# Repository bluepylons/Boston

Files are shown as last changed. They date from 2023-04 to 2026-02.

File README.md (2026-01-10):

# Boston Keyboard 

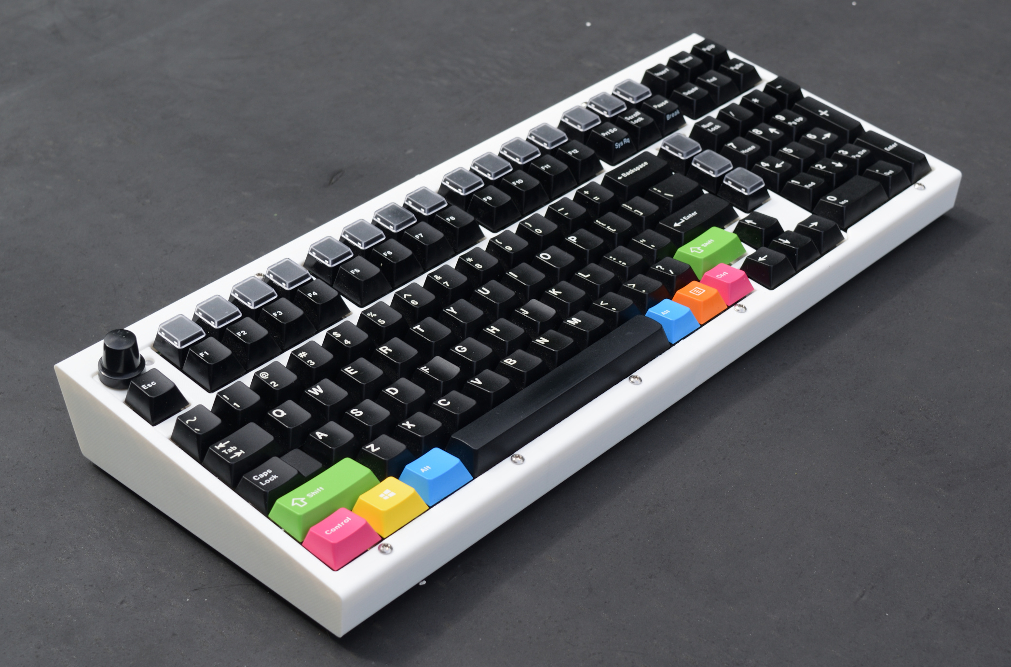
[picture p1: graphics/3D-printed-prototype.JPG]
3D-printed/FR4 version

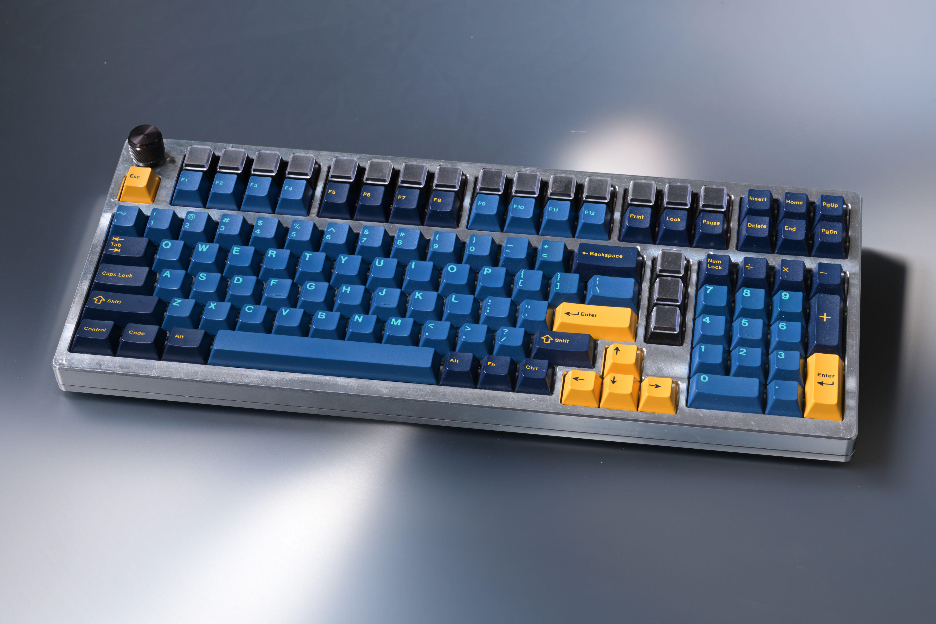
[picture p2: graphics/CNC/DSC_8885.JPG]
CNC version


## Introduction 
Boston is a compact battleship with a complement of 18 programmable keys, in a footprint 2u narrower than a full-size, and only about 1.5u wider than a 96%. There is a 3D printed version and a CNC aluminum version. Hotswap ANSI PCBs are available for both. All are open source. 

The immediate inspiration for Boston was the DriftMechanics [Austin](https://github.com/Gondolindrim/Austin), as well as the [7-row Thinkpad keyboards](https://cdn.mos.cms.futurecdn.net/ZgDSnno6WfhXMf8u8fsBv7-970-80.jpg) found on Thinkpads of the T420 generation and older. The general idea was to make a narrower full-size that retained both the 2u numpad "0" and traditional 2x3 Ins/Del/Home/End/PgUp/PgDn nav block, by expanding vertically. 

The name is a pun off Austin, since the layout is derived from it. I also grew up around the city of Boston and still live in the area. 

## Supported layouts

Soldered PCB:
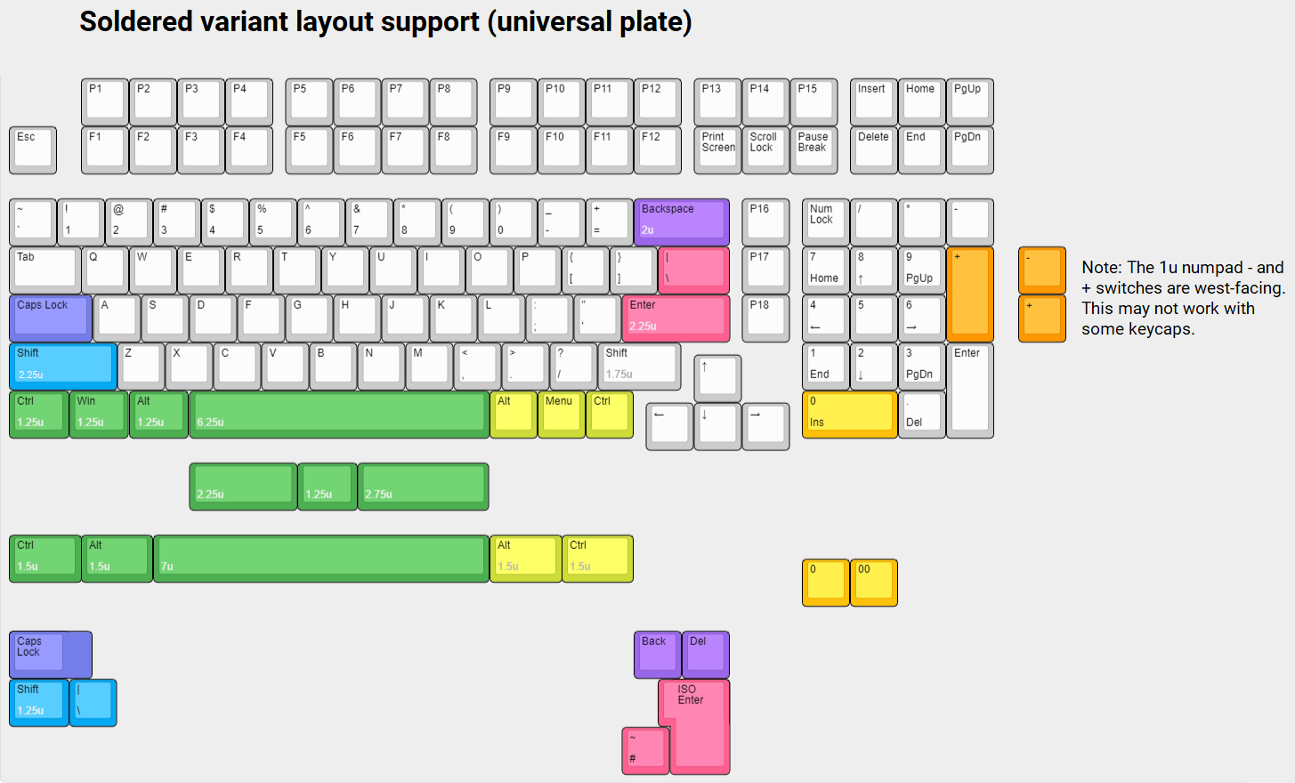
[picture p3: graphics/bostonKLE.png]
Boston layouts


ANSI hotswap PCB: (note the split space 2.75u and 2.25u keys are flipped around compared to the soldered version - this was necessary to accommodate both split space and standard 6.25u space on the same PCB with hotswap sockets)
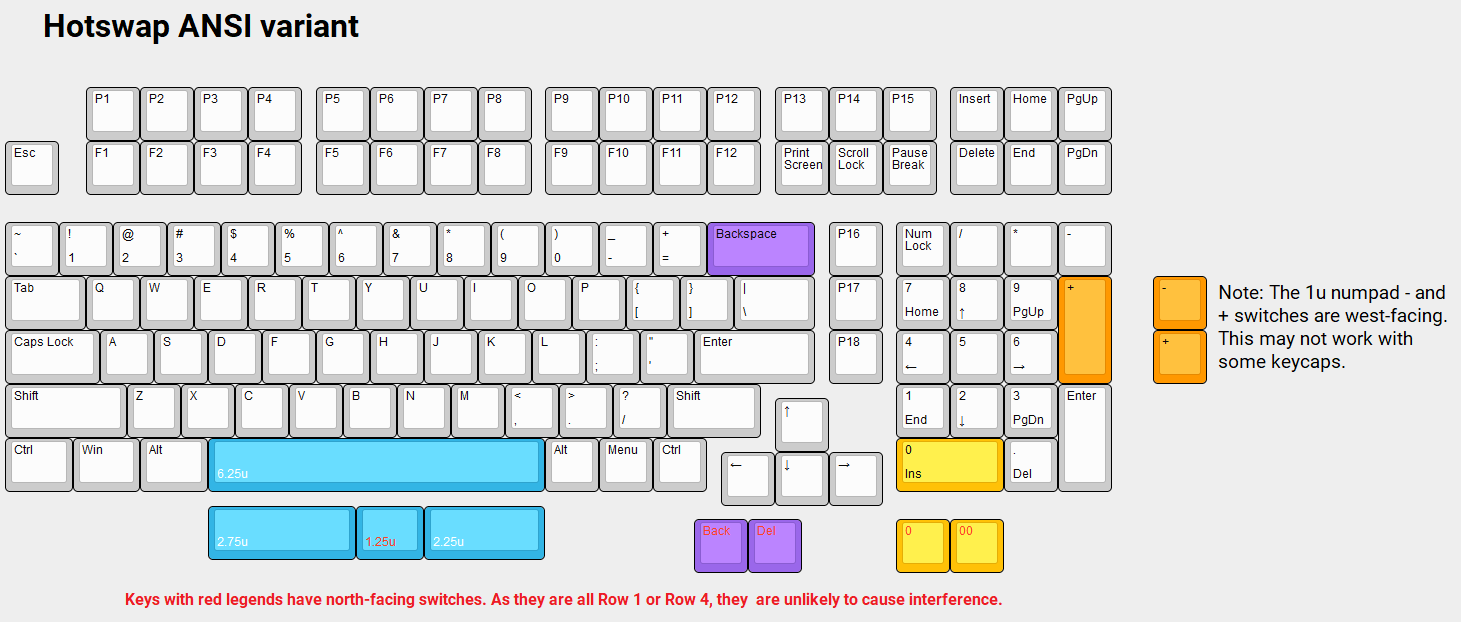
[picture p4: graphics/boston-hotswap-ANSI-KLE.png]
Boston ANSI hotswap layouts


ISO hotswap PCB: TBD (still in development)

Click [this link](http://www.keyboard-layout-editor.com/#/gists/75e63e00e1acc52cdb8eeda7f8ac4ba6) for the KLE file for the soldered PCBs.

Click [this link](http://www.keyboard-layout-editor.com/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'&_w:2.25%3B&=Enter&_x:0.25%3B&=P18&_x:0.25%3B&=4%0A%E2%86%90&=5&=6%0A%E2%86%92&_x:1.75&c=%23ff9800%3B&=+%3B&@_c=%23cccccc&w:2.25%3B&=Shift&=Z&=X&=C&=V&=B&=N&=M&=%3C%0A,&=%3E%0A.&=%3F%0A%2F%2F&_t=%23ff0000&w:1.75%3B&=Shift&_x:2.5&t=%23000000%3B&=1%0AEnd&=2%0A%E2%86%93&=3%0APgDn&_h:2%3B&=Enter%3B&@_y:-0.75&x:14.25%3B&=%E2%86%91%3B&@_y:-0.25&w:1.25%3B&=Ctrl&_w:1.25%3B&=Win&_w:1.25%3B&=Alt&_c=%2333b5e5&t=%23757575%0A%23ffffff&w:6.25%3B&=%0A6.25u&_c=%23cccccc&t=%23000000%3B&=Alt&=Menu&=Ctrl&_x:3.5&c=%23ffc107&w:2%3B&=0%0AIns&_c=%23cccccc%3B&=.%0ADel%3B&@_y:-0.75&x:13.25%3B&=%E2%86%90&=%E2%86%93&=%E2%86%92%3B&@_x:3.75&c=%2333b5e5&t=%23757575%0A%23ffffff&w:2.75%3B&=%0A2.75u&_t=%23ff0000&w:1.25%3B&=%0A1.25u&_t=%23757575%0A%23ffffff&w:2.25%3B&=%0A2.25u%3B&@_y:-0.75&x:12.75&c=%239a67ea&t=%23ff0000%3B&=Back&=Del&_x:1.75&c=%23ffc107%3B&=0&=00) for the KLE file for the ANSI hotswap PCB. 

## Features:
* 121-keys in standard ANSI configuration
* Alps EC11E rotary encoder above the Escape key 
* Full-size numpad with 2u "0" key
* Traditional 2x3 Ins/Del/Home/End/PgUp/PgDn navblock 
* Uses keys found in GMK base kits (except for the programmable keys)
* RGBLED layer-status indicator light 
* ISO enter key, ISO left shift, split backspace, split numpad 0, split space, and WKL bottom row support 
* Optional through-hole LED backlight (dimmable as a single block only) - soldered version only. This hasn't been tested in the newer PCBs but probably still works. 
* USB-C
* STM32F072 controller running QMK. Circuitry is derived from the Austin. 
* Uses Gondolindrim/Acheron's [single-button reset circuit](http://acheronproject.com/images/reset_article/reset2_tighter.svg)
* QMK and Vial support 
* Approximately 6.5° typing angle 

### 3D Printed Version:
* Printable on cheap hobbyist printers - 200mm x 150mm (X/Y) x 210mm (Z) bed size needed to print all the case parts (doable on a Bambu P1S or X1C, Ender 3, Biqu B1, Prusa i3, etc.) 
* Bottom panel with [artwork of Boston's maze-like street network](https://github.com/bluepylons/Boston/blob/main/graphics/3DP-bottom.JPG)
* Technically top mount, though an unusual implementation (screws come in from the top of the case and screw into threaded inserts on the plate) - load path is identical to traditional top mount
* Designed around an FR4 plate with soldered-in threaded inserts 

### CNC Version:
* 2-piece CNC machined case (no weight)
* Traditional top mount 
* Uses a Unified S1/S2 daughterboard with Molex Pico-EZmate connector (older versions use the C3 daughterboard with a JST-SH connector)
* Low USB-C port parallel to desk 

## Current Errata

For all PCB versions - if you use the 1u numpad + and = key options instead of 2u numpad +, the 1u + and 1u = keys are swapped in firmware and on the PCB compared to the KLE (physically pressing the upper 1u key actuates the lower 1u key in firmware and vice-versa). For now, just swap the key assignments in Vial and you should be good. I may fix this eventually in the QMK and Vial files, or fix the PCB routing, but it's a low priority for me.

## Status
For various reasons I decided to open-source the files for the project rather than running a group buy or sale. You can use the files to make one for yourself, as long as you comply with the CERN OHL-W license. 3rd-party group buys or sales are permitted under the license (I will not be directly involved in any 3rd party sales). [RNDKBD](https://rndkbd.com/) currently sells the 3D printed version as an in-stock item (printed to order in a variety of different colors), and previously ran the CNC version (both as a GB and in-stock). There has also been at least one small 3rd-party private buy for the CNC version.

Note that under the terms of the CERN OHL-W license, if you modify the design or make derivative works from the design, you are required to open-source them under a compatible license. 

Current status:

Cases:

**3D printed version** - prototyped and working. 

**CNC version** - prototyped and working. 

PCB:

**V0.8 series** - PCB has been prototyped and tested by Andy of RNDKBD, except for the ISO hotswap version (V0.8.2DHI), which has not been prototyped. 

**V0.7J** (3DP version) - prototyped and working (except optional backlight LED feature has not been tested)

**V0.6.1D** (CNC version) - prototyped and working (except optional backlight LED feature has not been tested).

## Ordering Guide

A draft ordering guide for the 3D printed version is available on the README under [the folder for the 3D printed version](https://github.com/bluepylons/Boston/tree/main/Boston%20-%20Current%20design/3D%20printed%20version). 

A draft ordering guide for the CNC version is available on the README under [the folder for the CNC version](https://github.com/bluepylons/Boston/tree/main/Boston%20-%20Current%20design/CNC%20version). An assembly guide is [here](https://github.com/bluepylons/Boston/blob/main/Boston%20-%20Current%20design/CNC%20version/Assembly-guide.md).

## PCB Renders 

Renders done with [tracespace.io](https://tracespace.io/).

V0.8J (integrated USB-C port and ESD protection - used on the 3D printed version):
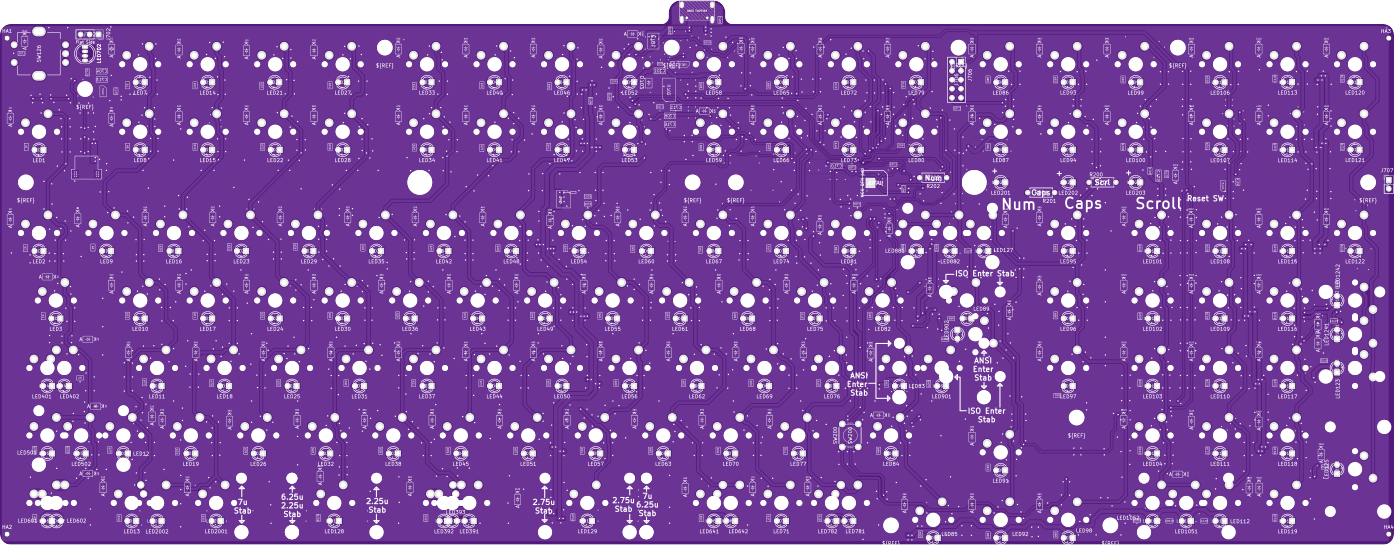
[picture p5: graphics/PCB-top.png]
PCB V0.8J top

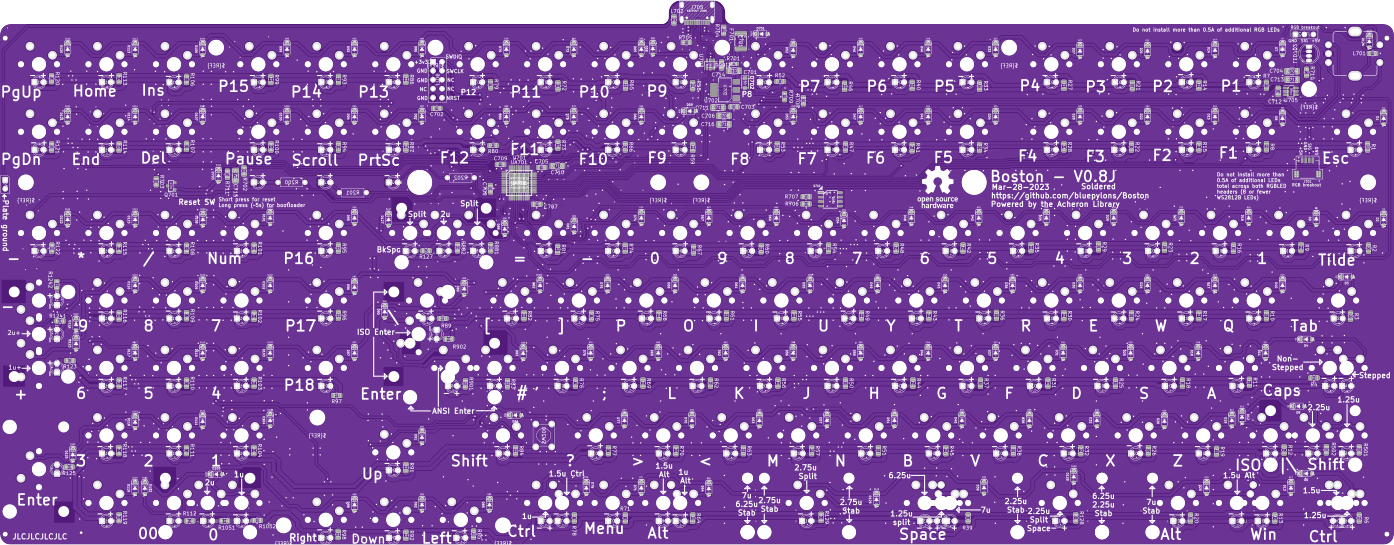
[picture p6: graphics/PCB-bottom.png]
PCB V0.8J bottom


V0.8D (Molex Pico-EZmate connector for use with UDB S1 and C4 daughterboards):
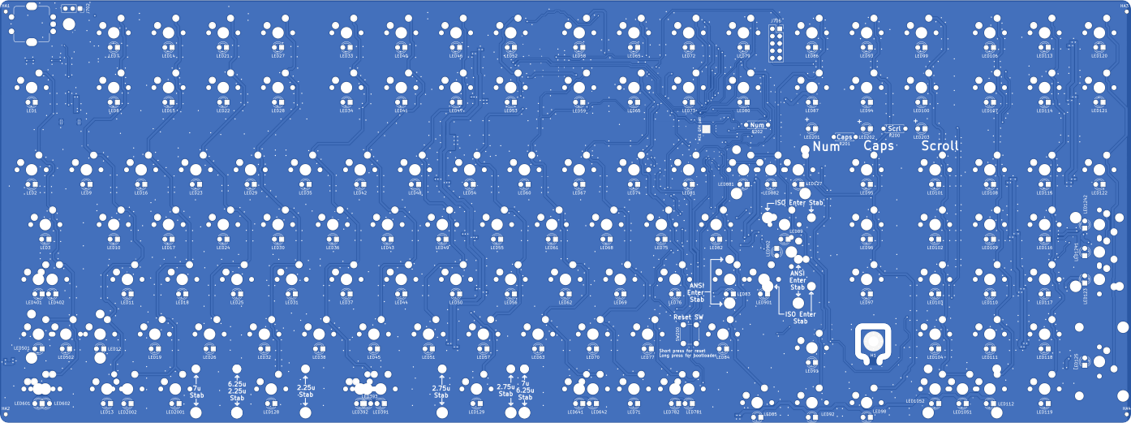
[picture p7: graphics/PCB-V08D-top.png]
PCB V0.8D top

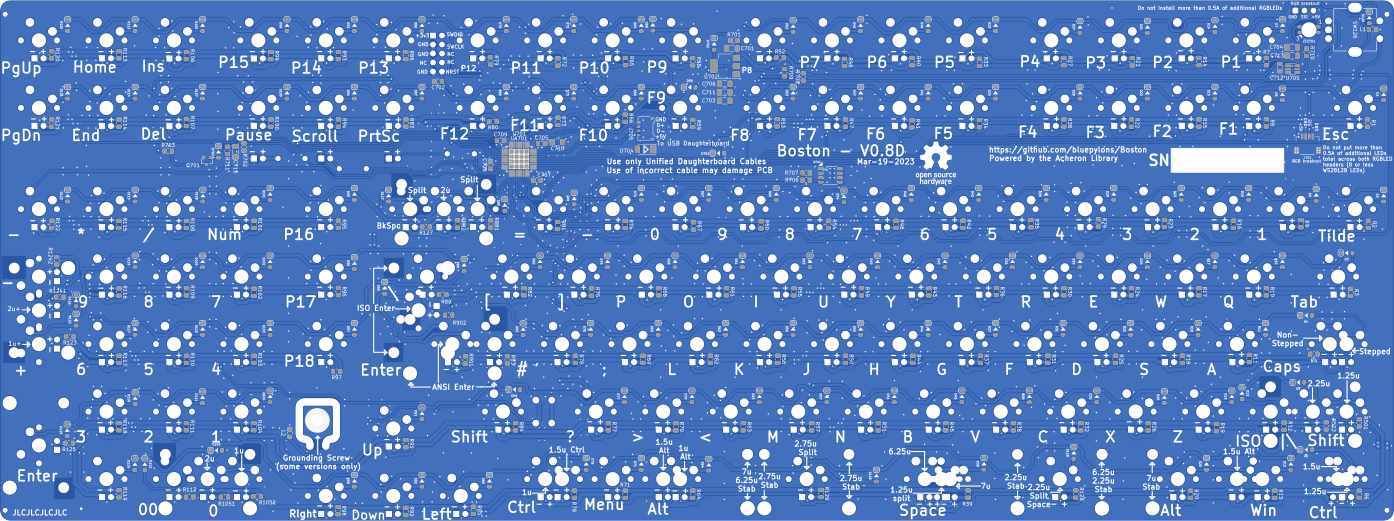
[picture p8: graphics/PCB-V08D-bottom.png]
PCB V0.8D bottom


## Firmware
All PCBs from V0.4 onward (including V0.5.2, V0.6.1D, V0.6.1J, V0.7J, and the V0.8 line, both hotswap and soldered) have the same key matrix and therefore use the same firmware. However, the RGBLED on the CNC variant PCBs (the -D variants) has its red and green channels reversed compared to the 3DP version PCBs (-J variants) (as unfortunately the SK6812 mini-E RGBLED used on V0.6.1D and the APA106 RGBLED used on the others have different orders for the red, green, and blue channels). 

The compiled QMK firmware .bin file is [here](https://github.com/bluepylons/Boston/blob/main/Boston%20-%20Current%20design/boston_default.bin). Source files are on the [QMK repo](https://github.com/qmk/qmk_firmware/tree/master/keyboards/boston). 

The compiled [Vial](https://get.vial.today/) firmware .bin file is [here](https://github.com/bluepylons/Boston/blob/main/Boston%20-%20Current%20design/boston_vial.bin). Source files are on the [Vial-QMK repo](https://github.com/vial-kb/vial-qmk/tree/vial/keyboards/boston). The current Vial build uses Vial V0.6. This is the recommended firmware. 

Firmware can be flashed using QMK Toolbox or DFU. On PCB versions V0.6 and newer, you need to long press the reset button (for several seconds) to access the DFU bootloader to allow for flashing - a short press only resets the MCU. 

## Copyright Notice
The PCB files and hardware designs are released under the [CERN OHL-W](https://ohwr.org/cern_ohl_w_v2.txt) license. The QMK/Vial firmware is released under [GNU GPL V3](https://www.gnu.org/licenses/gpl-3.0.en.html). I am considering changing the PCB file and hardware design license to [Acheron OHL](http://acheronproject.com/AOHL14/) in the future.

The map artwork for the bottom panel on the 3D printed version, in \Boston - Current design\3D printed version\Bottom, was created using OpenStreetMap data, © OpenStreetMap contributors, under OpenStreetMap's [conditions](https://www.openstreetmap.org/copyright). The resulting KiCAD footprint and PCB files for the bottom FR4 panel containing the artwork is specifically released under the [Open Data Commons Open Database License](https://opendatacommons.org/licenses/odbl/) rather than CERN OHL-W.

The rubber feet, screws, nuts, and threaded inserts in the STEP files were remodelled from scratch, as most 3D models available online do not permit redistribution. 

## Libraries
This project uses the Acheron Project's [Alexandria Library](https://github.com/AcheronProject/AcheronLibrary). A few custom footprints are used:
* Boston-PCB-custom-footprints contains custom footprints for V0.7J (currently just a 4.4mm hole)
* Boston-3DP-plate-library contains custom footprints for the 3D-printed version's FR4 plate.
* Boston-plate-custom-footprints contains custom footprints for the CNC version's FR4 plate 

The KiCAD files are done using KiCAD V7.

 The KiCAD files use project-specific paths to the Acheron Library. To set this up - in KiCAD, open Preferences > Configure Paths. Add a new entry, with ALEXANDRIA for the name, and for the path, the directory where the AcheronLibrary folder resides in.

## Derivatives
Technofrikus designed an alternative 3D-printed case derived from the files of the CNC version, and also designed a case with a 4° typing angle. The files for those are [available on Technofrikus' GitHub](https://github.com/Technofrikus/Boston-Case).
Technofrikus' 3D-printed version

DatGameh designed a 0.5° version of the 3D printed case, using parts for the 3DP version. The files are [available on DatGameh's Github](https://github.com/DatGameh/Pretty-Flat-Boston-Case). 

## Acknowledgements

Many thanks to:
* The [Acheron Project](http://acheronproject.com/) - the KiCAD library and the source files for the Austin have been invaluable for designing this board.
* The designers of the Austin (Driftingbunnies, PheonixStarr and Gondolindrim). The layout, schematics, and firmware were derived from that board.
* Gondolindrim, for assistance and feedback with the PCB design, as for running the Acheron project.
* KiCAD, for being an awesome free open-source PCB design tool.
* [Keyboard Layout Editor](http://www.keyboard-layout-editor.com/), where I designed the layout. 
* [Swill's plate generator](http://builder.swillkb.com/) and [Ai03's plate generator](https://kbplate.ai03.com/), which I used for making the plate.
* [Maperitive](http://maperitive.net/) and [OpenStreetMap](https://www.openstreetmap.org/#map=4/38.01/-95.84), which was used to generate the map artwork on the bottom of the 3D-printed/FR4 case. 
* [RNDKBD](https://rndkbd.com/), for testing the V0.8-series PCBs and for making the keyboard available for sale.

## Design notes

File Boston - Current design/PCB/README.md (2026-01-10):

# PCBs

These are the PCB files. All PCBs so far have been manufactured at JLCPCB, so I include the JLCPCB SMT BOM and placement files (except for the V0.8-series, which are getting prototyped with Elecrow thanks to RNDKBD). Elecrow files are also provided for V0.6.1D and V0.7J. 

The PCBs are compatible only with MX-format switches and PCB-mount stabilizers. Washers should not be necessary for screw-in stabilizers.

These files require  KiCAD V7 to open. These files use the [Alexandria (Acheron) library](https://github.com/AcheronProject/AlexandriaLibrary) from Gondolindrim's [Acheron Project](https://acheronproject.com/). To configure that library correctly in KiCAD, you will need to go to Preferences > Configure Paths, and add "ALEXANDRIA" to the Name column and the location of the Alexandria library folder in Path column. 

The 3D-printed version uses the -J series PCBs, which have a USB port and ESD protection built-in. The CNC version (and Technofrikus's 3D-printed version) uses the -D series PCBs, which are for use with an external daughterboard.
V0.8 is the next version that's currently being worked on. On the daughterboard version, this switches over to a 4-pin Molex Pico-EZmate for use the newer S1 daughterboard. 

# Changelog

## Current PCBs

### CNC version PCBs
| Version | Type | Daughterboard connector | Supported layouts | Design status | Elecrow Files Status | JLCPCB Files Status |
| --- | --- | --- | --- | --- | --- | --- |
| V0.6.1D | Soldered | JST SH (for UDB C3 and earlier) | All | Done and prototyped | Done, not prototyped | Done and prototyped (no RGBLED), not prototyped (RGBLED) | 
| V0.8D | Soldered | Molex Pico-EZmate (for UDB S1 and C4) | All | Done and prototyped by RNDKBD | Done and prototyped by RNDKBD | Done, not prototyped | 
| V0.8.2DHA | Hotswap  | Molex Pico-EZmate (for UDB S1 and C4) | ANSI | Done and prototyped by RNDKBD | Done and prototyped by RNDKBD | Done, not prototyped | 
| V0.8.2DHI | Hotswap  | Molex Pico-EZmate (for UDB S1 and C4) | ISO | Initial draft done | Done, not prototyped | Not yet started | 

### 3DP version PCBs
| Version | Type | Supported layouts | Reset button location | Design status | Elecrow Files Status | JLCPCB Files Status  |
| --- | --- | --- | --- | --- | --- | --- |
| V0.7J | Soldered | All | Bottom | Done and prototyped | Done and prototyped | Done and prototyped  | 
| V0.8J | Soldered | All | Top | Done and prototyped by RNDKBD | Done and prototyped by RNDKBD | Done, not prototyped | 
| V0.8.2JHA | Hotswap  | ANSI | Top | Done and prototyped by RNDKBD | Done and prototyped by RNDKBD | Done, not prototyped | 
| V0.8.2JHI | Hotswap  | ISO | Top | Not yet started | Not yet started | Not yet started | 

### J-variant (integrated USB port, JLCPCB SMT-assemblable, used on the 3D-printed version)

* V0.8J - March 28, 2023. Soldered PCB. The reset button has been moved to the top side of the board, underneath the right shift key (just like on the CNC version). 

* V0.8.2JHA - May 19, 2023. ANSI hotswap variant for the 3D printed version. This does not support backlight LEDs. Flipped the spacebar stab footprints so that the stab wire no longer hits the plate. Fixed some minor silkscreen issues.

### D-variant (uses a daughterboard, used on the CNC version, and Technofrikus' 3D printed version)

* V0.8D - March 19, 2023. Soldered PCB. Adds a clamping diode to slightly improve ESD protection over V0.6.1D. Switches to the Molex Pico-EZmate connector for compatibility with the new [Unified S1 Daughterboard](https://unified-daughterboard.github.io/#/db-spec-s) and [C4 daughterboard](https://unified-daughterboard.github.io/#/db-spec-c). Added reverse polarity protection as Molex Pico-EZmate cables often have the wrong pinout for use with Unified Daughterboards and can cause PCB damage.  Design done; awaiting prototyping. 

* V0.8.2DHA - May 19, 2023. ANSI hotswap variant for the CNC version. Has a Molex Pico-EZmate connector for use with the Unified S1 or C4 daughterboards. Flipped the spacebar stab footprints so that the stab wire no longer hits the plate like on V0.8.1DHA

* V0.8.2DHI - June 4, 2023. ISO hotswap variant. Not yet prototyped. 

## Works in Progress

### J-variant (integrated USB port, used on the 3D-printed version)

* V0.8.2JHI - ISO hotswap variant of V0.8.2JHA. Design not yet started.

## Previous PCBs

### J-variant (integrated USB port, JLCPCB SMT-assemblable, used on the 3D-printed version)

* V0.8.1JHA - April 5, 2023. ANSI hotswap variant of V0.8J. This does not support backlight LEDs. Fixed an issue on V0.8JHA where there was a spot of exposed solder mask underneath F11 tht can cause +3.3V to short to ground easily.
***Note - this has an error where the spacebar stabilizers also are upside down relative to the plate and the stab wire will hit the plate and cause noise, though everything still works and you can file small notches into the stab cutouts to get rid of the noise***

* V0.8JHA - March 27, 2023 ANSI hotswap variant of V0.8J. To make routing the hotswap sockets easier I eliminated the optional through-hole backlight LEDs (as they're not useful on a hotswap board anyways). Will have to be split up into ANSI and ISO versions. Initial draft of the design done; still need to error check. Design is done and is awaiting prototyping. 
***Note - this has an error where there is a piece of exposed solder mask underneath F11 that can cause +3.3V to short to ground easily. This is fixed in V0.8.1JHA. The spacebar stabilizers also are upside down relative to the plate and the stab wire will hit the plate and cause noise, though everything still works and you can file small notches into the plate to get rid of the noise***

* V0.7J - May 16, 2022.  This added access holes to the PCB to allow access to the screws that hold the key separators on the 3D printed version. On V0.6.1J and earlier these screw heads are not accessible, and means that the key separators cannot be removed or adjusted after the PCB is soldered. Some components had to be moved around to achieve that. V0.7J also added a place to solder on pogo pins (or a piece of wire) for grounding the plate and top side screws on the 3D-printed case. This is prototyped and working. RNDKBD used this version for Round 2 of their group buy. 

* V0.6.1J - November 28, 2021. This removed a couple of loops on the backlight LEDs near the numpad, and added some more ground vias for EMI purposes. Prototyped and working (though backlight LEDs have not been tested). RNDKBD used this PCB for Round 1 of their group buy.  

* V0.6J - October 15, 2021 - this version is designed to have all SMT parts be assemblable on JLCPCB. To achieve this, the 5V->3.3V conversion is done by a linear regulator rather than a switching regulator, and the LEDs are powered off 5V instead of 3.3V originally. Other changes include using Gondolindrim's improved STM32 reset circuit, and implementing EMI best-practices such as ground plane stitching and ground plane vias in case it needs to pass FCC/CE EMI testing. This has a return loop on the upper right numpad backlight LEDs, though it is unclear if this is an issue (especially if the backlight is not used), as this version was never prototyped.

* V0.5.2 - October 6, 2020 - Removed a loop in the ground plane (which did not seem to affect functionality), and made some minor changes to the silkscreen. Increased thermal clearances around the RGBLED to make it easier to solder. Minor silkscreen fixes. Tested and working. People who bought Round 0 barebones kits received this PCB.  JLCPCB at the time was not able to solder on connectors, and was out of stock of STM32F072 microcontrollers, so those parts are not included on the manufacturing files and were soldered on by hand. JLCPCB also did not carry the fuse, the AP63203WU-7 buck controller, or the buck controller inductor, so those parts are not included in the manufacturing files for JLCPCB SMT, and were soldered on by hand. 

* V0.5.1 - September 23, 2020 - this fixed the routing errors in V0.5, and slightly improved the silkscreen graphics. The grounding screw hole is now connected to ground via a ferrite bead. Tested and working. Beta testers received fixed V0.5 and V0.5.1 boards.

* V0.5 - September 16, 2020 - added split space and WKL support, a grounding pad for the CNC case, changed silkscreen somewhat, and changed the microcontroller footprint to be able to take both LQFP-48 and UFQFPN48 due to shortages of LQFP48 STM32F072's. This had several routing errors and requires some fixes for all features to work.

* V0.4 - August 11, 2020 - a complete redesign. Placed everything on a single PCB, with a centered USB-C port. The F-key clusters are moved slightly closer to the main alpha keys. Switched to SMD diodes. Designed for both a 3D-printed/FR4 case, and a CNC metal case. Working. 

* V0.3 and earlier - these used a two-PCB design, with microcontroller, USB port, and associated components on the daughterboard, and a completely through-hole main PCB. Used with the earliest prototypes. Not compatible with the published case designs. The firmware is largely similar, though the matrix is different.

### D-variant (uses a daughterboard, used on the CNC version, and Technofrikus' 3D printed version)

* V0.8.1DHA - April 5, 2023. ANSI hotswap variant of V0.8J. This does not support backlight LEDs. Fixed an issue on V0.8DHA where there was a spot of exposed solder mask underneath F11 tht can cause +3.3V to short to ground easily.
***Note - this has an error where the spacebar stabilizers also are upside down relative to the plate and the stab wire will hit the plate and cause noise, though everything still works and you can file small notches into the stab cutouts to get rid of the noise***

* V0.8DHA - March 28, 2023. ANSI hotswap variant. Adds hotswap sockets. Switches to the Molex Pico-EZmate connector for compatibility with the new [Unified S1 Daughterboard](https://unified-daughterboard.github.io/#/db-spec-s) and [C4 daughterboard](https://unified-daughterboard.github.io/#/db-spec-c). Added reverse polarity protection as Molex Pico-EZmate cables often have the wrong pinout for use with Unified Daughterboards and can cause PCB damage. Also has some changes to the diodes to try to slightly improve ESD protection over V0.6.1D. To make routing the hotswap sockets easier I eliminated the optional through-hole backlight LEDs (as they're not useful on a hotswap board anyways). Design done; awaiting prototyping. ***Note - this has an error where there is a piece of exposed solder mask underneath F11 that can cause +3.3V to short to ground easily. This is fixed in V0.8.1DHA. The spacebar stabilizers also are upside down relative to the plate and the stab wire will hit the plate and cause noise, though everything still works and you can file small notches into the plate to get rid of the noise***

Note that V0.7D was skipped to line up the versioning between the J- and D- variants.

* V0.6.1D - February 5, 2022. Has a JST connector for use with the C3 Unified Daughterboard. Fixed the incorrect silkscreen on the RGBLED (LED702), which had the arrow on pin 1 instead of pin 3. This was done by switching to Acheron's LED footprint instead of using KiCAD's default footprint. There is a very slight difference in the ground fill around LED702 (which is due to the Acheron footprint not having a keepout zone for ground fills, so I added one manually to keep the PCB as identical as posible to V0.6D). Prototyped and working (though backlight LEDs have not been tested) 

* V0.6D - January 5, 2022. This is meant for the redesigned CNC version of Boston, and is meant to be used with a daughterboard (using the standard 4-pin JST connector). All ESD protection has been moved off to the daughterboard, moves the reset button to the top side of the PCB near Right Shift, and uses a reverse-mount RGBLED (meant to be used with a light pipe on the case) instead of a through-hole one. Otherwise very similar to V0.6.1J, and can run identical firmware as the matrix is identical. The silkscreen on the RGBLED (LED702) was incorrect (the arrow was on pin 1 instead of pin 3). Otherwise working.

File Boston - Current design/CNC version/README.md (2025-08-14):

# Boston CNC Version

CNC version

These are the files for the CNC version of Boston. The PCB is in the [PCB](https://github.com/bluepylons/Boston/tree/main/Boston%20-%20Current%20design/PCB) directory however. 

# Ordering Guide for making your own Boston (draft)

This is the ordering guide for the CNC version of Boston.  

**Order parts at your own risk. These files are provided as-is, and I am not responsible for any losses, harm, or damage incurred by following this guide, by ordering parts, by using the files provided, by using the resultant parts or assembled keyboard, or from any mistakes or errors in the files, ordering guide, or resultant parts. Even components that have been prototyped may still contain errors. ** 

**This is for the S1 daughterboard version. The older variant uses the C3 Unified Daughterboard; see README-C3-DB.md for that version**

# What you will need:

### Parts:

## Parts needed for all variants
| Description | Qty per board | Type | Notes |
| --- | --- | ---| --- |
| Case top | 1 | Custom (CNC machined) | |
| Case bottom | 1 | Custom (CNC machined) | |
| Plate | 1 | Custom (PCB, laser cut, waterjet, or CNC machined) | Several variants |
| PCB | 1 | Custom (PCB) | Several variants | 
| LED spacer (for the lock LEDs) | 1 | Custom (3D-printed) | Different from the one for the 3DP Boston |
| S1 Unified (or compatible) Daughterboard | 1 | Off-the-shelf or custom | Later S-series (e.g. S1.1) should work |
| S1 Unified Daughterboard cable (>75mm long) | 1 | Off-the-shelf or custom | Make sure the [pinout is correct](https://unified-daughterboard.github.io/#/info-consumer?id=buying-replacement-cables) |
| 3mm LEDs for lock LEDs | 3 | Off-the-shelf | Pick a color you like! |
| Alps EC11E18244A5 rotary encoder | 1 | Off-the-shelf | Other rotary encoders may work, but may need firmware tweaks |
| Knob suitable for 6mm D-shaft | 1 | Off-the-shelf | |
| M3x0.5 10mm socket head cap screw | 4 | Off-the-shelf | |
| M3x0.5 16mm socket head cap screw | 4 | Off-the-shelf | |
| M3x0.5 5mm socket head cap screw | 12 | Off-the-shelf | | 
| 3/4" dia x 3/8" tall rubber dome feet | 2 | Off-the-shelf | | 
| 3/8" dia x 5/32" tall rubber dome feet | 2 | Off-the-shelf | |
| VCC LFC037CTP Light Pipe | 1 | Off-the-shelf | |
| VCC RTN125 Light Pipe Retainer | 1 | Off-the-shelf | |

| Description | Qty per board | 
| --- | --- |
| MX-style switches | 119-127 (depending on layout) |  
| Stabilizers (PCB mount) | 2-8 2u, 0-1 6.25u or 7u (depending on layout) |

For a standard ANSI build (using the fixed layout plate) you need 121 switches, 6 2u stabilizers, and 1 6.25u stabilizer. 

## Additional parts needed only for the soldered PCB variant 

| Description | Qty per board | Type |
| --- | --- | --- |
| 1KΩ 1/4W through-hole resistor for lock LEDs | 3 | Off-the-shelf |

## Additional parts recommended for the hotswap variant 

| Description | Qty per board | Type | Notes |
| --- | --- | --- | --- |
| M2x0.4 3.5mm threaded standoff for hotswap boards | 10 | Off-the-shelf | Available as a [13-pack from KBDfans](https://kbdfans.com/products/kbdfans-m2-3-countersunk-flat-head-screw-kit) |
| M2x0.4 3mm Philips-head pan head screws | 10-20 | Off-the-shelf | The KBDfans kit comes with 13 of them, but you will need another 7 if you aren't countersinking the plate |
| M2x0.4 3mmm flat head screw | 0-10 | Off-the-shelf | Only needed if you're countersinking the plate, and the KBDfans kit comes with enough, so you shouldn't need to buy these if buying the KBDfans kit |

These are recommended for the hotswap variant for holding the plate and PCB together, though you might be fine just relying on the switches to hold the plate and PCB together.

## Additional parts needed only if ordering the PCB through JLCPCB

| Description | Qty per board | Type |
| --- | --- | --- |
| 6x6mm tact switch, through-hole, 5mm high | 1 | Off-the-shelf |

## Tools needed 
| Description |  Used for |
| --- | --- |
| 2.5mm hex key or bit ("Allen key") | All M3 screws |
| Soldering iron and solder | For soldering everything |
| Flush cutters | For cutting legs off soldered LEDs and resistors |

## Additional tools recommended for the hotswap variant only
| Description |  Used for |
| --- | --- |
| Philips #1 screwdriver | The optional M2 screws that attach the plate to the PCB |
| Switch puller | Removing switches |

# Case

Boston has a two piece case, consisting of the top and the bottom. It does not have a weight (though, if you have mechanical design and CAD skills, it should be pretty easy to add an internal weight to the design). 

## How to contact a machine shop to order the case 

To have the case made, you will need to contact a machine shop with a CNC machine. These are informally referred to as "manus" by the mechanical keyboard community.

[Dadesin](https://dadesin.en.alibaba.com/) is a popular high-quality Chinese one, though expensive. I used [SuNPe](https://sunpe.com/) (also in China) for my prototypes, though the quality was middling. A friend ran a small private group buy through [Gaojie](https://www.gj-prototype.com) and had good results. There are numerous other ones. You can also reach out to a local CNC machine shop.  Note that usually there is a tradeoff between cost and quality, with cheaper shops often being lower quality or sloppier with their machining (and more prone to mistakes, like forgetting to machine features or forgetting to tap holes). 

You will need to send a "Request for Quote" email to them with the following files:

* 3D files - you will need the 3D .STEP files for the [Top](https://github.com/bluepylons/Boston/blob/main/Boston%20-%20Current%20design/CNC%20version/Case/STEP/Boston-top.stp), and the [bottom](https://github.com/bluepylons/Boston/blob/main/Boston%20-%20Current%20design/CNC%20version/Case/STEP/Boston-bottom-S1-UDB.stp)
* The mechanical drawings, which include the tapping instructions for the tapped (threaded) holes. [Top](https://github.com/bluepylons/Boston/blob/main/Boston%20-%20Current%20design/CNC%20version/Case/Manufacturing%20drawings/Boston-top.pdf), [Bottom](https://github.com/bluepylons/Boston/blob/main/Boston%20-%20Current%20design/CNC%20version/Case/Manufacturing%20drawings/Boston-bottom-S1-UDB.pdf)
* If you want a raw as-machined finish with visible tool marks, or want to anodize directly over the tool marks, you may want to include the milling instructions for more pleasing tool marks. [Top](https://github.com/bluepylons/Boston/blob/main/Boston%20-%20Current%20design/CNC%20version/Case/Manufacturing%20drawings/Boston-top-AS-MACHINED-milling-instructions.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), [Bottom](https://github.com/bluepylons/Boston/blob/main/Boston%20-%20Current%20design/CNC%20version/Case/Manufacturing%20drawings/Boston-bottom-AS-MACHINED-milling-instructio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) If you are going for a bead-blasted finish, you do not need to include these. These are PNG images with picture illustrations, as many machine shops are overseas and do not speak English well. 
* In the body of the email, you want to specify the quantity, material, and the surface finish, as well as that you want these parts to be made by CNC machining. Materials and surface finish are discussed more in depth in the next sections.

You will also need to specify a material and a finish, a color for the finish (if you are anodizing, e-coating, painting, powder coating, or Cerakoting), as well as the quantity you want to order. Here is an example email reaching out to a manufacturer for a quote:

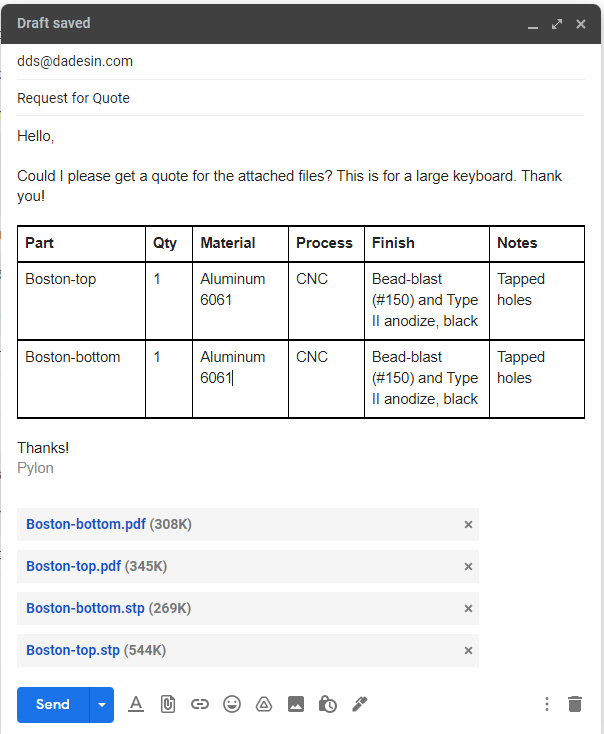
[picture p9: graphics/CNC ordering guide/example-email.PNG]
Example email to manufacturer


The manufacturer will get back to you with a quote. If you wish to proceed with the quote, let them know that you wish to proceed, and they will send you instructions for payment (often via Paypal or bank transfer) and ask for a shipping address. 

With a Chinese shop, expect to pay $300-$700 for a single case machined out of aluminum (and about $60-$150 for shipping - note that some machine shops inflate their shipping costs). Expect higher for a US or EU shop. The price each usually goes down if you order more (even 3-5 units can lower the price significantly for each board over ordering just 1). 

## Material

Most custom keyboards are made out of aluminum. There are several different aluminum alloys that are commonly used:

* **6061** - this is a general purpose aluminum alloy and the most common aluminum alloy used for CNC-machined parts. It's a jack of all trades, with decent strength, anodizing finish quality, machinability, and corrosion resistance compared to other aluminum alloys, as well as other desirable properties for some non-keyboard applications (e.g. weldability). Due to its ubiquity and ease of machining it will likely be the cheapest aluminum alloy to make your keyboard out of. All of the prototypes of Boston used 6061. 

* **6063** - Also known as "architectural aluminum", this tends to anodize a bit nicer than 6061, but is half the strength of 6061 and somewhat softer. This means the keyboard will dent more easily, threads will strip more easily (though Boston uses larger M3 threads that are harder to strip than the smaller M2 threads found on many keyboards), and if you have a raw finish, the aluminum will scratch more easily.

* **5052** - I honestly don't know why this gets used in keyboards, as it's mostly used in industry for bent sheet metal (as it bends well without cracking, unlike 6061) and for welding. It's weaker than 6061, but stronger than 6063.

* **7075** - 7075 is a significantly stronger and harder alloy than 6061, and somewhat more expensive, but doesn't anodize as well (it can anodize, but the colors are more limited and the finish won't be as good). If you're looking to keep a raw aluminum finish, 7075 will  be a bit harder to scratch (though it will still scratch quite easily). It will also be harder to dent, and the threads will be more resistant to stripping. However, in raw form it is less corrosion resistant than 6061. 

Other commonly used materials for keyboards - you can use the same files to CNC machine a case out of these materials.
* Polycarbonate
* POM (also known as acetal, and under various proprietary names such as Delrin®). You mostly likely will only be able to obtain this in white or black.
* Brass - brass is expensive and heavy, but machines very well. Note that common brass alloys use for machining (such as brass 360 alloy) have a substantial lead content, and you probably want to specify a coating to avoid lead exposure from handling the keyboard.

There are also more exotic materials, such as stainless steel, titanium, various nickel alloys, copper alloys, and so on that you could hypothetically make a Boston keyboard with using the same files. These are generally much more difficult to machine, and will be very expensive. 

## Surface finish 

In addition to the material, you want to pick a surface finish. There are two parts to this - the texture, and the coating. The vast majority of custom keyboards use a fine bead blasted texture with a Type II anodization coating, which can be dyed different colors. 

### Textures:
* **As-machined** - this is the finish straight out of the CNC, with tool marks, scratches, and all. The appearance of the tool marks and roughness may vary significantly depending on the machine shop's choice of tool, tool path, and feeds and speeds. Using a fly cutter or large face mill and a fine finishing pass can result in *very* shiny finishes. Not common in keyboards, though it's shown up on some Keycults. All of the prototypes of the CNC Boston used an as-machined finish. You can anodize over the tool marks directly, though this is also uncommon. Note that some machine shops occasionally will deburr sharp edges with scour pads, sandpaper, or a wirebrush, which may remove some of the tool marks. If you want the tool marks preserved, you need to tell them to not deburr with those tools. The as-machined milling instructions specify to not use those tools. 
* **Bead Blasted** - this involves blasting the keyboard with fine glass beads for an even matte finish. Most metal keyboards are bead blasted, as well as almost all aluminum consumer electronics (iPhones, Macbooks, etc.). This is almost always paired with a Type II anodize (though you need to specify the anodization separately). Note that there are different roughnesses available, ranging from coarse to fine. I'm not familiar with the specifications for these, but you probably want to specify a "fine" or "very fine" roughness, or specify a specific size. The [Bakeneko60](https://github.com/kkatano/bakeneko-60) specifies a #150 bead blast finish.  
* **Brushed** - this involves using a wirebrush or flapper wheel to impart horizontal streaks across your parts. Not common in keyboards, though you occasionally see it in other consumer electronics. Again, there are different roughnesses available. 
* **Tumbled** - this uses a large tumbling machine and tumbling media (ranging from to plastic  beads to corn cob and walnut husks) to apply an even finish to the part. Again, different roughnesses are available. I'm not aware of any keyboards that use this and am unfamiliar with the textures you can achieve with this, but you can ask if your machine shop can do it. 
* **Polished** - this involves buffing out the case using either a polishing wheel or a tumbling process. I'm not very familiar with this, but you can ask your machine shop.

### Coatings:
* **Anodized** - almost all aluminum on consumer electronics (including custom keyboards) are anodized, usually over a fine bead-blasted finish. Anodizing generates a protective layer of aluminum oxide on the outside of the part, which is much harder than the underlying raw aluminum. This significantly improves the scratch resistance, and also protects the aluminum from corrosion. This layer of aluminum oxide can be clear (showing the underlying silver aluminum), or be dyed a wide range of different colors ([except for white](https://www.bluebuddhaboutique.com/blog/2011/09/no-white-anodized-aluminum/)). However, if you're going for a shiny as-machined or polished finish, it can dull the aluminum a bit. There are a couple of types of anodizing, but Type II (cosmetic anodizing) is the most common, and what you probably want as it is inexpensive, and available in a wide variety of colors. Type III (Hard Anodizing) is occasionally done but uncommon in consumer electronics - Type III generates a much thicker layer of aluminum oxide than Type II, resulting in a dark gray, black, or bronze-brown color. This results in very good wear and scratch resistance, but costs more, can interfere with threaded holes, and is generally unnecessary for keyboards. Note that many machine shops outsource their anodizing, though some (e.g. Dadesin) anodize in-house. If you want to read up more on anodizing, [this](https://omwcorp.com/understanding-and-specifying-anodizing-2/) is a good document to go over (thanks to Croktopus for finding the document). 
* **Raw aluminum** - this means not using any coating whatsoever and leaving the bare metal exposed. Note that raw aluminum is easily scratched (and will most likely arrive from the machine shop with scratches from shipping and handling), so this is a fairly uncommon finish. It may also discolor from corrosion. However, paired with an as-machined or polished finish texture, it can be extremely shiny and reflective. All of my prototypes had a raw finish.   
* **E-coat**, **paint**, **powder coat**, or **Cerakote** - I am not familiar with ordering these finishes, but they show up on keyboards from time to time, and are available in a wide variety of colors. Your machine shop might not be able to handle these, and you may need to find a third party painter, powder coater, or Cerakote applicator. 

**Note that any coating that adds appreciable (>0.03mm) thickness (such as Type III hard anodizing, powder coat, e-coat, paint, and Cerakote) will require the threaded holes and the RGBLED hole to be masked off. Standard (Type II) anodizing is usually thin enough that interference isn't an issue and masking holes should not be needed. 

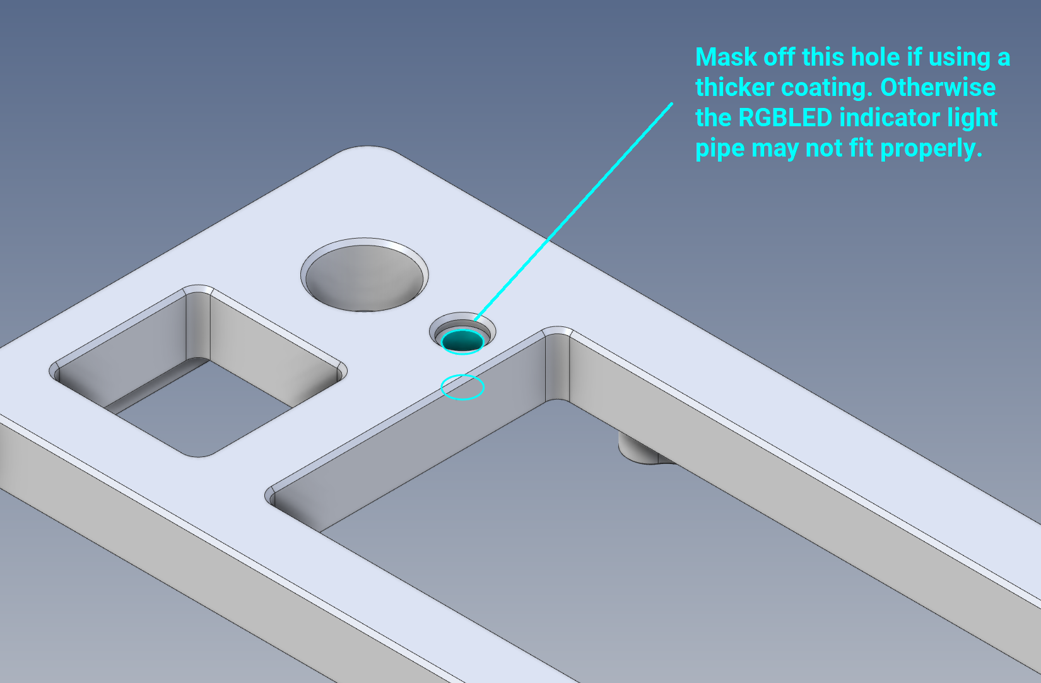
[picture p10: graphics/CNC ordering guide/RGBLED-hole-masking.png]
RGBLED hole that needs to be masked


# Plate

Boston has a traditional top mount plate. 

There are several variants of the plate, and different plates for the hotswap and soldered plates. 

## Plate Variants 

### Hotswap ANSI

KLE of the hotswap ANSI layout 

The hotswap ANSI plate supports all the layouts supported on the hotswap ANSI PCB ([V0.8.2DHA](https://github.com/bluepylons/Boston/tree/main/Boston%20-%20Current%20design/PCB/V0.8.2DHA)). It also has holes for the 3.5mm standoffs between the PCB and plate, to hold the assembly together when there are no switches installed. 

Note that the hotswap layout reverses the 2.75u and 2.25u split space layout compared to the soldered layout (this was necessary to accommodate those layouts with hotswap sockets). This is reflected in the hotswap plate. The hotswap plate can be used with the soldered PCB if you are not using split space though. 

If you are getting the plate CNC machined, there is a version of the hotswap ANSI plate with countersunk holes for the standoffs if you want to use countersunk screws for a flush finish. Send the [countersinking instructions](https://github.com/bluepylons/Boston/blob/main/Boston%20-%20Current%20design/CNC%20version/Plate/Hotswap-ANSI/Hotswap-ANSI-plate-countersunk-countersinking-instructi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) to the manufacturer along with the [3D .STEP file](https://github.com/bluepylons/Boston/blob/main/Boston%20-%20Current%20design/CNC%20version/Plate/Hotswap-ANSI/Hotswap-ANSI-plate-countersunk.stp). Some laser cutting services also offer countersinking, like [Sendcutsend](https://sendcutsend.com/services/countersinking/). 

All of the files for the hotswap ANSI plate are [here](https://github.com/bluepylons/Boston/tree/main/Boston%20-%20Current%20design/CNC%20version/Plate/Hotswap-ANSI). 

### Hotswap ISO
KLE of the hotswap ISO layout 

The hotswap ISO plate supports all the layouts supported on the hotswap ISO PCB [V0.8.2DHI](https://github.com/bluepylons/Boston/tree/main/Boston%20-%20Current%20design/PCB/V0.8.2DHI). **Note neither this plate nor the hotswap ISO PCB have been prototyped or tested.**

Note that the hotswap layout reverses the 2.75u and 2.25u split space layout compared to the soldered layout (this was necessary to accommodate those layouts with hotswap sockets). This is reflected in the hotswap plate. The hotswap plate can be used with the soldered PCB if you are not using split space though. 

### Soldered plate (universal layout)

The soldered universal layout plate supports all the [layouts supported](https://github.com/bluepylons/Boston/blob/main/graphics/bostonKLE.png?raw=true) on the soldered PCB ([V0.8D](https://github.com/bluepylons/Boston/tree/main/Boston%20-%20Current%20design/PCB/V0.8D))

All of the files for the soldered universal layout plate are [here](https://github.com/bluepylons/Boston/tree/main/Boston%20-%20Current%20design/CNC%20version/Plate/Soldered-universal).

### Soldered plate (ANSI fixed layout) 

This accommodates only the [standard ANSI layout](https://github.com/bluepylons/Boston/blob/main/graphics/bostonKLE-ANSI-fixed-layout-plate-support.PNG?raw=true) (with a non-stepped Caps Lock key). This results in easier asseembly and an easier-to-clean plate  over the universal plate.

All of the files for the solderedfixed layout plate are [here](https://github.com/bluepylons/Boston/tree/main/Boston%20-%20Current%20design/CNC%20version/Plate/Soldered-ANSI-fixed-layout).

## Getting the plate manufactured 

There are a couple of ways to get the plate manufactured. The plate should be made out of 1.4-1.6mm material (which is the official Cherry spec for having the switches click in properly).

### Laser cutting
Virtually all metals (aluminum, brass, steel, titanium, etc.) can be cut using a powerful laser, as well as certain plastics (POM and PP). This will usually be the most cost-effective option for a metal, POM, or PP plate. To get a plate cut, you want to use the DXF (.dxf) file. Units are in mm.

[Sendcutsend](https://sendcutsend.com/) in the US and [Laserboost](https://www.laserboost.com/) in the EU are popular laser cutting services. Many Chinese CNC machine shops, including popular keyboard manufactuerers like Gaojie and Dadesin also offer laser cutting if you want them to make your plate for you as well. 

For the hotswap plate, some laser-cutting services offer countersinking. They may either offer it through their web interface, or you may have to manually request it. Attach the countersinking instructions for the respective plate file. 

#### Waterjet cutting
This is rarely used for keyboard plates as it's not as cost effective as laser-cutting, but is also an option as well if you have access to one. This supports more materials than laser cutting. This uses the same DXF (.dxf) file.

### CNC machining
CNC machining is preferred for some materials like polycarbonate and carbon fiber, which cannot be laser cut. You can ask the same manufacturer as the case to CNC machine the plate for you. 

If you are looking to have the plate CNC machined, you want to use the STEP (.stp or .step) file. Again, the units are in mm. 

### As a printed circuit board (FR4 and aluminum only)

If you are looking to have the plate made out of FR4 or aluminum PCB material, you want to use the .zip Gerber files. This will have to be ordered as a PCB, and can be uploaded to any PCB supplier (JLCPCB, Elecrow, PCBway, AllPCB, etc.). Note that some PCB manufacturers (e.g. JLCPCB) charge an additional fee for plates due to the amount of machining required. Choose 1.6mm for the PCB thickness. 

Note - on JLCPCB, make sure that "Specify A Location" for "Remove Order number" is selected so that the order number doesn't get printed somewhere you don't want. The Gerber files have the requisite "JLCJLCJLCJLC" text on them and placed in an unobstrusive location.

Remove Order Number 

 Also, "Paper between PCBs" under "Advanced Options" is strongly recommended- otherwise there's a decent risk of FR4 parts showing up scratched. 
 
Paper Between PCBs

# PCBs

You can order an assembled PCB (minus switches, LEDs, and rotary encoder) from a PCB fab such as JLCPCB or Elecrow.

Note that **the CNC version of Boston does not use the same PCBs as the 3D printed version** due to the daughterboard, though they use the samae firmware as the key matrix is identical. All PCB variants with a -D suffix ("D" for "daughterboard) are for the CNC variant.

## Hotswap ANSI PCB 
The current hotswap ANSI PCB is [V0.8.2DHA](https://github.com/bluepylons/Boston/tree/main/Boston%20-%20Current%20design/PCB/V0.8.2DHA)

## Hotswap ISO PCB 
The current hotswap ANSI PCB is [V0.8.2DHI](https://github.com/bluepylons/Boston/tree/main/Boston%20-%20Current%20design/PCB/V0.8.2DHI). **Note this PCB has not been prototyped or tested**

## Soldered PCB
The current soldered PCB is [V0.8D](https://github.com/bluepylons/Boston/tree/main/Boston%20-%20Current%20design/PCB/V0.8D)

## Ordering on JLCPCB 
[JLCPCB](https://jlcpcb.com/) is cheap and fast, but doesn't have the best cosmetic finish, and their SMT assembly is limited to parts [they stock](https://jlcpcb.com/parts) (though they recently announced "Global Parts Sourcing"). In the community they tend to only be used for prototypes.

To order a PCB from JLCPCB, you will need the Gerber files (which defines the bare PCB), the SMT bill of materials (BOM file, which is a list of parts that are to be soldered to the PCB), and the component placement file (CPL, which defines where those parts go). These files are available under the "Manufacturing Files" folder of the PCB (**NOTE - some PCB versions do not yet have their JLCPCB files ready yet **)

First, you want to go to [JLCPCB](https://jlcpcb.com/), and press "Order Now".

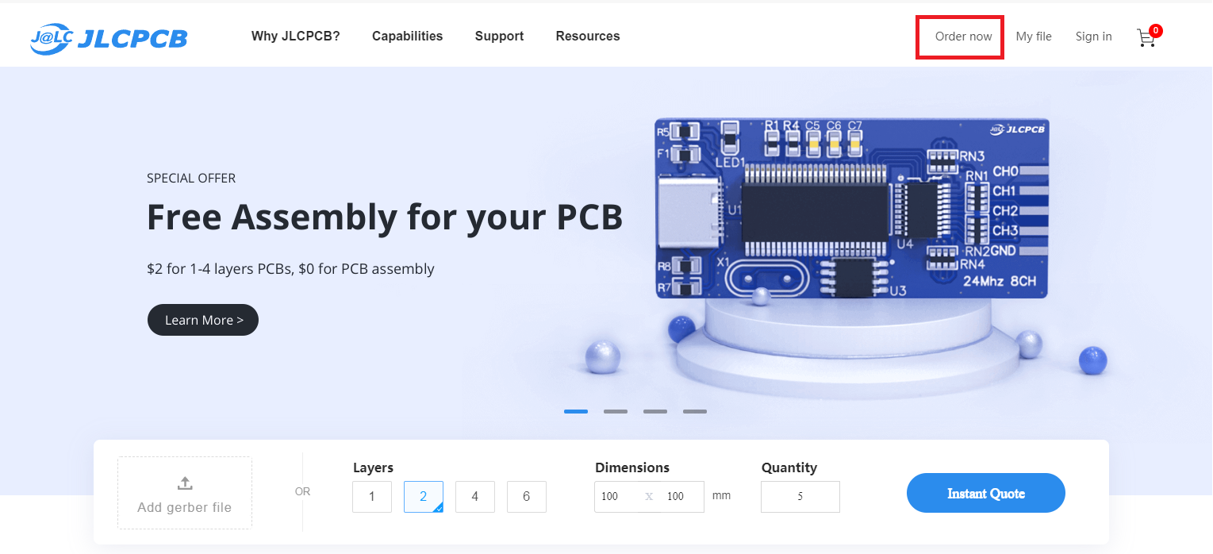
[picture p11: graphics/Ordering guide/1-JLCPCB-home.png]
Step 1


Next, you want to upload the Gerber file for the PCB. You may need to manually input the PCB dimensions (393.5x147mm). 

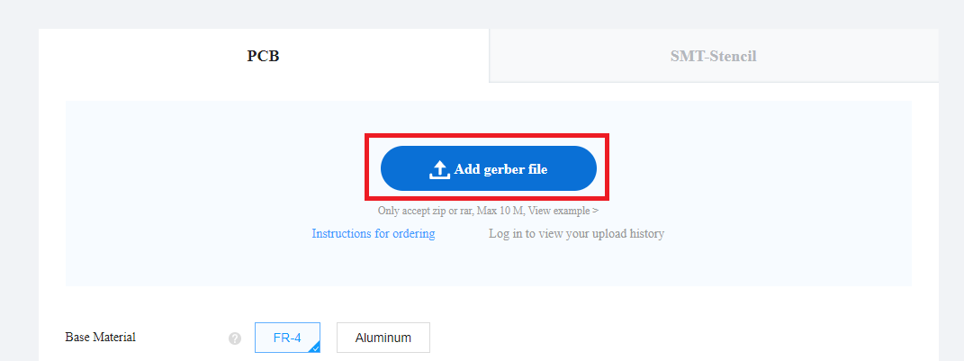
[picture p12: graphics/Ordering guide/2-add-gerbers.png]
Step 2


Here, you want to change the specifications to the following. 

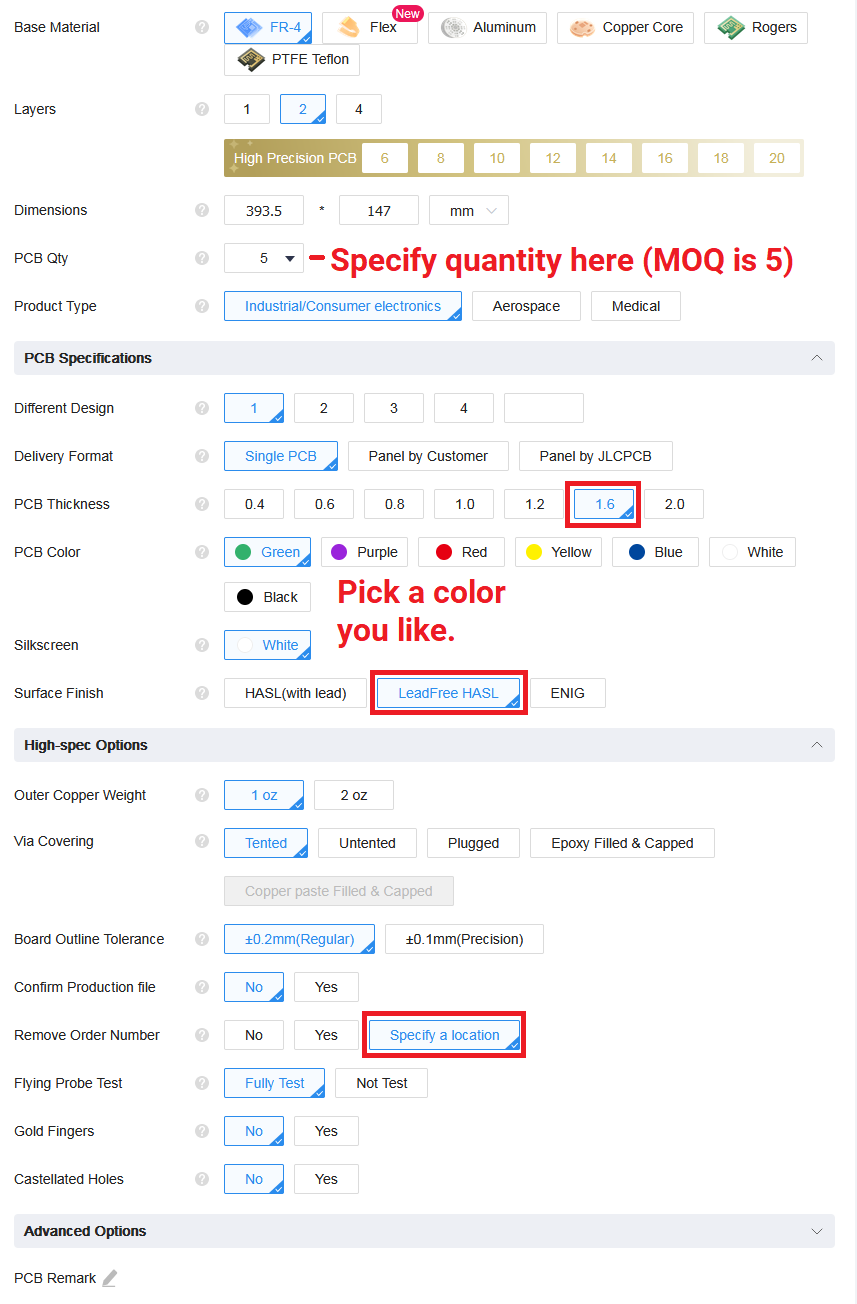
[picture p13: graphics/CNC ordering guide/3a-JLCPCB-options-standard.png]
Step 3


Next, you want to scroll down and turn on PCB Assembly. Make sure the following options are selected. 

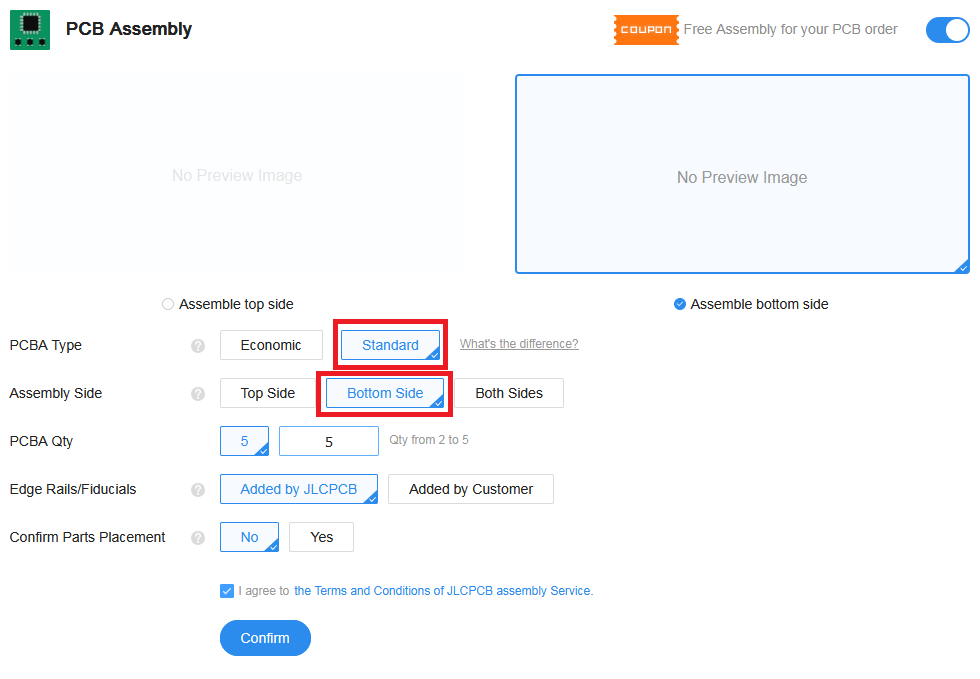
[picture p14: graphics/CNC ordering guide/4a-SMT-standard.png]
Step 4


Press Confirm. Next, you want to upload the BOM and CPL files. 

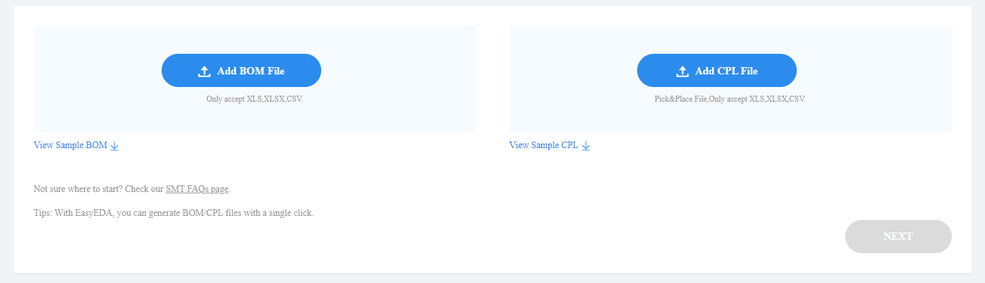
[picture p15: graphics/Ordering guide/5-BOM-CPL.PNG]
Step 5


Make sure that all the components are selected. Any part that says "Inventory shortage" will not be installed, and you will have to substitute a compatible part, wait for the part to come back in stock, or if you're up to the challenge of SMT soldering, order the part separately and solder it on yourself. 

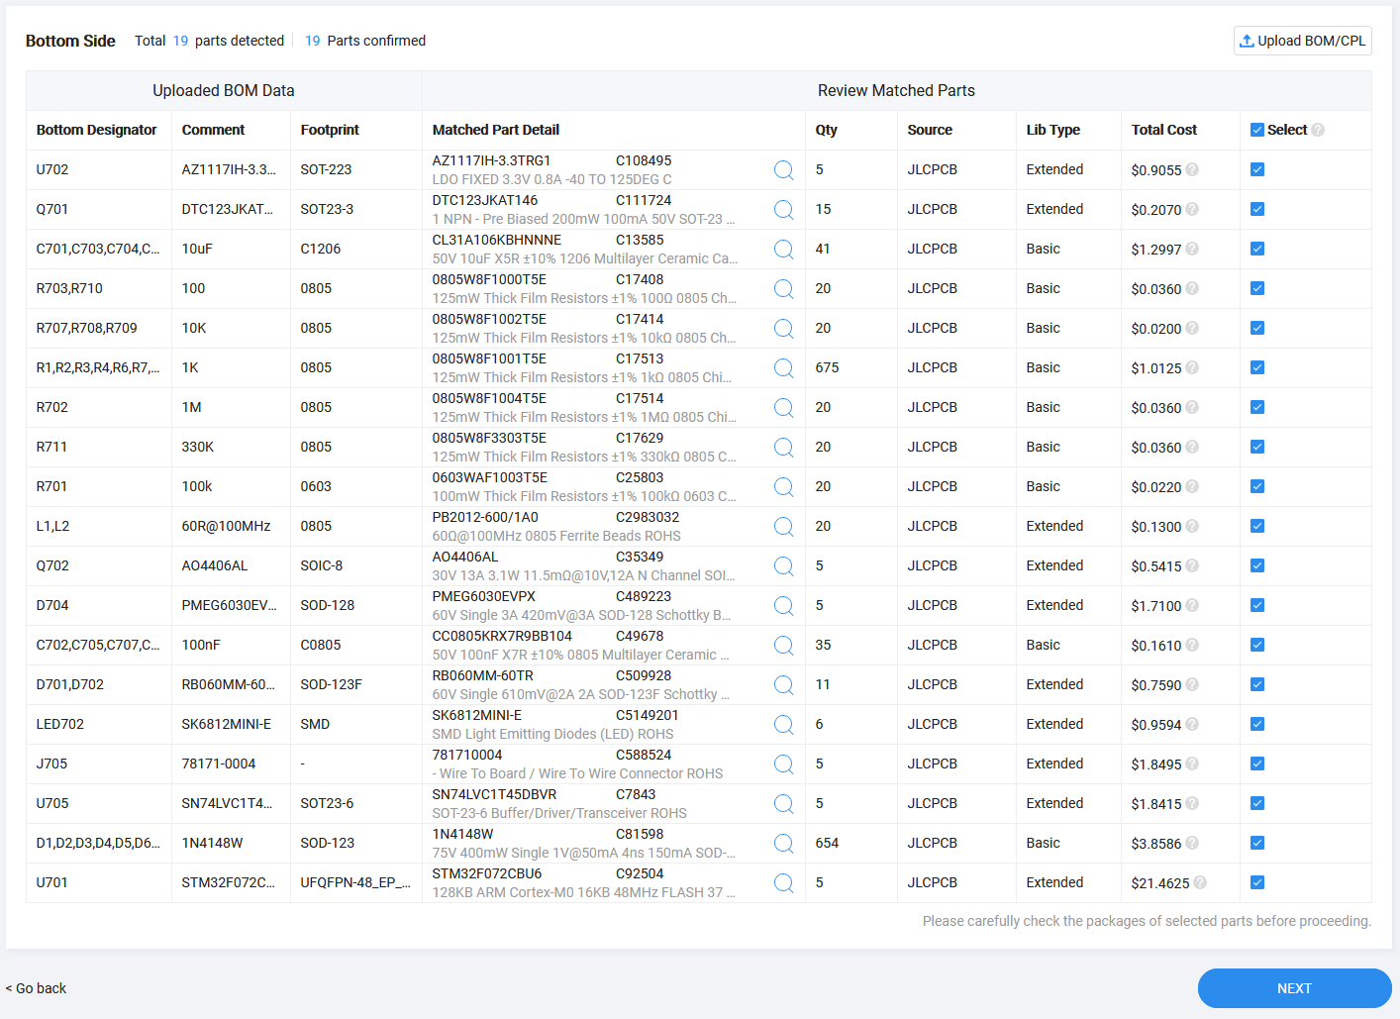
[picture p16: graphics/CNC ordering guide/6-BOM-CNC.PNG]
Step 6


The next page is a confirmation page. Note that the parts placement preview may be inaccurate (JLCPCB engineers will look over this and make any parts orientation corrections, so don't worry too much about this). 

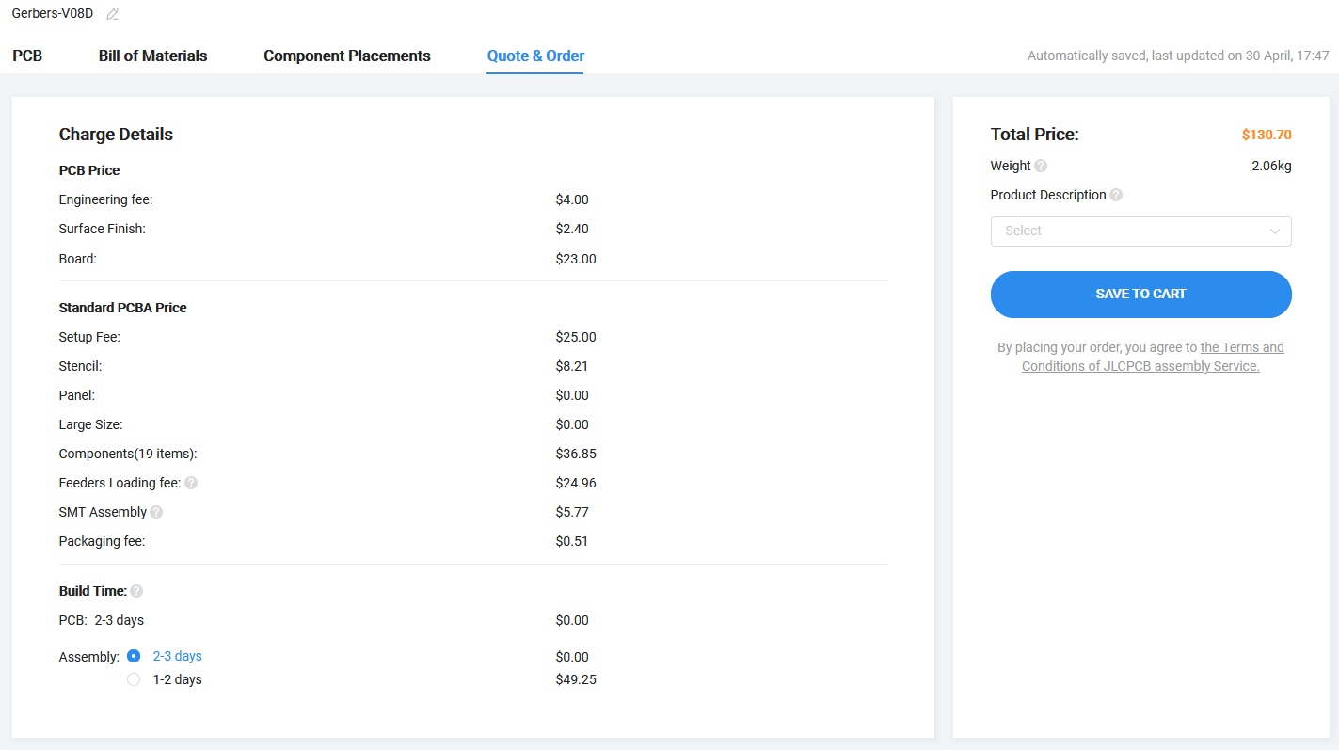
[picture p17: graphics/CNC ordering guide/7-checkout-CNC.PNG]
Step 7


As the microcontroller is frequently out of stock due to the chip shortage, line number 16 (for designator U701) can be changed for different compatible MCUs (see the "Compatible MCUs" section below for a list of MCUs that will work). At different times some microcontroller variants may be cheaper than the others (for example, on August 29, 2022, the STM32F072CBT6 is $4.50 and the STM32F072CBU6 is $9.52, whereas during other times -CBU6 has been significantly cheaper than the -CBT6). In the BOM and CPL spreadsheet you will need to change the Comment field for that line to the name of the microcontroller you want to use, and change the Footprint and LCSC Part Number as appropriate. The line for the microcontroller is highlighted in yellow in the BOM and CPL files.

### Compatible MCUs 

Boston uses a 128kb STM32F072CB-series microcontroller, and can accept either the LQFP-48 (STM32F072CxTx) or 48-UFQFPN (STM32F072CxUx ) versions. This is Line #19 on the JLCPCB BOM files. Due to fluctuations in price some variants may be cheaper over time. 

Any of the following microcontrollers will work, and support all features. 

**Compatible MCUs - JLCPCB BOM Line #19**
| Microcontroller | JLCPCB (LCSC) part number |
| --- | --- |
| STM32F072CBU6 | C92504 |
| STM32F072CBU7 | Not on JLCPCB |
| STM32F072CBU6TR | C2054107 |
| STM32F072CBU7TR | Not on JLCPCB |
| STM32F072CBT6 | C81720 |
| STM32F072CBT6TR | Not on JLCPCB |
| STM32F072CBT7 | C472592 |
| STM32F072CBU7TR | Not on JLCPCB |

The 64kb versions of the STM32F072 likely work (but has not been tested), but will only able to run base QMK. These do not support Vial (or VIA if VIA support is ever added in the future) as they do not have enough flash to support dynamic keymaps, so are not recommended. 

**Likely compatible, but won't support Vial - not recommended**
| Microcontroller | JLCPCB (LCSC) part number |
| --- | --- |
| STM32F072C8U6 | C784818 |
| STM32F072C8U7 | Not on JLCPCB |
| STM32F072C8U6TR | Not on JLCPCB |
| STM32F072C8U7TR | Not on JLCPCB |
| STM32F072C8T6 | C80488 |
| STM32F072C8T6TR | Not on JLCPCB |
| STM32F072C8T7 | Not on JLCPCB |
| STM32F072C8U7TR | Not on JLCPCB |

Other versions of the STM32F072 (which have different footprints or pin counts), or other STM32 microcontrollers will not work. 

### Other Interchangeable Parts On The PCB 

This is here for reference in case some parts are out of stock.

**U702 - JLCPCB BOM Line #17**
This is a SOT-223 linear regulator to drop the 5V down to 3.3V. Since ceramic capacitors are used the output, and some linear regulators are unstable with ceramic capacitors as their ESR is too low, the linear regulator needs to be explicitly compatible with low-ESR output capacitors.

| Part | JLCPCB (LCSC) part number |
| --- | --- |
| Diodes Inc AZ1117IH-3.3TRG1 (default) | C108495 |
| TI TLV1117LV33DCYR | C15578 |

**U705 - JLCPCB BOM Line #18**
This is a 74LVC1T45 level shifter in an SOT23-6 (SOT26) package. 

| Part | JLCPCB (LCSC) part number |
| --- | --- |
| TI SN74LVC1T45DBVR (Default)  | C7843 |
| TI SN74LVC1T45DBVT | C116653 |
| Diodes Inc 74LVC1T45W6-7 | C168856 |

## Ordering on Elecrow

Elecrow is a full-service PCB assembly shop, and one of the go-tos in the community for custom keyboard PCBs for the actual group buy sales. They can install any part (not just ones they stock) and generally have better quality surface finish, but is much slower (typically 3-4 week turn around time), and costs more (especially in small quantities). 

To order from Elecrow, you will need to email service@elecrow.com with the Gerber files and the files from the "Elecrow SMT files" folder for your respective PCB. They will get back to you with a quote.

On the spreadsheet (.xlsx) file, you will need to edit the first tab to specify your quantity, color, and surface finish. Elecrow's available colors and surface finishes are posted on their [PCB ordering page](https://www.elecrow.com/pcb-manufacturing.html)

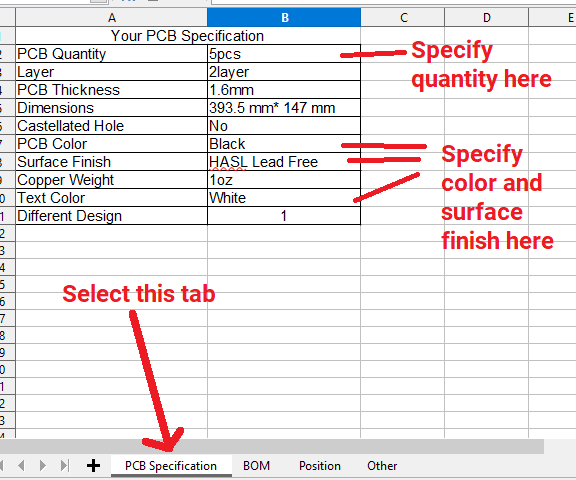
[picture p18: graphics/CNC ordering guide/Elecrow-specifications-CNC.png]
Elecrow


## Through Hole parts on the Main PCB

### Reset Switch
For JLCPCB, you will need to solder on the through-hole parts for the PCB yourself. Elecrow will solder this on for you, so this isn't necessary for Elecrow. 

The reset switch (next to the Right Shift key) uses a 5mm tall 6x6mm SPST NO through-hole tact switch. This is widely available from several vendors - I have used Wealth Metal [TC-0103](https://www.taydaelectronics.com/tact-switch-6x6mm-5mm-through-hole-spst-no.html), but TE 1825910-6, E-switch TL1105AF100Q, Omron B3F-1022, C&K PTS645SK50-2 LFS and numerous other parts should work (though it has not been tested). 

This is soldered onto the top side of the PCB next toe the Right Shift key, and is accessible through the plate when the Right Shift keycap is removed.

### Encoder
The encoder used is [Alps EC11E18244A5](https://octopart.com/ec11e18244a5-alps-757484?r=sp), the same one used on the Satisfaction75. Other EC11-style encoders may work, but may need changes to various QMK parameters (ENCODER_RESOLUTION in config.h, and possibly reversing ENCODERS_PAD_A and ENCODERS_PAD_B) to work correctly.

[LCSC](https://lcsc.com/product-detail/Rotary-Encoders_ALPSALPINE-EC11E18244A5_C255515.html) is the cheapest source of these encoders if you are running a group buy. They are run by the same parent company as JLCPCB, though unfortunately they cannot combine shipping. 

### LED spacer
For the lock LEDs, you will need to 3D print a [small spacer](https://github.com/bluepylons/Boston/tree/main/Boston%20-%20Current%20design/CNC%20version/Case/STL%20(3D%20print)). Units are in mm.  You can use an online printing service like [Shapeways](https://www.shapeways.com/) or [Craftcloud](https://craftcloud3d.com/), find a friend with a 3D printer, or purchase your own 3D printer to print this with. Your local library may have a 3D printer that may be available to use. The machine shop you use for the case may also offer 3D printing services. The spacer is designed to be printed using FDM printing, but other printing methods (SLA, SLS) probably also work. On my prototype I printed this out of PLA on a cheap $250 Ender 3 printer, with 0.2mm layer height.

Note that this spacer is different from the one on the 3D-printed version of Boston.

### Lock LEDs and resistors
Most standard 3mm LEDs should work, and are available in several different colors. 

If you are using the soldered PCB, you will need through-hole resistors for the lock LEDs. A 1KΩ resistor is a pretty safe resistor size for the LEDs, but depending on the LED forward voltage, current draw, and desired brightness, you may want to adjust this up or down. Standard 1/4W resistors are suitable.

Be aware that LEDs only work in one direction - the longer leg on LEDs is positive (+) - match this to the + markings on the PCB. 

These need to be soldered through the LED spacer discussed above. 

# Hardware

## Screws 

You will need the following screws for all variants. Part numbers for [McMaster-Carr](https://www.mcmaster.com) are provided, though you can easily find fasteners off other sources. McMaster also may not ship outside the United States.

| Description | Qty per board | McMaster-Carr P/N | Note | 
| --- | --- | --- |--- |
| M3x0.5, 5mm long ISO 4762 socket head cap screw, stainless steel | 12 | 91292A110 100-pack)  | Available from numerous other suppliers. Used to attach the plate to the case top, and to attach the daughterboard  to the case bottom. |
| M3x0.5, 10mm long ISO 4762 socket head cap screw, stainless steel | 4 | 91292A113 (100-pack) | Available from numerous other suppliers. Used for the front 4 case screws attaching the case top to the case bottom. |
| M3x0.5, 16mm long ISO 4762 socket head cap screw, stainless steel | 4 | 91292A115 (100-pack) | Available from numerous other suppliers. Used for the front 4 case screws attaching the case top to the case bottom. |

## Additional screws for the hotswap variant 
If you are putting together a hotswap board, standoffs to hold the PCB and plate together are strongly recommended, though you might be fine just relying on the switches to hold the plate and PCB together. The only known regular source of these is from KBDfans, unless you get them custom made with a standoff manufacturer.

| Description | Qty per board | Link or Part Number | Notes |
| ---  | --- | --- | --- |
| M2x0.4 3.5mm standoffs | 10 | [KBDfans](https://kbdfans.com/products/kbdfans-m2-3-countersunk-flat-head-screw-kit) (13-pack) | KBDfans kit comes with other screws |  
| M2x0.4 3mm long DIN 7985 pan head screw | 10 (countersunk plate) or 20 (regular plate) | McMaster-Carr 95836A103 (100-pack) | Above KBDfans kit comes with 13 of them |
| M2x0.4 3mm long DIN 965 flat-head screw | 10 (countersunk plate) or 0 (regular plate)  | McMaster-Carr 92010A784 (100-pack) | Above KBDfans kit comes with 13 of them |

If you are countersinking your hotswap plate, you should only need to buy a single 13-pack of the KBDfans standoff kit as it comes with all the required screws. If you are not countersinking the plate, you will need to buy some additional M2x0.4 3mm long pan head screws.

## Rubber feet 
Boston uses standard circular, dome-shaped rubber feet. The smaller feet go in the front while the larger feet go in the back. These are available in a few colors.

| Description | Qty per board | McMaster-Carr P/N | Other Compatible parts | 
| ---  | --- | --- | --- |
| 3/4" dia x 3/8" tall rubber feet | 2 | 95495K73 | 3M SJ5017 (black, gray, or white), 3M SJ5317 (clear) |
| 3/8" dia x 5/32" tall rubber feet | 2 | 95495K39 | 3M SJ5406 (white), 3M SJ5306 (clear), Essentra RBS-12BK (black), Essentra RBS-12 (clear) |

## Light Pipe
Boston uses a clear light pipe to transmit the RGBLED indicator light next to the knob. These use the following parts, which are available off numerous electronics distributors (Digi-key, Mouser, Newark, etc.). Links are provided to Octopart, which compiles all the websites you can buy the parts from (such as Digi-key, Mouser, Newark, and so on).

| Description | Qty per board |  Notes | 
| --- | --- | --- |
| [VCC LFC037CTP Light Pipe](https://octopart.com/lfc037ctp-vcc-54190594?r=sp) | 1 | |
| [VCC RTN125 Light Pipe Retainer](https://octopart.com/rtn125-vcc-54190599?r=sp) | 1 | |

The light pipe goes through the hole next to the knob. The retainer (which is a smaller rubber ring) is stuck on via the back to prevent the light pipe from falling off. If you so desire, you could also glue the light pipe in.

## Knobs
The Alps EC11E18244A5 rotary encoder used for the knob takes a 6mm knob with either a D-shaft or a set screw. This is a common size for guitars and audio equipment. 1/4" knobs can work but may be loose. 1/4" to 6mm adapters available from various sources if you want to use a 1/4" knob. 

The knob needs to be smaller than 23mm in diameter or it will hit the Esc key. 

I personally recommend Kilo International's OEDNI-75-X-7 lineup - these have very grippy knurling and can be easily rotated with one finger. They can be found on Digi-key, Newark, and other electronics parts vendors. If you use that knob, you want to 3D print a [small spacer](https://github.com/bluepylons/Boston/blob/main/Boston%20-%20Current%20design/3D%20printed%20version/STLs/Kilo-OEDNI-75-knob-spacer.stl) to place into the shaft hole on the knob, as otherwise the knob can sit too low and bump into the case. 

| Kilo P/N | Finish |
| --- | --- |
| OEDNI-75-1-7 | Silver, satin gloss |
| OEDNI-75-2-7 | Black, satin gloss  |
| OEDNI-75-3-7 | Silver, matte |
| OEDNI-75-4-7 | Black, matte |

## Daughterboard

The CNC version of Boston now uses the [S-series Unified Daughterboard](https://unified-daughterboard.github.io/#/db-spec-s), and is meant for use with PCB revisions V0.8 and newer. Various vendors sell this daughterboard, such as [Cannonkeys](https://cannonkeys.com/products/unified-s1-daughterboard-and-molex-cable) and [RNDKBD](https://rndkbd.com/products/unified-daughterboard?variant=42772031242474). You can also find manufacturing files for it on their website. 

Note that older PCBs (V0.6.1D and older) were meant to be used with the the older C3 Daughterboard, which as a different connector (a JST SM connector instead of a Molex PicoEZmate connector). You may need to find or make an adapter cable if you are using a V0.6.1D or older PCB with a case meant for the S1 Daughterboard. Cannonkeys includes a Molex to JST adapter cable with their Unified S1 daughterboard.

### Unified Daughterboard Cable

To connect the daughterboard and the main PCB, you will need a Molex PicoEZmate cable with [the correct pinout](https://unified-daughterboard.github.io/#/info-consumer?id=pinout) for Unified Daughterboards and that is at least 75mm long. The cables sold by keyboard vendors that come with their daughterboards should be the correct ones.

**Note that the PicoEZmate cables that Molex sells (part numbers 36920-04xx) do not have the correct pinout for use with Unified Daughterboards, and may damage your PCB**

If you need to make a cable, the Unified Daughterboard Project [suggests](https://unified-daughterboard.github.io/#/info-vendor?id=prototype-cables) buying pre-crimped wires and cable housings and making your own cables with the correct pinouts. You will need the following to make a cable; this will result in a long 300mm cable. Simply insert the pre-crimped wire ends into the connector housing until it clicks. 

| Molex P/N  | Qty needed | Description | Link | 
| --- | --- | --- | ---- |
| 079758101  | 4 | Pre-crimped wire | [Octopart](https://octopart.com/search?q=0797581010&currency=USD&specs=0) |
| 0781720004 | 2 | 4-pin connector housing | [Octopart](https://octopart.com/search?q=0781720004&currency=USD&specs=0) |

# Build instructions

Build instructions are currently [a work in progress](https://github.com/bluepylons/Boston/blob/main/Boston%20-%20Current%20design/CNC%20version/Assembly-guide.md).

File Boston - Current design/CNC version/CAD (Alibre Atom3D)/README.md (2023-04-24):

# CAD Files

These are the CAD files for the metal version. I did the CAD in [Alibre Atom3D](https://www.alibre.com/atom3d/), which costs around $150 for a perpetual license, but which does offer a 1-month long free trial. 

A [STEP file assembly](https://github.com/bluepylons/Boston/blob/master/Boston%20-%20Current%20design/Metal%20version/Boston-metal-assembly.stp) (which can be opened by almost any 3D CAD program) is in the main Metal Version directory. 

STEP files for just the case top and bottom (for sending to a machine shop for ordering) is in the [Case > STEP](https://github.com/bluepylons/Boston/tree/master/Boston%20-%20Current%20design/Metal%20version/Case/STEP) directory. An STL of the LED spacer for 3D printing is in the [Case > STLs](https://github.com/bluepylons/Boston/tree/master/Boston%20-%20Current%20design/Metal%20version/Case/STL%20(3D%20print)) directory. STEP and DXF files for the plates are in the [Plate](https://github.com/bluepylons/Boston/tree/master/Boston%20-%20Current%20design/Metal%20version/Plate) directory.

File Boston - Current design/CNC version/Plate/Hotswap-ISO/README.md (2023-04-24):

**Status**: 

* Gerber files (non-countersunk only): Done and checked over, not yet prototyped
* DXF files (used for both): Done and checked over, not yet prototyped
* STEP files (non-countersunk): Done and checked over, not yet prototyped
* STEP files (countersunk): Done and checked over, not yet prototyped

The countersunk version allows you to use countersunk screws for flush screwheads with the screws that attach to the PCB standoffs. You can ask your manufacturer to laser cut the plate using the DXF file and then countersink it according to the countersinking instructions.

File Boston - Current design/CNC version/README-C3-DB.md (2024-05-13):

# Boston CNC Version

CNC version

These are the files for the CNC version of Boston. The PCB is in the [PCB](https://github.com/bluepylons/Boston/tree/main/Boston%20-%20Current%20design/PCB) directory however. 

# Ordering Guide for making your own Boston (draft)

This is the ordering guide for the CNC version of Boston. 

**Order parts at your own risk. These files are provided as-is, and I am not responsible for any losses, harm, or damage incurred by following this guide, by ordering parts, by using the files provided, by using the resultant parts or assembled keyboard, or from any mistakes or errors in the files, ordering guide, or resultant parts** 

**This is for the older version that uses a C3 Unified Daughterboard. There is a newer design that uses  the new S1 daughterboard. This version is being prototyped by RNDKBD, and is awaiting confirmation that everything works. See [README-S1-DB.md](https://github.com/bluepylons/Boston/blob/main/Boston%20-%20Current%20design/CNC%20version/README-S1-DB.md) for the draft guide for that version.**

# What you will need:

### Parts:

# 
| Description | Qty per board | Type | Variants |
| --- | --- | --- | --- |
| Case top | 1 | Custom (CNC machined) | |
| Case bottom | 1 | Custom (CNC machined) | Yes (3)  |
| Plate | 1 | Custom (PCB, laser cut, waterjet cut, or CNC machined) | Yes (3)  |
| PCB | 1 | Custom (PCB) | Yes (3+) |
| SK6812 Mini-E RGBLED (if using JLCPCB for the PCB) | 1 | Off-the-shelf | |
| Daughterboard holder PCB | 1 | Custom (PCB) |
| LED spacer (for the lock LEDs - 3D printed) | 1 | Custom (3D-printed) |
| C3 Unified (or compatible) Daughterboard | 1 | Off-the-shelf or custom |
| JST cable (>75mm long) | 1 | Off-the-shelf or custom |
| M2x0.4 5mm socket head cap screw | 4 | Off-the-shelf |
| M3x0.5 5mm socket head cap screw | 14 | Off-the-shelf |
| M3x0.5 10mm socket head cap screw | 4 | Off-the-shelf |
| M3x0.5 16mm socket head cap screw | 4 | Off-the-shelf |
| PEM KF2-M2-ET threaded insert | 4 | Off-the-shelf |
| VCC LFC037CTP Light Pipe | 1 | Off-the-shelf |
| VCC RTN125 Light Pipe Retainer | 1 | Off-the-shelf |
| Alps EC11E18244A5 rotary encoder | 1 | Off-the-shelf |
| 6x6mm tact switch, 5mm high | 1 | Off-the-shelf |
| Knob suitable for 6mm D-shaft | 1 | Off-the-shelf |
| 3mm LED for lock LEDs | 3 | Off-the-shelf |
| 1KΩ through-hole resistor for lock LEDs | 3 | Off-the-shelf |
| 3/4" dia x 3/8" tall rubber dome feet | 2 | Off-the-shelf | 
| 3/8" dia x 5/32" tall rubber dome feet | 2 | Off-the-shelf |

| Description | Qty per board | 
| --- | --- |
| MX-style switches | 119-127 (depending on layout) |  
| Stabilizers (PCB mount) | 2-8 2u, 0-1 6.25u or 7u (depending on layout) |

For a standard ANSI build (using the fixed layout plate) you need 121 switches, 6 2u stabilizers, and 1 6.25u stabilizer.

### Tools:
| Description |  Used for |
| --- | --- |
| 2.5mm hex key or bit ("Allen key") | All M3 screws |
| T6 Torx, #1 Philips, 1.3mm, or 1.5mm hex key or bit | M2x5 screws (depends on what screws you buy) for the daughterboard  |
| Soldering iron and solder | For soldering everything |
| Flush cutters | For cutting legs off soldered LEDs and resistors |
| Large pliers, locking pliers ("Vise grips"), C-clamp, a vise, or oversized (~7mm dia) M2 washer  | For pressing the PEM threaded inserts into the daughterboard holder | 

# Case

Boston has a two piece case, consisting of the top and the bottom. It does not have a weight (though, if you have mechanical design and CAD skills, it should be pretty easy to add an internal weight to the design). 

There are two versions of the bottom case - the main version and the alternate version. The alternate version was actually what I designed first and prototyped, but it has very sharp edges on the bottom rear (near the rear bumpon) caused by the vertical faces, which are sharp enough to potentially cut into your skin. I changed the vertical faces to 45° beveled faces to eliminate those sharp edges. This version with the beveled 45° faces is the main version. Both versions have been prototyped.

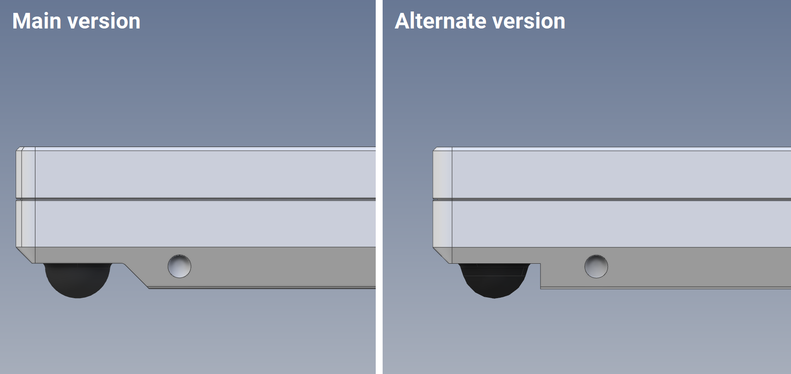
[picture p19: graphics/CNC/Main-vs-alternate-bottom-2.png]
Case bottom - main versus alternate 2


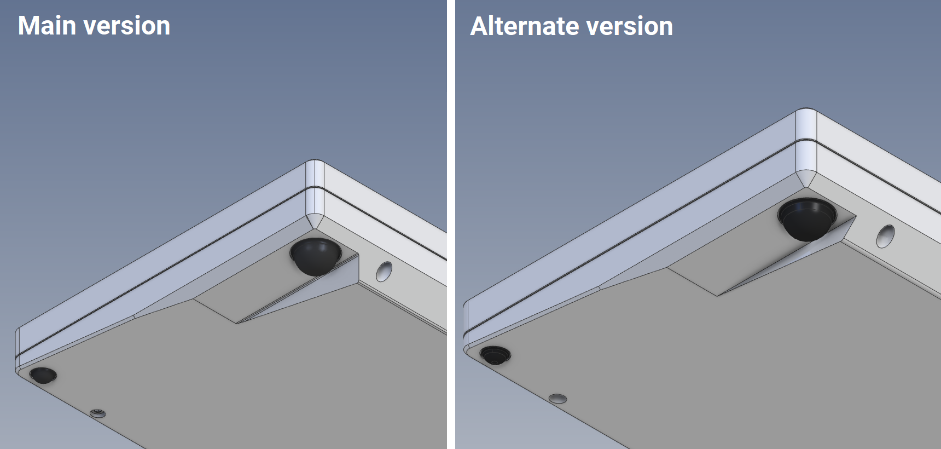
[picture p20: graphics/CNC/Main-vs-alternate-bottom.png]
Case bottom - main versus alternate


## How to contact a machine shop to order the case 

To have the case made, you will need to contact a machine shop with a CNC machine. These are informally referred to as "manus" by the mechanical keyboard community.

[Dadesin](https://dadesin.en.alibaba.com/) is a popular high-quality Chinese one, though expensive and somewhat backed up right now. I used [SuNPe](https://sunpe.com/) (also in China) for my prototypes, though the quality was middling. A friend ran a small private group buy through [Gaojie](https://www.gj-prototype.com) and had good results. There are numerous other ones. You can also reach out to a local CNC machine shop.  Note that usually there is a tradeoff between cost and quality, with cheaper shops often being lower quality or sloppier with their machining (and more prone to mistakes, like forgetting to machine features or forgetting to tap holes). 

You will need to send a "Request for Quote" email to them with the following files:

* 3D files - you will need the .STEP files for the [Top](https://github.com/bluepylons/Boston/blob/main/Boston%20-%20Current%20design/CNC%20version/Case/STEP/Boston-top.stp), and either the [Main Bottom](https://github.com/bluepylons/Boston/blob/main/Boston%20-%20Current%20design/CNC%20version/Case/STEP/Boston-bottom-C3-DB.stp) or the [Alternate Bottom](https://github.com/bluepylons/Boston/blob/main/Boston%20-%20Current%20design/CNC%20version/Case/STEP/Boston-bottom-C3-DB-alternate%20(sharp%20edges).stp). 
* The mechanical drawings, which include the tapping instructions for the tapped (threaded) holes. [Top](https://github.com/bluepylons/Boston/blob/main/Boston%20-%20Current%20design/CNC%20version/Case/Manufacturing%20drawings/Boston-top.pdf), [Main Bottom](https://github.com/bluepylons/Boston/blob/main/Boston%20-%20Current%20design/CNC%20version/Case/Manufacturing%20drawings/Boston-bottom-C3-DB.pdf), [Alternate Bottom](https://github.com/bluepylons/Boston/blob/main/Boston%20-%20Current%20design/CNC%20version/Case/Manufacturing%20drawings/Boston-bottom-C3-DB-alternate.pdf)
* If you want a raw as-machined finish with visible tool marks, or want to anodize directly over the tool marks, you may want to include the milling instructions for more pleasing tool marks. [Top](https://github.com/bluepylons/Boston/blob/main/Boston%20-%20Current%20design/CNC%20version/Case/Manufacturing%20drawings/Boston-top-AS-MACHINED-milling-instructions.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), [Main Bottom](https://github.com/bluepylons/Boston/blob/main/Boston%20-%20Current%20design/CNC%20version/Case/Manufacturing%20drawings/Boston-bottom-AS-MACHINED-milling-instructio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), [Alternate Bottom](https://github.com/bluepylons/Boston/blob/main/Boston%20-%20Current%20design/CNC%20version/Case/Manufacturing%20drawings/Boston-bottom-alternate-AS-MACHINED-milling-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). If you are going for a bead-blasted finish, you do not need to include these. These are PNG images with picture illustrations, as many machine shops are overseas and do not speak English well. 
* In the body of the email, you want to specify the quantity, material, and the surface finish, as well as that you want these parts to be made by CNC machining. Materials and surface finish are discussed more in depth in the next sections.

You will also need to specify a material and a finish, a color for the finish (if you are anodizing, e-coating, painting, powder coating, or Cerakoting), as well as the quantity you want to order. Here is an example email reaching out to a manufacturer for a quote:

Example email to manufacturer

The manufacturer will get back to you with a quote. If you wish to proceed with the quote, let them know that you wish to proceed, and they will send you instructions for payment (often via Paypal or bank transfer) and ask for a shipping address. 

With a Chinese shop, expect to pay $300-$600 for a single case machined out of aluminum (and about $60-$150 for shipping - note that some machine shops inflate their shipping costs). Expect higher for a US or EU shop. The price each usually goes down if you order more (even 3-5 units can lower the price significantly for each board over ordering just 1). 

## Material

Most custom keyboards are made out of aluminum. There are several different aluminum alloys that are commonly used:

* **6061** - this is a general purpose aluminum alloy and the most common aluminum alloy used for CNC-machined parts. It's a jack of all trades, with decent strength, anodizing finish quality, machinability, and corrosion resistance compared to other aluminum alloys, as well as other desirable properties for some non-keyboard applications (e.g. weldability). Due to its ubiquity and ease of machining it will likely be the cheapest aluminum alloy to make your keyboard out of. All of the prototypes of Boston used 6061. 

* **6063** - Also known as "architectural aluminum", this tends to anodize a bit nicer than 6061, but is half the strength of 6061 and somewhat softer. This means the keyboard will dent more easily, threads will strip more easily (though Boston uses larger M3 threads that are harder to strip than the smaller M2 threads found on many keyboards), and if you have a raw finish, the aluminum will scratch more easily.

* **5052** - I honestly don't know why this gets used in keyboards, as it's mostly used in industry for bent sheet metal (as it bends well without cracking, unlike 6061) and for welding. It's weaker than 6061, but stronger than 6063.

* **7075** - 7075 is a significantly stronger and harder alloy than 6061, and somewhat more expensive, but doesn't anodize as well (it can anodize, but the colors are more limited and the finish won't be as good). If you're looking to keep a raw aluminum finish, 7075 will  be a bit harder to scratch (though it will still scratch quite easily). It will also be harder to dent, and the threads will be more resistant to stripping. However, in raw form it is less corrosion resistant than 6061. 

Other commonly used materials for keyboards - you can use the same files to CNC machine a case out of these materials.
* Polycarbonate
* POM (also known as acetal, and under various proprietary names such as Delrin®). You mostly likely will only be able to obtain this in white or black.
* Brass - brass is expensive and heavy, but machines very well. Note that common brass alloys use for machining (such as brass 360 alloy) have a substantial lead content, and you probably want to specify a coating to avoid lead exposure from handling the keyboard.

There are also more exotic materials, such as stainless steel, titanium, various nickel alloys, copper alloys, and so on that you could hypothetically make a Boston keyboard with using the same files. These are generally much more difficult to machine, and will be very expensive. 

## Surface finish 

In addition to the material, you want to pick a surface finish. There are two parts to this - the texture, and the coating. The vast majority of custom keyboards use a fine bead blasted texture with a Type II anodization coating, which can be dyed different colors. 

### Textures:
* **As-machined** - this is the finish straight out of the CNC, with tool marks, scratches, and all. The appearance of the tool marks and roughness may vary significantly depending on the machine shop's choice of tool, tool path, and feeds and speeds. Using a fly cutter or large face mill and a fine finishing pass can result in *very* shiny finishes. Not common in keyboards, though it's shown up on some Keycults. All of the prototypes of the CNC Boston used an as-machined finish. You can anodize over the tool marks directly, though this is also uncommon. Note that some machine shops occasionally will deburr sharp edges with scour pads, sandpaper, or a wirebrush, which may remove some of the tool marks. If you want the tool marks preserved, you need to tell them to not deburr with those tools. The as-machined milling instructions specify to not use those tools. 
* **Bead Blasted** - this involves blasting the keyboard with fine glass beads for an even matte finish. Most metal keyboards are bead blasted, as well as almost all aluminum consumer electronics (iPhones, Macbooks, etc.). This is almost always paired with a Type II anodize (though you need to specify the anodization separately). Note that there are different roughnesses available, ranging from coarse to fine. I'm not familiar with the specifications for these, but you probably want to specify a "fine" or "very fine" roughness, or specify a specific size. The [Bakeneko60](https://github.com/kkatano/bakeneko-60) specifies a #150 bead blast finish.  
* **Brushed** - this involves using a wirebrush or flapper wheel to impart horizontal streaks across your parts. Not common in keyboards, though you occasionally see it in other consumer electronics. Again, there are different roughnesses available. 
* **Tumbled** - this uses a large tumbling machine and tumbling media (ranging from to plastic  beads to corn cob and walnut husks) to apply an even finish to the part. Again, different roughnesses are available. I'm not aware of any keyboards that use this and am unfamiliar with the textures you can achieve with this, but you can ask if your machine shop can do it. 
* **Polished** - this involves buffing out the case using either a polishing wheel or a tumbling process. I'm not very familiar with this, but you can ask your machine shop.

### Coatings:
* **Anodized** - almost all aluminum on consumer electronics (including custom keyboards) are anodized, usually over a fine bead-blasted finish. Anodizing generates a protective layer of aluminum oxide on the outside of the part, which is much harder than the underlying raw aluminum. This significantly improves the scratch resistance, and also protects the aluminum from corrosion. This layer of aluminum oxide can be clear (showing the underlying silver aluminum), or be dyed a wide range of different colors ([except for white](https://www.bluebuddhaboutique.com/blog/2011/09/no-white-anodized-aluminum/)). However, if you're going for a shiny as-machiend or polished finish, it does dull the aluminum a bit. There are a couple of types of anodizing, but Type II (cosmetic anodizing) is the most common, and what you probably want as it is inexpensive, and available in a wide variety of colors. Type III (Hard Anodizing) is occasionally done but uncommon in consumer electronics - Type III generates a much thicker layer of aluminum oxide than Type II, resulting in a dark gray, black, or bronze-brown color. This results in very good wear and scratch resistance, but costs more, can interfere with threaded holes, and is generally unnecessary for keyboards. Note that many machine shops outsource their anodizing, though some (e.g. Dadesin) anodize in-house. If you want to read up more on anodizing, [this](https://omwcorp.com/understanding-and-specifying-anodizing-2/) is a good document to go over (thanks to Croktopus for finding the document). 
* **Raw aluminum** - this means not using any coating whatsoever and leaving the bare metal exposed. Note that raw aluminum is easily scratched (and will most likely arrive from the machine shop with scratches from shipping and handling), so this is a fairly uncommon finish. It may also discolor from corrosion. However, paired with an as-machined or polished finish texture, it can be extremely shiny and reflective. All of my prototypes had a raw finish.   
* **E-coat**, **paint**, **powder coat**, or **Cerakote** - I am not familiar with ordering these finishes, but they show up on keyboards from time to time. 

**Note that any coating that adds appreciable (>0.03mm) thickness (such as Type III hard anodizing, powder coat, e-coat, paint, and Cerakote) will require the threaded holes and the RGBLED hole to be masked off. Standard (Type II) anodizing is usually thin enough that interference isn't an issue and masking holes should not be needed. 

RGBLED hole that needs to be masked

# Plate

Boston has a top mount plate. There are two versions of the plate - a fixed layout version that accommodates only the standard ANSI layout (with a non-stepped Caps Lock key), and a universal layout that should accommodate any of the layouts (split space, ISO, etc.) that the PCB supports. Both plates have been prototyped. 

The plate should be made out of 1.4-1.6mm material (which is the official Cherry spec for having the switches click in properly). 

**Fixed ANSI plate**:
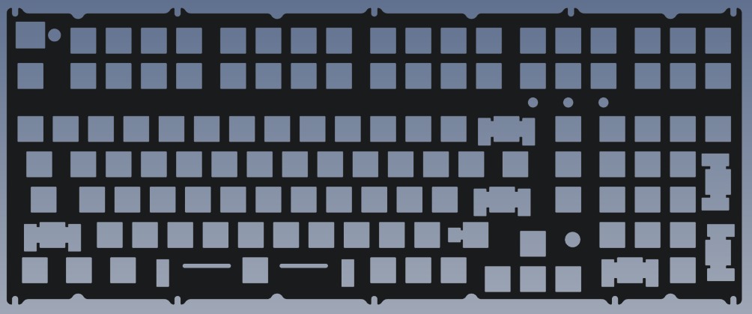
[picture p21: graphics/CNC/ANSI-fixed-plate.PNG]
Fixed Layout Plate

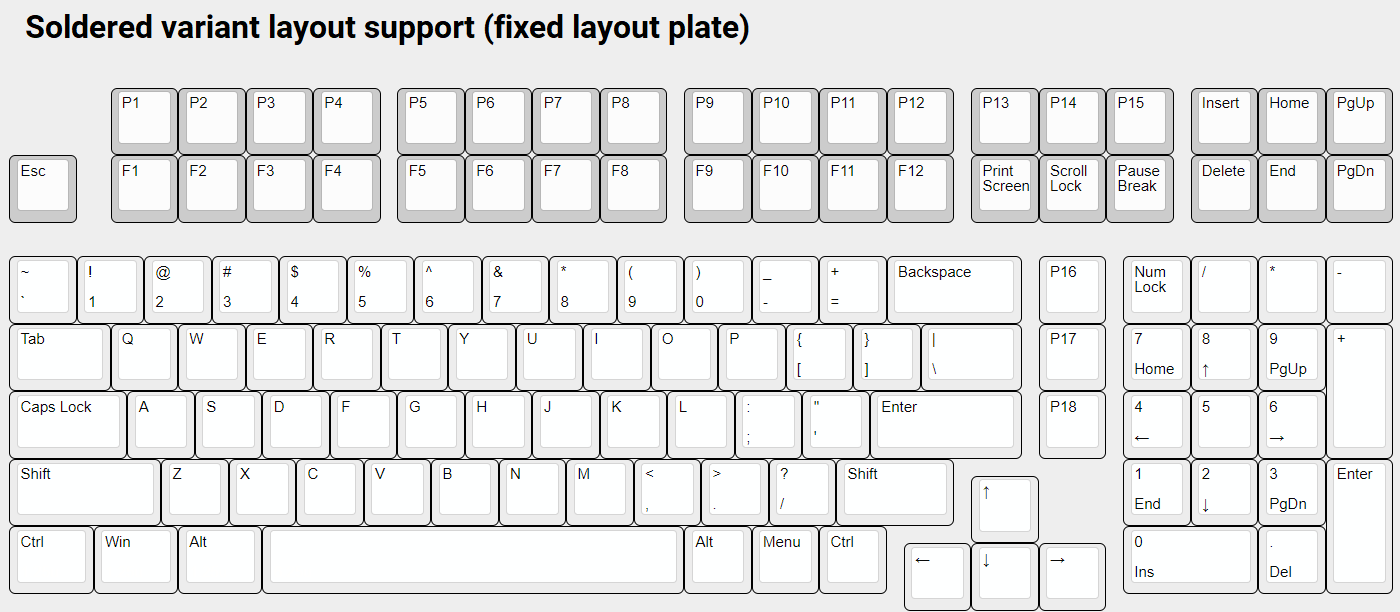
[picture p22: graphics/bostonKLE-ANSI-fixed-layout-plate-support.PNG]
KLE of the fixed layout


**Universal plate**:
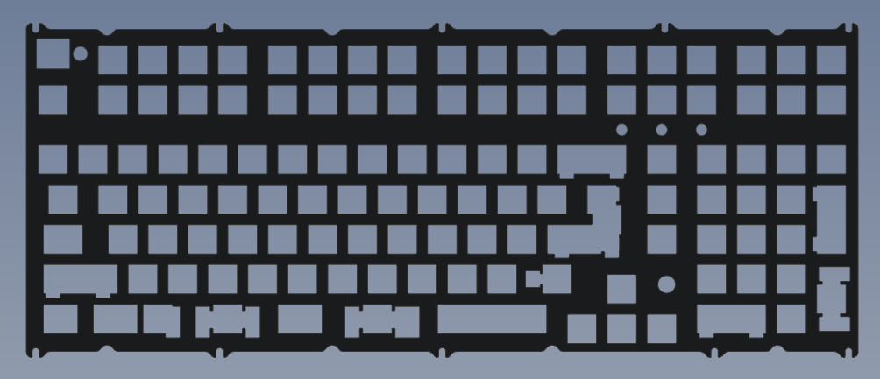
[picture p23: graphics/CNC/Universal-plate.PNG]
Universal Layout Plate

KLE of the universal layout

The plate files are available [here](https://github.com/bluepylons/Boston/tree/main/Boston%20-%20Current%20design/CNC%20version/Plate). 

If you are looking to have a plate laser cut or water jet (via a service such as [Sendcutsend](https://sendcutsend.com/) in the US, [Laserboost](https://www.laserboost.com/) in the EU, or elsewhere), you want to use the DXF files (.dxf). The units are in mm. You can upload it to their website. Many Chinese CNC machine shops have laser cutters, and can also make your plate in addition to your case if you send them the files. Make that sure the thickness of the material you choose is between 1.4mm and 1.6mm. 
* Virtually all metals (aluminum, brass, steel, titanium etc ). can be laser cut. 
* Some plastics (such as POM) laser cut well. 

If you are looking to have the plate CNC machined, you want to use the STEP (.stp) file. Again, the units are in mm. CNC machining is necessary for some materials like polycarbonate and carbon fiber. 

If you are looking to have the plate made out of FR4 or aluminum PCB material, you want to use the .zip Gerber files. This will have to be ordered as a PCB, and can be uploaded to any PCB supplier (JLCPCB, Elecrow, PCBway, AllPCB, etc.). Note that some PCB manufacturers (e.g. JLCPCB) charge an additional fee for plates due to the amount of milling required compared to a typical PCB. Choose 1.6mm for the PCB thickness. 

Note - on JLCPCB, make sure that "Specify A Location" for "Remove Order number" is selected so that the order number doesn't get printed somewhere you don't want. The Gerber files have the requisite "JLCJLCJLCJLC" text on them and placed in an unobstrusive location.

Remove Order Number 

 Also, "Paper between PCBs" under "Advanced Options" is strongly recommended- otherwise there's a decent risk of FR4 parts showing up scratched. 
 
Paper Between PCBs

# Hardware

## Screws 

You will need the following screws. Part numbers for [McMaster-Carr](https://www.mcmaster.com) are provided, though you can easily find fasteners off other sources. McMaster also may not ship outside the United States.

| Description | Qty per board | McMaster-Carr P/N | Notes | 
| --- | --- | --- | --- |
| M3x0.5, 5mm long ISO 4762 socket head cap screw, stainless steel | 14 | 91292A110 | Available from numerous other suppliers. Used to attach the plate to the case top, and to attach the daughterboard holder to the case bottom. |
| M3x0.5, 10mm long ISO 4762 socket head cap screw, stainless steel | 4 | 91292A113 | Available from numerous other suppliers. Used for the front 4 case screws attaching the case top to the case bottom. |
| M3x0.5, 16mm long ISO 4762 socket head cap screw, stainless steel | 4 | 91292A115 | Available from numerous other suppliers. Used for the front 4 case screws attaching the case top to the case bottom. |
| M2x0.4, 5mm long ISO 7045 button head screw, Torx T6, stainless steel | 4 | 90362A136 | Other M2 screw types (e.g. ISO 7380 button head) or driver types (e.g. Philips #2) would also work ok. Used to attach the daugterhboard to the daughterboard holder. |

## PEM nuts (threaded inserts)

The daughterboard holder uses PEM KF2-M2-ET tin-plated threaded inserts, which are pressed in and soldered onto the holes the daughterboard holder. You will need 4 of these. They're available off [Mouser](https://www.mouser.com/ProductDetail/PEM/KF2-M2-ET?qs=l4Gc20tDgJIwDb1wwu7XpQ%3D%3D), [McMaster-Carr](https://www.mcmaster.com/95117A477/), and elsewhere. 

You can press these in with large pliers (though this tends to scratch the other side of the PCB), with Vise-grip style locking pliers, a C-clamp, or with a vise. A hammer might work but you risk damaging the threads. You also may also be able to pull the insert into the hole using an M2 screw and an over-sized M2 washer (e.g. McMaster-Carr 91116A240), though this likely only works with a Torx M2 screw (as the hex and Philips head versions strip too easily). 

## Rubber feet 
Boston uses standard circular, dome-shaped rubber feet. These are available in several colors. 

| Description | Qty per board | McMaster-Carr P/N | Other Compatible parts | 
| ---  | --- | --- | --- |
| 3/4" dia x 3/8" tall rubber feet | 2 | 95495K73 | 3M SJ5017 (black, gray, or white), 3M SJ5317 (clear) |
| 3/8" dia x 5/32" tall rubber feet | 2 | 95495K39 | 3M SJ5406 (white), 3M SJ5306 (clear), Essentra RBS-12BK (black), Essentra RBS-12 (clear) |

## Light Pipe
Boston uses a clear light pipe to transmit the RGBLED indicator light next to the knob. These use the following parts, which are available off numerous electronics distributors (Digi-key, Mouser, Newark, etc.). 

| Description | Qty per board |  Notes | 
| --- | --- | --- |
| [VCC LFC037CTP Light Pipe](https://octopart.com/lfc037ctp-vcc-54190594?r=sp) | 1 | |
| [VCC RTN125 Light Pipe Retainer](https://octopart.com/rtn125-vcc-54190599?r=sp) | 1 | |

The light pipe goes through the hole next to the knob. The retainer (which is a smaller rubber ring) is stuck on via the back to prevent the light pipe from falling off. If you so desire, you could also glue the light pipe in.

## Knobs
The Alps EC11E18244A5 rotary encoder used for the knob takes a 6mm knob with either a D-shaft or a set screw. This is a common size for guitars and audio equipment. 1/4" knobs can work but may be loose. 1/4" to 6mm adapters available from various sources if you want to use a 1/4" knob. 

The knob needs to be smaller than 23mm in diameter or it will hit the Esc key. 

I personally recommend Kilo International's OEDNI-75-X-7 lineup - these have very grippy knurling and can be easily rotated with one finger. They can be found on Digi-key, Newark, and other electronics parts vendors. If you use that knob, you want to 3D print a [small spacer](https://github.com/bluepylons/Boston/blob/main/Boston%20-%20Current%20design/3D%20printed%20version/STLs/Kilo-OEDNI-75-knob-spacer.stl) to place into the shaft hole on the knob, as otherwise the knob can sit too low and bump into the case. 

| Kilo P/N | Finish |
| --- | --- |
| OEDNI-75-1-7 | Silver, satin gloss |
| OEDNI-75-2-7 | Black, satin gloss  |
| OEDNI-75-3-7 | Silver, matte |
| OEDNI-75-4-7 | Black, matte |

# PCBs

# Main PCB
The CNC version of Boston uses the [V0.6.1D PCB](https://github.com/bluepylons/Boston/tree/main/Boston%20-%20Current%20design/PCB/V0.6.1D) (D for Daughterboard) - this **not the same PCB as the 3D printed version** due to the daughterboard, though they use the same firmware as the matrix is identical.

For the PCB - you can order an assembled PCB (minus through-hole parts such as the encoder, RGBLED, and reset switch) from a PCB fab such as JLCPCB or Elecrow.

## Ordering on JLCPCB
[JLCPCB](https://jlcpcb.com/) is cheap and fast, but doesn't have the best cosmetic finish, and their SMT assembly is limited to parts [they stock](https://jlcpcb.com/parts) (though they recently announced "Global Parts Sourcing"). In the community they tend to only be used for prototypes.

To order a PCB from JLCPCB, you will need the Gerber files (which defines the bare PCB), the SMT bill of materials (BOM file, which is a list of parts that are to be soldered to the PCB), and the component placement file (CPL, which defines where those parts go). The files for PCB revision V0.6.1D are available [here](https://github.com/bluepylons/Boston/tree/main/Boston%20-%20Current%20design/PCB/V0.6.1D/Manufacturing%20files). 

**Note that JLCPCB does not offer the SK6812 Mini-E RGBLED used for LED702 for Economic PCB Assembly**, and you will have to solder order this elsewhere and solder it on manually yourself. Adafruit sells it as the [Neopixel Reverse mount](https://www.adafruit.com/product/4960), and it is also available off [Digi-key](https://www.digikey.com/en/products/detail/adafruit-industries-llc/4960/14302512) (but oddly enough, not Mouser). Line up the notch on the LED with the notch marking on the PCB when you are soldering it.

First, you want to go to [JLCPCB](https://jlcpcb.com/), and press "Order Now".

Step 1

Next, you want to upload the Gerber file for the PCB. You may need to manually input the PCB dimensions (393.5x147mm). 

Step 2

Here, you want to change the specifications to the following. PCB Color and Surface Finish needs to be a combo supported for Economic PCB Assembly in 1.6mm thickness - currently (April 30, 2023), this would be Green in any finish, Black in any finish except ENIG, and Blue, Red, and White with HASL-Leaded. 

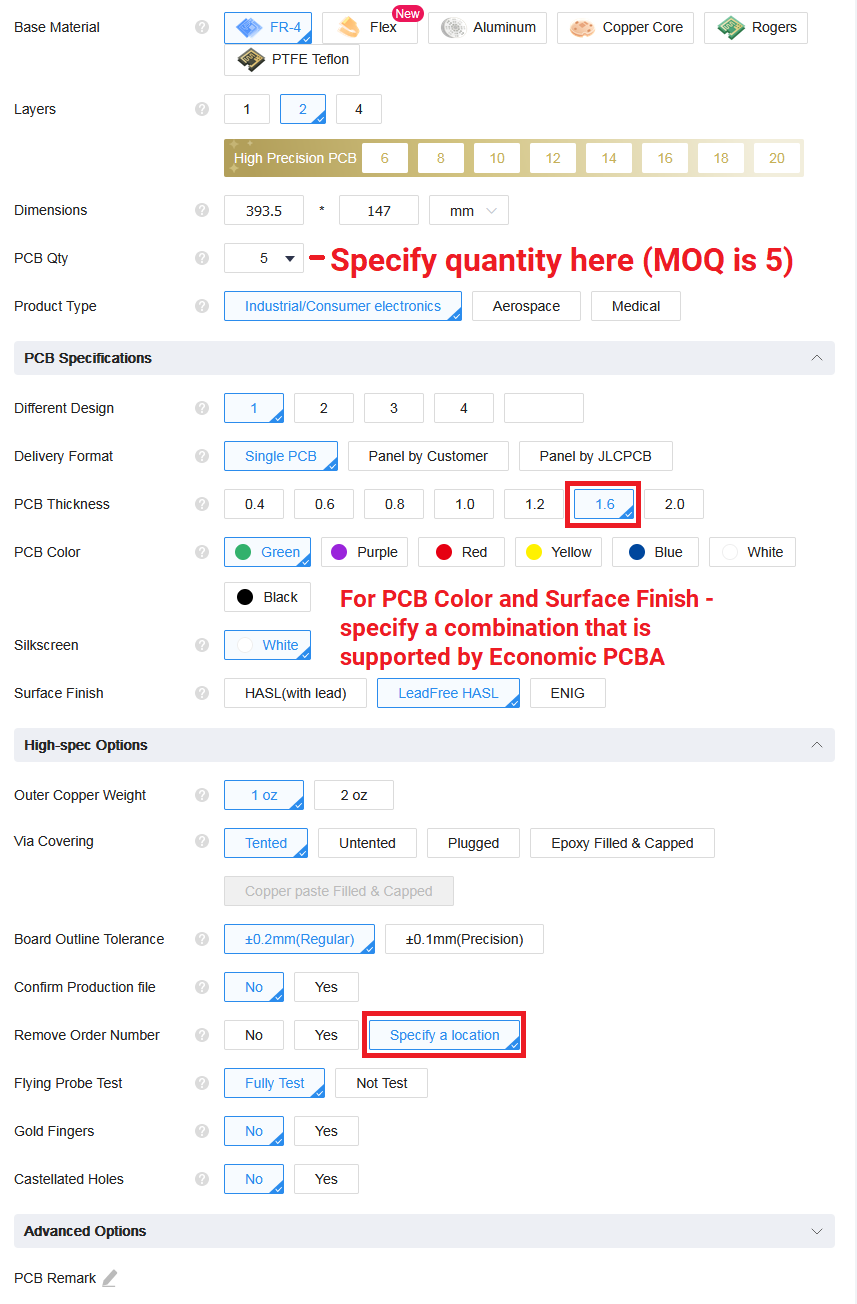
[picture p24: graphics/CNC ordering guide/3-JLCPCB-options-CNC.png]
Step 3


Next, you want to scroll down and turn on PCB Assembly. Make sure the following options are selected:

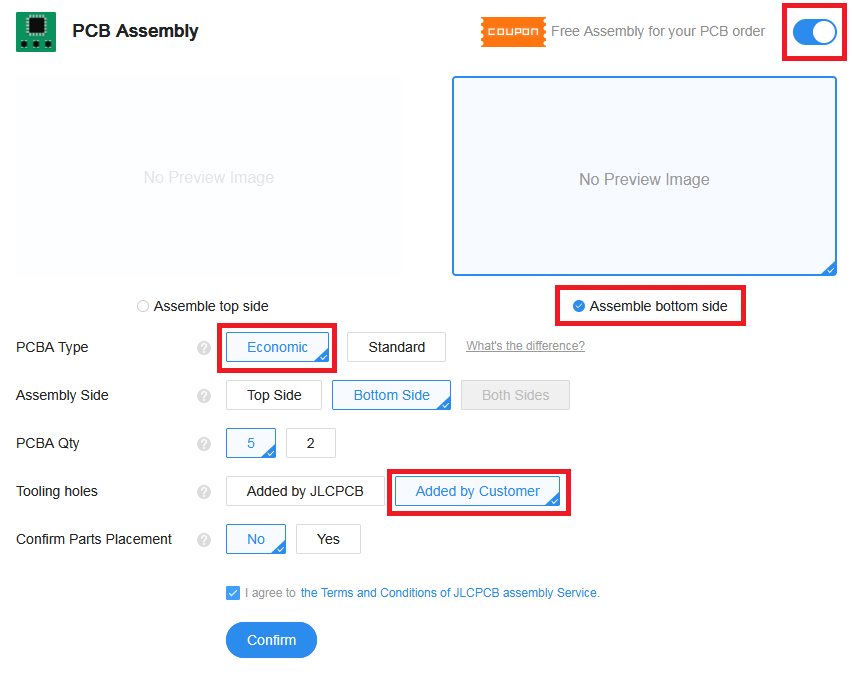
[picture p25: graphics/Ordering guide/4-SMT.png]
Step 4


Press Confirm. Next, you want to upload the BOM and CPL files. 

Step 5

Make sure that all the components are selected. Any part that says "Inventory shortage" will not be installed, and you will have to substitute a compatible part, wait for the part to come back in stock, or if you're up to the challenge of SMT soldering, order the part separately and solder it on yourself. 

Step 6

The next page is a confirmation page. Note that the parts placement preview may be inaccurate (JLCPCB engineers will look over this and make any parts orientation corrections, so don't worry too much about this). 

Step 7

As the microcontroller is frequently out of stock due to the chip shortage, line number 16 (for designator U701) can be changed for different compatible MCUs (see the "Compatible MCUs" section below for a list of MCUs that will work). At different times some microcontroller variants may be cheaper than the others (for example, on August 29, 2022, the STM32F072CBT6 is $4.50 and the STM32F072CBU6 is $9.52, whereas during other times -CBU6 has been significantly cheaper than the -CBT6). You will need to change the Comment field for that line to the name of the microcontroller you want to use, and change the Footprint and LCSC Part Number as appropriate.

### Compatible MCUs 

Boston uses a 128kb STM32F072CB-series microcontroller, and can accept either the LQFP-48 (STM32F072CxTx) or 48-UFQFPN (STM32F072CxUx ) versions.

Any of the following microcontrollers will work, and support all features. 

**Compatible MCUs**
| Microcontroller | JLCPCB (LCSC) part number |
| --- | --- |
| STM32F072CBU6 | C92504 |
| STM32F072CBU7 | Not on JLCPCB |
| STM32F072CBU6TR | C2054107 |
| STM32F072CBU7TR | Not on JLCPCB |
| STM32F072CBT6 | C81720 |
| STM32F072CBT6TR | Not on JLCPCB |
| STM32F072CBT7 | C472592 |
| STM32F072CBU7TR | Not on JLCPCB |

The 64kb versions of the STM32F072 likely work (but has not been tested), but will only able to run base QMK. These do not support Vial (or VIA if VIA support is ever added in the future) as they do not have enough flash to support dynamic keymaps, so are not recommended. 

**Likely compatible, but won't support Vial - not recommended**
| Microcontroller | JLCPCB (LCSC) part number |
| --- | --- |
| STM32F072C8U6 | C784818 |
| STM32F072C8U7 | Not on JLCPCB |
| STM32F072C8U6TR | Not on JLCPCB |
| STM32F072C8U7TR | Not on JLCPCB |
| STM32F072C8T6 | C80488 |
| STM32F072C8T6TR | Not on JLCPCB |
| STM32F072C8T7 | Not on JLCPCB |
| STM32F072C8U7TR | Not on JLCPCB |

Other versions of the STM32F072 (which have different footprints or pin counts), or other STM32 microcontrollers will not work. 

### Other Interchangeable Parts On The PCB 

This is here for reference in case some parts are out of stock.

**U702 - BOM Line #17**
This is a SOT-223 linear regulator to drop the 5V down to 3.3V. Since ceramic capacitors are used the output, and some linear regulators are unstable with ceramic capacitors as their ESR is too low, the linear regulator needs to be explicitly compatible with low-ESR output capacitors.

| Part | JLCPCB (LCSC) part number |
| --- | --- |
| Diodes Inc AZ1117IH-3.3TRG1 (default) | C108495 |
| TI TLV1117LV33DCYR | C15578 |

**U705 - BOM Line #18**
This is a 74LVC1T45 level shifter in an SOT23-6 (SOT26) package. 

| Part | JLCPCB (LCSC) part number |
| --- | --- |
| TI SN74LVC1T45DBVR (Default)  | C7843 |
| TI SN74LVC1T45DBVT | C116653 |
| Diodes Inc 74LVC1T45W6-7 | C168856 |

## Ordering on Elecrow

Elecrow is a full-service PCB assembly shop, and one of the go-tos in the community for custom keyboard PCBs for the actual group buy sales. They can install any part (not just ones they stock) and generally have better quality surface finish, but is much slower (typically 3-4 week turn around time), and costs more (especially in small quantities). 

To order from Elecrow, you will need to email service@elecrow.com with the [Gerber](https://github.com/bluepylons/Boston/blob/main/Boston%20-%20Current%20design/PCB/V0.6.1D/Manufacturing%20files/Gerbers-V06-1D.zip) and [SMT](https://github.com/bluepylons/Boston/tree/main/Boston%20-%20Current%20design/PCB/V0.6.1D/Manufacturing%20files/Elecrow%20SMT%20files) files and request a quote. **Note - the Elecrow files have not been tested**

On the [SMT file](https://github.com/bluepylons/Boston/tree/main/Boston%20-%20Current%20design/PCB/V0.6.1D/Manufacturing%20files/Elecrow%20SMT%20files), you will need to edit the first tab to specify your quantity, color, and surface finish. Elecrow's available colors and surface finishes are posted on their [PCB ordering page](https://www.elecrow.com/pcb-manufacturing.html)

Elecrow

Elecrow will install the RGBLED (LED702), unlike JLCPCB, so you do not need to buy it separately and solder it on yourself. 

## Through Hole parts on the Main PCB
For both Elecrow and JLCPCB, you will need to solder on the through-hole parts for the PCB yourself. 

### Reset Switch

The reset switch (next to the Right Shift key) uses a 5mm tall 6x6mm SPST NO through-hole tact switch. This is widely available from several vendors - I have used Wealth Metal [TC-0103](https://www.taydaelectronics.com/tact-switch-6x6mm-5mm-through-hole-spst-no.html), but TE 1825910-6, E-switch TL1105AF100Q, Omron B3F-1022, C&K PTS645SK50-2 LFS and numerous other parts should work (though it has not been tested). 

This is soldered onto the top side of the PCB, and is accessible through the plate when the Right Shift keycap is removed.

### Encoder
The encoder used is [Alps EC11E18244A5](https://octopart.com/ec11e18244a5-alps-757484?r=sp), the same one used on the Satisfaction75. Other EC11-style encoders may work, but may need changes to various QMK parameters (ENCODER_RESOLUTION in config.h, and possibly reversing ENCODERS_PAD_A and ENCODERS_PAD_B) to work correctly.

[LCSC](https://lcsc.com/product-detail/Rotary-Encoders_ALPSALPINE-EC11E18244A5_C255515.html) is the cheapest source of these encoders if you are running a group buy. They are run by the same parent company as JLCPCB, though unfortunately they cannot combine shipping. 

### LED spacer
For the lock LEDs, you will need to 3D print a [small spacer](https://github.com/bluepylons/Boston/tree/main/Boston%20-%20Current%20design/CNC%20version/Case/STL%20(3D%20print)). Units are in mm.  You can use an online printing service like [Shapeways](https://www.shapeways.com/) or [Craftcloud](https://craftcloud3d.com/), find a friend with a 3D printer, or purchase your own 3D printer to print this with. Your local library may have a 3D printer that may be available to use. The machine shop you use for the case may also offer 3D printing services. The spacer is designed to be printed using FDM printing, but other printing methods (SLA, SLS) probably also work. On my prototype I printed this out of PLA on a cheap $250 Ender 3 printer, with 0.2mm layer height.

### Lock LEDs and resistors
Most standard 3mm LEDs should work, and are available in several different colors. A 1KΩ resistor is a pretty safe resistor size for the LEDs, but depending on the LED forward voltage, current draw, and desired brightness, you may want to adjust this up or down. Standard 1/4W resistors are suitable.

Be aware that LEDs only work in one direction - the longer leg on LEDs is positive (+) - match this to the + markings on the PCB. 

These need to be soldered through the LED spacer discussed above. 

## Daughterboard
Like many other custom keyboards that use a daughterboard, the CNC version of Boston uses the [C3 Unified Daughterboard](https://github.com/ai03-2725/Unified-Daughterboard), . Files for that are available on their GitHub repo. Note the C3 PCB is too small for JLCPCB's SMT assembly service, unless you panelize it. 

Several vendors also sell the C3 Daughterboard (e.g. [Cannonkeys](https://cannonkeys.com/products/unified-daughterboard-and-jst-cable), [Charue Designs](https://charue-design.com/products/unified-daughterboard-and-jst-cable), [Senseless Clay](https://senselessclay.com/products/usb-type-c-daughterboard), and others). 

### JST Cable 
To connect the daughterboard and the main PCB, you will need a 4-pin JST-SH capable that matches the [specifications laid out on ai03's C3 daughterboard GitHub repo](https://github.com/ai03-2725/Unified-Daughterboard/tree/master/Design%20Resources/C3). Sparkfun's Qwiic and Adafruit's Stemm QT cables (which are available in several lengths) match the specifications and work just fine. A minimum length of 75mm is recommended - both [Adafruit](https://www.adafruit.com/product/4210) and [Sparkfun](https://www.sparkfun.com/products/14427) offer 100mm long cables (and are also sold on Digi-key and Mouser). Some sellers of C3 Daughterboards (such as Cannonkeys) also include a cable with their daughterboards. 

## Daughterboard holder

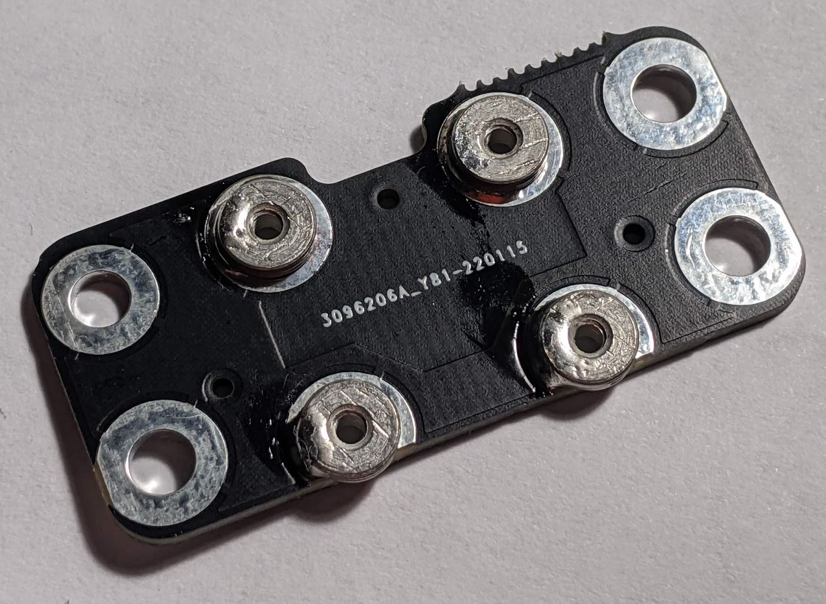
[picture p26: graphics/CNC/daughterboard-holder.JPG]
Daughterboard Holder


To mount the daughterboard low on the board, the daughterboard is screwed onto a daughterboard holder that then mounts onto the case bottom. This allows the daughterboard to be held upside down, which allows for it to be mounted much lower. 

The daughterboard holder is a bare PCB that can be ordered from JLCPCB, Elecrow, PCBway, or another PCB manufacturing service using the Gerber files available [here](https://github.com/bluepylons/Boston/blob/main/Boston%20-%20Current%20design/CNC%20version/Daughterboard%20holder/Daughterboard-holder-gerbers.zip).  It does not need any SMT assembly. 

The daughterboard holder is 1.6mm thick. 

Note - on JLCPCB, make sure that "Specify A Location" for "Remove Order number" is selected so that the order number doesn't get printed somewhere you don't want. The Gerber files have the requisite "JLCJLCJLCJLC" text on them and placed in an unobstrusive location.

Remove Order Number 

Four PEM KF2-M2-ET threaded inserts are pressed in and soldered into the holes on the daughterboard holder. Four M2x5 screws are then used to screw the daughterboard in, and the assembly is screwed into the case bottom using M3x5 screws. 

# Build instructions

[See here](https://github.com/bluepylons/Boston/blob/main/Boston%20-%20Current%20design/CNC%20version/Assembly-guide.md). The text is complete, though some photographes still need to be taken.

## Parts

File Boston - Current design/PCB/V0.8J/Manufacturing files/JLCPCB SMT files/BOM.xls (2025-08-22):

Comment | Designator | Footprint | LCSC Part Number | Type
10uF | C701, C704, C706, C710, C711, C713, C715, C716 | C1206 | C13585 (https://lcsc.com/product-detail/Multilayer-Ceramic-Capacitors-MLCC-SMD-SMT_SAMSUNG_CL31A106KBHNNNE_10uF-106-10-50V_C13585.html) | Basic
100nF | C702, C703, C705, C707,C708,C709, C712 | C0805 | C49678 (https://lcsc.com/product-detail/Multilayer-Ceramic-Capacitors-MLCC-SMD-SMT_100nF-104-10-50V_C49678.html) | Basic
4.7nF | C714 | C0805 | C1744 (https://lcsc.com/product-detail/Multilayer-Ceramic-Capacitors-MLCC-SMD-SMT_FH-Guangdong-Fenghua-Advanced-Tech-0805B472K500NT_C1744.html) | Basic
1N4148W | D1,D2,D3,D4,D5,D6,D7,D8,D9,D10,D11,D12,D13,D14,D15,D16,D17,D18,D19,D20,D21,D22,D23,D24,D25,D26,D27,D28,D29,D30,D31,D32,D33,D34,D35,D36,D37,D38,D39,D40,D41,D42,D43,D44,D45,D46,D47,D48,D49,D50,D51,D52,D53,D54,D55,D56,D57,D58,D59,D60,D61,D62,D63,D64,D65,D66,D67,D68,D69,D70,D71,D72,D73,D74,D75,D76,D77,D78,D79,D80,D81,D82,D83,D84,D85,D86,D87,D88,D89,D90,D91,D92,D93,D94,D95,D96,D97,D98,D99,D100,D101,D102,D103,D104,D105,D106,D107,D108,D109,D110,D111,D112,D113,D114,D115,D116,D117,D118,D119,D120,D121,D122,D123,D124,D125,D126,D127,D128,D129,D703 | SOD-123 | C81598 | Basic
RB060MM-60TR | D701 | SOD-123 | RB060MM-60TR | Extended
SM4007PL | D702 | SOD-123FL | C64898 | Basic
1812L075PR | F701 | 1812 | C142689 | Extended
TYPE-C-31-M-12 | J705 | TYPE-C-31_L8.94_W7.3 | C165948 | Extended
100 ohm @ 100MHz | L701,L702 | 0805 | C1015 | Basic
DTC123JKAT146 | Q701 | SOT23-3 | C111724 | Extended
DMN3030LSS-13 | Q702 | SOIC-8 | C177032 | Extended
1K | R1,R2,R3,R4,R6,R7,R8,R9,R10,R11,R12,R13,R14,R15,R16,R17,R18,R19,R20,R21,R22,R23,R24,R25,R26,R27,R28,R29,R30,R31,R32,R33,R34,R35,R36,R37,R38,R39,R40,R41,R42,R43,R44,R45,R46,R47,R48,R49,R50,R51,R52,R53,R54,R55,R56,R57,R58,R59,R60,R61,R62,R63,R64,R65,R66,R67,R68,R69,R70,R71,R72,R73,R74,R75,R76,R77,R78,R79,R80,R81,R82,R83,R84,R85,R86,R87,R89,R91,R92,R93,R94,R95,R96,R97,R98,R99,R100,R101,R102,R103,R104,R106,R107,R108,R109,R110,R111,R112,R113,R114,R115,R116,R117,R118,R119,R120,R121,R122,R123,R125,R127,R128,R129,R501,R502,R706,R881,R882,R901,R902,R1051,R1052,R1241,R1242 | 0805 | C17513 | Basic
100k | R701 | 0603 | C25803 | Basic
1M | R702 | 0805 | C17514 | Basic
5.1K | R704, R705 | 0805 | C27834 (https://lcsc.com/product-detail/Chip-Resistor-Surface-Mount_UNI-ROYAL-Uniroyal-Elec-0805W8F5101T5E_C27834.html) | Basic
100 | R703, R710 | 0805 | C17408 | Basic
10K | R707, R708, R709 | 0805 | C17414 | Basic
330K | R711 | 0805 | C17629 | Basic
STM32F072CBT6 | U701 | LQFP-48 | C81720 | Extended
AZ1117IH-3.3TRG1 | U702 | SOT-223 | C108495 | Extended
SRV05-4-P-T7 | U703 | SOT-23-6L | C85364 | Extended
SN74LVC1T45DBVR | U705 | SOT23-6 | C7843 | Extended

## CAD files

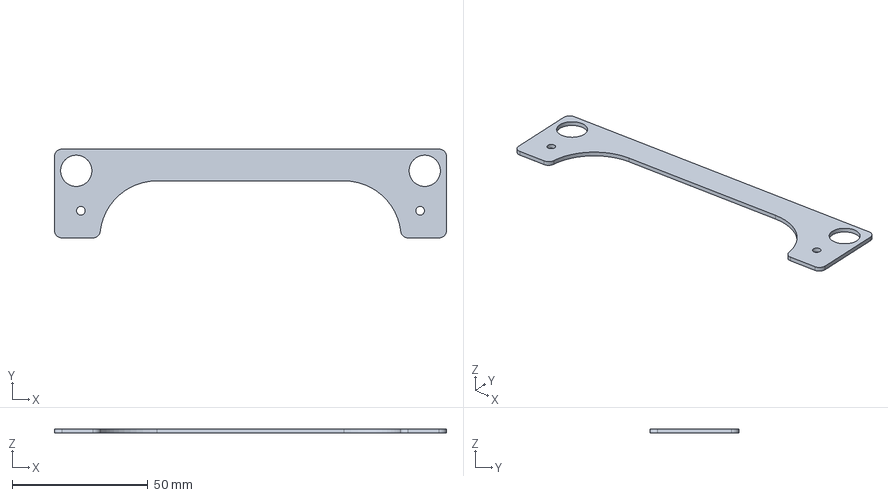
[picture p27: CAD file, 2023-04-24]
Boston - Current design/3D printed version/Bumpon holders/bumpon-holders.step
144.3 x 32.7 x 1.60 mm

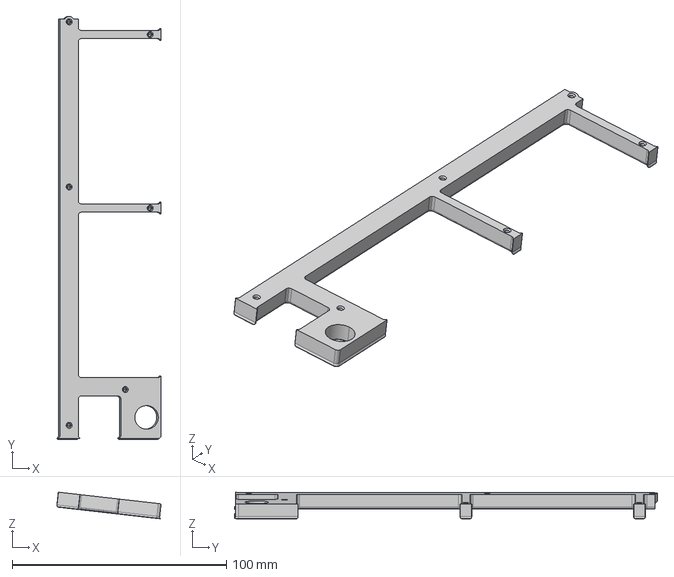
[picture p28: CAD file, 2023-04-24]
Boston - Current design/3D printed version/Left-key-separator-no-RGBLED.stp
48.7 x 197.3 x 12.5 mm

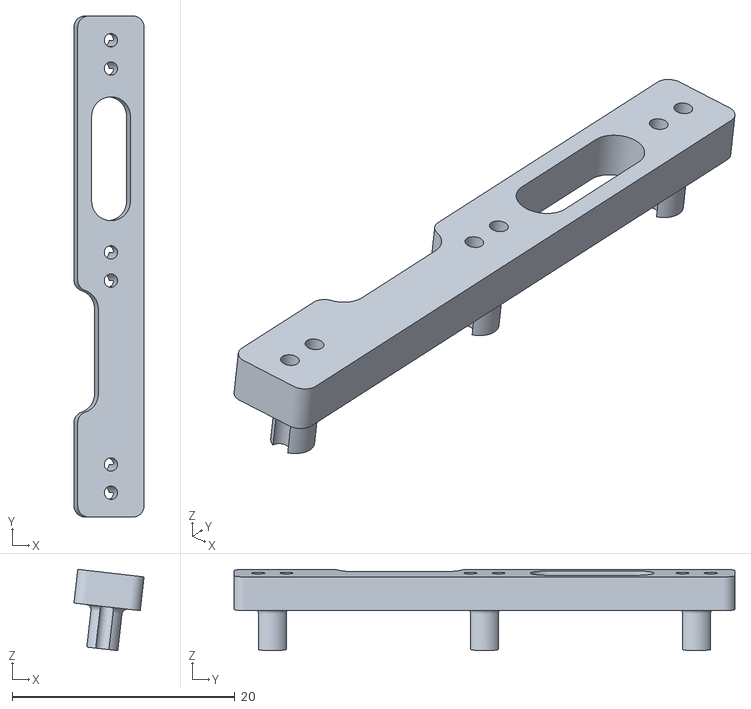
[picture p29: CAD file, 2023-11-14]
Boston - Current design/3D printed version/STLs/3mm-LED-spacer-stronger.STL
6.31 x 45.0 x 7.30

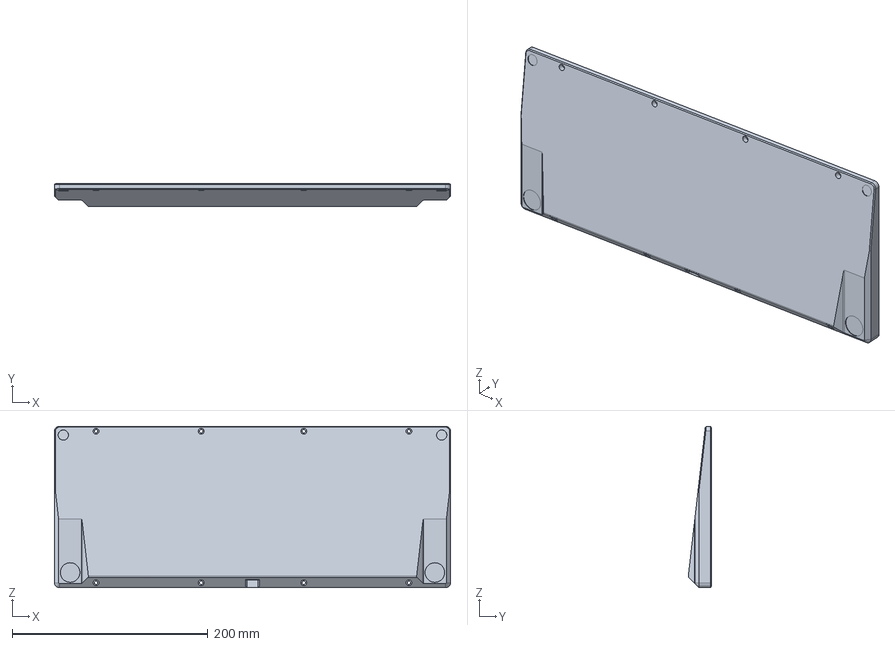
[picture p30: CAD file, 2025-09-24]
Boston - Current design/CNC version/Case/STEP/Boston-bottom-S1-UDB.stp
405.0 x 24.0 x 165.0 mm

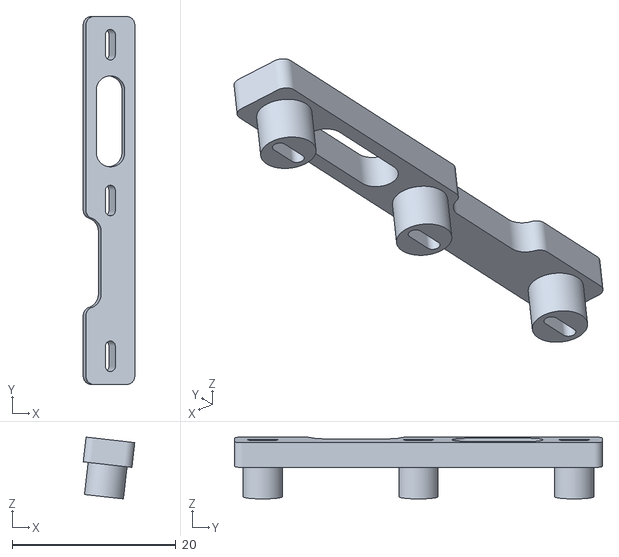
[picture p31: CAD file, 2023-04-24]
Boston - Current design/CNC version/Case/STL (3D print)/LED-spacer.stl
6.31 x 45.0 x 7.57

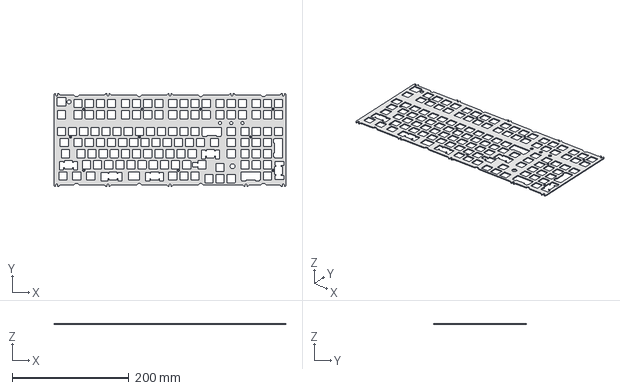
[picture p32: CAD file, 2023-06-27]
Boston - Current design/CNC version/Plate/Hotswap-ANSI/Hotswap-ANSI-plate-countersunk.stp
397.0 x 159.9 x 1.60 mm

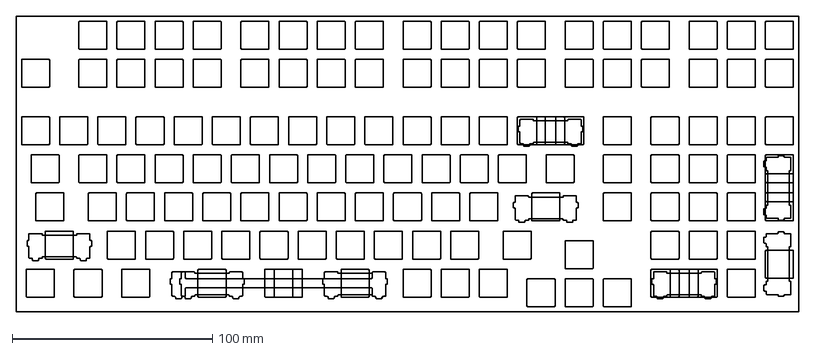
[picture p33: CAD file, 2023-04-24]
Boston - Current design/CNC version/Plate/Hotswap-ISO/KiCAD files/ai03-plategen-file.dxf
390.5 x 147.6 mm

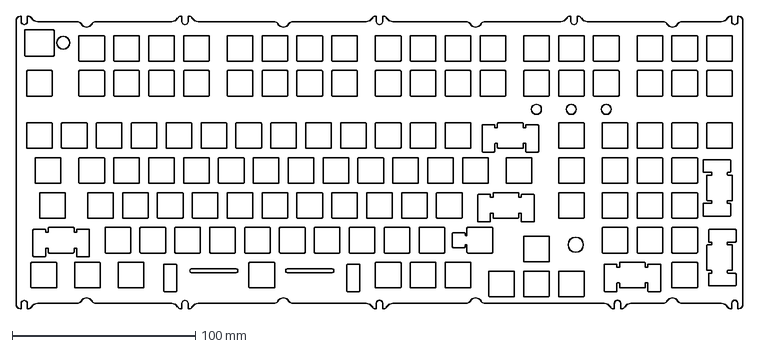
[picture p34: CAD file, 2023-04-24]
Boston - Current design/CNC version/Plate/Soldered-ANSI-fixed-layout/Boston-CNC-soldered-ANSI-plate.dxf
397.0 x 160.0 mm

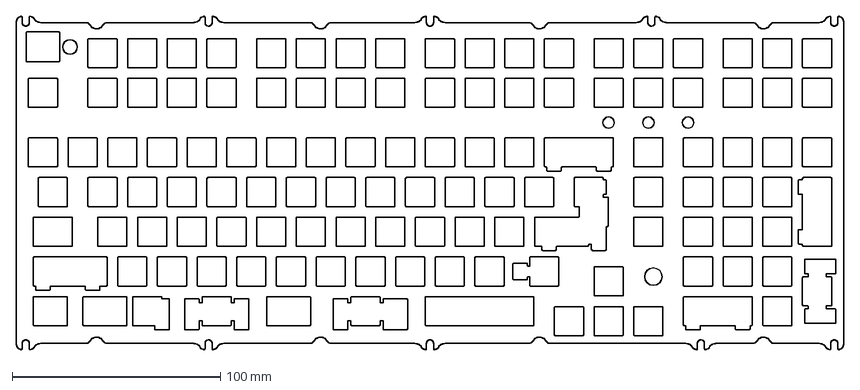
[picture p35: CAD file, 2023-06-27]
Boston - Current design/CNC version/Plate/Soldered-universal/Boston-CNC-soldered-universal-plate.dxf
397.0 x 159.9 mm

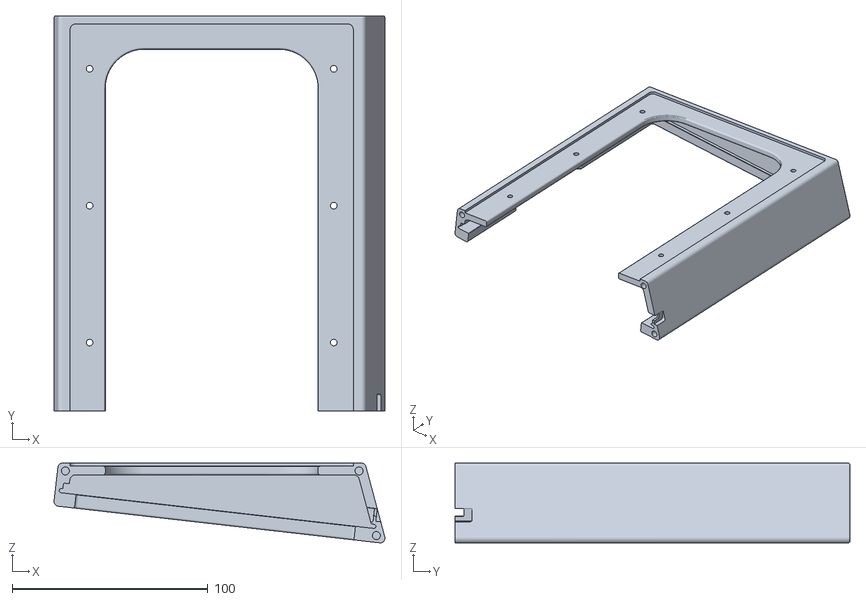
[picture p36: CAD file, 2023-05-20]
Boston - Current design/3D printed version/STLs/Right-half-no-reset-button-hole.stl
169.3 x 202.0 x 40.8

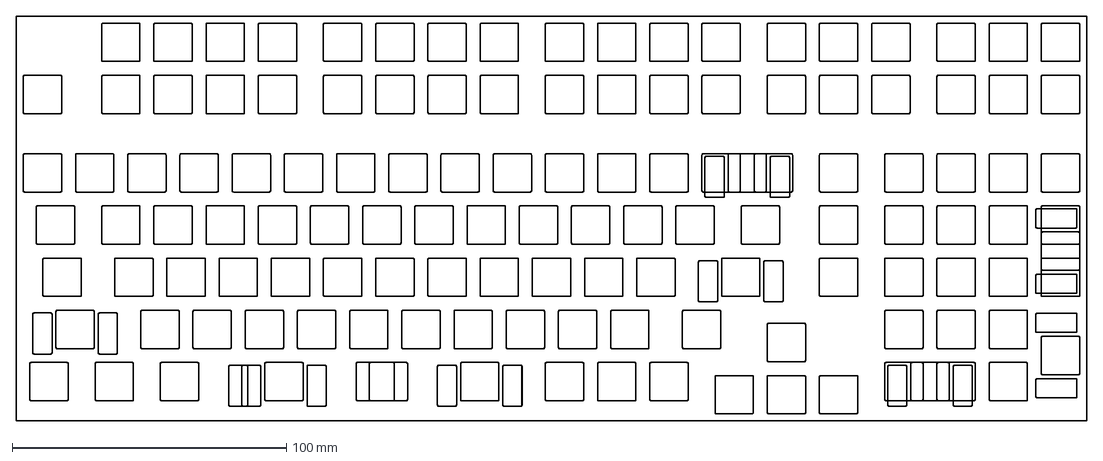
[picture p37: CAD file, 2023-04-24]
Boston - Current design/CNC version/Plate/Hotswap-ISO/KiCAD files/ai03-plategen-file-basic-stab-cutouts.dxf
390.5 x 147.6 mm

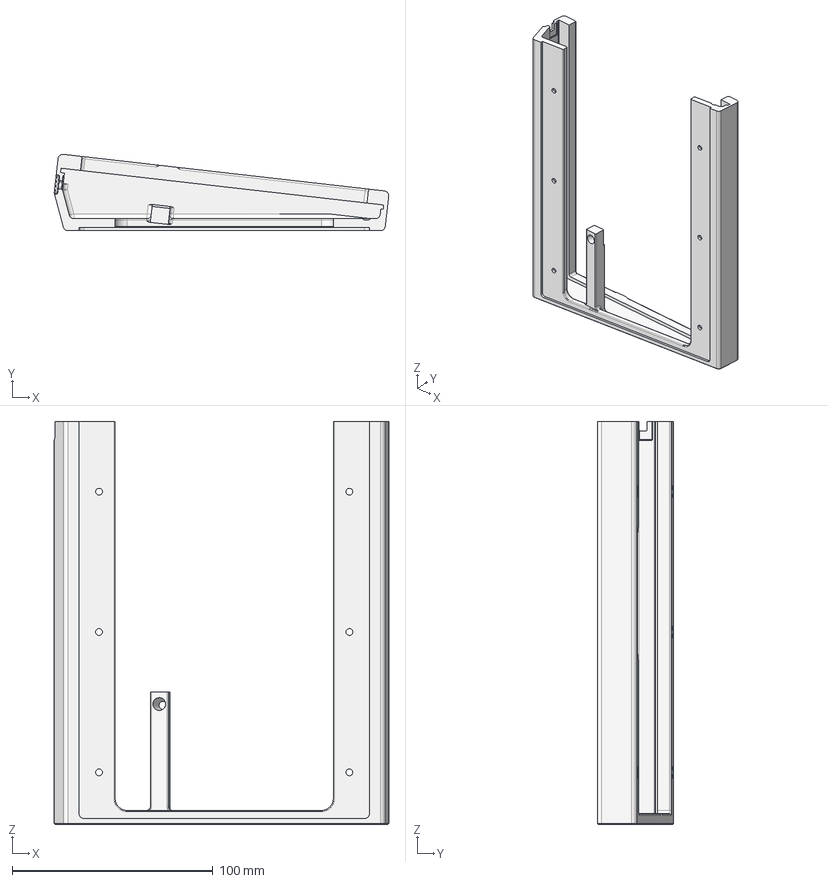
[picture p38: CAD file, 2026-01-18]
Experimental designs/Lower profile 3DP/Lower-profile-right-half-with-reset-hole.stp
166.9 x 38.1 x 201.0 mm

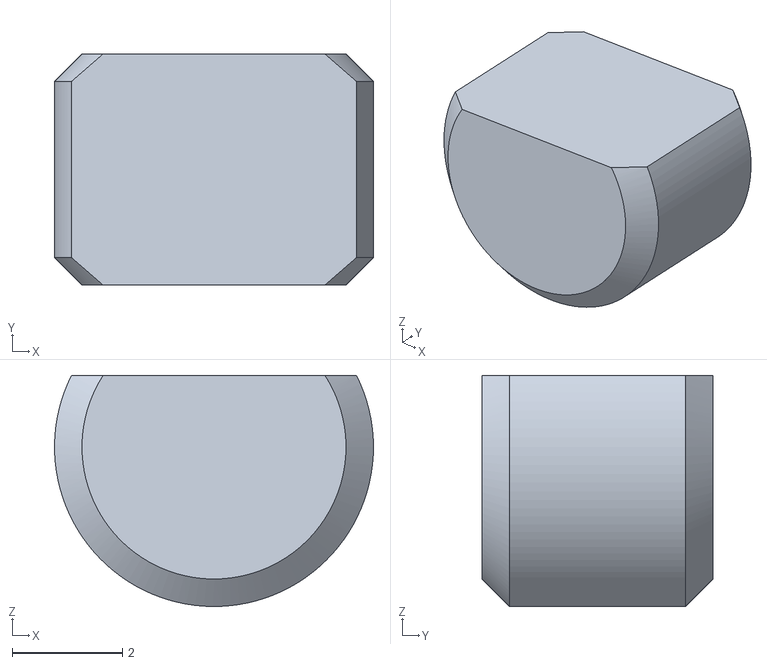
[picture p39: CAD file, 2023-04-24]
Boston - Current design/3D printed version/STLs/Kilo-OEDNI-75-knob-spacer.stl
5.80 x 4.20 x 4.20

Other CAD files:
Boston - Current design/CNC version/Plate/Hotswap-ISO/Hotswap-ANSI-plate.stp
Experimental designs/Lower profile 3DP/Left-key-separator-revised-with-RGBLED.stp
Boston - Current design/CNC version/Case/STEP/Boston-bottom-C3-DB-alternate (sharp edges).stp
Boston - Current design/CNC version/Plate/Hotswap-ANSI/Hotswap-ANSI-plate.stp
Boston - Current design/CNC version/Plate/Hotswap-ISO/Hotswap-ANSI-plate-countersunk.stp
Boston - Current design/3D printed version/Bottom (with reset hole - for V07J and older)/Fusion-STEP-export.step
Boston - Current design/3D printed version/Bottom (with reset hole - for V07J and older)/KiCAD files/bottom.step
Boston - Current design/3D printed version/Bottom (with reset hole - for V07J and older)/bottom.dxf
Boston - Current design/3D printed version/Bumpon holders/bumpon-holders.dxf
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

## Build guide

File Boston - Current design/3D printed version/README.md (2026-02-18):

# 3D printed version

These are the files for the 3D printed version. 

3D-printed, white
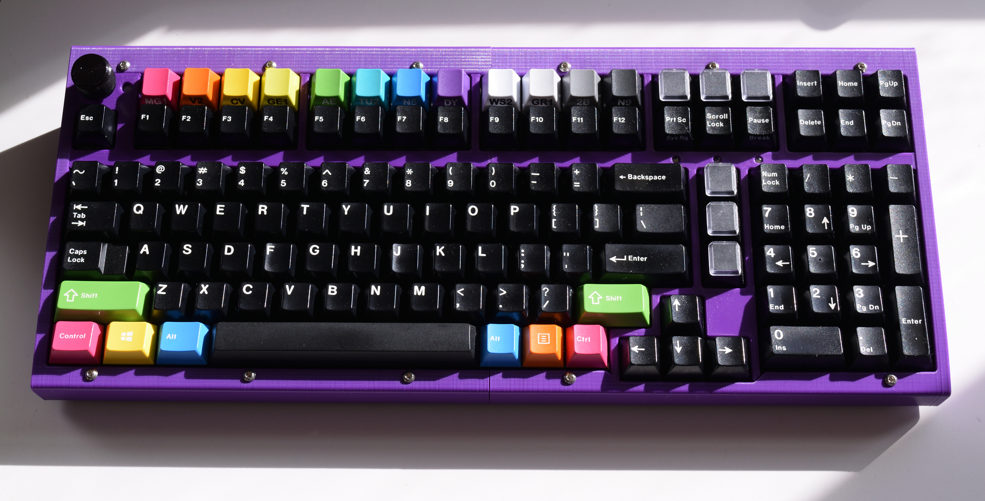
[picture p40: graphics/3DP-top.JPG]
3D-printed,purple

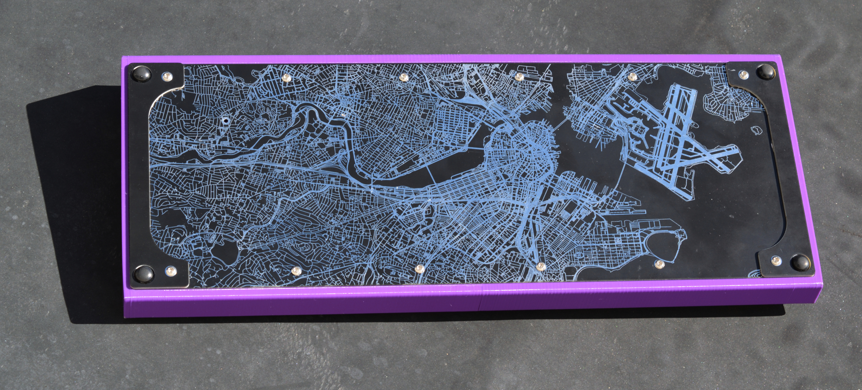
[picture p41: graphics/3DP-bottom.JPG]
3D-printed,purple,bottom


The master CAD assembly is Boston-3D-printed-case.stp. The case was done with a mix of Fusion 360 and later Atom3D (after I decided to stop paying for Fusion) - due to the mix of CAD programs used the master file is actually not particularly editable, so I decided to just provide it as a STEP file that can be opened in any CAD program.

If you have access to a large printer (capable of 405mm on one axis), Technofrikus designed an alternative 3D-printed case using the CNC version files. A 4° option is available for that case. The files for that version are [available on Technofrikus' GitHub repo here](https://github.com/Technofrikus/Boston-Case/blob/main/Photos/DSCF7709%201.jpg?raw=true).

# Ordering guide - (draft)

This is how to order the parts to make a 3D-printed Boston.

**Order parts at your own risk. These files are provided as-is, and I am not responsible for any losses, harm, or damage incurred by following this guide, by ordering parts, by using the files provided, by using the resultant parts or assembled keyboard, or from any mistakes or errors in the files, ordering guide, or resultant parts** 

** This is for the older PCB V0.7 and older designs; the newer V0.8 PCBs (which include hotswap variants) are currently being tested but are not included in this guide, and the V0.8 line use slightly different plates and bottom panels (as they move their reset button to the top side of the PCB). This guide will eventually be updated for those designs once those designs are verified.**

You will need the following:

## What You Will Need (summary):
| Description | Qty per board | Type |
| --- | --- | --- |
| Case Left Half | 1 | Custom (3D Printed) |
| Case Right Half | 1 | Custom (3D Printed) |
| Left Key Separator | 1 | Custom (3D Printed) |
| Right Key Separator | 1 | Custom (3D Printed) |
| 3mm LED spacer (for lock LEDs) | 1 | Custom (3D Printed) |
| (optional) RGB LED spacer (for lock LEDs) | 1 | Custom (3D Printed) |
| (optional) Knob Spacer | 1 | Custom (3D Printed) |
| PCB | 1 | Custom (PCB) |
| FR4 Plate | 1 | Custom (PCB) |
| FR4 Bottom Panel | 1 | Custom (PCB) |
| FR4 rubber feet holders | 2 | Custom (PCB) |
| (optional) APA106 RGBLED | 1 | Off-the-shelf |
| Reset Switch (6x6mm 5mm tall tact switch) | 1 | Off-the-shelf |
| 3mm LED for lock LEDs | 3 | Off-the-shelf |
| 1KΩ through-hole resistor for lock LEDs | 3 | Off-the-shelf |
| Alps EC11E18244A5 encoder | 1 | Off-the-shelf |
| M3x0.5 6mm long button head screw | 8 | Off-the-shelf |
| M3x0.5 10mm long button head screw | 15 | Off-the-shelf |
| M3x0.5 hex nut | 12 | Off-the-shelf | 
| M2 5mm long self-tapping screw | 14 | Off-the-shelf |
| PEM KF2-M3-ET threaded insert | 11 | Off-the-shelf |
| 3/8" diameter rubber feet | 4 | Off-the-shelf | 
| Knob that fits a 6mm D-shaft | 1 | Off-the-shelf |
| Mill-Max 821-22-002-10-000101 "pogo pins" (or a short piece of wire) | 1 | Off-the-shelf |

| Description | Qty per board | 
| --- | --- |
| MX-style switches | 119-127 (depending on layout) |  
| Stabilizers (PCB mount) | 2-8 2u, 0-1 6.25u or 7u (depending on layout) |

# PCB

PCB V0.7J top
PCB V0.7J bottom

For the PCB - you can order an assembled PCB with the surface mount parts soldered on (minus through-hole parts such as the encoder, RGBLED, and reset switch) from a PCB fab such as JLCPCB or Elecrow.

## How to order on JLCPCB

JLCPCB is cheap and fast, but doesn't have the best cosmetic finish, and their SMT assembly is limited to parts [they stock](https://jlcpcb.com/parts). In the community they tend to only be used for prototypes.

To order a PCB from JLCPCB, you will need the Gerber files (which defines the bare PCB), the PCB assembly bill of materials (BOM file, which is a list of parts that are to be soldered to the PCB), and the component placement file (CPL, which defines where those parts go). The files for PCB revision V0.7J are available [here](https://github.com/bluepylons/Boston/tree/main/Boston%20-%20Current%20design/PCB/V0.7J/Manufacturing%20files). **Order at your own risk. V0.7J has been prototyped and is used in RNDKBD's Round 2 group buy, though the backlight LEDs on V0.7J have not been tested**

First, you want to go to [JLCPCB](https://jlcpcb.com/), and press "Order Now".

Step 1

Next, you want to upload the Gerber file for the PCB. You may need to manually input the PCB dimensions (394x154mm). 

Step 2

Here, you want to change the specifications to the following. PCB Color and Surface Finish needs to be a combo supported for Economic PCB Assembly in 1.6mm thickness - currently (April 30, 2023), this would be Green in any finish, Black in any finish except ENIG, and Blue, Red, and White with HASL-Leaded. 

Step 3

Next, you want to scroll down and turn on PCB Assembly. Make sure the following options are selected:

Step 4

Press Confirm. Next, you want to upload the BOM and CPL files. 

Step 5

Make sure that all the components are selected. Any part that says "Inventory shortage" will not be installed, and you will have to substitute a compatible part, wait for the part to come back in stock, or if you're up to the challenge of SMT soldering, order the part separately and solder it on yourself. 

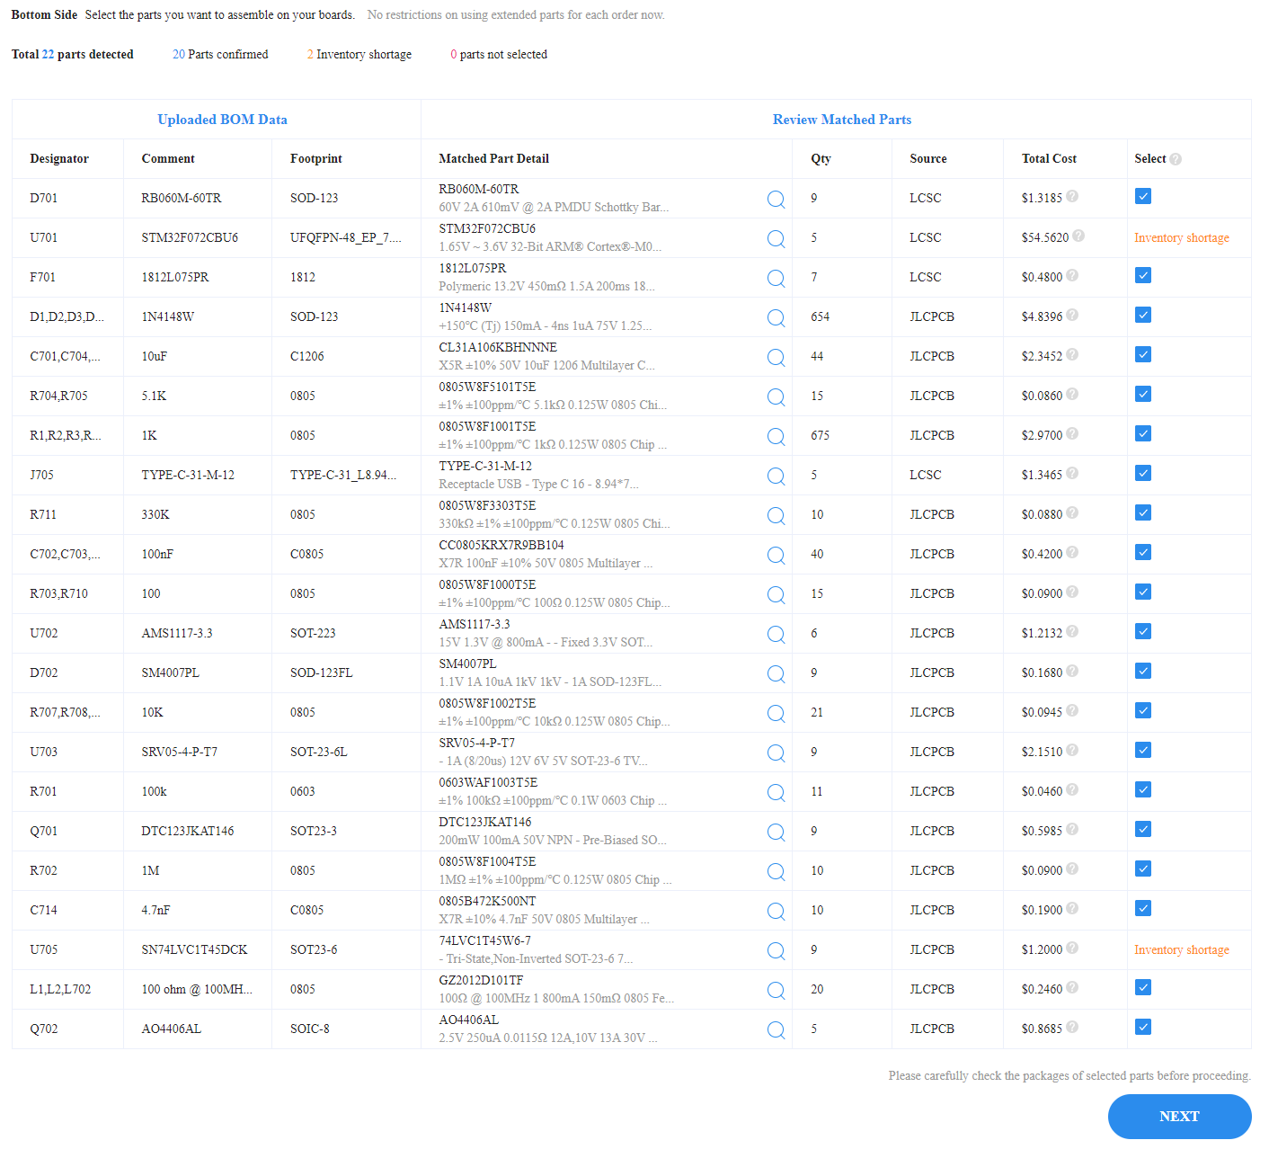
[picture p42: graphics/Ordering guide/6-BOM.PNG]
Step 6


The next page is a confirmation page. Note that the parts placement preview may be inaccurate (JLCPCB engineers will look over this and make any parts orientation corrections, so don't worry too much about this). 

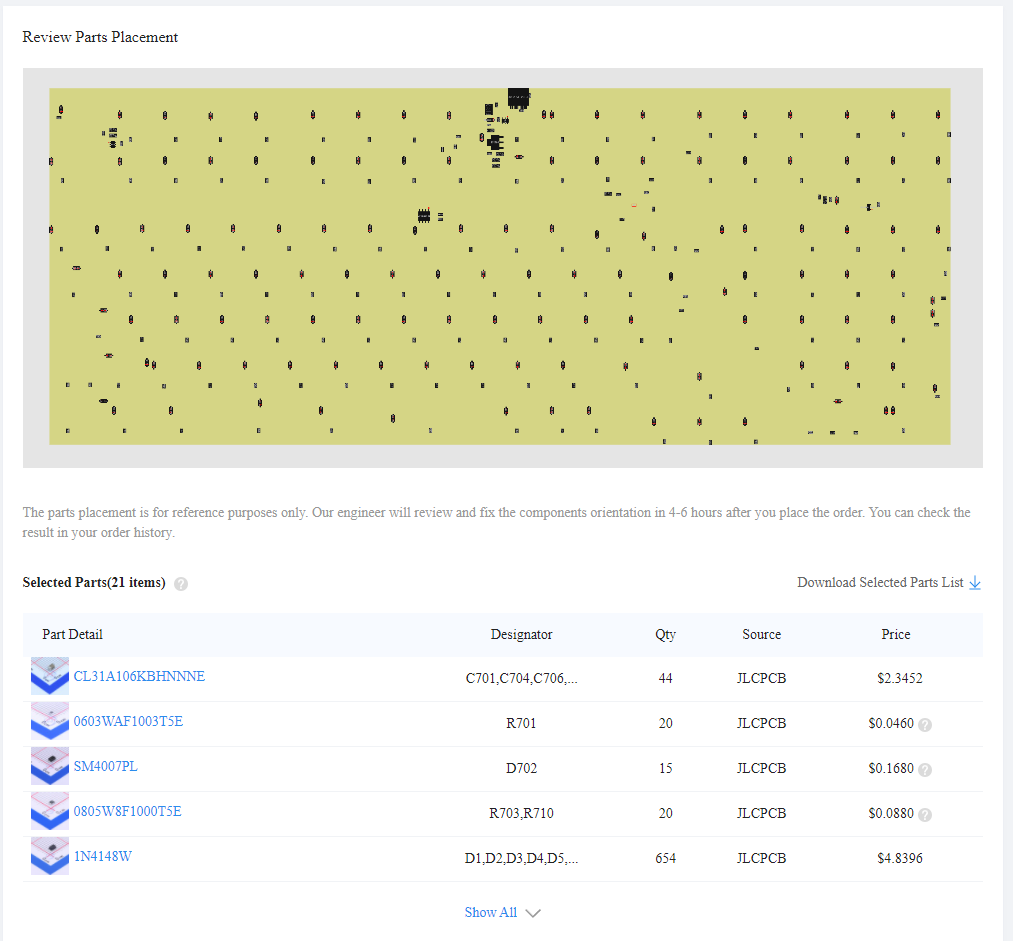
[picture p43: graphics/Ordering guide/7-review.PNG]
Step 7


As the microcontroller is frequently out of stock due to the chip shortage, line number 20 (for designator U701) can be changed for different compatible MCUs (see the "Compatible MCUs" section below for a list of MCUs that will work). You will name to change the Comment field for that line to the name of the microcontroller you want to use, and change the Footprint and LCSC Part Number as appropriate.

## How to order on Elecrow
Elecrow is a full-service PCB assembly shop, and one of the go-tos in the community for custom keyboard PCBs for the actual group buy sales. They can install any part (not just ones they stock) and generally have better quality surface finish, but is much slower (typically 3-4 week turn around time), and costs more (especially in small quantities). 

To order from Elecrow, you will need to email service@elecrow.com with the [Gerber](https://github.com/bluepylons/Boston/blob/main/Boston%20-%20Current%20design/PCB/V0.7J/Manufacturing%20files/Gerbers-Boston-V07J.zip) and [SMT](https://github.com/bluepylons/Boston/blob/main/Boston%20-%20Current%20design/PCB/V0.7J/Manufacturing%20files/Elecrow%20SMT%20files/BostonV07J-Elecrow-files.xlsx) files and request a quote.

On the [SMT file](https://github.com/bluepylons/Boston/blob/main/Boston%20-%20Current%20design/PCB/V0.7J/Manufacturing%20files/Elecrow%20SMT%20files/BostonV07J-Elecrow-files.xlsx), you will need to edit the first tab to specify your quantity, color, and surface finish. Elecrow's available colors and surface finishes are posted on their [PCB ordering page](https://www.elecrow.com/pcb-manufacturing.html)

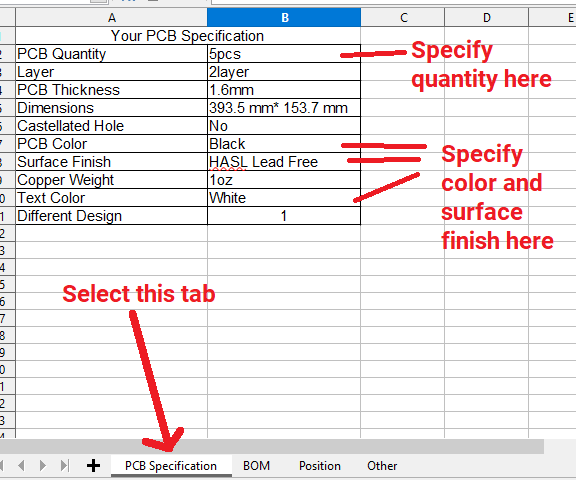
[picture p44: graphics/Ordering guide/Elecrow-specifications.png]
Elecrow


Note - the provided Elecrow SMT files includes having them solder on the RGBLED (LED702), but without the spacer, so it will sit about 2mm lower. 

## Compatible MCUs 

Boston uses a 128kb STM32F072CB-series microcontroller, and can accept either the LQFP-48 (STM32F072CxTx) or 48-UFQFPN (STM32F072CxUx ) versions.

Any of the following microcontrollers will work, and support all features. 

**Compatible MCUs**
| Microcontroller | JLCPCB (LCSC) part number |
| --- | --- |
| STM32F072CBU6 | C92504 |
| STM32F072CBU7 | Not on JLCPCB |
| STM32F072CBU6TR | C2054107 |
| STM32F072CBU7TR | Not on JLCPCB |
| STM32F072CBT6 | C81720 |
| STM32F072CBT6TR | Not on JLCPCB |
| STM32F072CBT7 | C472592 |
| STM32F072CBU7TR | Not on JLCPCB |

The 64kb versions of the STM32F072 likely work (but has not been tested), but will only able to run base QMK. These do not support Vial (or VIA if VIA support is ever added in the future) as they do not have enough flash to support dynamic keymaps, so are not recommended. 

**Likely compatible, but won't support Vial - not recommended**
| Microcontroller | JLCPCB (LCSC) part number |
| --- | --- |
| STM32F072C8U6 | C784818 |
| STM32F072C8U7 | Not on JLCPCB |
| STM32F072C8U6TR | Not on JLCPCB |
| STM32F072C8U7TR | Not on JLCPCB |
| STM32F072C8T6 | C80488 |
| STM32F072C8T6TR | Not on JLCPCB |
| STM32F072C8T7 | Not on JLCPCB |
| STM32F072C8U7TR | Not on JLCPCB |

Other versions of the STM32F072 (which have different footprints or pin counts), or other STM32 microcontrollers will not work. 

## Other Interchangeable PCB Parts

This is here for reference in case some parts are out of stock.

**U702 - BOM Line #21**
This is a SOT-223 linear regulator to drop the 5V down to 3.3V.

EDIT November 9 2021 - changed the default to TI TLV1117LV33DCYR - the other LDOs that fit may not be stable with the current output capacitor setup, as the ESR of the 3 ceramic capacitors used right now are potentially too low for stability. This may result in poor regulation or oscillations and potentially expose the MCU to voltages above its maximum rating. 

| Part | JLCPCB (LCSC) part number |
| --- | --- |
| TI TLV1117LV33DCYR (default) | C15578 |
| Diodes Inc AZ1117IH-3.3TRG1 | C108495 |
| ~~Advanced Monolithic Systems AMS1117-3.3 (Default)~~ | ~~C6186~~ |
| ~~TI TLV1117-33CDCYR~~ | ~~C91728~~ |

**U705 - BOM Line #23**
This is a 74LVC1T45 level shifter in an SOT23-6 (SOT26) package. 

| Part | JLCPCB (LCSC) part number |
| --- | --- |
| TI SN74LVC1T45DBVR (Default)  | C7843 |
| TI SN74LVC1T45DBVT | C116653 |
| Diodes Inc 74LVC1T45W6-7 | C168856 |

## Other PCB components (through-hole)

These parts are through-hole, and will need to be added once the PCB is received.

### RGBLED (LED702) (optional)

The RGBLED is currently used to indicate the active layer in QMK, though is probably otherwise underutilized. If you do not wish to include it (as it is tricky to solder in), you can exclude it, and use the no-RGBLED version of the left key separator, which does not have the hole for the RGBLED.

The RGBLED indicator uses an APA106-F5 through-hole RGBLED. This is resold by Sparkfun (P/N [COM-12986](https://www.sparkfun.com/products/12986)) and Adafruit ( [P/N 1938](https://www.adafruit.com/product/1938))

Note that Worldsemi WS2812D-F5 does not work as the pinout is different. 

This should be soldered with the 3D-printed [RGBLED spacer](https://github.com/bluepylons/Boston/blob/main/Boston%20-%20Current%20design/3D%20printed%20version/STLs/RGB-LED-spacer.stl) in between the bottom of the LED and the PCB. You can solder it straight to the board without the spacer, but the LED will sit very, very low.

Remember to orient this correctly when soldering it to the PCB - it will not work if soldered backwards. The flat side of the LED should match with the "flat side" printed on the PCB.

Despite being through-hole, this is also a bit tricky to solder as the pins are quite close and easily bridged. You definitely want to flux the LED pins when soldering this. Also keep desoldering wick handy while soldering this to remove any bridges. Be careful with the heat, as you can melt the 3D-printed spacer. 

### Reset switch 
The reset switch uses a 5mm tall 6x6mm SPST NO through-hole tact switch. This is a generic part widely available from several vendors - I have used Wealth Metal [TC-0103](https://www.taydaelectronics.com/tact-switch-6x6mm-5mm-through-hole-spst-no.html), but TE 1825910-6, E-switch TL1105AF100Q, Omron B3F-1022, C&K PTS645SK50-2 LFS and numerous other parts should work (though it has not been tested). 

On PCB V0.7J and older this is soldered on the bottom. For PCB V0.8 and newer, when used with a plate with a cutout next to right shift, it is soldered on the top. 

### Encoder
The encoder used is Alps EC11E18244A5, the same one used on the Satisfaction75. Other EC11-style encoders may work, but may need changes to various QMK parameters (ENCODER_RESOLUTION in config.h, and possibly reversing ENCODERS_PAD_A and ENCODERS_PAD_B) to work correctly.

### Lock LEDs and resistors
Most standard 3mm LEDs should work, and are available in several different colors. A 1KΩ resistor is a pretty safe resistor size for the LEDs, but depending on the LED forward voltage, current draw, and desired brightness, you may want to adjust this up or down. Standard 1/4W resistors are suitable.

The LEDs need to be soldered through the [3D-printed 3mm LED spacer](https://github.com/bluepylons/Boston/blob/main/Boston%20-%20Current%20design/3D%20printed%20version/STLs/3mm-LED-spacer.stl) - this is described in the assembly instructions. 

### Pogo pins for grounding
On PCB version V0.7J, there is a spot provided on the very right side of the PCB (footprint J707) to solder a pair of spring-loaded pogo pins to electrically ground the plate and the screws on the top of the case. This is to prevent static electricity from resetting the microcontroller. The pogo-pins used are Mill-Max 821-22-002-10-000101, available off [Mouser](https://www.mouser.com/ProductDetail/Mill-Max/821-22-002-10-000101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), [Digi-key](https://www.digikey.com/en/products/detail/mill-max-manufacturing-corp/821-22-002-10-000101/1146517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), and other sources. Other 2-position 2.54mm pitch pogo pins that can support a 3.5mm board-to-board distance can potentially also work.

Alternatively, you can solder a small piece of wire between either of the through-holes on J707 and the corresponding exposed pad on the plate right above it.

# Other FR4 parts
All FR4 parts can be ordered as a bare PCB from a PCB fab such as JLCPCB, Elecrow, or PCBWay, using the Gerber files. A lead-free finish (such as HASL Lead Free or ENIG) is strongly recommended, especially on the bottom panel.

All FR4 parts are 1.6mm thick. 

Note - on JLCPCB, make sure that "Specify A Location" for "Remove Order number" is selected so that the order number doesn't get printed somewhere you don't want. The Gerber files have the requisite "JLCJLCJLCJLC" text on them and placed in an unobstrusive location.

Remove Order Number 

 Also, "Paper between PCBs" under "Advanced Options" is strongly recommended- otherwise there's a decent risk of FR4 parts showing up scratched. 
 
Paper Between PCBs

## Plate
The universal plate Gerber files are available [here](https://github.com/bluepylons/Boston/blob/main/Boston%20-%20Current%20design/3D%20printed%20version/Plate/Plate-soldered-universal-3DP/Manufacturing%20files/Gerbers-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).

Note that JLCPCB will usually charge an extra fee on plates - in the past it has been about $15 additional fee for 5 plates, but may have increased. This extra fee will be requested after you have submitted the order, and you will need to pay it for them to actually manufacture your order. 

## Bottom Panel
The bottom panel Gerber files are available [here](https://github.com/bluepylons/Boston/blob/main/Boston%20-%20Current%20design/3D%20printed%20version/Bottom%20(with%20reset%20hole%20-%20for%20V07J%20and%20older)/KiC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). 

Definitely use a lead-free finish on this, as you will be touching this when carrying the board. All past bottoms have used HASL-Lead-Free for the finish, but there have been occasional quality issues (e.g. small features on the map were not covered in solder, and were bare copper). ENIG will probably work better, but is more expensive, and will be gold-colored instead of silver. 

## Bumpon holders

You need 2 of these per board - they help keep the bumpons in place. 

The bumpon holder Gerber files are available [here](https://github.com/bluepylons/Boston/tree/main/Boston%20-%20Current%20design/3D%20printed%20version/Bumpon%20holders/Manufacturing%20files)

# Mechanical Hardware

These are the fasteners and other hardware you will need. Part numbers from [McMaster-Carr](https://www.mcmaster.com/) are provided. I'm not sure if they ship outside the US, so you may need to figure out how to source the parts locally if you are not in the US.

| Description | Qty needed per board | McMaster-Carr P/N | Notes | 
| --- | --- | --- | --- |
| M3x0.5, 6mm long ISO 7380 button head screw, stainless steel, Torx T10 head | 8 | 90991A112 | Hex-head would also work, but Torx strips less easily |
| M3x0.5, 10mm long ISO 7380 button head screw, stainless steel, Torx T10 head | 15 | 90991A114 | Hex-head would also work, but Torx strips less easily |
| M3x0.5 DIN 934 hex nut, zinc plated | 12 | 90591A250 | Zinc instead of stainless, as stainless-on-stainless risks galling (cold welding) together and getting very,very stuck |
| M2 5mm long Delta PT ® Torx head thread forming screw | 14 | 96817A207 | Other M2 5mm-long self-tapping screws *might* work. There is also a stainless steel version of this screw – McMaster-Carr 96817A842 |
| PEM tin-plated press-fit threaded insert , M3x0.5. PEM P/N KF2-M3-ET | 11 | 95117A499 | Also available on [Mouser](https://www.mouser.com/ProductDetail/PEM/KF2-M3-ET?qs=l4Gc20tDgJKPX2YZdDO0uw%3D%3D) for significantly less |
| Rubber feet (3/8” diameter) – 3M Bumpon SJ5003 or equivalent | 4 | 95495K12 | | 

# Knobs
The Alps EC11E18244A5 encoder takes a 6mm knob with either a D-shaft or a set screw. This is a common size for guitars and audio equipment. 1/4" knobs can work but may be loose. 1/4" to 6mm adapters available from various sources if you want to use a 1/4" knob. 

The knob needs to be smaller than 23mm in diameter or it will hit the Esc key. 

I personally recommend Kilo International's OEDNI-75-X-7 lineup - these have very grippy knurling and can be easily rotated with one finger. They can be found on Digi-key, Newark, and other electronics parts vendors. If you use that knob, you want to 3D print a [small spacer](https://github.com/bluepylons/Boston/blob/main/Boston%20-%20Current%20design/3D%20printed%20version/STLs/Kilo-OEDNI-75-knob-spacer.stl) to place into the shaft hole on the knob, as otherwise the knob can sit too low and bump into the case. 

| Kilo P/N | Finish |
| --- | --- |
| OEDNI-75-1-7 | Silver, satin gloss |
| OEDNI-75-2-7 | Black, satin gloss  |
| OEDNI-75-3-7 | Silver, matte |
| OEDNI-75-4-7 | Black, matte |

# 3D printing
You will need to 3D-print the parts in [the STL folder](https://github.com/bluepylons/Boston/tree/main/Boston%20-%20Current%20design/3D%20printed%20version/STLs). (For the left key separator you need to print either the RGBLED or no RGBLED verison, depending on whether you soldered on the RGBLED on the PCB). More detailed instructions on 3D are available in the assembly instructions. The parts are designed to be FDM 3D printed, and can be printed without support material. 

You can outsource the 3D printing to a service like Shapeways, but if you're printing more than a single case this isn't econommical versus just buying a budget 3D printer - a cheap $250 Ender 3 Pro or a Biqu B1 will print the case just fine. Or if you don't want to deal with that, try finding a friend or acquaintance with a 3D printer. Many public libraries also now have 3D printers also that are available for use. 

# Assembly Instructions

Draft assembly instructions are [here](https://github.com/bluepylons/Boston/blob/main/Boston%20-%20Current%20design/3D%20printed%20version/Draft%20instructions%20(barebones%20kit).pdf)

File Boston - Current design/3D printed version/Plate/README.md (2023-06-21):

# Plate files for the 3D-printed version

These are the FR4 plate files.These can be manufactured at any PCB fab. 

Plate-hotswap-ANSI supports [these layouts](https://github.com/bluepylons/Boston/raw/main/graphics/boston-hotswap-ANSI-KLE.png) and is meant for use with the hotswap PCB (and includes holes for 3.5mm M2 standoffs such as [these](https://kbdfans.com/products/kbdfans-m2-3-countersunk-flat-head-screw-kit) between the plate and PCB to hold the PCB in place without any switches). The hotswap plate can also be used with the soldered PCB, except split space is not supported with the soldered PCB (as 2.75u and 2.25u split space are swapped between the hotswap and soldered versions as it was otherwise impossible to also support a standard 6.25u spacebar on the hotswap version without swapping the two).

Plate-soldered-universal-3DP supports [these layouts](https://github.com/bluepylons/Boston/raw/main/graphics/bostonKLE.png) and is meant for use with the soldered PCB. It supports every layout that the soldered PCB supports. You can also use it with the hotswap PCB, except you are relying on the switches in the sockets to hold the PCB, and also split space is not supported when using it with the hotswap PCB.

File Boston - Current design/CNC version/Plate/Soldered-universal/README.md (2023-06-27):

**Status** 

~~~* Gerber files: Prototyped and verified working (though not for all layouts)~~~ Fixed some sharp corners - this changed has not been prototyped or verified 
~~~* DXF files: Done and checked over, not yet prototyped~~~ Fixed some sharp corners - this changed has not been prototyped or verified 
~~~* STEP files: Done and checked over, not yet prototyped~~~ Fixed some sharp corners - this changed has not been prototyped or verified

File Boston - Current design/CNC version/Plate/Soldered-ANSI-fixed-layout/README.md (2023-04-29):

**Status** 

* Gerber files: Prototyped and verified working
* DXF files: Done and checked over, not yet prototyped
* STEP files: Done and checked over, not yet prototyped

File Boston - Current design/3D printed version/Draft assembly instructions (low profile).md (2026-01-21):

# Boston (3D-printed/FR4 version) Assembly Instructions, including 3D printing 

## Draft. Lot of images needed (January 21, 2026)

## To Do

* Instructions on how to solder per-key LEDs (soldered version only - the hotswap version does not have the per-key LEDs)

## Errata

* If you are using split 1u numpad + and =, the + and = are reversed in Vial, QMK, and in the key diagram. For now just assign the key you want to + to =, and vice versa.

# Table of Contents

* Before You Start
* What’s in the box:
* Part 1: 3D-printing the case parts
* Part 2: Putting Together The Plate and Key Separators
* Part 3: Soldering Additional Parts on the PCB
* Part 4: installing stabilizers and switches
* Part 5 - Case Prep and Assembly
* Part 6: Flashing Firmware
* Appendix:

# Before You Start 
* Boston is an open-source keyboard project. Follow these assembly instructions at your own risk. 
* Please read the entirety of this guide before you begin. The assembly process for the 3D-printed version of Boston is a bit atypical.
* The 3D printed key separators must be installed onto the plate before the switches are soldered on. If you have the plate and PCB but do not have the 3D printed parts yet - do not solder your switches on yet.  
* If you purchased a kit from a vendor, some of the steps may have already been done for you by the vendor. 
* Do not use strong chemicals such as acetone to wipe down any part of the case or PCB. This may cause damage. 
* The PCB has an ESD protection chip to provide some protection when it is fully assembled, but cannot protect the keyboard while you are building it. Please observe basic procedures to prevent damage from electrostatic discharge (ESD) while handling the PCB or assembling the keyboard.
    * Wear a properly-grounded ESD wrist strap while you are assembling the board.
    * Touch a grounded metal object before you begin handling the PCB to reduce risk of ESD damage, and touch a  grounded metal object regularly to discharge any ESD buildup. 
    * Avoid wearing clothing (e.g. wool sweaters, socks) that can cause ESD buildup
    * Avoid working on a carpeted surface. 
    * A guide on basic ESD procedures is available [here](https://www.wikihow.com/Ground-Yourself-to-Avoid-Destroying-a-Computer-with-Electrostatic-**Discharge**). 
* Soldering can be hazardous
  * Wear safety glasses while soldering! Hot droplets of flux may fly towards you while you are soldering.
  * The hot tip of a soldering iron can cause serious burns.
  * Use a fume extractor while soldering, or solder in a well-ventilated space. Flux fumes can be hazardous and can cause long-term lung issues. 
* Do not overtighten the screws! This can strip the head or the threads and cause other damage.
  
# What You Should Have:
* The PCB:
[image needed of PCB]
* The FR4 fiberglass plate: 
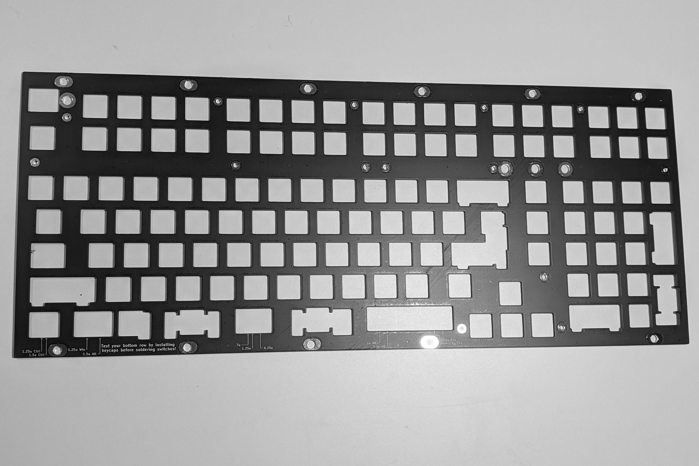
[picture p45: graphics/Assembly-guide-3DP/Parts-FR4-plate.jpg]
FR4 fiberglass plate

* The FR4 bottom panel:
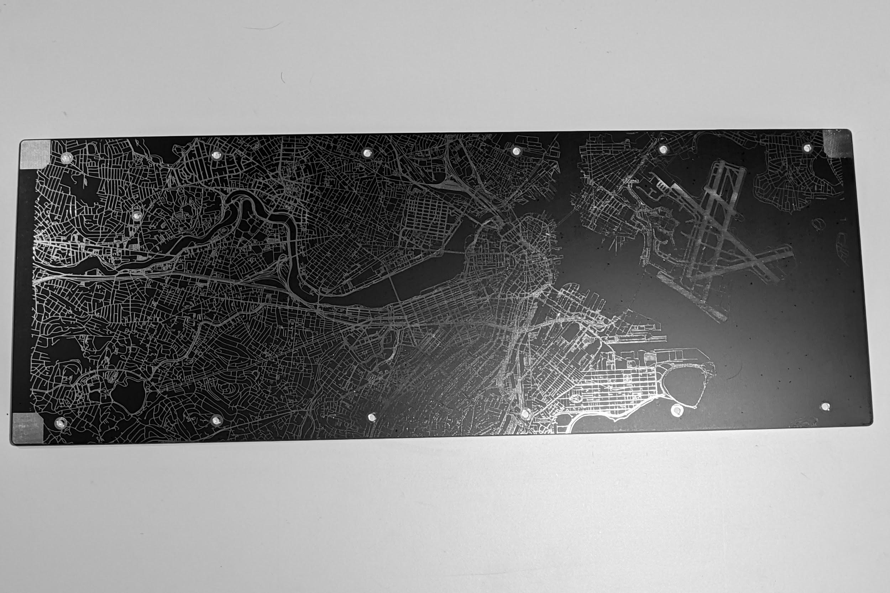
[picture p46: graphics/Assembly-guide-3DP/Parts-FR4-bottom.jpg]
FR4 bottom panel

* 3x 3mm LEDs:
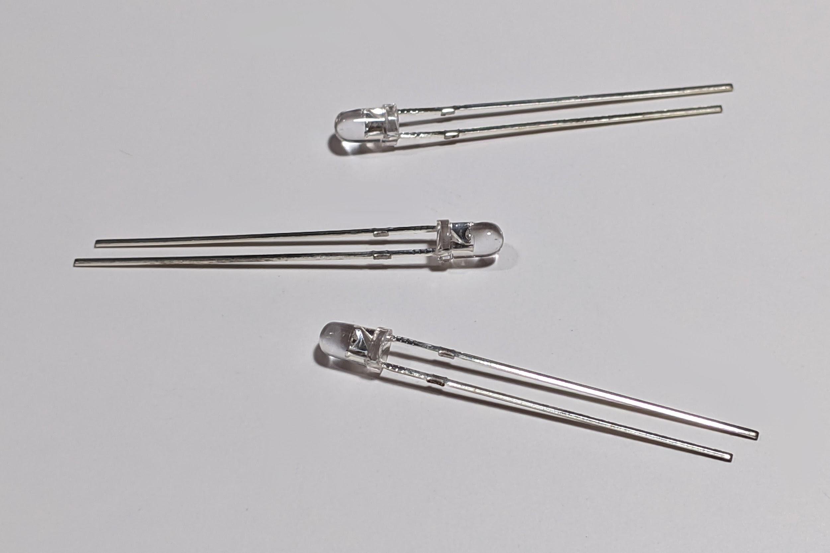
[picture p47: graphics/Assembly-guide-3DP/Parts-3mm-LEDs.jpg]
3mm LEDs

* (soldered version only) 3x 1KΩ resistors:
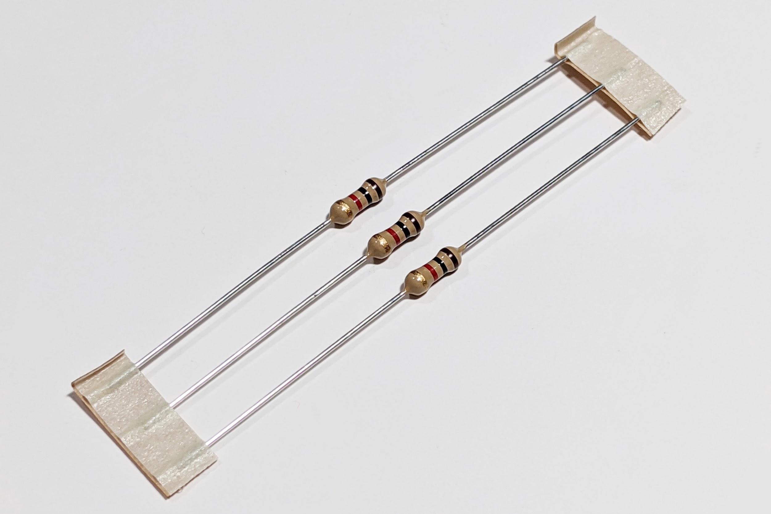
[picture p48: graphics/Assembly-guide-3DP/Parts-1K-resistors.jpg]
1K resistors

* A rotary encoder. Your vendor may also include a knob.
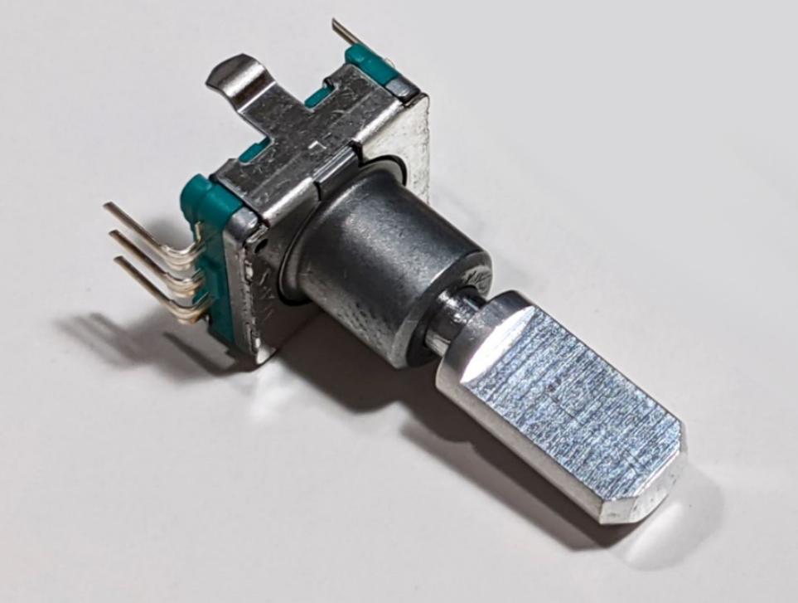
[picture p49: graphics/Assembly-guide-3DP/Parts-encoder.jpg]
Encoder

* 11 M3x10 flat head screws:
[image needed]
* 4 M3x8mm screws:
[image needed]
* 8 M3x6mm screws:
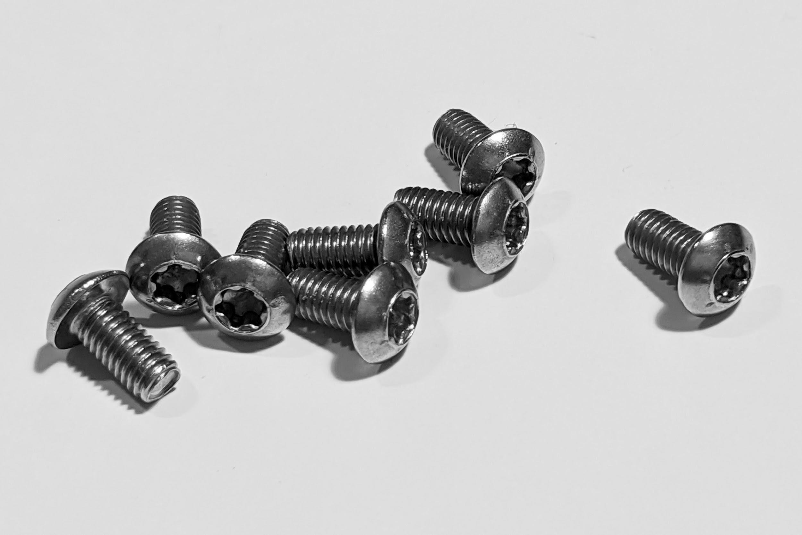
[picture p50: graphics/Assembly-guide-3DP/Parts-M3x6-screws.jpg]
M3x6mm screws

* 11 M3 PEM KF2-M3-ET threaded inserts:
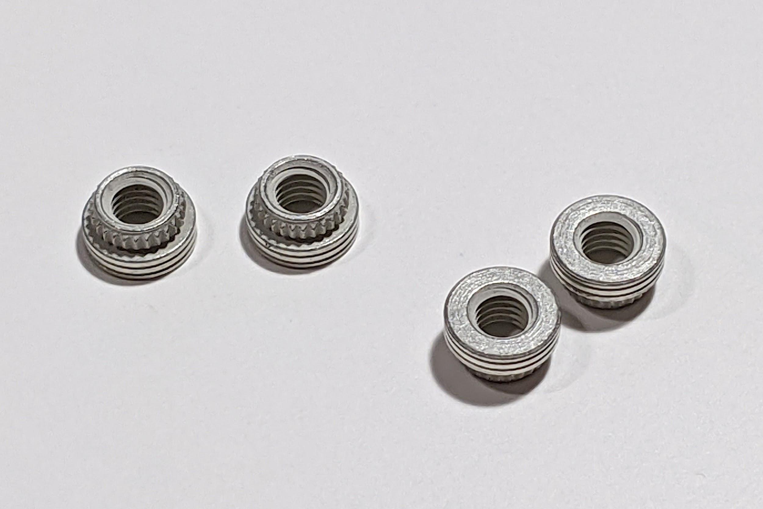
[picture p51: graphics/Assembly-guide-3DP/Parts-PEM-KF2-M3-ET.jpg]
PEM KF2-M3-ET threaded inserts

* 12 M3 hex nuts:
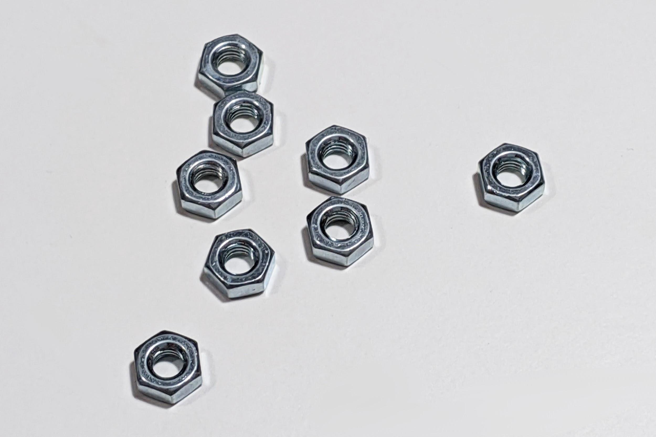
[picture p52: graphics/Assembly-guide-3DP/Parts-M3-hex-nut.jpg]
M3 hex nuts

* 14 M2x5mm self-tapping screws:
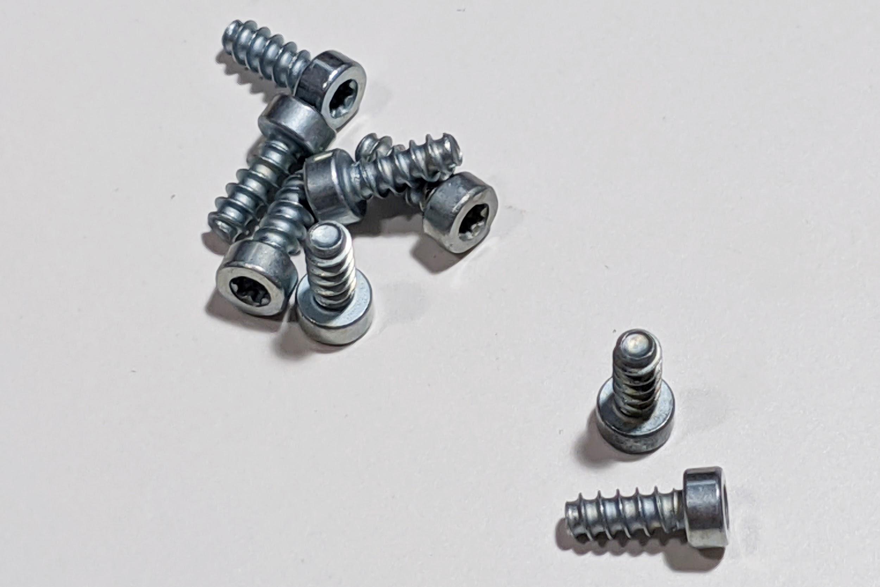
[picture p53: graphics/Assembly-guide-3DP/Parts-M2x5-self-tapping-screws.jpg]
M2x5mm self-tapping screws

* A reset switch (note on some PCBs this is already soldered on, and won’t be included as a result):
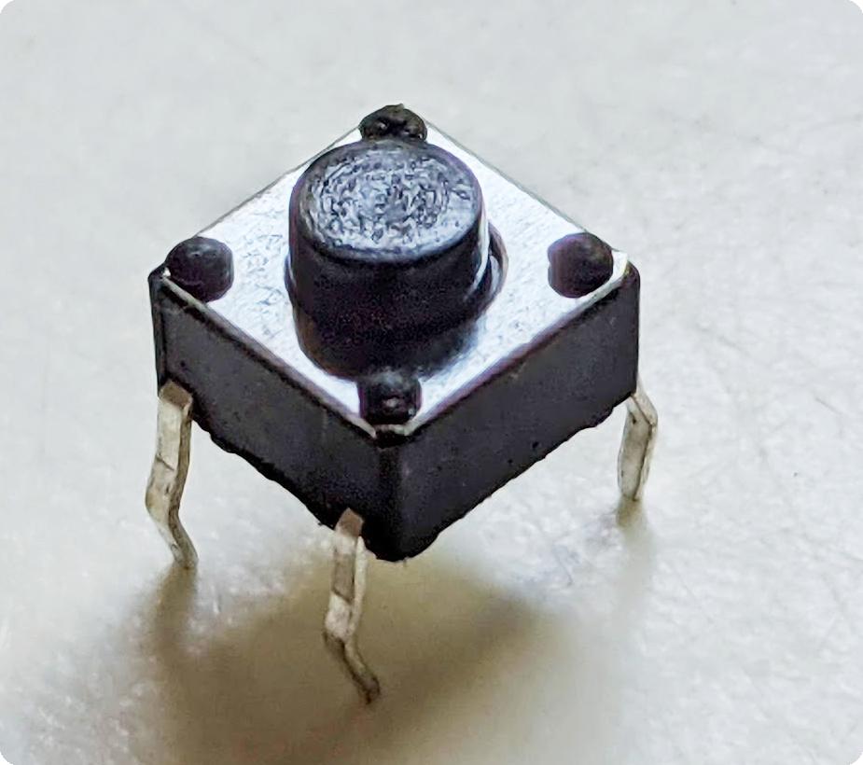
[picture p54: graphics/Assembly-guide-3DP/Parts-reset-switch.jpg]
Reset switch

* (soldered version only) A set of spring loaded pins (note on some PCBs this is already soldered on, and won’t be included as a result. You can also substitute this with a short piece of wire):
[image needed of spring loaded pins]
* (hotswap version only) 10 M2 3.5mm long standoffs:
[image needed of 3.5mm long standoffs]
* (hotswap version only) 20 M2x3mm screws: 
[image needed of M2x3mm screws]

If you purchased the kit from a vendor, note that some of the components may have already been soldered on. Please inform your vendor if any of the above is missing. 

# 3D-Printed Parts
Your vendor might have included these, or you may need to print these yourself. See [Part 0 - 3D printing the case parts](#part-0---3d-printing-the-case-parts) for information on how to print these parts.

* The left and right case halves:
[CAD image needed]

* The left key separator:
[CAD image needed]

* The right key separator:
[CAD image needed]

* The 3D-printed spacer for the lock LEDs:
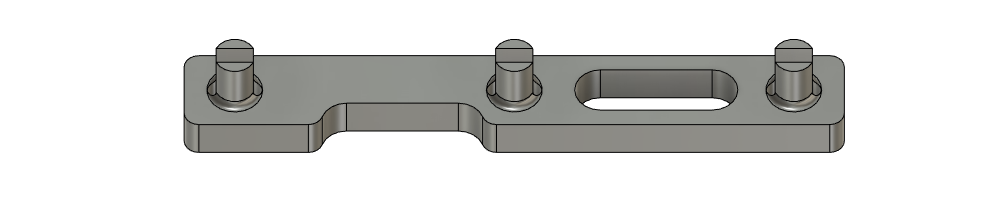
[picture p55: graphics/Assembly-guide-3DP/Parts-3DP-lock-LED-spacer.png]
3D printed lock LED spacer


# Parts You'll Need to Assemble the Keyboard
* MX-compatible switches. Depending on the layout you choose, you will need between 119 and 127 switches. 
* Keycaps of your choice. Make sure that they support your desired layout. 
* PCB-mount stabilizers (either screw-in or snap-in) of the correct size and quantity for your preferred layout. 
* A USB-C cable 
* A knob. The included encoder has a 6mm diameter D-shaft with a 4.5mm flat. Most knobs meant for 6mm shafts, that either have the flat or use a set screw for mounting, and are smaller than 21mm in diameter, will work.
* (optional) Through-hole LEDs for backlighting. Check that your switches and keycaps support the LEDs you choose - some switches only work with SMD LEDs (which are not supported on this PCB), and others may hit your keycaps. 

# Tools You'll Need to Assemble the Keyboard 
* A T6 Torx screwdriver or key. Make sure it is actually a T6 size!. A smaller bit may fit in the head, but is much more likely to strip the head. 
* A T10 torx screwdriver or key. Likewise, make sure it is actually a T10 size. 
* A pair of metal tweezers, wire, metal keycap puller, or unbent paper clip for testing the PCB 
* (hotswap only) A #1 Philips screwdriver. Make sure it's actually a #1 size. 
* A soldering iron and solder. 
* Super glue 
* A blue threadlocker, such as Loctite 242, 243, or 248, is recommended to prevent screws from loosening over time. 
* If you make mistakes while soldering parts in, you may need a desoldering pump (solder sucker) or desoldering wick to make fixes. 

# (Hotswap Only) - A Note on Hotswap Switch Installation

* Only use switches that have never been soldered. Desoldered switches can damage the hotswap socket.
* Make sure the pins are straight before inserting the switch 
* Support the back side of the hotswap socket when inserting switches. 

[image needed on how to support hotswap switches - similar to Novelkey's [diagram](https://cdn.shopify.com/s/files/1/3099/8088/files/Group_686_2x_cd694deb-8455-4dc1-82ed-5332ea2de4f6.png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) on [their instruction guides](https://novelkeys.com/pages/howto)]

# Part 0 - 3D Printing the Case Parts 

You will need to 3D-print the parts listed in [# 3D printed parts](#-3D-printed-parts). STL files for 3D printing are available on Github [here](https://github.com/bluepylons/Boston/tree/main/Boston%20-%20Current%20design/3D%20printed%20version/STLs). You will need a 3D printer with a minimum 200mm x 150mm bed x 210mm tall.

For the left and right case halves, printing with the long side facing up, like so, is recommended.
[new CAD image needed]

You may also want to adjust the Z-seam setting to prevent seams from being in highly visible places. Generally, you should try to locate the Z-seam at the bottom of the case, preferably in an inside corner.

For the key separators, the following orientation is recommended, with the rounded edges facing up: 
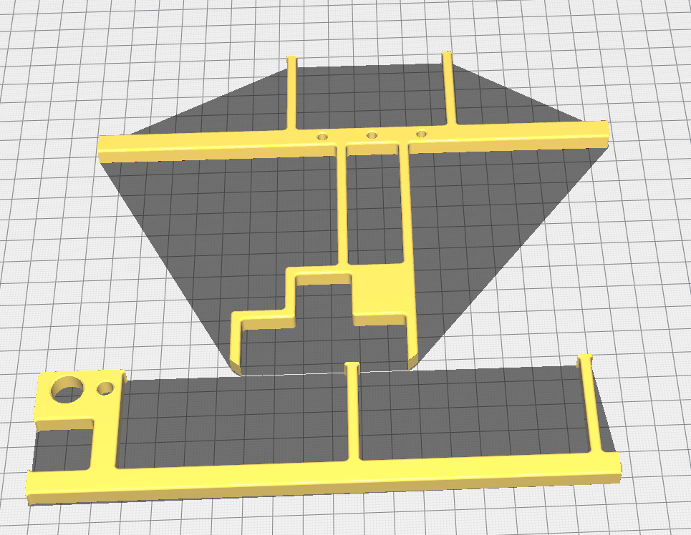
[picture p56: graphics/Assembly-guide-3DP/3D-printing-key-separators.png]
Key separators orientation


# Part 1 - Putting Together The Plate and Key Separators 

## 1.1 - Soldering the Threaded Inserts into the Plate

Flip the plate over so that the underside of the plate is facing you. Press in the PEM threaded inserts into the 11 holes on the plate. 

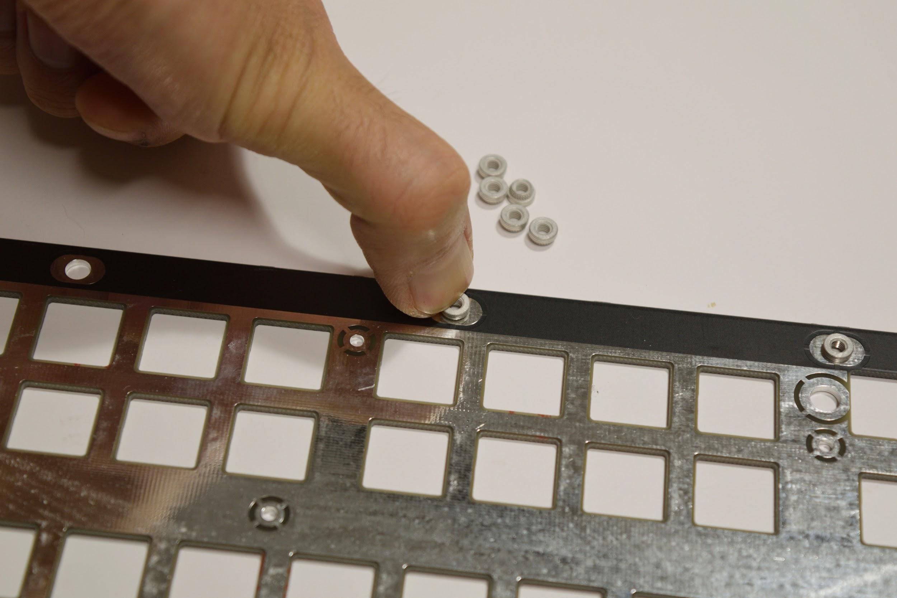
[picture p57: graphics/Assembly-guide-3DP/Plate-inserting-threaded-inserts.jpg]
Pushing PEM nuts in


If it’s too hard to push the inserts in, you can use one of the M3x6 screws to pull the insert in, using a T10 Torx screwdriver. Remove the screw when the insert is all the way in.

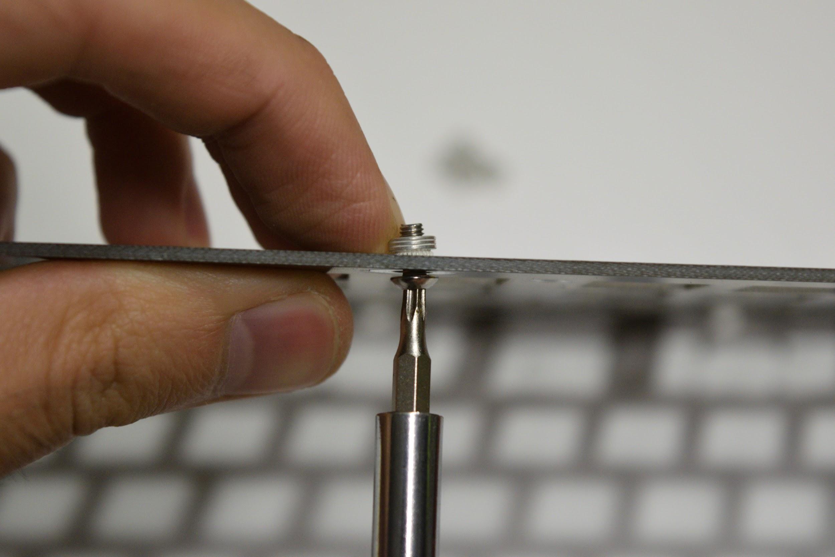
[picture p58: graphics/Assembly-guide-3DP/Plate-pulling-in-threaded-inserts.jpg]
Pulling PEM nuts in

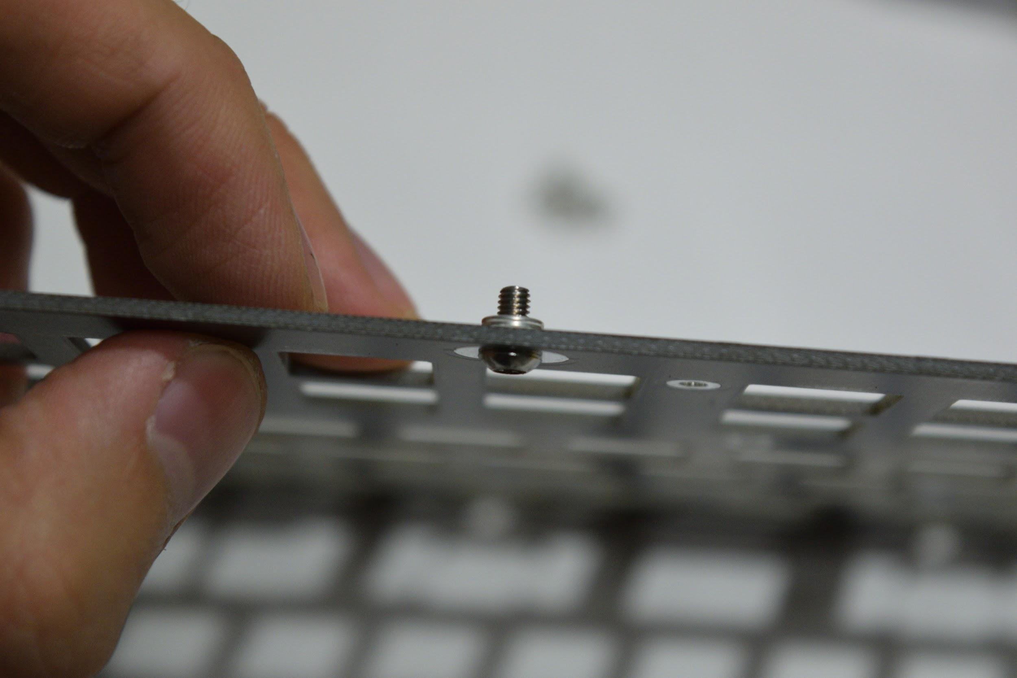
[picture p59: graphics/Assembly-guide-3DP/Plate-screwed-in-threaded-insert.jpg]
Pulled in PEM nuts


With the inserts pushed in, double check that they’re on the correct side - they should be on the bottom of the plate, not the top. Also, make sure the inserts are all of the way in and fully seated. Then, solder them in place:
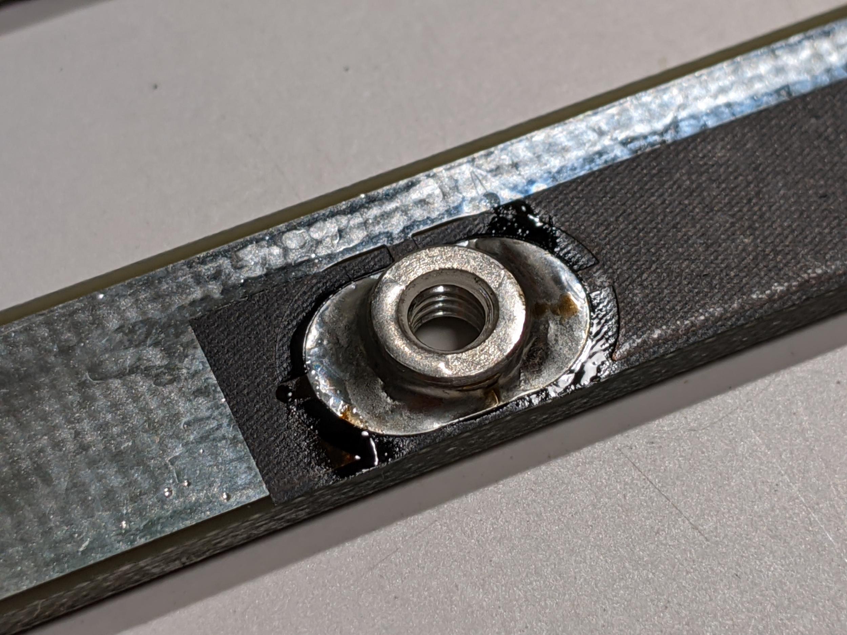
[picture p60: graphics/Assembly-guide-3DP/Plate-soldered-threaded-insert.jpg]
Soldered in PEM nuts


It may take some time for your soldering iron to get the nut and plate hot enough to get the solder to flow well. Also, avoid getting solder on the threads. If you get solder on the threads, try running an M3 screw through to clear solder off the threads. If that doesn’t work, you’ll need an M3 tap to remove the solder from the threads.

# 1.2 - (Hotswap Version Only) - Installing the Hotswap Standoffs

Attach the M2 3.5mm long standoffs onto the bottom of the plate using the M2x3mm screws, onto the following marked holes on the plate:

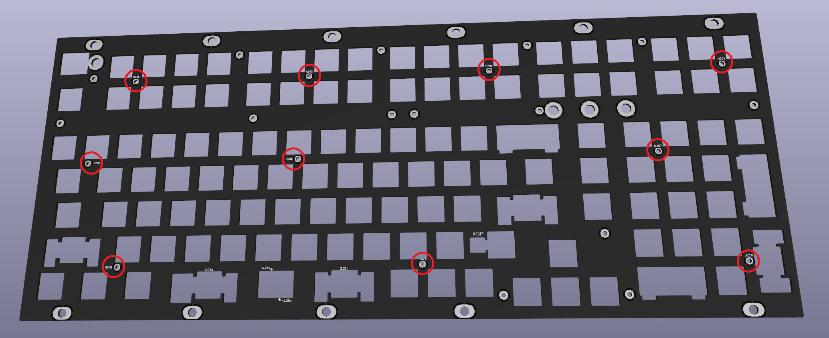
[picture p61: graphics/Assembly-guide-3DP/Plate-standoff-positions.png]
Standoff locations


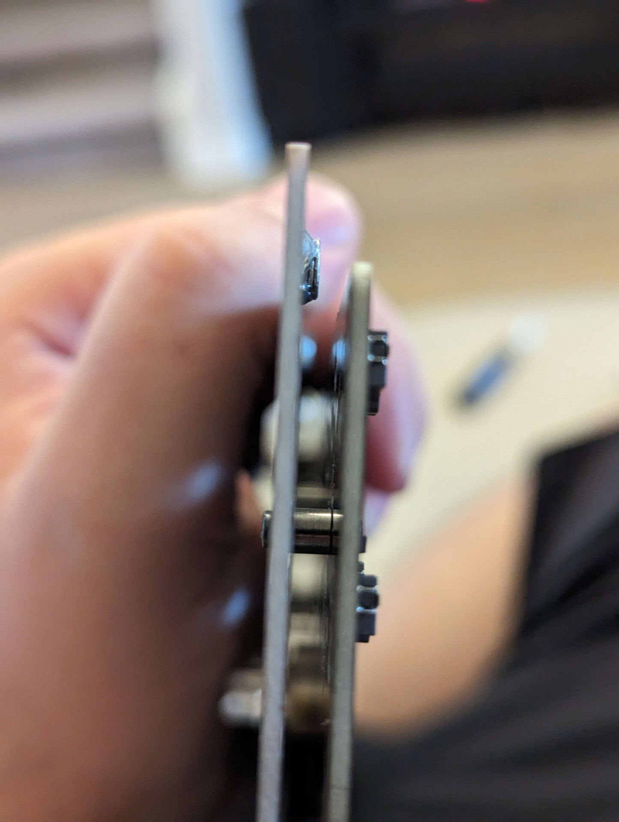
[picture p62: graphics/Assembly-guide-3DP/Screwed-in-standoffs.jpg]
Screwed in standoffs


[image needed of plate with screwed in standoffs]

# Part 2 - Attaching and Aligning the Key Separators

*On PCBs older than V0.7, the key separators cannot be adjusted after the switches are soldered on without desoldering all your switches. Make sure you get this right before soldering anything!* 

Next, grab the 3D-printed left-key-separator and right-key-separator pieces, and the M2x5 self-tapping screws. These pieces need to attach to the plate before the switches are soldered in.

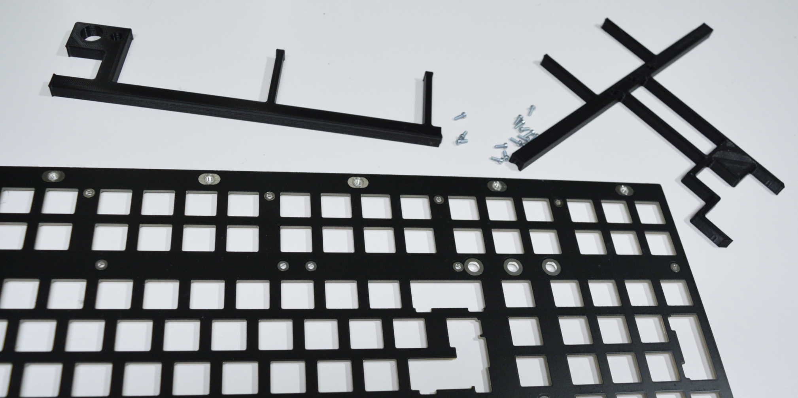
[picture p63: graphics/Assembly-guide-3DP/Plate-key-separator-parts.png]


Attach the key separators to the plate using the M2x5 self-tapping screws, via the small holes located in the plate. Use a T6 Torx screwdriver for this. Make sure the screws go in straight! **Do not tighten these all the way - leave them about a ½ turn loose, since we’ll need to adjust and align these in a little bit.** There are 14 screws that need to be attached in total - 6 on the left separator, and 8 on the right separator. 

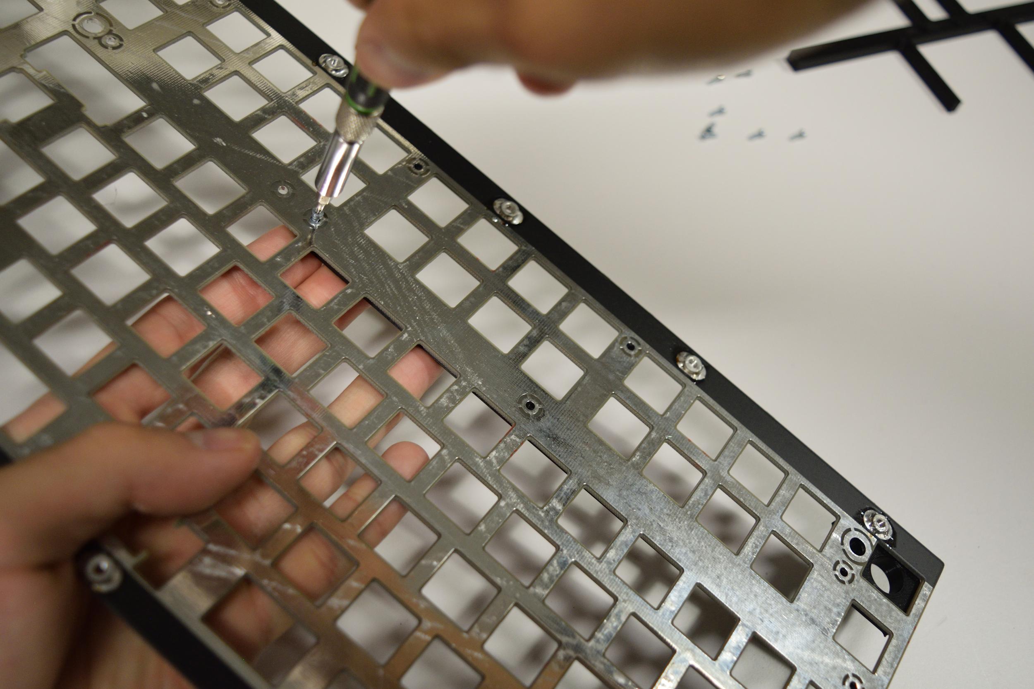
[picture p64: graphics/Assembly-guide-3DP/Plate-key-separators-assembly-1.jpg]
Key separators


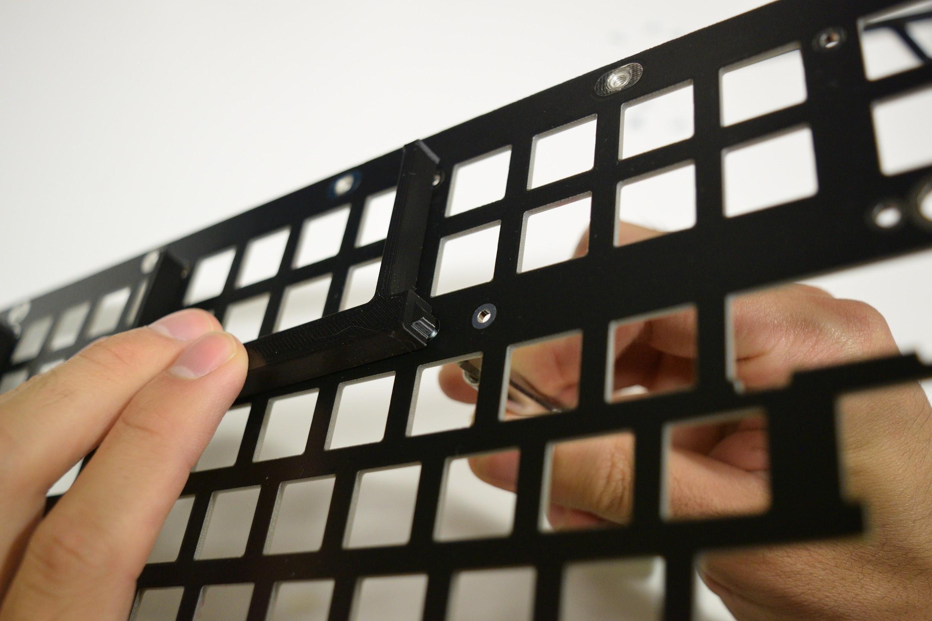
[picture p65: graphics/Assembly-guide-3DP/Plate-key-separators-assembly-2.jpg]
Key separators


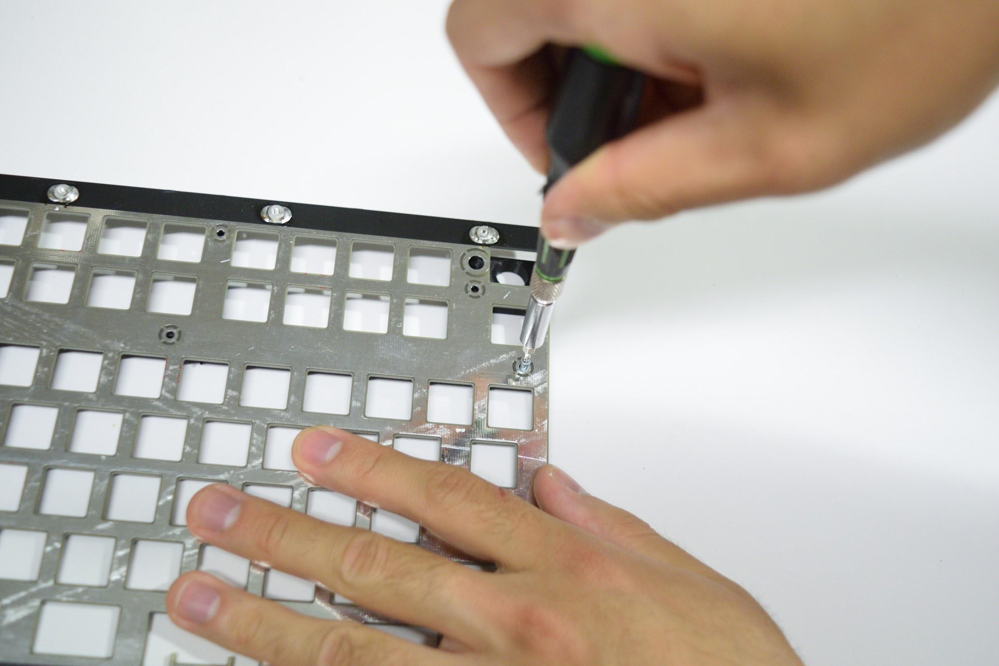
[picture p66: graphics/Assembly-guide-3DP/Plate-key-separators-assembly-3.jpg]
Key separators


With the screws in but not tightened fully, do a test fit against the left and right case halves by sliding the plate into the left and right case halves. Note that you’ll have to slightly spread apart the right case half to get it past the arrow key cluster. 

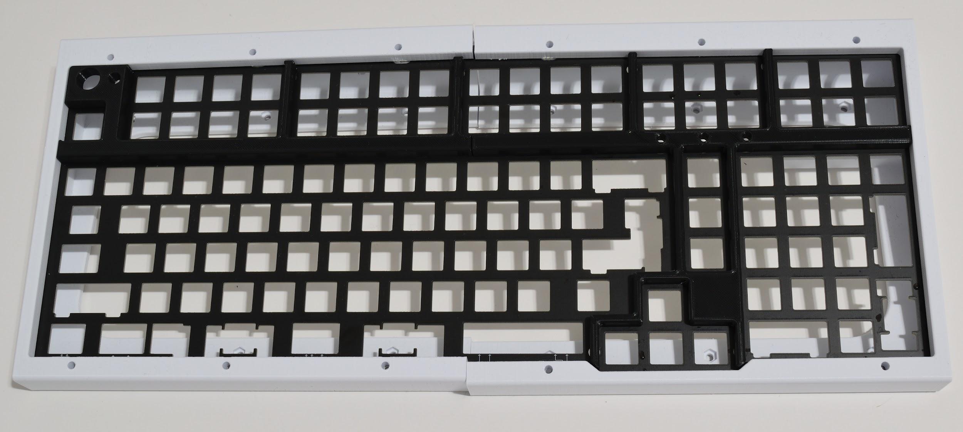
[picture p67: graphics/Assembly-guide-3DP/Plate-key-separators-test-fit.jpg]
Key separators test fit


Attach the plate to the case using M3x10mm screws. Make sure the plate is fully seated against the case.

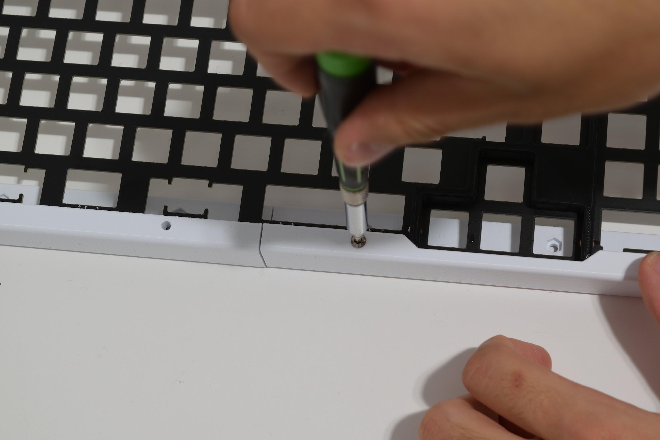
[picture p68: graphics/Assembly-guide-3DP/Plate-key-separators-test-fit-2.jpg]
Key separators test fit


Adjust the separator pieces so that the gaps between the separators and the case halves (marked in orange) are minimal when the plate is slid into the very end of the case halves. There may be a small gap between the two separators (gap marked in pink) - this is normal. 

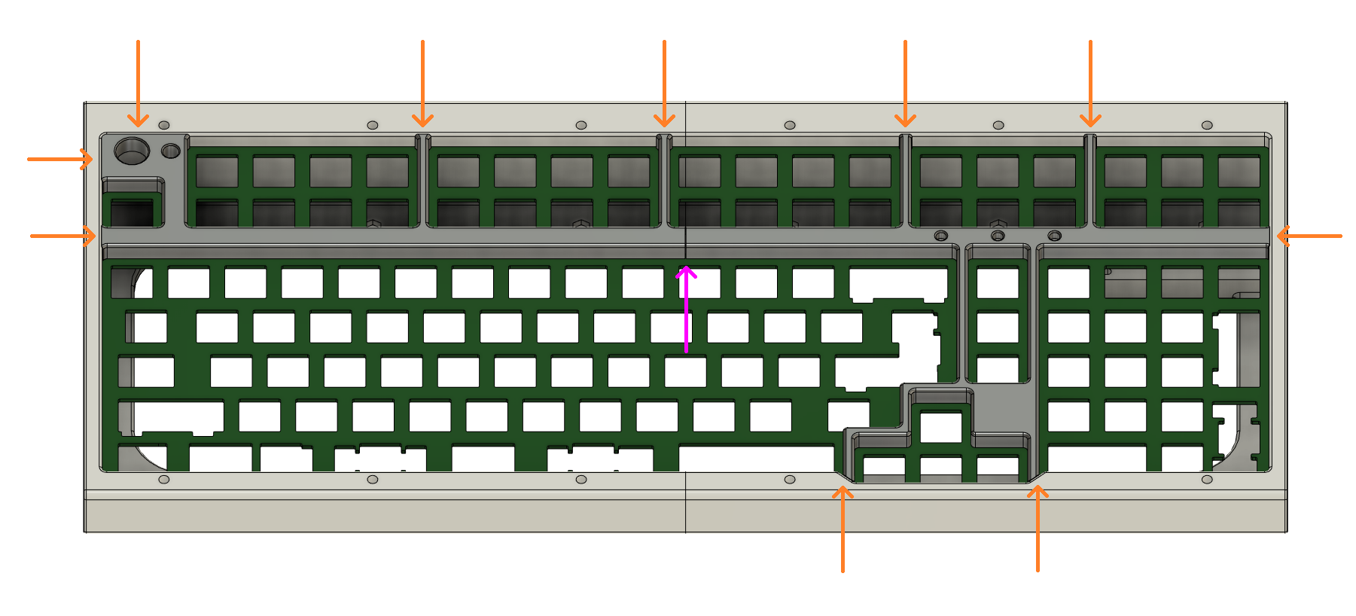
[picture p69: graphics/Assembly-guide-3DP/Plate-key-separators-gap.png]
Plate key separators gap


Flip the assembly over, and tighten the screws that can be accessed:

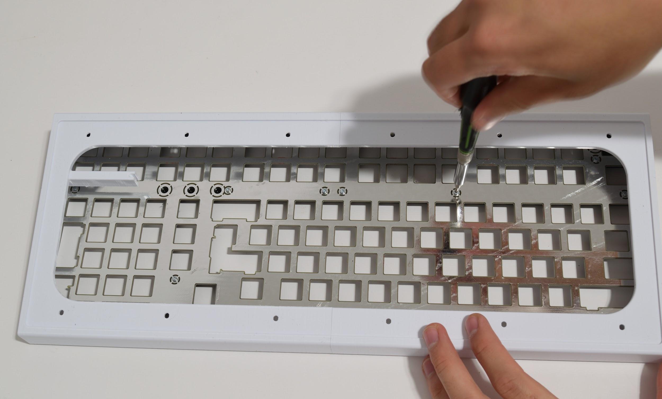
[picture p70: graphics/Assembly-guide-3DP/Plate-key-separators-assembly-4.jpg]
Plate key separators assembly 4


Remove the case halves, and tighten up the remaining screws:
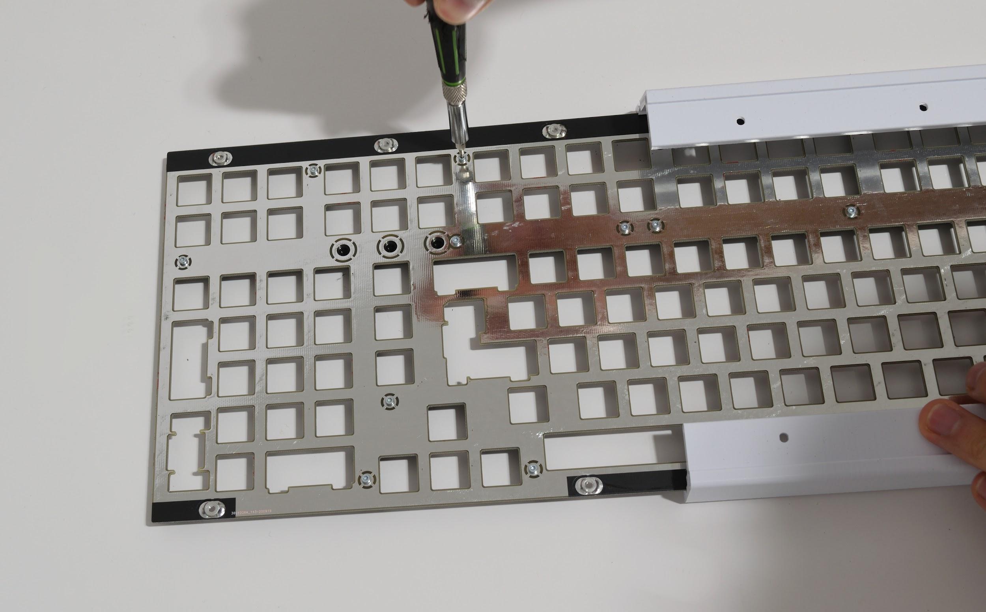
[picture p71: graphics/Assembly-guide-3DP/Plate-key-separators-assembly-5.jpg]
Plate key separators assembly 5


Put everything back together and do a final check of the gaps. Make any adjustments as necessary. Again, on PCBs older than V0.7, you can’t fix this once the switches are soldered in!

When everything looks good, remove the case halves again, and make sure all the screws are tight. 

# Part 3 - Testing and Soldering Additional Parts on the PCB

# 3.1 - Testing Each Key on the PCB 

Testing the PCB before further assembly is recommended - use a tweezer, metal keycap puller, wire, or unbent paperclip to short the switch opening pins, and a program such as [Aquakeytest](https://geekhack.org/index.php?topic=34670.0) or [Vial](https://get.vial.today/)'s built-in matrix tester to ensure that each key works. 

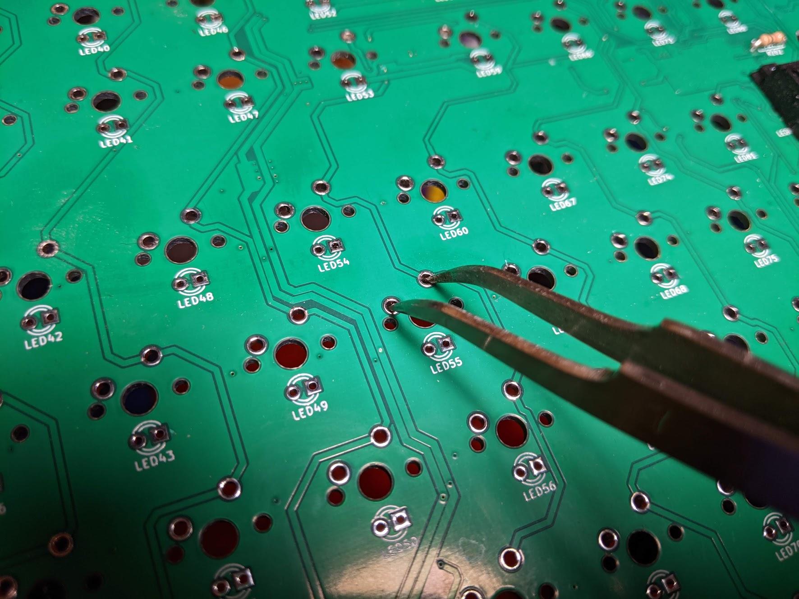
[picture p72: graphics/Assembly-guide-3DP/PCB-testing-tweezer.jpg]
PCB testing with tweezers


# 3.2 - (Soldered Version Only) - Soldering on the 1KΩ Resistors

Grab the 3 1KΩ resistors and solder them into the spots for R200, R201, and R202, on the top side of the PCB. If you’re using your own LEDs and want them brighter or dimmer, you may want to use different resistors than the provided resistors.

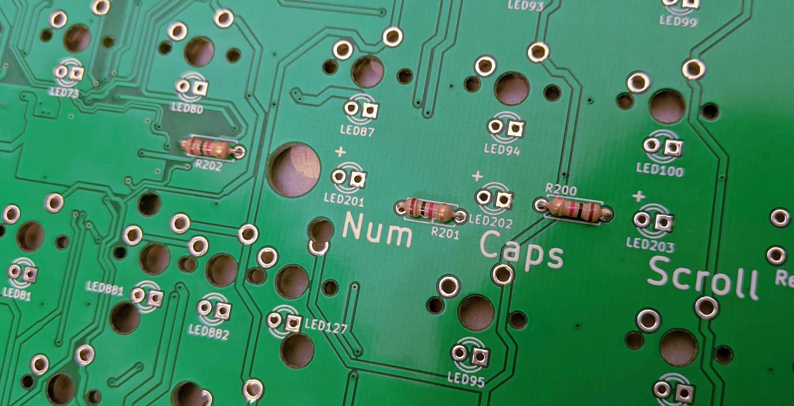
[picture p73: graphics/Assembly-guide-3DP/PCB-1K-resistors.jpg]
PCB 1K resistors


# 3.3 - Soldering on the Lock LEDs 

Grab the spacer for the LEDs, and run the LEDs legs through it. Place the LEDs and spacers onto the PCB, for spots LED201, LED202, and LED203. Note that the spacer only fits in one way.

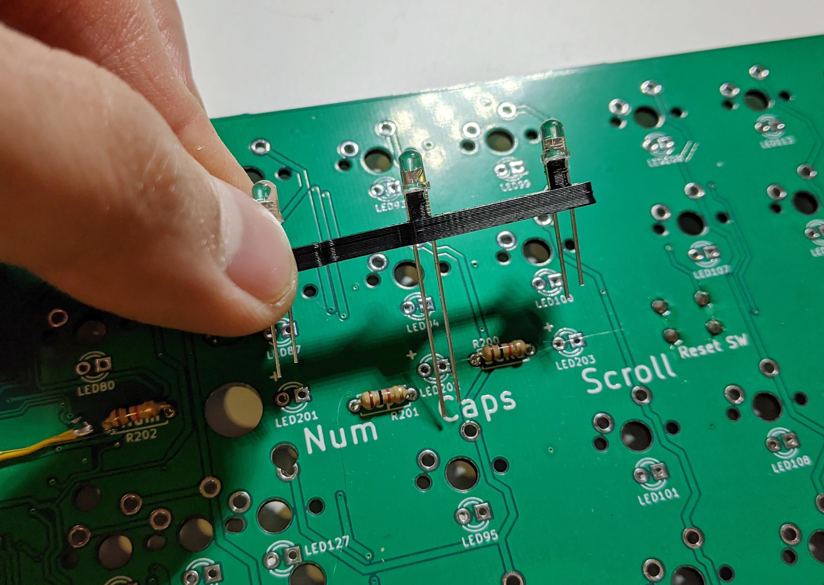
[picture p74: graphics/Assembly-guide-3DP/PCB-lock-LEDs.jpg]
PCB lock LEDs


Note that LEDs are directional and will not light up if soldered in backwards. The longer leg on an LED is +. Make sure this matches up with the + symbols on the PCBs. 

LED polarity

Once the LEDs are in, solder them in. Make sure that they’re in straight! 

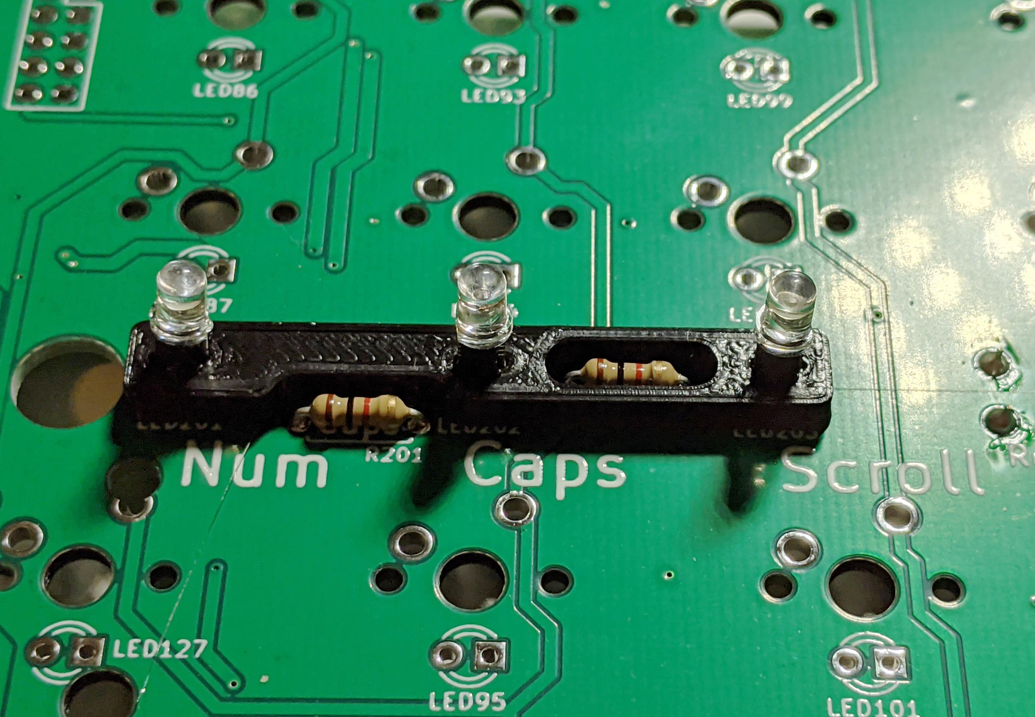
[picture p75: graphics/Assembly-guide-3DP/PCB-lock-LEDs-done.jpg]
PCB lock LEDs


If you haven’t already done so, clip the legs on the resistors and LEDs with a pair of flush cutters.

# 3.4 - Soldering the Rotary Encoder 

Next, solder on the rotary encoder onto the top left corner of the PCB.

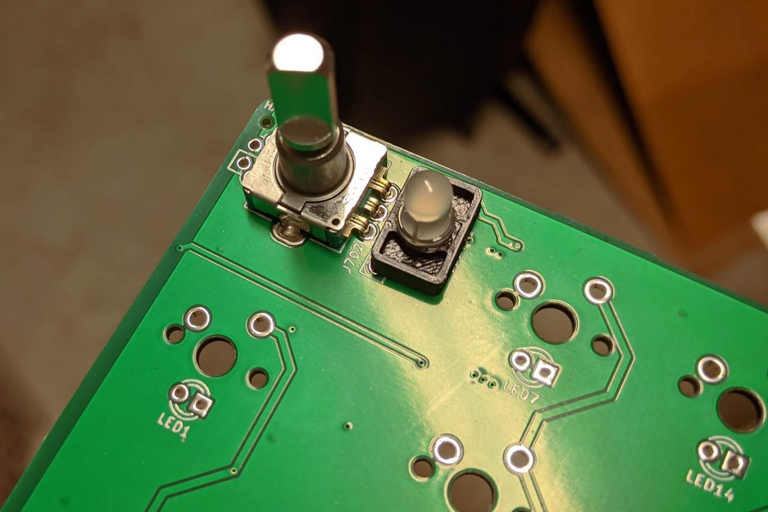
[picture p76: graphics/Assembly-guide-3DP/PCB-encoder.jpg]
Rotary encoder


# 3.5 - Soldering on the Reset Switch 
If your PCB did not come with the reset switch soldered on, solder it onto the bottom side of the PCB near the numpad (if you have PCB V0.7 or older), or to the top side of the PCB just to the left of right shift (on PCB V0.8 and newer). 

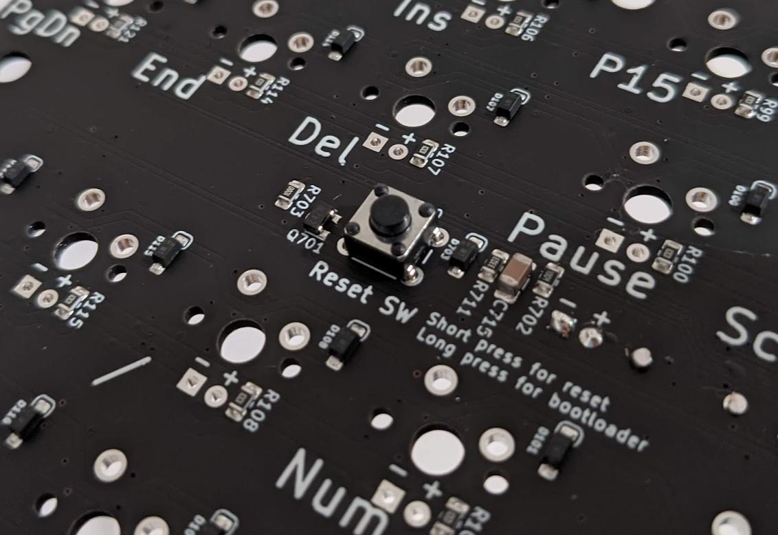
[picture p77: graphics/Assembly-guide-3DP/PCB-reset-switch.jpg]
Reset switch


# 3.6 - (Soldered PCB only) Soldering on the Spring-Loaded Pins 

If you are using PCB V0.7 or newer, solder on the spring-loaded pins, which are soldered to the top side of the PCB on the right side of the keyboard. This is used to electrically ground the plate and the screws on the top of the case so that static shocks do not reset the keyboard microcontroller. If you do not have the spring loaded pins, you can solder a small wire to where the spring loaded pin goes and solder the other end of the wire to the corresponding area on the plate. 

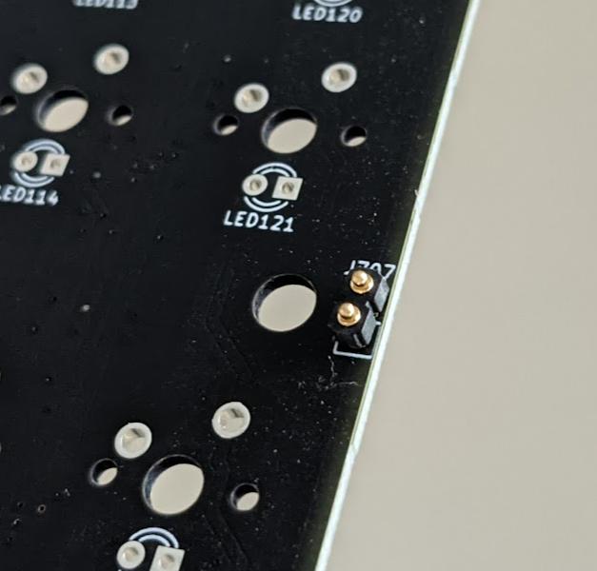
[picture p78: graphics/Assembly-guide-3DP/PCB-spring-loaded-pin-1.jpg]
Spring loaded pins 1

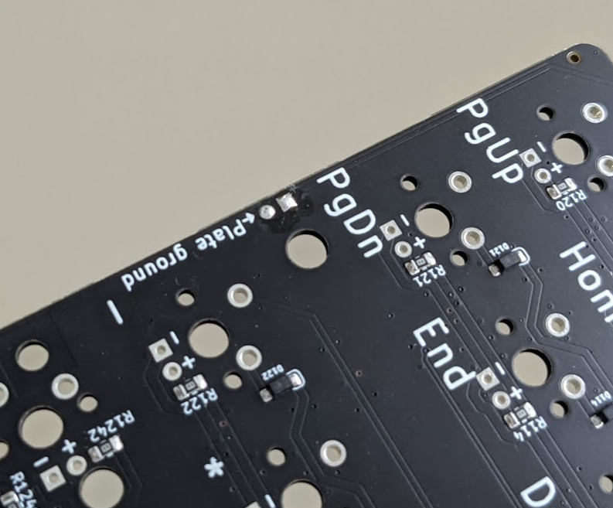
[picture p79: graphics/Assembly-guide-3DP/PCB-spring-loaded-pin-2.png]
Spring loaded pins 2


# Part 4 - Installing Stabilizers and Switches

# 4.1 - Deciding Your Layout

Boston supports the following layout on the soldered PCB:
Soldered PCB supported layouts

The following layouts are supported on the hotswap ANSI PCB:
ANSI HS PCB supported layouts

Decide what layout you want (for example, do you want ANSI Enter, or ISO Enter?), and determine where you’ll need to install stabilizers. Any keys 2 units wide or longer (for example, a standard backspace key) will need stabilizers. Also, make sure you have the keycaps for the layout you want.

## Modding Your Switches and Stabilizers 
If you want to mod or tune your switches or stabilizers (e.g. lubing them, or changing the springs in them), do so before installing them. It is much harder to make any changes after they’re installed. On soldered keyboards, stabilizers cannot be installed or removed after switches are soldered in, without desoldering most or all of your switches.

# 4.2 - Installing the Stabilizers 

Boston takes PCB-mount stabilizers, either screw-in or clip in style. These are available from several manufacturers (e.g. GMK, TX, Cherry, C3, Durock, Zeal, and others make PCB mount-stabilizers).

Install all the stabilizers according to the instructions from their manufacturer.

Stabilizers

# 4.3 - (Hotswap Version Only) - Attaching the PCB to the Plate 

Screw the PCB onto the plate via the 10 standoffs on the plate that were previously attached in Step 1.2. 

[image needed]

# 4.4 - Testing Your Stabilizers 

It’s strongly recommended to test your stabilizers before proceeding, as any fixes to your stabilizers after soldering the switches will likely require removing or desoldering all the switches and removing the plate from the PCB. Test them now, as if there's something wrong with them it will be much more work to fix them later.

To do this, take a switch and an appropriate keycap for the stabilizer you want to test. If you're on the soldered version, you will also need to grab the plate now. 

Install the switch onto the plate and PCB. On the hotswap version, remember  to support the hotswap socket from the back side while inserting the switch, and that the switch pins are straight before inserting it in. On the soldered version - you do not need to solder the switch in yet - just make sure it fits into the PCB. 

Stabilizer testing 1

Install the keycap onto the switch. Make sure the key feels okay - that it’s not binding, or failing to go all the way to the bottom, or failing to return, for instance. Do this for all your stabilizers to make sure that they’ve been installed properly. 

Stabilizer testing 2

# 4.5 - Installing Your Bottom Row 

On the soldered version - we’ll start installing and soldering switches on the bottom row as this is the most likely place that mistakes are made, since the soldered version of Boston supports several different bottom row layouts, and it's easy to accidentally put a switch in the wrong place. You can also start here on the hotswap version, though due to the more restricted bottom row layout you're much less likely to make mistakes here.

Both the plate and PCB on the soldered version are marked with where to put the switches in for your desired bottom row positions. The arrows point at the center of the switch. Install switches into the desired positions on the bottom row. Make sure that the switches are fully seated into the plate. 

After installing the switches into the plate, and before soldering the switches, install keycaps on your bottom row to ensure that everything is in the correct place. Make any fixes as necessary. 

Bottom row testing

If everything looks correct, solder the switches in.

# 4.6 - Install the Rest of the Switches

Solder or install the rest of your switches.

# Part 5 - Case Prep and Assembly

# Part 5.1 - Installing the M3 Hex Nuts into the Case

Take the left and right case halves from earlier, and the M3 hex nuts. Push the hex nuts into the 6 hex-shaped pockets on the bottom of each case half. If it’s difficult to push them in, you can use an M3x6 screw to pull the nuts in. If the nuts fit in loosely and fall out easily, glue them in with super glue or hot glue.

Pushing M3 nuts into case

# Part 5.2 - Installing the Case Halves 

Take the left and right case halves and slide them onto the plate, and screw them into the plate using M3x10 screws. **Do not tighten these down all the way - leave them about 1 turn loose, as we need to align them later.** For the right case half, you’ll have to spread the case apart slightly to get it past the arrow key cluster.

Case half install 1
Case half install 2
Case half install 3

# Part 5.3 - Installing the Bottom Panel and Rubber Feet 

Flip everything over, and install the bottom panel. With PCB V0.7 and older, you need to place the bottom panel in the orientation shown (if you get it backwards, the reset switch will not be accessible). On PCB revision V0.8 or older, you can install the bottom panel in either orientation as the reset button has moved to the top side.

Install M3x6 screws in the middle 8 holes to secure the bottom panel. Avoid pushing down on the screwdriver as this can cause the hex nut on the other side to push out and fall out (and you’ll have to take the case back apart to retrieve it and reinstall it). Again, don’t tighten these in all the way, but leave them about a turn loose.

Case bottom panel install

Take the FR4 rubber feet holders and install them on the ends using M3x10 screws. Again, avoid pushing down on the screwdriver. Tighten these screws in all the way. 

FR4 bottom feet holder install

Once the rubber feet holders are installed, peel the rubber feet off from the backing sheet and stick them onto the four corners.

Rubber feet install
Rubber feet install

# Part 5.4 - Leveling the Keyboard 

Next, take the keyboard and place it right-side up over a flat, level surface. Take your palm or forearm, and push the keyboard down against your flat, level surface, and tighten all the exterior case screws. This is to make sure the case and feet are flat and do not wobble. 

Leveling

Once this is done, press down on the corners of the keyboard and make sure the keyboard doesn’t wobble or see-saw. If it still does, make adjustments as necessary. There may be a slight misalignment between the left and right case halves after this adjustment - this is normal, as unfortunately 3D printing is a relatively imprecise process. If there is unresolvable wobble or misalignment, you may need to adjust the frame alignment on your 3D printer and reprint the parts.

After all this, install the knob and keycaps. Plug the keyboard into a computer and check that it works (it may take a couple of seconds for the keyboard to initialize). You’re done!

You are done!

# Appendix 1 - Remapping keys 

If you purchased your keyboard from a vendor, your keyboard comes with a default keymap and [Vial](https://get.vial.today/) 0.6 firmware installed. [Vial](https://get.vial.today/) is an open-source alternative to VIA, and allows you to remap keys without reflashing your keyboard. Instructions on how to use Vial are [here](https://get.vial.today/manual/first-use.html)

These are the default key assignments:
Default key assignments

# Appendix 2 - Flashing Firmware 

If you bought the PCB directly from a PCB fab, or if you wish to flash a different firmware other than Vial, please follow the following steps. You’ll also need a second keyboard for the flashing process.

## 2.1 - Gabbing the .bin fFle

Before flashing, you will need to have the .bin file for your firmware. Make sure that the .bin file is compiled for the Boston. The 3D-printed Boston and the CNC version of the Boston use the same firmware files. 

* The default Vial .bin file is avialable on Github [here](https://github.com/bluepylons/Boston/blob/main/Boston%20-%20Current%20design/boston_vial.bin). 
* If you are compiling QMK or Vial, the .bin file should be produced when compilation is done. Often, this file is in your Home folder or wherever the output of your compiler is set to. 
* The Vial source files are on [Vial's Github repo](https://github.com/vial-kb/vial-qmk/tree/vial/keyboards/boston). Likewise, the QMK source files are on [QMK's Github repo](https://github.com/qmk/qmk_firmware/tree/master/keyboards/boston)
* Instructions for setting up a QMK build environment are available from QMK [here](https://github.com/qmk/qmk_firmware/blob/master/docs/newbs_getting_started.md)

## 2.2 - Installing Drivers and QMK Toolbox 

You’ll need to install drivers to communicate with the keyboard’s microcontroller properly. This can be done with a tool called [Zadig](https://zadig.akeo.ie/) on Windows. It is unclear if this is needed for other OS'es (such as Linux or MacOS)

Open Zadig:
Zadig-1

Select “List All Devices” in the Options Menu 
Zadig-2

Select “STM32 Bootloader” in the dropdown menu:
Zadig-3

Select WinUSB here:
Zadig-4

Click the "Replace Driver" button.

Wou will also needed to download [QMK Toolbox](https://github.com/qmk/qmk_toolbox/releases) for your OS. 

## 2.2 - Finding the Reset Button 

The reset button location varies depending on the version you have. On PCB V0.7 and older, the reset button is located on the underside of the PCB. You can press it by inserting an unbent paperclip or a small screwdriver through the following hole on the bottom panel and pushing the switch. 

Reset button location on V0.7J and older

On PCB V0.8 and newer, the reset button is on the top side of the PCB, next to the Right Shift key. You will need to take off the Right Shift keycap to access it.

Reset button location on V0.8 and newer

## 2.3 - Pressing the Reset Button to Enter Bootloader Mode 

Plg your keyboard in. 

If you have a PCB variant older than V0.6 (such as V0.5.2), a simple press of the reset button is sufficient to enter Bootloader mode.

On PCB variants V0.6 and newer, hold down the reset button for at least 5 seconds to Enter bootloader mode.

## 2.4 - Opening QMK Toolbox 

Open QMK Toolbox. “STM32 DFU device connected” should appear in yellow. If that text isn’t there, press the reset switch on your keyboard according to the instruction earlier. 
QMK-Toolbox-1

Press “Open” and navigate to the location of your .bin file.
QMK-Toolbox-2

Press the Flash button. Do not disconnect the keyboard until it is done flashing, or you may permanently brick your keyboard.
QMK-Toolbox-3

Once your flash is complete, your keyboard with the .bin file you flashed should be ready for use!

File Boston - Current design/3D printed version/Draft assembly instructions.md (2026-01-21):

# Boston (3D-printed/FR4 version) Assembly Instructions, including 3D printing 

## Draft. Mostly complete; missing a few images (January 10, 2026)

## To Do

* Instructions on how to solder per-key LEDs (soldered version only - the hotswap version does not have the per-key LEDs)

## Errata

* If you are using split 1u numpad + and =, the + and = are reversed in Vial, QMK, and in the key diagram. For now just assign the key you want to + to =, and vice versa.

# Table of Contents

* Before You Start
* What’s in the box:
* Part 1: 3D-printing the case parts
* Part 2: Putting Together The Plate and Key Separators
* Part 3: Soldering Additional Parts on the PCB
* Part 4: installing stabilizers and switches
* Part 5 - Case Prep and Assembly
* Part 6: Flashing Firmware
* Appendix:

# Before You Start 
* Boston is an open-source keyboard project. Follow these assembly instructions at your own risk. 
* Please read the entirety of this guide before you begin. The assembly process for the 3D-printed version of Boston is a bit atypical.
* The 3D printed key separators must be installed onto the plate before the switches are soldered on. If you have the plate and PCB but do not have the 3D printed parts yet - do not solder your switches on yet.  
* If you purchased a kit from a vendor, some of the steps may have already been done for you by the vendor. 
* Do not use strong chemicals such as acetone to wipe down any part of the case or PCB. This may cause damage. 
* The PCB has an ESD protection chip to provide some protection when it is fully assembled, but cannot protect the keyboard while you are building it. Please observe basic procedures to prevent damage from electrostatic discharge (ESD) while handling the PCB or assembling the keyboard.
    * Wear a properly-grounded ESD wrist strap while you are assembling the board.
    * Touch a grounded metal object before you begin handling the PCB to reduce risk of ESD damage, and touch a  grounded metal object regularly to discharge any ESD buildup. 
    * Avoid wearing clothing (e.g. wool sweaters, socks) that can cause ESD buildup
    * Avoid working on a carpeted surface. 
    * A guide on basic ESD procedures is available [here](https://www.wikihow.com/Ground-Yourself-to-Avoid-Destroying-a-Computer-with-Electrostatic-**Discharge**). 
* Soldering can be hazardous
  * Wear safety glasses while soldering! Hot droplets of flux may fly towards you while you are soldering.
  * The hot tip of a soldering iron can cause serious burns.
  * Use a fume extractor while soldering, or solder in a well-ventilated space. Flux fumes can be hazardous and can cause long-term lung issues. 
* Do not overtighten the screws! This can strip the head or the threads and cause other damage.
  
# What You Should Have:
* The PCB:
[image needed of PCB]
* The FR4 fiberglass plate: 
FR4 fiberglass plate
* The FR4 bottom panel:
FR4 bottom panel
* 3x 3mm LEDs:
3mm LEDs
* (soldered version only) 3x 1KΩ resistors:
1K resistors
* A rotary encoder. Your vendor may also include a knob.
Encoder
* 15 M3x10mm screws:
M3x10mm screws
* 8 M3x6mm screws:
M3x6mm screws
* 11 M3 PEM KF2-M3-ET threaded inserts:
PEM KF2-M3-ET threaded inserts
* 12 M3 hex nuts:
M3 hex nuts
* 14 M2x5mm self-tapping screws:
M2x5mm self-tapping screws
* A reset switch (note on some PCBs this is already soldered on, and won’t be included as a result):
Reset switch
* (soldered version only) A set of spring loaded pins (note on some PCBs this is already soldered on, and won’t be included as a result. You can also substitute this with a short piece of wire):
[image needed of spring loaded pins]
* (hotswap version only) 10 M2 3.5mm long standoffs:
[image needed of 3.5mm long standoffs]
* (hotswap version only) 20 M2x3mm screws: 
[image needed of M2x3mm screws]

If you purchased the kit from a vendor, note that some of the components may have already been soldered on. Please inform your vendor if any of the above is missing. 

# 3D-Printed Parts
Your vendor might have included these, or you may need to print these yourself. See [Part 0 - 3D printing the case parts](#part-0---3d-printing-the-case-parts) for information on how to print these parts.

* The left and right case halves:
3D printed case halves

* The left key separator:
3D printed left key separator

* The right key separator:
3D printed right key separator

* The 3D-printed spacer for the lock LEDs:
3D printed lock LED spacer

# Parts You'll Need to Assemble the Keyboard
* MX-compatible switches. Depending on the layout you choose, you will need between 119 and 127 switches. 
* Keycaps of your choice. Make sure that they support your desired layout. 
* PCB-mount stabilizers (either screw-in or snap-in) of the correct size and quantity for your preferred layout. 
* A USB-C cable 
* A knob. The included encoder has a 6mm diameter D-shaft with a 4.5mm flat. Most knobs meant for 6mm shafts, that either have the flat or use a set screw for mounting, and are smaller than 21mm in diameter, will work.
* (optional) Through-hole LEDs for backlighting. Check that your switches and keycaps support the LEDs you choose - some switches only work with SMD LEDs (which are not supported on this PCB), and others may hit your keycaps. 

# Tools You'll Need to Assemble the Keyboard 
* A T6 Torx screwdriver or key. Make sure it is actually a T6 size!. A smaller bit may fit in the head, but is much more likely to strip the head. 
* A T10 torx screwdriver or key. Likewise, make sure it is actually a T10 size. 
* A pair of metal tweezers, wire, metal keycap puller, or unbent paper clip for testing the PCB 
* (hotswap only) A #1 Philips screwdriver. Make sure it's actually a #1 size. 
* A soldering iron and solder. 
* Super glue 
* A blue threadlocker, such as Loctite 242, 243, or 248, is recommended to prevent screws from loosening over time. 
* If you make mistakes while soldering parts in, you may need a desoldering pump (solder sucker) or desoldering wick to make fixes. 

# (Hotswap Only) - A Note on Hotswap Switch Installation

* Only use switches that have never been soldered. Desoldered switches can damage the hotswap socket.
* Make sure the pins are straight before inserting the switch 
* Support the back side of the hotswap socket when inserting switches. 

[image needed on how to support hotswap switches - similar to Novelkey's [diagram](https://cdn.shopify.com/s/files/1/3099/8088/files/Group_686_2x_cd694deb-8455-4dc1-82ed-5332ea2de4f6.png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) on [their instruction guides](https://novelkeys.com/pages/howto)]

# Part 0 - 3D Printing the Case Parts 

You will need to 3D-print the parts listed in [# 3D printed parts](#-3D-printed-parts). STL files for 3D printing are available on Github [here](https://github.com/bluepylons/Boston/tree/main/Boston%20-%20Current%20design/3D%20printed%20version/STLs). You will need a 3D printer with a minimum 200mm x 150mm bed x 210mm tall.

For the left and right case halves, printing with the long side facing up, like so, is recommended.
Case halve orientation

You may also want to adjust the Z-seam setting to prevent seams from being in highly visible places. Generally, you should try to locate the Z-seam at the bottom of the case, preferably in an inside corner.

For the key separators, the following orientation is recommended, with the rounded edges facing up: 
Key separators orientation

# Part 1 - Putting Together The Plate and Key Separators 

## 1.1 - Soldering the Threaded Inserts into the Plate

Flip the plate over so that the underside of the plate is facing you. Press in the PEM threaded inserts into the 11 holes on the plate. 

Pushing PEM nuts in

If it’s too hard to push the inserts in, you can use one of the M3x6 screws to pull the insert in, using a T10 Torx screwdriver. Remove the screw when the insert is all the way in.

Pulling PEM nuts in
Pulled in PEM nuts

With the inserts pushed in, double check that they’re on the correct side - they should be on the bottom of the plate, not the top. Also, make sure the inserts are all of the way in and fully seated. Then, solder them in place:
Soldered in PEM nuts

It may take some time for your soldering iron to get the nut and plate hot enough to get the solder to flow well. Also, avoid getting solder on the threads. If you get solder on the threads, try running an M3 screw through to clear solder off the threads. If that doesn’t work, you’ll need an M3 tap to remove the solder from the threads.

# 1.2 - (Hotswap Version Only) - Installing the Hotswap Standoffs

Attach the M2 3.5mm long standoffs onto the bottom of the plate using the M2x3mm screws, onto the following marked holes on the plate:

Standoff locations

Screwed in standoffs

[image needed of plate with screwed in standoffs]

# Part 2 - Attaching and Aligning the Key Separators

*On PCBs older than V0.7, the key separators cannot be adjusted after the switches are soldered on without desoldering all your switches. Make sure you get this right before soldering anything!* 

Next, grab the 3D-printed left-key-separator and right-key-separator pieces, and the M2x5 self-tapping screws. These pieces need to attach to the plate before the switches are soldered in.

Key separators

Attach the key separators to the plate using the M2x5 self-tapping screws, via the small holes located in the plate. Use a T6 Torx screwdriver for this. Make sure the screws go in straight! **Do not tighten these all the way - leave them about a ½ turn loose, since we’ll need to adjust and align these in a little bit.** There are 14 screws that need to be attached in total - 6 on the left separator, and 8 on the right separator. 

Key separators

Key separators

Key separators

With the screws in but not tightened fully, do a test fit against the left and right case halves by sliding the plate into the left and right case halves. Note that you’ll have to slightly spread apart the right case half to get it past the arrow key cluster. 

Key separators test fit

Attach the plate to the case using M3x10mm screws. Make sure the plate is fully seated against the case.

Key separators test fit

Adjust the separator pieces so that the gaps between the separators and the case halves (marked in orange) are minimal when the plate is slid into the very end of the case halves. There may be a small gap between the two separators (gap marked in pink) - this is normal. 

Plate key separators gap

Flip the assembly over, and tighten the screws that can be accessed:

Plate key separators assembly 4

Remove the case halves, and tighten up the remaining screws:
Plate key separators assembly 5

Put everything back together and do a final check of the gaps. Make any adjustments as necessary. Again, on PCBs older than V0.7, you can’t fix this once the switches are soldered in!

When everything looks good, remove the case halves again, and make sure all the screws are tight. 

# Part 3 - Testing and Soldering Additional Parts on the PCB

# 3.1 - Testing Each Key on the PCB 

Testing the PCB before further assembly is recommended - use a tweezer, metal keycap puller, wire, or unbent paperclip to short the switch opening pins, and a program such as [Aquakeytest](https://geekhack.org/index.php?topic=34670.0) or [Vial](https://get.vial.today/)'s built-in matrix tester to ensure that each key works. 

PCB testing with tweezers

# 3.2 - (Soldered Version Only) - Soldering on the 1KΩ Resistors

Grab the 3 1KΩ resistors and solder them into the spots for R200, R201, and R202, on the top side of the PCB. If you’re using your own LEDs and want them brighter or dimmer, you may want to use different resistors than the provided resistors.

PCB 1K resistors

# 3.3 - Soldering on the Lock LEDs 

Grab the spacer for the LEDs, and run the LEDs legs through it. Place the LEDs and spacers onto the PCB, for spots LED201, LED202, and LED203. Note that the spacer only fits in one way.

PCB lock LEDs

Note that LEDs are directional and will not light up if soldered in backwards. The longer leg on an LED is +. Make sure this matches up with the + symbols on the PCBs. 

LED polarity

Once the LEDs are in, solder them in. Make sure that they’re in straight! 

PCB lock LEDs

If you haven’t already done so, clip the legs on the resistors and LEDs with a pair of flush cutters.

# 3.4 - Soldering the Rotary Encoder 

Next, solder on the rotary encoder onto the top left corner of the PCB.

Rotary encoder

# 3.5 - Soldering on the Reset Switch 
If your PCB did not come with the reset switch soldered on, solder it onto the bottom side of the PCB near the numpad (if you have PCB V0.7 or older), or to the top side of the PCB just to the left of right shift (on PCB V0.8 and newer). 

Reset switch

# 3.6 - (Soldered PCB only) Soldering on the Spring-Loaded Pins 

If you are using PCB V0.7 or newer, solder on the spring-loaded pins, which are soldered to the top side of the PCB on the right side of the keyboard. This is used to electrically ground the plate and the screws on the top of the case so that static shocks do not reset the keyboard microcontroller. If you do not have the spring loaded pins, you can solder a small wire to where the spring loaded pin goes and solder the other end of the wire to the corresponding area on the plate. 

Spring loaded pins 1
Spring loaded pins 2

# Part 4 - Installing Stabilizers and Switches

# 4.1 - Deciding Your Layout

Boston supports the following layout on the soldered PCB:
Soldered PCB supported layouts

The following layouts are supported on the hotswap ANSI PCB:
ANSI HS PCB supported layouts

Decide what layout you want (for example, do you want ANSI Enter, or ISO Enter?), and determine where you’ll need to install stabilizers. Any keys 2 units wide or longer (for example, a standard backspace key) will need stabilizers. Also, make sure you have the keycaps for the layout you want.

## Modding Your Switches and Stabilizers 
If you want to mod or tune your switches or stabilizers (e.g. lubing them, or changing the springs in them), do so before installing them. It is much harder to make any changes after they’re installed. On soldered keyboards, stabilizers cannot be installed or removed after switches are soldered in, without desoldering most or all of your switches.

# 4.2 - Installing the Stabilizers 

Boston takes PCB-mount stabilizers, either screw-in or clip in style. These are available from several manufacturers (e.g. GMK, TX, Cherry, C3, Durock, Zeal, and others make PCB mount-stabilizers).

Install all the stabilizers according to the instructions from their manufacturer.

Stabilizers

# 4.3 - (Hotswap Version Only) - Attaching the PCB to the Plate 

Screw the PCB onto the plate via the 10 standoffs on the plate that were previously attached in Step 1.2. 

[image needed]

# 4.4 - Testing Your Stabilizers 

It’s strongly recommended to test your stabilizers before proceeding, as any fixes to your stabilizers after soldering the switches will likely require removing or desoldering all the switches and removing the plate from the PCB. Test them now, as if there's something wrong with them it will be much more work to fix them later.

To do this, take a switch and an appropriate keycap for the stabilizer you want to test. If you're on the soldered version, you will also need to grab the plate now. 

Install the switch onto the plate and PCB. On the hotswap version, remember  to support the hotswap socket from the back side while inserting the switch, and that the switch pins are straight before inserting it in. On the soldered version - you do not need to solder the switch in yet - just make sure it fits into the PCB. 

Stabilizer testing 1

Install the keycap onto the switch. Make sure the key feels okay - that it’s not binding, or failing to go all the way to the bottom, or failing to return, for instance. Do this for all your stabilizers to make sure that they’ve been installed properly. 

Stabilizer testing 2

# 4.5 - Installing Your Bottom Row 

On the soldered version - we’ll start installing and soldering switches on the bottom row as this is the most likely place that mistakes are made, since the soldered version of Boston supports several different bottom row layouts, and it's easy to accidentally put a switch in the wrong place. You can also start here on the hotswap version, though due to the more restricted bottom row layout you're much less likely to make mistakes here.

Both the plate and PCB on the soldered version are marked with where to put the switches in for your desired bottom row positions. The arrows point at the center of the switch. Install switches into the desired positions on the bottom row. Make sure that the switches are fully seated into the plate. 

After installing the switches into the plate, and before soldering the switches, install keycaps on your bottom row to ensure that everything is in the correct place. Make any fixes as necessary. 

Bottom row testing

If everything looks correct, solder the switches in.

# 4.6 - Install the Rest of the Switches

Solder or install the rest of your switches.

# Part 5 - Case Prep and Assembly

# Part 5.1 - Installing the M3 Hex Nuts into the Case

Take the left and right case halves from earlier, and the M3 hex nuts. Push the hex nuts into the 6 hex-shaped pockets on the bottom of each case half. If it’s difficult to push them in, you can use an M3x6 screw to pull the nuts in. If the nuts fit in loosely and fall out easily, glue them in with super glue or hot glue.

Pushing M3 nuts into case

# Part 5.2 - Installing the Case Halves 

Take the left and right case halves and slide them onto the plate, and screw them into the plate using M3x10 screws. **Do not tighten these down all the way - leave them about 1 turn loose, as we need to align them later.** For the right case half, you’ll have to spread the case apart slightly to get it past the arrow key cluster.

Case half install 1
Case half install 2
Case half install 3

# Part 5.3 - Installing the Bottom Panel and Rubber Feet 

Flip everything over, and install the bottom panel. With PCB V0.7 and older, you need to place the bottom panel in the orientation shown (if you get it backwards, the reset switch will not be accessible). On PCB revision V0.8 or older, you can install the bottom panel in either orientation as the reset button has moved to the top side.

Install M3x6 screws in the middle 8 holes to secure the bottom panel. Avoid pushing down on the screwdriver as this can cause the hex nut on the other side to push out and fall out (and you’ll have to take the case back apart to retrieve it and reinstall it). Again, don’t tighten these in all the way, but leave them about a turn loose.

Case bottom panel install

Take the FR4 rubber feet holders and install them on the ends using M3x10 screws. Again, avoid pushing down on the screwdriver. Tighten these screws in all the way. 

FR4 bottom feet holder install

Once the rubber feet holders are installed, peel the rubber feet off from the backing sheet and stick them onto the four corners.

Rubber feet install
Rubber feet install

# Part 5.4 - Leveling the Keyboard 

Next, take the keyboard and place it right-side up over a flat, level surface. Take your palm or forearm, and push the keyboard down against your flat, level surface, and tighten all the exterior case screws. This is to make sure the case and feet are flat and do not wobble. 

Leveling

Once this is done, press down on the corners of the keyboard and make sure the keyboard doesn’t wobble or see-saw. If it still does, make adjustments as necessary. There may be a slight misalignment between the left and right case halves after this adjustment - this is normal, as unfortunately 3D printing is a relatively imprecise process. If there is unresolvable wobble or misalignment, you may need to adjust the frame alignment on your 3D printer and reprint the parts.

After all this, install the knob and keycaps. Plug the keyboard into a computer and check that it works (it may take a couple of seconds for the keyboard to initialize). You’re done!

You are done!

# Appendix 1 - Remapping keys 

If you purchased your keyboard from a vendor, your keyboard comes with a default keymap and [Vial](https://get.vial.today/) 0.6 firmware installed. [Vial](https://get.vial.today/) is an open-source alternative to VIA, and allows you to remap keys without reflashing your keyboard. Instructions on how to use Vial are [here](https://get.vial.today/manual/first-use.html)

These are the default key assignments:
Default key assignments

# Appendix 2 - Flashing Firmware 

If you bought the PCB directly from a PCB fab, or if you wish to flash a different firmware other than Vial, please follow the following steps. You’ll also need a second keyboard for the flashing process.

## 2.1 - Gabbing the .bin fFle

Before flashing, you will need to have the .bin file for your firmware. Make sure that the .bin file is compiled for the Boston. The 3D-printed Boston and the CNC version of the Boston use the same firmware files. 

* The default Vial .bin file is avialable on Github [here](https://github.com/bluepylons/Boston/blob/main/Boston%20-%20Current%20design/boston_vial.bin). 
* If you are compiling QMK or Vial, the .bin file should be produced when compilation is done. Often, this file is in your Home folder or wherever the output of your compiler is set to. 
* The Vial source files are on [Vial's Github repo](https://github.com/vial-kb/vial-qmk/tree/vial/keyboards/boston). Likewise, the QMK source files are on [QMK's Github repo](https://github.com/qmk/qmk_firmware/tree/master/keyboards/boston)
* Instructions for setting up a QMK build environment are available from QMK [here](https://github.com/qmk/qmk_firmware/blob/master/docs/newbs_getting_started.md)

## 2.2 - Installing Drivers and QMK Toolbox 

You’ll need to install drivers to communicate with the keyboard’s microcontroller properly. This can be done with a tool called [Zadig](https://zadig.akeo.ie/) on Windows. It is unclear if this is needed for other OS'es (such as Linux or MacOS)

Open Zadig:
Zadig-1

Select “List All Devices” in the Options Menu 
Zadig-2

Select “STM32 Bootloader” in the dropdown menu:
Zadig-3

Select WinUSB here:
Zadig-4

Click the "Replace Driver" button.

Wou will also needed to download [QMK Toolbox](https://github.com/qmk/qmk_toolbox/releases) for your OS. 

## 2.2 - Finding the Reset Button 

The reset button location varies depending on the version you have. On PCB V0.7 and older, the reset button is located on the underside of the PCB. You can press it by inserting an unbent paperclip or a small screwdriver through the following hole on the bottom panel and pushing the switch. 

Reset button location on V0.7J and older

On PCB V0.8 and newer, the reset button is on the top side of the PCB, next to the Right Shift key. You will need to take off the Right Shift keycap to access it.

Reset button location on V0.8 and newer

## 2.3 - Pressing the Reset Button to Enter Bootloader Mode 

Plg your keyboard in. 

If you have a PCB variant older than V0.6 (such as V0.5.2), a simple press of the reset button is sufficient to enter Bootloader mode.

On PCB variants V0.6 and newer, hold down the reset button for at least 5 seconds to Enter bootloader mode.

## 2.4 - Opening QMK Toolbox 

Open QMK Toolbox. “STM32 DFU device connected” should appear in yellow. If that text isn’t there, press the reset switch on your keyboard according to the instruction earlier. 
QMK-Toolbox-1

Press “Open” and navigate to the location of your .bin file.
QMK-Toolbox-2

Press the Flash button. Do not disconnect the keyboard until it is done flashing, or you may permanently brick your keyboard.
QMK-Toolbox-3

Once your flash is complete, your keyboard with the .bin file you flashed should be ready for use!

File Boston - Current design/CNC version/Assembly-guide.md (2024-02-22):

# Assembly guide for S1 DB variants (work in progress) 

# Before You Start 
* Please read the entirety of this guide before you begin.
* Do not use strong chemicals such as acetone to wipe down the PCB. This may cause damage.
* Observe basic ESD (Electrostatic Discharge) handling procedures while assembling the keyboard to avoid permanent damage to the PCB. All ESD protection is provided by the daughterboard, and the PCB does not have ESD protection while not connected to the daughterboard. 
	* Wear a properly-grounded ESD wrist strap while you are assembling the board.
	* Touch a grounded metal object before you begin handling the PCB to reduce risk of ESD damage, and touch a grounded metal object regularly to discharge any ESD buildup.
	* Avoid wearing clothing (e.g. wool sweaters, socks) that can cause ESD buildup
	* Avoid working on a carpeted surface.
	* A very basic guide to ESD procedures is available [here](https://www.wikihow.com/Ground-Yourself-to-Avoid-Destroying-a-Computer-with-Electrostatic-Discharge). 
* Soldering can be hazardous.
	* Wear safety glasses while soldering - hot droplets of flux may fly towards you while you are soldering.
	* The hot tip of a soldering iron can cause serious burns
	* Use a fume extractor while soldering, or soder in a well-ventilated space. Flux fumes can be hazardous and can cause long-term long issues
	* Lead-free solder is strongly recommended. If you are using leaded solder, take measures to avoid lead contamination. According to the [US Centers for Disease Control](https://www.cdc.gov/niosh/topics/lead/safe.html), "washing skin with standard soap and water is not enough to remove lead residues", and you may need to use special lead removal wipes such as D-lead®, or wear gloves while handling leaded solder. 
* Do not overtighten screws - this can strip the screw head or the screw threads, and cause other damage. 

# The parts you'll need 

 [picture of the parts]

Acquiring parts is covered by the [ordering guide](https://github.com/bluepylons/Boston/blob/main/Boston%20-%20Current%20design/CNC%20version/README.md)

## Parts you'll need to assemble the keyboard.
* MX-compatible switches. If you are using the fixed-layout plate, you will need 121 switches. For the universal plate, you will need between 119 and 127 switcehs depending on the layout you choose.
* Keycaps of your choice. Make sure that they support your desired layout.
* PCB-mount stabilizers of the correct size and quantity for your preferred layout. PCB
screw-in stabilizers are recommended, but PCB snap-in will work. For the fixed-layout plate you will need 6 2u stabilizers and 1 6.25u stabilizer.
* A USB-C cable
* A knob. The included encoder has a 6mm diameter D-shaft with a 4.5mm flat. Most knobs meant for 6mm shafts, that either have the flat or use a set screw for mounting, and are smaller than 21mm in diameter, will work.
* (optional - also warning that the backlight feature has not been tested on the V0.6 PCBs) Through-hole LEDs for backlighting. Check that your switches and keycaps support the LEDs you choose - some switches only work with SMD LEDs (which are not supported on this PCB), and others may hit your keycaps.

# Tools you'll need
| Description |  Used for |
| --- | --- |
| 2.5mm hex key or bit ("Allen key") | All M3 screws |
| Soldering iron and solder | For soldering everything |
| Flush cutters | For cutting legs off soldered LEDs and resistors |
| Tweezer, metal keycap puller, wire, or unbent paperclip | Testing the PCB without switches |

# Part 1 - Preparing the PCB 

## 1.1 - Basic ESD and safety precautions 
As the PCB lacks ESD protection when the daughterboard is not connected, observe basic ESD protection procedures. Otherwise, you risk damaging the PCB. 

* Wear a properly grounded metal ESD strap when handling the PCB and when assembling the keyboard 
* Avoid wearing clothing (such as thick wool sweaters or socks) or working on surfaces (e.g. carpet) that are prone to generating static electricity. 
* Touch a grounded metal object before handling the PCB, and regularly while you are working. Common grounded metal objects include metal appliances that are plugged in with a 3-prong plug, computers  that are plugged in with a 3-prong plug, any exposed metal on cables that protrude out of said computers (e.g. USB cables), and metal sinks and faucets. Doorknobs are not grounded and are not a good place to discharge static. 

For soldering, wear eye protection while soldering, and make sure that your space is well ventilated to avoid breathing in flux fumes. 

## 1.2 - Soldering on the reset switch. 

Solder the reset switch onto the top side of the PCB, next to Right Shift. Depending on where you obtained the PCB, this might already be soldered on for you.

 [picture of the reset switch soldered on]

## 1.3 - Installing software for flashing the firmware

If you ordered the PCB directly from a PCB fab, it likely won't have the firmware installed on it. 

To flash the firmware, you'll have to install a few pieces of software.

If you are on Windows, you'll want to install drivers. This can be done with a tool called [Zadig](https://zadig.akeo.ie/). 

a.) Install and open Zadig:
Zadig Step 1

b.) Select "List All Devices" in the Options Menu :
Zadig Step 2

c.) Select "STM32 Bootloader" in the dropdown menu:
Zadig Step 3

d.) Select WinUSB here:
Zadig Step 4

e.) Click the Replace Driver button. This will install the driver. 

f.) After Zadig is installed, install [QMK Toolbox](https://github.com/qmk/qmk_toolbox). Download links are at the bottom of the page.

g.) Download the .bin Vial firmware file [here](https://github.com/bluepylons/Boston/blob/main/Boston%20-%20Current%20design/boston_vial.bin) 
 
## 1.4 - Flashing the Firmware 

a.) Connect the USB-C daughterboard to the PCB using the JST cable. Remove any metal or other conductive objects from the vicinity to reduce the risk of the PCB getting shorted, and be careful to avoid letting the daughterboard touch the PCB (as that can also cause a short circuit). 

b.) Connect the daughterboard to your computer. The PCB and daughterboard will receive power, and will be vulnerable to short circuits, so continue to be careful. 

c.) Open QMK Toolbox. 

d.) Hold down the reset button for at least 5 seconds, and then release it. In QMK Toolbox, "STM32 DFU device connected" should appear in yellow.
QMK Toolbox Step 1

e.) Press "Open" in QMK Toolbox and navigate to the location of your .bin firmware file. 
QMK Toolbox Step 2

f.) Press the Flash button. Do not disconnect the keyboard until it is done flashing, or you may permanently brick your keyboard. 
QMK Toolbox Step 3

## 1.5 - Testing your PCB 

Use a tweezer, metal keycap puller, wire, or unbent paperclip to short the switch opening pins, and a program such as [Aquakeytest](https://geekhack.org/index.php?topic=34670.0) to ensure that each key works. 

Disconnect the daughterboard from the PCB once you're done.

## 1.6 - Soldering on the lock LEDs and resistors 

If you have a soldered PCB, solder on the 3 1KΩ resistors onto the positions for R200, R201, and R202. 1KΩ is a comfortable value, but if you want your LEDs brighter or dimmer you may wish to use different resistors. Resistors are not directional and will work soldered in either direction. The hotswap PCB has these pre-soldered on so you will not need to solder on the resistors.

Resistors

Next up, we want to do the lock LEDs (on both the hotswap and soldered PCBs). Note that LEDs are directional and will not light up if soldered in backwards. The longer leg on an LED is +. Make sure this matches up with the + symbols on the PCBs.
LED-legs-labelled

Solder the lock LEDs through the LED spacer as shown - the LED spacer only fits on one way. 
LEDs in spacer
LEDs soldered on

## 1.7 - Soldering on the rotary encoder 

Solder on the rotary encoder on the upper left of the PCB. Make sure you solder this to the top side of the PCB. 

# Part 2 - Preparing the case 

## 2.1 - Installing the rubber feet 
Peel the backing paper off the rubber feet and stick them in the circular pockets on the bottom of the case. 

[image] 

## 2.2 - Installing the RGBLED light pipe 

a.) Press the light pipe into the hole meant for the light pipe on the upper left of the case top. 
Light pipe installation

b.) Flip the case top over. Slip the rubber light pipe retainer onto the back of the light pipe, and move it down so that it prevents the light pipe from falling out. If you want, you can glue the RGBLED light pipe and retainer, using hot glue, epoxy, or another adhesive. 
Light pipe retainer installation

Light pipe retainer installed

# Part 3 - Installing the Daughterboard 

a.) Plug the daughterboard cable into the daughterboard. 
[image]

b.) Using 2 M3x5 screws, screw the daugherboard into the bottom case. 
[image] 

# Part 4 - Switches and stabilizers 

## 4.1 - Installing your stabilizers

If you want to lube or otherwise tune your stabilizers, do so before installing them. It is much harder to make any changes after they're installed, and stabilizers cannot be installed or removed after the switches are installed or soldered in. You will need to remove or desolder most or all of your switches in order to remove the stabilizers once your keyboard is assembled.

Install all stabilizers according to the instructions from their manufacturer. Insulation washers are not necessary. 

After installing your stabilizers, briefly test them. To do this, take the plate, a switch, and the appropriate keycap for the stabilizer you want to test, and install them over the PCB (without soldering the switch in). Make sure the key feels okay - that it’s not binding, or failing to go all the way to the bottom, or failing to return, for instance. Do this for all your stabilizers to make sure that they’ve been installed properly.

## 4.2 - Installing and soldering your switches

If you want to modify or tune your switches (e.g. by lubing, changing springs, etc.), do so before installing them. 

Install the switches into the plate and solder them, like you would when building any other custom keyboard.

If you are using the universal plate, test your bottom row with keycaps before proceeding, as it is easy to make mistakes here. Install keycaps on the bottom row to make sure that it's correct before soldering. 

Solder all your switches.

# Part 5 - Everything comes together

## 5.1 - Installing the plate and PCB assembly

Screw the plate to the top case using the M3 x 5mm screws. 
Screwing in the plate

## 5.2 - Connecting the daughterboard

With the top case and PCB near the bottom case (avoid accidentally tugging on the daughterboard cable as this can damage the cable or rip the connector off the daughterboard or PCB) - connect the daughterboard cable to the main PCB. 

[image] 

## 5.3 - Screwing everything together

Again, being careful to avoid tugging on the daughterboard cable - set the case top onto the case bottom. Flip everything over. Place M3x10 screws on the front four screw holes, and M3x16 screws on the rear four screw holes. Tighten those screws to screw the top and bottom cases together. 
Screwing case together

## 5.4 - Installing your knob and keycaps. 

Next, flip the keyboard back over and install your keycaps and knob. 

Some knobs slip on, and some use a set screw which you must line up with the flat part the D-shaft . You may need a spacer with some knobs. 

You are done!

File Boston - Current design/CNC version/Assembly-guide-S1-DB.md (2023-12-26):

# Assembly guide for S1 DB variants (work in progress) 

# Before You Start 
* Please read the entirety of this guide before you begin.
* Do not use strong chemicals such as acetone to wipe down the PCB. This may cause damage.
* Observe basic ESD (Electrostatic Discharge) handling procedures while assembling the keyboard to avoid permanent damage to the PCB. All ESD protection is provided by the daughterboard, and the PCB does not have ESD protection while not connected to the daughterboard. 
	* Wear a properly-grounded ESD wrist strap while you are assembling the board.
	* Touch a grounded metal object before you begin handling the PCB to reduce risk of ESD damage, and touch a grounded metal object regularly to discharge any ESD buildup.
	* Avoid wearing clothing (e.g. wool sweaters, socks) that can cause ESD buildup
	* Avoid working on a carpeted surface.
	* A very basic guide to ESD procedures is available [here](https://www.wikihow.com/Ground-Yourself-to-Avoid-Destroying-a-Computer-with-Electrostatic-Discharge). 
* Soldering can be hazardous.
	* Wear safety glasses while soldering - hot droplets of flux may fly towards you while you are soldering.
	* The hot tip of a soldering iron can cause serious burns
	* Use a fume extractor while soldering, or soder in a well-ventilated space. Flux fumes can be hazardous and can cause long-term long issues
	* Lead-free solder is strongly recommended. If you are using leaded solder, take measures to avoid lead contamination. According to the [US Centers for Disease Control](https://www.cdc.gov/niosh/topics/lead/safe.html), "washing skin with standard soap and water is not enough to remove lead residues", and you may need to use special lead removal wipes such as D-lead®, or wear gloves while handling leaded solder. 
* Do not overtighten screws - this can strip the screw head or the screw threads, and cause other damage. 

# The parts you'll need 

 [picture of the parts]

Acquiring parts is covered by the [ordering guide](https://github.com/bluepylons/Boston/blob/main/Boston%20-%20Current%20design/CNC%20version/README.md)

## Parts you'll need to assemble the keyboard.
* MX-compatible switches. If you are using the fixed-layout plate, you will need 121 switches. For the universal plate, you will need between 119 and 127 switcehs depending on the layout you choose.
* Keycaps of your choice. Make sure that they support your desired layout.
* PCB-mount stabilizers of the correct size and quantity for your preferred layout. PCB
screw-in stabilizers are recommended, but PCB snap-in will work. For the fixed-layout plate you will need 6 2u stabilizers and 1 6.25u stabilizer.
* A USB-C cable
* A knob. The included encoder has a 6mm diameter D-shaft with a 4.5mm flat. Most knobs meant for 6mm shafts, that either have the flat or use a set screw for mounting, and are smaller than 21mm in diameter, will work.
* (optional - also warning that the backlight feature has not been tested on the V0.6 PCBs) Through-hole LEDs for backlighting. Check that your switches and keycaps support the LEDs you choose - some switches only work with SMD LEDs (which are not supported on this PCB), and others may hit your keycaps.

# Tools you'll need
| Description |  Used for |
| --- | --- |
| 2.5mm hex key or bit ("Allen key") | All M3 screws |
| Soldering iron and solder | For soldering everything |
| Flush cutters | For cutting legs off soldered LEDs and resistors |
| Tweezer, metal keycap puller, wire, or unbent paperclip | Testing the PCB without switches |

# Part 1 - Preparing the PCB 

## 1.1 - Basic ESD and safety precautions 
As the PCB lacks ESD protection when the daughterboard is not connected, observe basic ESD protection procedures. Otherwise, you risk damaging the PCB. 

* Wear a properly grounded metal ESD strap when handling the PCB and when assembling the keyboard 
* Avoid wearing clothing (such as thick wool sweaters or socks) or working on surfaces (e.g. carpet) that are prone to generating static electricity. 
* Touch a grounded metal object before handling the PCB, and regularly while you are working. Common grounded metal objects include metal appliances that are plugged in with a 3-prong plug, computers  that are plugged in with a 3-prong plug, any exposed metal on cables that protrude out of said computers (e.g. USB cables), and metal sinks and faucets. Doorknobs are not grounded and are not a good place to discharge static. 

For soldering, wear eye protection while soldering, and make sure that your space is well ventilated to avoid breathing in flux fumes. 

## 1.2 - Soldering on the reset switch. 

Solder the reset switch onto the top side of the PCB, next to Right Shift.

 [picture of the reset switch soldered on]

## 1.3 - Installing software for flashing the firmware

If you ordered the PCB directly from a PCB fab, it likely won't have the firmware installed on it. 

To flash the firmware, you'll have to install a few pieces of software.

If you are on Windows, you'll want to install drivers. This can be done with a tool called [Zadig](https://zadig.akeo.ie/). 

a.) Install and open Zadig:
Zadig Step 1

b.) Select "List All Devices" in the Options Menu :
Zadig Step 2

c.) Select "STM32 Bootloader" in the dropdown menu:
Zadig Step 3

d.) Select WinUSB here:
Zadig Step 4

e.) Click the Replace Driver button. This will install the driver. 

f.) After Zadig is installed, install [QMK Toolbox](https://github.com/qmk/qmk_toolbox). Download links are at the bottom of the page.

g.) Download the .bin Vial firmware file [here](https://github.com/bluepylons/Boston/blob/main/Boston%20-%20Current%20design/boston_vial.bin) 
 
## 1.4 - Flashing the Firmware 

a.) Connect the USB-C daughterboard to the PCB using the JST cable. Remove any metal or other conductive objects from the vicinity to reduce the risk of the PCB getting shorted, and be careful to avoid letting the daughterboard touch the PCB (as that can also cause a short circuit). 

b.) Connect the daughterboard to your computer. The PCB and daughterboard will receive power, and will be vulnerable to short circuits, so continue to be careful. 

c.) Open QMK Toolbox. 

d.) Hold down the reset button for at least 5 seconds, and then release it. In QMK Toolbox, "STM32 DFU device connected" should appear in yellow.
QMK Toolbox Step 1

e.) Press "Open" in QMK Toolbox and navigate to the location of your .bin firmware file. 
QMK Toolbox Step 2

f.) Press the Flash button. Do not disconnect the keyboard until it is done flashing, or you may permanently brick your keyboard. 
QMK Toolbox Step 3

## 1.5 - Testing your PCB 
Use a tweezer, metal keycap puller, wire, or unbent paperclip to short the switch opening pins, and a program such as [Aquakeytest](https://geekhack.org/index.php?topic=34670.0) to ensure that each key works. 

Disconnect the daughterboard from the PCB once you're done.

## 1.6 - Soldering on the lock LEDs and resistors 

If you have a soldered PCB, solder on the 3 1KΩ resistors onto the positions for R200, R201, and R202. 1KΩ is a comfortable value, but if you want your LEDs brighter or dimmer you may wish to use different resistors. Resistors are not directional and will work soldered in either direction. The hotswap PCB has these pre-soldered on so you will not need to solder on the resistors.

Resistors

Next up, we want to do the lock LEDs (on both the hotswap and soldered PCBs). Note that LEDs are directional and will not light up if soldered in backwards. The longer leg on an LED is +. Make sure this matches up with the + symbols on the PCBs.
LED-legs-labelled

Solder the lock LEDs through the LED spacer as shown - the LED spacer only fits on one way. 
LEDs in spacer
LEDs soldered on

## 1.7 - Soldering on the rotary encoder 

Solder on the rotary encoder on the upper left of the PCB. Make sure you solder this to the top side of the PCB. 

# Part 2 - Preparing the case 

## 2.1 - Installing the rubber feet 
Peel the backing paper off the rubber feet and stick them in the circular pockets on the bottom of the case. 

[image] 

## 2.2 - Installing the RGBLED light pipe 

a.) Press the light pipe into the hole meant for the light pipe on the upper left of the case top. 
Light pipe installation

b.) Flip the case top over. Slip the rubber light pipe retainer onto the back of the light pipe, and move it down so that it prevents the light pipe from falling out. If you want, you can glue the RGBLED light pipe and retainer, using hot glue, epoxy, or another adhesive. 
Light pipe retainer installation

Light pipe retainer installed

# Part 3 - Installing the Daughterboard 

a.) Plug the daughterboard cable into the daughterboard. 
[image]

b.) Using M3x5 screws, screw the daugherboard into the bottom case. 
[image] 

# Part 4 - Switches and stabilizers 

## 4.1 - Installing your stabilizers

If you want to lube or otherwise tune your stabilizers, do so before installing them. It is much harder to make any changes after they're installed, and stabilizers cannot be installed or removed after the switches are soldered in. You will need to desolder most or all of your switches in order to remove the stabilizers once your keyboard is assembled.

Install all stabilizers according to the instructions from their manufacturer. Insulation washers are not necessary. 

After installing your stabilizers, briefly test them. To do this, take the plate, a switch, and the appropriate keycap for the stabilizer you want to test, and install them over the PCB (without soldering the switch in). Make sure the key feels okay - that it’s not binding, or failing to go all the way to the bottom, or failing to return, for instance. Do this for all your stabilizers to make sure that they’ve been installed properly.

## 4.2 - Installing and soldering your switches

If you want to modify or tune your switches (e.g. by lubing, changing springs, etc.), do so before installing them. 

Install the switches into the plate and solder them, like you would when building any other custom keyboard.

If you are using the universal plate, test your bottom row before proceeding, as it is easy to make mistakes here. Install keycaps on the bottom row to make sure that it's correct before soldering. 

Solder all your switches.

# Part 5 - Everything comes together

## 5.1 - Installing the plate and PCB assembly

Screw the plate to the top case using the M3 x 5mm screws. 
Screwing in the plate

## 5.2 - Connecting the daughterboard

With the top case and PCB near the bottom case (avoid accidentally tugging on the daughterboard cable as this can damage the cable or rip the connector off the daughterboard or PCB) - connect the daughterboard cable to the PCB. 

[image] 

## 5.3 - Screwing everything together

Again, being careful to avoid tugging on the daughterboard cable - set the case top onto the case bottom. Flip everything over. Place M3x10 screws on the front four screw holes, and M3x16 screws on the rear four screw holes. Tighten those screws to screw the top and bottom cases together. 
Screwing case together

## 5.4 - Installing your knob and keycaps. 

Next, flip the keyboard back over and install your keycaps and knob. 

Some knobs slip on, and some use a set screw which you must line up with the flat part the D-shaft . You may need a spacer with some knobs. 

You are done!

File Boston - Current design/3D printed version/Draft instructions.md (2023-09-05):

# Boston (3D-printed/FR4 version) Assembly Instructions, including 3D printing 

## Draft. work-in-progress, incomplete (August 7, 2023)

## To Do

* Instructions on how to solder per-key LEDs (soldered version only - the hotswap version does not have the per-key LEDs)

## Errata

* If you are using split 1u numpad + and =, the + and = are reversed in Vial, QMK, and in the key diagram. For now just assign the key you want to + to =, and vice versa.

# Table of Contents

Before You Start
What’s in the box:
Part 1: 3D-printing the case parts
Part 2: Putting Together The Plate and Key Separators
Part 3: Soldering Additional Parts on the PCB
Part 4: installing stabilizers and switches
Part 5 - Case Prep and Assembly
Part 6: Flashing Firmware
Appendix:

# Before You Start 
* Boston is an open-source keyboard project. Follow these assembly instructions at your own risk. 
* Please read the entirety of this guide before you begin. The assembly process for the 3D-printed version of Boston is a bit atypical.
* The 3D printed key separators must be installed onto the plate before the switches are soldered on. If you have the plate and PCB but do not have the 3D printed parts yet - do not solder your switches on yet.  
* If you purchased a kit from a vendor, some of the steps may have already been done for you by the vendor. 
* Do not use strong chemicals such as acetone to wipe down any part of the case or PCB. This may cause damage. 
* The PCB has an ESD protection chip to provide some protection when it is fully assembled, but cannot protect the keyboard while you are building it. Please observe basic procedures to prevent damage from electrostatic discharge (ESD) while handling the PCB or assembling the keyboard.
    * Wear a properly-grounded ESD wrist strap while you are assembling the board.
    * Touch a grounded metal object before you begin handling the PCB to reduce risk of ESD damage, and touch a  grounded metal object regularly to discharge any ESD buildup. 
    * Avoid wearing clothing (e.g. wool sweaters, socks) that can cause ESD buildup
    * Avoid working on a carpeted surface. 
    * A guide on basic ESD procedures is available [here](https://www.wikihow.com/Ground-Yourself-to-Avoid-Destroying-a-Computer-with-Electrostatic-**Discharge**). 
* Soldering can be hazardous
  * Wear safety glasses while soldering! Hot droplets of flux may fly towards you while you are soldering.
  * The hot tip of a soldering iron can cause serious burns.
  * Use a fume extractor while soldering, or solder in a well-ventilated space. Flux fumes can be hazardous and can cause long-term lung issues. 
* Do not overtighten the screws! This can strip the head or the threads and cause other damage.
  
# What You Should Have:
* The PCB:
[image needed of PCB]
* The FR4 fiberglass plate: 
FR4 fiberglass plate
* The FR4 bottom panel:
FR4 bottom panel
* 3x 3mm LEDs:
3mm LEDs
* (soldered version only) 3x 1KΩ resistors:
1K resistors
* A rotary encoder. Your vendor may also include a knob.
Encoder
* 15 M3x10mm screws:
M3x10mm screws
* 8 M3x6mm screws:
M3x6mm screws
* 11 M3 PEM KF2-M3-ET threaded inserts:
PEM KF2-M3-ET threaded inserts
* 12 M3 hex nuts:
M3 hex nuts
* 14 M2x5mm self-tapping screws:
M2x5mm self-tapping screws
* A reset switch (note on some PCBs this is already soldered on, and won’t be included as a result):
Reset switch
* (soldered version only) A set of spring loaded pins (note on some PCBs this is already soldered on, and won’t be included as a result. You can also substitute this with a short piece of wire):
[image needed of spring loaded pins]
* (hotswap version only) 10 M2 3.5mm long standoffs:
[image needed of 3.5mm long standoffs]
* (hotswap version only) 20 M2x3mm screws: 
[image needed of M2x3mm screws]

If you purchased the kit from a vendor, note that some of the components may have already been soldered on. Please inform your vendor if any of the above is missing. 

# 3D-Printed Parts
Your vendor might have included these, or you may need to print these yourself. See [Part 0 - 3D printing the case parts](#part-0---3d-printing-the-case-parts) for information on how to print these parts.

* The left and right case halves:
3D printed case halves

* The left key separator:
3D printed left key separator

* The right key separator:
3D printed right key separator

* The 3D-printed spacer for the lock LEDs:
3D printed lock LED spacer

# Parts You'll Need to Assemble the Keyboard
* MX-compatible switches. Depending on the layout you choose, you will need between 119 and 127 switches. 
* Keycaps of your choice. Make sure that they support your desired layout. 
* PCB-mount stabilizers (either screw-in or snap-in) of the correct size and quantity for your preferred layout. 
* A USB-C cable 
* A knob. The included encoder has a 6mm diameter D-shaft with a 4.5mm flat. Most knobs meant for 6mm shafts, that either have the flat or use a set screw for mounting, and are smaller than 21mm in diameter, will work.
* (optional) Through-hole LEDs for backlighting. Check that your switches and keycaps support the LEDs you choose - some switches only work with SMD LEDs (which are not supported on this PCB), and others may hit your keycaps. 

# Tools You'll Need to Assemble the Keyboard 
* A T6 Torx screwdriver or key. Make sure it is actually a T6 size!. A smaller bit may fit in the head, but is much more likely to strip the head. 
* A T10 torx screwdriver or key. Likewise, make sure it is actually a T10 size. 
* A pair of metal tweezers, wire, metal keycap puller, or unbent paper clip for testing the PCB 
* (hotswap only) A #1 Philips screwdriver. Make sure it's actually a #1 size. 
* A soldering iron and solder. 
* Super glue 
* A blue threadlocker, such as Loctite 242, 243, or 248, is recommended to prevent screws from loosening over time. 
* If you make mistakes while soldering parts in, you may need a desoldering pump (solder sucker) or desoldering wick to make fixes. 

# (Hotswap Only) - A Note on Hotswap Switch Installation

* Only use switches that have never been soldered. Desoldered switches can damage the hotswap socket.
* Make sure the pins are straight before inserting the switch 
* Support the back side of the hotswap socket when inserting switches. 

[image needed on how to support hotswap switches - similar to Novelkey's [diagram](https://cdn.shopify.com/s/files/1/3099/8088/files/Group_686_2x_cd694deb-8455-4dc1-82ed-5332ea2de4f6.png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) on [their instruction guides](https://novelkeys.com/pages/howto)]

# Part 0 - 3D Printing the Case Parts 

You will need to 3D-print the parts listed in [# 3D printed parts](#-3D-printed-parts). STL files for 3D printing are available on Github [here](https://github.com/bluepylons/Boston/tree/main/Boston%20-%20Current%20design/3D%20printed%20version/STLs). You will need a 3D printer with a minimum 200mm x 150mm bed x 210mm tall.

For the left and right case halves, printing with the long side facing up, like so, is recommended.
Case halve orientation

You may also want to adjust the Z-seam setting to prevent seams from being in highly visible places. Generally, you should try to locate the Z-seam at the bottom of the case, preferably in an inside corner.

For the key separators, the following orientation is recommended, with the rounded edges facing up: 
Key separators orientation

# Part 1 - Putting Together The Plate and Key Separators 

## 1.1 - Soldering the Threaded Inserts into the Plate

Flip the plate over so that the underside of the plate is facing you. Press in the PEM threaded inserts into the 11 holes on the plate. 

Pushing PEM nuts in

If it’s too hard to push the inserts in, you can use one of the M3x6 screws to pull the insert in, using a T10 Torx screwdriver. Remove the screw when the insert is all the way in.

Pulling PEM nuts in
Pulled in PEM nuts

With the inserts pushed in, double check that they’re on the correct side - they should be on the bottom of the plate, not the top. Also, make sure the inserts are all of the way in and fully seated. Then, solder them in place:
Soldered in PEM nuts

It may take some time for your soldering iron to get the nut and plate hot enough to get the solder to flow well. Also, avoid getting solder on the threads. If you get solder on the threads, try running an M3 screw through to clear solder off the threads. If that doesn’t work, you’ll need an M3 tap to remove the solder from the threads.

# 1.2 - (Hotswap Version Only) - Installing the Hotswap Standoffs

Attach the M2 3.5mm long standoffs onto the bottom of the plate using the M2x3mm screws, onto the following marked holes on the plate:

Standoff locations

Screwed in standoffs

[image needed of plate with screwed in standoffs]

# Part 2 - Attaching and Aligning the Key Separators

*On PCBs older than V0.7, the key separators cannot be adjusted after the switches are soldered on without desoldering all your switches. Make sure you get this right before soldering anything!* 

Next, grab the 3D-printed left-key-separator and right-key-separator pieces, and the M2x5 self-tapping screws. These pieces need to attach to the plate before the switches are soldered in.

Key separators

Attach the key separators to the plate using the M2x5 self-tapping screws, via the small holes located in the plate. Use a T6 Torx screwdriver for this. Make sure the screws go in straight! **Do not tighten these all the way - leave them about a ½ turn loose, since we’ll need to adjust and align these in a little bit.** There are 14 screws that need to be attached in total - 6 on the left separator, and 8 on the right separator. 

Key separators

Key separators

Key separators

With the screws in but not tightened fully, do a test fit against the left and right case halves by sliding the plate into the left and right case halves. Note that you’ll have to slightly spread apart the right case half to get it past the arrow key cluster. 

Key separators test fit

Attach the plate to the case using M3x10mm screws. Make sure the plate is fully seated against the case.

Key separators test fit

Adjust the separator pieces so that the gaps between the separators and the case halves (marked in orange) are minimal when the plate is slid into the very end of the case halves. There may be a small gap between the two separators (gap marked in pink) - this is normal. 

Plate key separators gap

Flip the assembly over, and tighten the screws that can be accessed:

Plate key separators assembly 4

Remove the case halves, and tighten up the remaining screws:
Plate key separators assembly 5

Put everything back together and do a final check of the gaps. Make any adjustments as necessary. Again, on PCBs older than V0.7, you can’t fix this once the switches are soldered in!

When everything looks good, remove the case halves again, and make sure all the screws are tight. 

# Part 3 - Testing and Soldering Additional Parts on the PCB

# 3.1 - Testing Each Key on the PCB 

Testing the PCB before further assembly is recommended - use a tweezer, metal keycap puller, wire, or unbent paperclip to short the switch opening pins, and a program such as [Aquakeytest](https://geekhack.org/index.php?topic=34670.0) or [Vial](https://get.vial.today/)'s built-in matrix tester to ensure that each key works. 

PCB testing with tweezers

# 3.2 - (Soldered Version Only) - Soldering on the 1KΩ Resistors

Grab the 3 1KΩ resistors and solder them into the spots for R200, R201, and R202, on the top side of the PCB. If you’re using your own LEDs and want them brighter or dimmer, you may want to use different resistors than the provided resistors.

PCB 1K resistors

# 3.3 - Soldering on the Lock LEDs 

Grab the spacer for the LEDs, and run the LEDs legs through it. Place the LEDs and spacers onto the PCB, for spots LED201, LED202, and LED203. Note that the spacer only fits in one way.

PCB lock LEDs

Note that LEDs are directional and will not light up if soldered in backwards. The longer leg on an LED is +. Make sure this matches up with the + symbols on the PCBs. 

LED polarity

Once the LEDs are in, solder them in. Make sure that they’re in straight! 

PCB lock LEDs

If you haven’t already done so, clip the legs on the resistors and LEDs with a pair of flush cutters.

# 3.4 - Soldering the Rotary Encoder 

Next, solder on the rotary encoder onto the top left corner of the PCB.

Rotary encoder

# 3.5 - Soldering on the Reset Switch 
If your PCB did not come with the reset switch soldered on, solder it onto the bottom side of the PCB near the numpad (if you have PCB V0.7 or older), or to the top side of the PCB to the left right shift (on PCB V0.8 and newer). 

Reset switch

# 3.6 - (Soldered PCB only) Soldering on the Spring-Loaded Pins 

If you are using PCB V0.7 or newer, solder on the spring-loaded pins, which are soldered to the top side of the PCB on the right side of the keyboard. This is used to electrically ground the plate and the screws on the top of the case so that static shocks do not reset the keyboard microcontroller. If you do not have the spring loaded pins, you can solder a small wire to where the spring loaded pin goes and solder the other end of the wire to the corresponding area on the plate. 

Spring loaded pins 1
Spring loaded pins 2

# Part 4 - Installing Stabilizers and Switches

# 4.1 - Deciding Your Layout

Boston supports the following layout on the soldered PCB:
Soldered PCB supported layouts

The following layouts are supported on the hotswap ANSI PCB:
ANSI HS PCB supported layouts

Decide what layout you want (for example, do you want ANSI Enter, or ISO Enter?), and determine where you’ll need to install stabilizers. Any keys 2 units wide or longer (for example, a standard backspace key) will need stabilizers. Also, make sure you have the keycaps for the layout you want.

## Modding Your Switches and Stabilizers 
If you want to mod or tune your switches or stabilizers (e.g. lubing them, or changing the springs in them), do so before installing them. It is much harder to make any changes after they’re installed. On soldered keyboards, stabilizers cannot be installed or removed after switches are soldered in, without desoldering most or all of your switches.

# 4.2 - Installing the Stabilizers 

Boston takes PCB-mount stabilizers, either screw-in or clip in style. These are available from several manufacturers (e.g. GMK, TX, Cherry, C3, Durock, Zeal, and others make PCB mount-stabilizers).

Install all the stabilizers according to the instructions from their manufacturer.

Stabilizers

# 4.3 - (Hotswap Version Only) - Attaching the PCB to the Plate 

Screw the PCB onto the plate via the 10 standoffs on the plate that were previously attached in Step 1.2. 

[image needed]

# 4.4 - Testing Your Stabilizers 

It’s strongly recommended to test your stabilizers before proceeding, as any fixes to your stabilizers after soldering the switches will likely require removing or desoldering all the switches and removing the plate from the PCB. Test them now, as if there's something wrong with them it will be much more work to fix them later.

To do this, take a switch and an appropriate keycap for the stabilizer you want to test. If you're on the soldered version, you will also need to grab the plate now. 

Install the switch onto the plate and PCB. On the hotswap version, remember  to support the hotswap socket from the back side while inserting the switch, and that the switch pins are straight before inserting it in. On the soldered version - you do not need to solder the switch in yet - just make sure it fits into the PCB. 

Stabilizer testing 1

Install the keycap onto the switch. Make sure the key feels okay - that it’s not binding, or failing to go all the way to the bottom, or failing to return, for instance. Do this for all your stabilizers to make sure that they’ve been installed properly. 

Stabilizer testing 2

# 4.5 - Installing Your Bottom Row 

On the soldered version - we’ll start installing and soldering switches on the bottom row as this is the most likely place that mistakes are made, since the soldered version of Boston supports several different bottom row layouts, and it's easy to accidentally put a switch in the wrong place. You can also start here on the hotswap version, though due to the more restricted bottom row layout you're much less likely to make mistakes here.

Both the plate and PCB on the soldered version are marked with where to put the switches in for your desired bottom row positions. The arrows point at the center of the switch. Install switches into the desired positions on the bottom row. Make sure that the switches are fully seated into the plate. 

After installing the switches into the plate, and before soldering the switches, install keycaps on your bottom row to ensure that everything is in the correct place. Make any fixes as necessary. 

Bottom row testing

If everything looks correct, solder the switches in.

# 4.6 - Install the Rest of the Switches

Solder or install the rest of your switches.

# Part 5 - Case Prep and Assembly

# Part 5.1 - Installing the M3 Hex Nuts into the Case

Take the left and right case halves from earlier, and the M3 hex nuts. Push the hex nuts into the 6 hex-shaped pockets on the bottom of each case half. If it’s difficult to push them in, you can use an M3x6 screw to pull the nuts in. If the nuts fit in loosely and fall out easily, glue them in with super glue or hot glue.

Pushing M3 nuts into case

# Part 5.2 - Installing the Case Halves 

Take the left and right case halves and slide them onto the plate, and screw them into the plate using M3x10 screws. **Do not tighten these down all the way - leave them about 1 turn loose, as we need to align them later.** For the right case half, you’ll have to spread the case apart slightly to get it past the arrow key cluster.

Case half install 1
Case half install 2
Case half install 3

# Part 5.3 - Installing the Bottom Panel and Rubber Feet 

Flip everything over, and install the bottom panel. With PCB V0.7 and older, you need to place the bottom panel in the orientation shown (if you get it backwards, the reset switch will not be accessible). On PCB revision V0.8 or older, you can install the bottom panel in either orientation as the reset button has moved to the top side.

Install M3x6 screws in the middle 8 holes to secure the bottom panel. Avoid pushing down on the screwdriver as this can cause the hex nut on the other side to push out and fall out (and you’ll have to take the case back apart to retrieve it and reinstall it). Again, don’t tighten these in all the way, but leave them about a turn loose.

Case bottom panel install

Take the FR4 rubber feet holders and install them on the ends using M3x10 screws. Again, avoid pushing down on the screwdriver. Tighten these screws in all the way. 

FR4 bottom feet holder install

Once the rubber feet holders are installed, peel the rubber feet off from the backing sheet and stick them onto the four corners.

Rubber feet install
Rubber feet install

# Part 5.4 - Leveling the Keyboard 

Next, take the keyboard and place it right-side up over a flat, level surface. Take your palm or forearm, and push the keyboard down against your flat, level surface, and tighten all the exterior case screws. This is to make sure the case and feet are flat and do not wobble. 

Leveling

Once this is done, press down on the corners of the keyboard and make sure the keyboard doesn’t wobble or see-saw. If it still does, make adjustments as necessary. There may be a slight misalignment between the left and right case halves after this adjustment - this is normal, as unfortunately 3D printing is a relatively imprecise process. If there is unresolvable wobble or misalignment, you may need to adjust the frame alignment on your 3D printer and reprint the parts.

After all this, install the knob and keycaps. Plug the keyboard into a computer and check that it works (it may take a couple of seconds for the keyboard to initialize). You’re done!

You are done!

# Appendix 1 - Remapping keys 

If you purchased your keyboard from a vendor, your keyboard comes with a default keymap and [Vial](https://get.vial.today/) 0.6 firmware installed. [Vial](https://get.vial.today/) is an open-source alternative to VIA, and allows you to remap keys without reflashing your keyboard. Instructions on how to use Vial are [here](https://get.vial.today/manual/first-use.html)

These are the default key assignments:
Default key assignments

# Appendix 2 - Flashing Firmware 

If you bought the PCB directly from a PCB fab, or if you wish to flash a different firmware other than Vial, please follow the following steps. You’ll also need a second keyboard for the flashing process.

## 2.1 - Gabbing the .bin fFle

Before flashing, you will need to have the .bin file for your firmware. Make sure that the .bin file is compiled for the Boston. The 3D-printed Boston and the CNC version of the Boston use the same firmware files. 

* The default Vial .bin file is avialable on Github [here](https://github.com/bluepylons/Boston/blob/main/Boston%20-%20Current%20design/boston_vial.bin). 
* If you are compiling QMK or Vial, the .bin file should be produced when compilation is done. Often, this file is in your Home folder or wherever the output of your compiler is set to. 
* The Vial source files are on [Vial's Github repo](https://github.com/vial-kb/vial-qmk/tree/vial/keyboards/boston). Likewise, the QMK source files are on [QMK's Github repo](https://github.com/qmk/qmk_firmware/tree/master/keyboards/boston)
* Instructions for setting up a QMK build environment are available from QMK [here](https://github.com/qmk/qmk_firmware/blob/master/docs/newbs_getting_started.md)

## 2.2 - Installing Drivers and QMK Toolbox 

You’ll need to install drivers to communicate with the keyboard’s microcontroller properly. This can be done with a tool called [Zadig](https://zadig.akeo.ie/) on Windows. It is unclear if this is needed for other OS'es (such as Linux or MacOS)

Open Zadig:
Zadig-1

Select “List All Devices” in the Options Menu 
Zadig-2

Select “STM32 Bootloader” in the dropdown menu:
Zadig-3

Select WinUSB here:
Zadig-4

Click the "Replace Driver" button.

Wou will also needed to download [QMK Toolbox](https://github.com/qmk/qmk_toolbox/releases) for your OS. 

## 2.2 - Finding the Reset Button 

The reset button location varies depending on the version you have. On PCB V0.7 and older, the reset button is located on the underside of the PCB. You can press it by inserting an unbent paperclip or a small screwdriver through the following hole on the bottom panel and pushing the switch. 

Reset button location on V0.7J and older

On PCB V0.8 and newer, the reset button is on the top side of the PCB, next to the Right Shift key. You will need to take off the Right Shift keycap to access it.

Reset button location on V0.8 and newer

## 2.3 - Pressing the Reset Button to Enter Bootloader Mode 

Plg your keyboard in. 

If you have a PCB variant older than V0.6 (such as V0.5.2), a simple press of the reset button is sufficient to enter Bootloader mode.

On PCB variants V0.6 and newer, hold down the reset button for at least 5 seconds to Enter bootloader mode.

## 2.4 - Opening QMK Toolbox 

Open QMK Toolbox. “STM32 DFU device connected” should appear in yellow. If that text isn’t there, press the reset switch on your keyboard according to the instruction earlier. 
QMK-Toolbox-1

Press “Open” and navigate to the location of your .bin file.
QMK-Toolbox-2

Press the Flash button. Do not disconnect the keyboard until it is done flashing, or you may permanently brick your keyboard.
QMK-Toolbox-3

Once your flash is complete, your keyboard with the .bin file you flashed should be ready for use!

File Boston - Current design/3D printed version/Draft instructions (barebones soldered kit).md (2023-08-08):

# Boston (3D-printed/FR4 version) Assembly Instructions, including 3D printing 

## Draft. work-in-progress (August 7, 2023)

## To do

* Instructions on how to solder per-key LEDs 

# Table of contents

Before You Start
What’s in the box:
Part 1: 3D-printing the case parts
Part 2: Putting Together The Plate and Key Separators
Part 3: Soldering Additional Parts on the PCB
Part 4: installing stabilizers and switches
Part 5 - Case Prep and Assembly
Part 6: Flashing Firmware
Appendix:

# Before You Start 
* Boston is an open-source keyboard project. Follow these assembly instructions at your own risk. 
* Please read the entirety of this guide before you begin. The assembly process for the 3D-printed version of Boston is a bit atypical.
* The 3D printed key separators must be installed onto the plate before the switches are soldered on. If you have the plate and PCB but do not have the 3D printed parts yet - do not solder your switches on yet.  
* Do not use strong chemicals such as acetone to wipe down any part of the case or PCB. This may cause damage. 
* The PCB has an ESD protection chip to provide some protection when it is fully assembled, but cannot protect the keyboard while you are building it. Please observe basic procedures to prevent damage from electrostatic discharge (ESD) while handling the PCB or assembling the keyboard.
    * Wear a properly-grounded ESD wrist strap while you are assembling the board.
    * Touch a grounded metal object before you begin handling the PCB to reduce risk of ESD damage, and touch a  grounded metal object regularly to discharge any ESD buildup. 
    * Avoid wearing clothing (e.g. wool sweaters, socks) that can cause ESD buildup
    * Avoid working on a carpeted surface. 
    * A guide on basic ESD procedures is available [here](https://www.wikihow.com/Ground-Yourself-to-Avoid-Destroying-a-Computer-with-Electrostatic-**Discharge**). 
* Soldering can be hazardous
  * Wear safety glasses while soldering! Hot droplets of flux may fly towards you while you are soldering.
  * The hot tip of a soldering iron can cause serious burns.
  * Use a fume extractor while soldering, or solder in a well-ventilated space. Flux fumes can be hazardous and can cause long-term lung issues. 
* Do not overtighten the screws! This can strip the head or the threads and cause other damage.
  
# What's in the box
* The PCB
* The FR4 fiberglass plate
* The FR4 bottom panel
* 3x 3mm LEDs
* (soldered version only) 3x 1KΩ resistors 
* A rotary encoder. Your vendor may also include a knob.
* 15 M3x10mm screws
* 8 M3x6mm screws 
* 11 M3 PEM KF2-M3-ET threaded inserts
* 12 M3 hex nuts
* 14 M2x5mm self-tapping screws 
* A reset switch (note on some PCBs this is already soldered on, and won’t be included as a result)
* A set of spring loaded pins (note on some PCBs this is already soldered on, and won’t be included as a result)
* (hotswap version only) 10 M2 3.5mm long standoffs
* (hotswap version only) 20 M2x3mm screws 

If you purchased the kit from a vendor, please inform your vendor if any of the above is missing. 

# 3D printed parts
Your vendor might have included these, or you may need to print these yourself. See [Part 0 - 3D printing the case parts](#part-0---3d-printing-the-case-parts) for the list of parts.

# Parts you'll need to assemble the keyboard
* MX-compatible switches. Depending on the layout you choose, you will need between 119 and 127 switches. 
* Keycaps of your choice. Make sure that they support your desired layout. 
* PCB-mount stabilizers (either screw-in or snap-in) of the correct size and quantity for your preferred layout. 
* A USB-C cable 
* A knob. The included encoder has a 6mm diameter D-shaft with a 4.5mm flat. Most knobs meant for 6mm shafts, that either have the flat or use a set screw for mounting, and are smaller than 21mm in diameter, will work.
* (optional) Through-hole LEDs for backlighting. Check that your switches and keycaps support the LEDs you choose - some switches only work with SMD LEDs (which are not supported on this PCB), and others may hit your keycaps. 

# Tools you'll need to assemble the keyboard 
* A T6 Torx screwdriver or key. Make sure it is actually a T6 size!. A smaller bit may fit in the head, but is much more likely to strip the head. 
* A T10 torx screwdriver or key. Likewise, make sure it is actually a T10 size. 
* A pair of metal tweezers, wire, metal keycap puller, or unbent paper clip for testing the PCB 
* (hotswap only) A #1 Philips screwdriver. Make sure it's actually a #1 size. 
* A soldering iron and solder. 
* Super glue 
* A blue threadlocker, such as Loctite 242, 243, or 248, is recommended to prevent screws from loosening over time. 
* If you make mistakes while soldering parts in, you may need a desoldering pump (solder sucker) or desoldering wick to make fixes. 

# (hotswap only) - A note on hotswap switch installation

* Only use switches that have never been soldered. Desoldered switches can damage the hotswap socket.
* Make sure the pins are straight before inserting the switch 
* Support the back side of the hotswap socket when inserting switches. 

[graphic]

# Part 0 - 3D printing the case parts 

You will need to 3D-print the following parts. STL files for 3D printing are available on Github [here]. You will need a 3D printer with a minimum 200mm x 150mm bed x 210mm tall.

* The 3D-printed case, which comes in 4 pieces: the left half, right half , left-key-separator, and right-key-separator:

* The 3D-printed spacer for the lock LEDs

For the left and right case halves, printing with the long side facing up, like so, is recommended.

You may also want to adjust the Z-seam setting to prevent seams from being in highly visible places. Generally, you should try to locate the Z-seam at the bottom of the case, preferably in an inside corner.

For the key separators, the following orientation is recommended, with the rounded edges facing up. 

# Part 1 - Putting Together The Plate and Key Separators 

## 1.1 - Soldering the threaded inserts into the plate

Flip the plate over so that the underside of the plate is facing you. Press in the PEM threaded inserts into the 11 holes on the plate. 

If it’s too hard to push the inserts in, you can use one of the M3x6 screws to pull the insert in, using a T10 Torx screwdriver. Remove the screw when the insert is all the way in.

With the inserts pushed in, double check that they’re on the correct side - they should be on the bottom of the plate, not the top. Also, make sure the inserts are all of the way in and fully seated. Then solder, them in place:

It may take some time for your soldering iron to get the nut and plate hot enough to get the solder to flow well. Also, avoid getting solder on the threads. If you get solder on the threads, try running an M3 screw through to clear solder off the threads. If that doesn’t work, you’ll need an M3 tap to remove the solder from the threads.

# 1.2 - (hotswap version only) - installing the hotswap standoffs

Attach the M2 3.5mm long standoffs onto the bottom of the plate using the M2x3mm screws, onto the following marked holes on the plate:

[Plate-standoff-positions.png]

# Part 2 - Attaching and aligning the key separators

*On PCBs older than V0.7, the key separators cannot be adjusted after the switches are soldered on without desoldering all your switches. Make sure you get this right before soldering anything!* 

Next, grab the 3D-printed left-key-separator and right-key-separator pieces, and the M2x5 self-tapping screws.. These pieces need to attach to the plate before the switches are soldered in.

Attach the key separators to the plate using the M2x5 self-tapping screws, via the small holes located in the plate. Use a T6 Torx screwdriver for this. Make sure the screws go in straight! **Do not tighten these all the way - leave them about a ½ turn loose, since we’ll need to adjust and align these in a little bit.** There are 14 screws that need to be attached in total - 6 on the left separator, and 8 on the right separator. 

With the screws in but not tightened fully, do a test fit against the left and right case halves by sliding the plate into the left and right case halves. Note that you’ll have to slightly spread apart the right case half to get it past the arrow key cluster. 

Attach the plate to the case using M3x10mm screws. Make sure the plate is fully seated against the case.

Adjust the separator pieces so that the gaps between the separators and the case halves (marked in orange) are minimal when the plate is slid into the very end of the case halves. There may be a small gap between the two separators (gap marked in pink) - this is normal. 

Flip the assembly over, and tighten the screws that can be accessed:

Remove the case halves, and tighten up the remaining screws:

Put everything back together and do a final check of the gaps. Make any adjustments as necessary. Again, on PCBs older than V0.7, you can’t fix this once the switches are soldered in!

When everything looks good, remove the case halves again, and make sure all the screws are tight. 

# Part 3 - Testing and Soldering Additional Parts on the PCB

# 3.1 - Testing each key on the PCB 

While PCBs have been tested before being shipped, there is a small possibility of damage from shipping. Testing the PCB before further assembly is recommended - use a tweezer, metal keycap puller, wire, or unbent paperclip to short the switch opening pins, and a program such as [Aquakeytest](https://geekhack.org/index.php?topic=34670.0) or [Vial](https://get.vial.today/)'s built-in matrix tester to ensure that each key works. 

# 3.2 - (soldered version only) - Soldering on the 1KΩ resistors

Grab the 3 1KΩ resistors and solder them into the spots for R200, R201, and R202, on the top side of the PCB. If you’re using your own LEDs and want them brighter or dimmer, you may want to use different resistors than the provided resistors.

# 3.3 - Soldering on the lock LEDs 

Grab the spacer for the LEDs, and run the LEDs legs through it. Place the LEDs and spacers onto the PCB, for spots LED201, LED202, and LED203. Note that the spacer only fits in one way.

Note that LEDs are directional and will not light up if soldered in backwards. The longer leg on an LED is +. Make sure this matches up with the + symbols on the PCBs. 

Once the LEDs are in, solder them in. Make sure that they’re in straight! 

If you haven’t already done so, clip the legs on the resistors and LEDs with a pair of flush cutters.

# 3.4 - Soldering the rotary encoder onto the PCB 

Next, solder on the rotary encoder onto the top left corner of the PCB.

# 3.5 - Soldering on the reset switch 
If your PCB did not come with the reset switch soldered on, solder it onto the bottom side of the PCB near the numpad (if you have PCB V0.7 or older), or to the top side of the PCB to the left right shift (on PCB V0.8 and newer). 

# 3.6 - Soldering on the spring-loaded pins 

If you are using PCB V0.7 or newer, solder on the spring-loaded pins, which are soldered to the top side of the PCB on the right side of the keyboard. This is used to electrically ground the plate and the screws on the top of the case. 

# Part 4

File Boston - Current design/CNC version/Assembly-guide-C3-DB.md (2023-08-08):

# Assembly guide (work in progress) 

# Before You Start 
* Please read the entirety of this guide before you begin.
* Do not use strong chemicals such as acetone to wipe down the PCB. This may cause damage.
* Observe basic ESD (Electrostatic Discharge) handling procedures while assembling the keyboard to avoid permanent damage to the PCB. All ESD protection is provided by the daughterboard, and the PCB does not have ESD protection while not connected to the daughterboard. 
	* Wear a properly-grounded ESD wrist strap while you are assembling the board.
	* Touch a grounded metal object before you begin handling the PCB to reduce risk of ESD damage, and touch a grounded metal object regularly to discharge any ESD buildup.
	* Avoid wearing clothing (e.g. wool sweaters, socks) that can cause ESD buildup
	* Avoid working on a carpeted surface.
	* A very basic guide to ESD procedures is available [here](https://www.wikihow.com/Ground-Yourself-to-Avoid-Destroying-a-Computer-with-Electrostatic-Discharge). 
* Soldering can be hazardous.
	* Wear safety glasses while soldering - hot droplets of flux may fly towards you while you are soldering.
	* The hot tip of a soldering iron can cause serious burns
	* Use a fume extractor while soldering, or soder in a well-ventilated space. Flux fumes can be hazardous and can cause long-term long issues
	* Lead-free solder is strongly recommended. If you are using leaded solder, take measures to avoid lead contamination. According to the [US Centers for Disease Control](https://www.cdc.gov/niosh/topics/lead/safe.html), "washing skin with standard soap and water is not enough to remove lead residues", and you may need to use special lead removal wipes such as D-lead®, or wear gloves while handling leaded solder. 
* Do not overtighten screws - this can strip the screw head or the screw threads, and cause other damage. 

# The parts you'll need 

 [picture of the parts]

Acquiring parts is covered by the [ordering guide](https://github.com/bluepylons/Boston/blob/main/Boston%20-%20Current%20design/CNC%20version/README.md)

## Parts you'll need to assemble the keyboard.
* MX-compatible switches. If you are using the fixed-layout plate, you will need 121 switches. For the universal plate, you will need between 119 and 127 switcehs depending on the layout you choose.
* Keycaps of your choice. Make sure that they support your desired layout.
* PCB-mount stabilizers of the correct size and quantity for your preferred layout. PCB
screw-in stabilizers are recommended, but PCB snap-in will work. For the fixed-layout plate you will need 6 2u stabilizers and 1 6.25u stabilizer.
* A USB-C cable
* A knob. The included encoder has a 6mm diameter D-shaft with a 4.5mm flat. Most knobs meant for 6mm shafts, that either have the flat or use a set screw for mounting, and are smaller than 21mm in diameter, will work.
* (optional - also warning that the backlight feature has not been tested on the V0.6 PCBs) Through-hole LEDs for backlighting. Check that your switches and keycaps support the LEDs you choose - some switches only work with SMD LEDs (which are not supported on this PCB), and others may hit your keycaps.

# Tools you'll need
| Description |  Used for |
| --- | --- |
| 2.5mm hex key or bit ("Allen key") | All M3 screws |
| T6 Torx, #1 Philips, 1.3mm, or 1.5mm hex key or bit | M2x5 screws (depends on what screws you buy) for the daughterboard  |
| Soldering iron and solder | For soldering everything |
| Flush cutters | For cutting legs off soldered LEDs and resistors |
| A vise, a C-clamp, a hammer, locking pliers ("Vise grips"), large pliers, or oversized (~7mm dia) M2 washer  | For pressing the PEM threaded inserts into the daughterboard holder | 

# Part 1 - Preparing the PCB 

## 1.1 - Basic ESD and safety precautions 
As the PCB lacks any ESD protection when the daughterboard is not connected, observe basic ESD protection procedures. Otherwise, you risk damaging the PCB. 

* Wear a properly grounded metal ESD strap when handling the PCB and when assembling the keyboard 
* Avoid wearing clothing (such as thick wool sweaters or socks) or working on surfaces (e.g. carpet) that are prone to generating static electricity. 
* Touch a grounded metal object before handling the PCB, and regularly while you are working. Common grounded metal objects include metal appliances that are plugged in with a 3-prong plug, computers  that are plugged in with a 3-prong plug, any exposed metal on cables that protrude out of said computers (e.g. USB cables), and metal sinks and faucets. Doorknobs are not grounded and are not a good place to discharge static. 

For soldering, wear eye protection while soldering, and make sure that your space is well ventilated to avoid breathing in flux fumes. 

## 1.2 - Soldering on the reset switch. 

Solder the reset switch onto the top side of the PCB, next to Right Shift.

 [picture of the reset switch soldered on]

## 1.3 - Soldering on the RGBLED

If you ordered your PCB from JLCPCB, you will also need to solder on the RGBLED. This is soldered to the bottom side of the PCB, but the LED faces up (through the hole in the PCB). 

As this is surface mount, you may find applying flux to the LED legs and pads to be helpful with soldering it on.

Make sure the notch on the RGBLED lines up with the arrow on the hole where it goes.

## 1.4 - Installing software for flashing the firmware

If you ordered the PCB directly from a PCB fab, it likely won't have the firmware installed on it. 

To flash the firmware, you'll have to install a few pieces of software.

If you are on Windows, you'll want to install drivers. This can be done with a tool called [Zadig](https://zadig.akeo.ie/). 

a.) Install and open Zadig:
Zadig Step 1

b.) Select "List All Devices" in the Options Menu :
Zadig Step 2

c.) Select "STM32 Bootloader" in the dropdown menu:
Zadig Step 3

d.) Select WinUSB here:
Zadig Step 4

e.) Click the Replace Driver button. This will install the driver. 

f.) After Zadig is installed, install [QMK Toolbox](https://github.com/qmk/qmk_toolbox). Download links are at the bottom of the page.

g.) Download the .bin Vial firmware file [here](https://github.com/bluepylons/Boston/blob/main/Boston%20-%20Current%20design/boston_vial.bin) 
 
## 1.5 - Flashing the Firmware 

a.) Connect the USB-C daughterboard to the PCB using the JST cable. Remove any metal or other conductive objects from the vicinity to reduce the risk of the PCB getting shorted, and be careful to avoid letting the daughterboard touch the PCB (as that can also cause a short circuit). 

b.) Connect the daughterboard to your computer. The PCB and daughterboard will receive power, and will be vulnerable to short circuits, so continue to be careful. 

c.) Open QMK Toolbox. 

d.) Hold down the reset button for at least 5 seconds, and then release it. In QMK Toolbox, "STM32 DFU device connected" should appear in yellow.
QMK Toolbox Step 1

e.) Press "Open" in QMK Toolbox and navigate to the location of your .bin firmware file. 
QMK Toolbox Step 2

f.) Press the Flash button. Do not disconnect the keyboard until it is done flashing, or you may permanently brick your keyboard. 
QMK Toolbox Step 3

## 1.6 - Testing your PCB 
Use a tweezer, metal keycap puller, wire, or unbent paperclip to short the switch opening pins, and a program such as [Aquakeytest](https://geekhack.org/index.php?topic=34670.0) to ensure that each key works. 

Disconnect the daughterboard from the PCB once you're done.

## 1.7 - Soldering on the lock LEDs and resistors 

First, solder on the 3 1KΩ resistors onto the positions for R200, R201, and R202. 1KΩ is a comfortable value, but if you want your LEDs brighter or dimmer you may wish to use different resistors. Resistors are not directional and will work soldered in either direction.

Resistors

Next up, we want to do the lock LEDs. Note that LEDs are directional and will not light up if soldered in backwards. The longer leg on an LED is +. Make sure this matches up with the + symbols on the PCBs.
LED-legs-labelled

Solder the lock LEDs through the LED spacer as shown - the LED spacer only fits on one way. 
LEDs in spacer
LEDs soldered on

## 1.8 - Soldering on the rotary encoder 

Solder on the rotary encoder on the upper left of the PCB. Make sure you solder this to the top side of the PCB. 

# Part 2 - Preparing the case 

## 2.1 - Installing the rubber feet 
Peel the backing paper off the rubber feet and stick them in the circular pockets on the bottom of the case. 

[image] 

## 2.2 - Installing the RGBLED light pipe 

a.) Press the light pipe into the hole meant for the light pipe on the upper left of the case top. 
Light pipe installation

b.) Flip the case top over. Slip the rubber light pipe retainer onto the back of the light pipe, and move it down so that it prevents the light pipe from falling out. If you want, you can glue the RGBLED light pipe and retainer, using hot glue, epoxy, or another adhesive. 
Light pipe retainer installation

Light pipe retainer installed

# Part 3 - Preparing the daughterboard and daughterboard holder

## 3.1 - Installing the threaded inserts into the daughterboard holder 

The PEM KF2-M2-ET threaded inserts need to be pressed into and then soldered to the daughterboard holder PCB. There are a couple of methods to press in the threaded inserts. 

Note that the threaded inserts should be pressed into the side with the silver rings around the holes for them. If you press them in the wrong side you won't be able to solder them in place.
Pressed in threaded insert

### Method 1 - C-clamp or vise 
a.) Using a C-clamp or vise, press the threaded inserts into the daughterboard holder. Ensure that they are fully seated. 

 [picture of C-clamp method]

### Method 2 - Using an M2 screw and large M2 washer to pull the threaded insert in 
To do this, you will need an oversize M2 washer with at least 7mm diameter (such as McMaster-Carr P/N 91116A240), and an M2x5 screw. Using a Torx-head M2 screw is strongly recommended, as Philips and hex heads strip far more easily. 

a.) Place the oversize M2 washer underneath the head of the M2x5 screw.

b.) Press the threaded insert into the side it should go on. Thread the screw and washer in from the other side, and tighten the screw until the threaded insert is pulled into the hole and fully seated.

[picture]

c.) Remove the screw and washer. 

### Method 3 - Vise grip (locking pliers)
This method tends to mar and scratch the daughterboard holder, but it does work. 

a.) Set the knob on the back vise grip such that it will forcefully press the threaded insert all the way into the part. 

b.) Place the threaded inserts in, and press them in with the vise grip. 

[picture]

### Method 4 - Hammer 
a.) A soft hammer is ideal to avoid damaging or denting the threaded insert - otherwise, if you're using a regular hammer with a metal head, place a small sacrificial piece of wood or cardboard in between the insert and the hammer to soften the blow a bit. Hammer the insert in until it is fully seated.
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

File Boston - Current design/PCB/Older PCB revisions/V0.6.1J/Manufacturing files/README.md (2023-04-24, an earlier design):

## NOT YET PROTOTYPED - ORDER AT YOUR OWN RISK

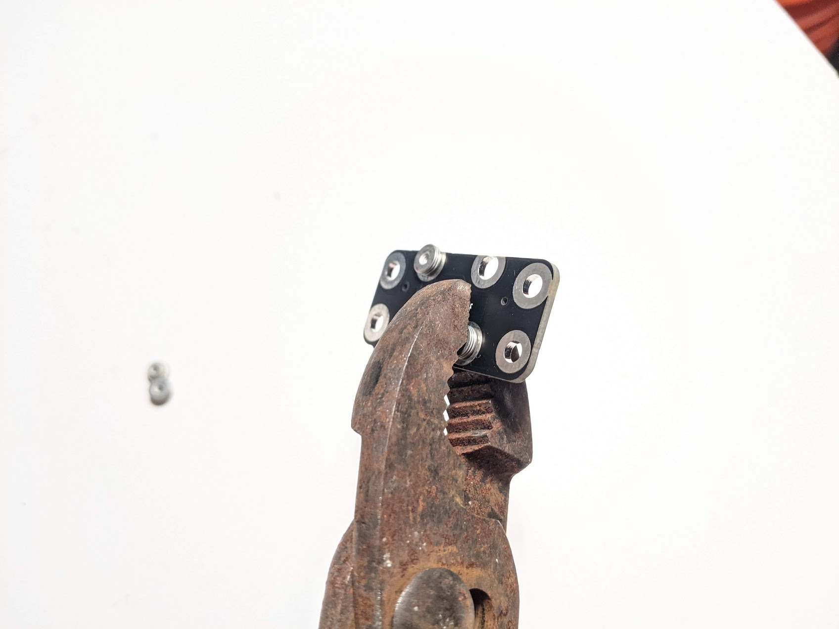
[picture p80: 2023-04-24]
graphics/Assembly-guide-CNC/PEM-nut-installation-plier.jpg

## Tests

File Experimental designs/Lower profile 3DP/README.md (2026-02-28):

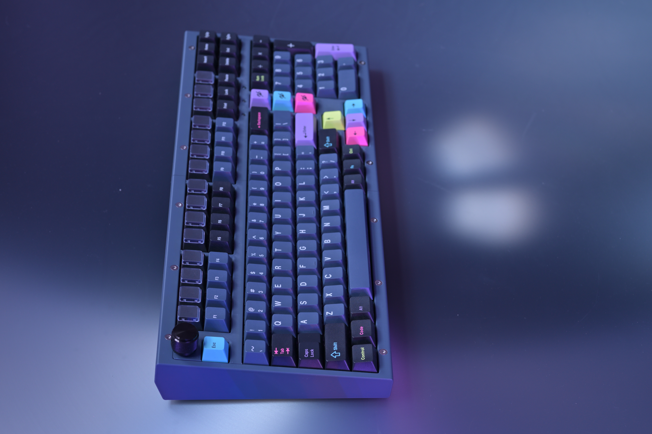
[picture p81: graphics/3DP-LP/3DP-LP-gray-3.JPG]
Side view


This is a prototype 3D-printed case with the following improvements:
* Reduces front height by ~2mm
* Reduces width by ~2mm
* Switches to countersunk screws for the top screws so that they no longer protrude
* Changes side profile a bit so that the top and bottom bezels are more even
* Revised Right-key separator so that it transitions better into Right-half near the arrow keys

This is intended to be backwards compatible with existing 3DP Bostons, though some of the fasteners change.

Front view
Rear view
Right key separator

# Upgrade guide (draft)

## What parts will I need? 
What parts you will need will depend on which PCB version you have (the PCB version is written on the bottom left of the PCB, roughly near the F3 key):

| PCB version | Right-half needed | Can you easily install new key separators ? |
| --- | --- | --- |
| V0.6.1J and below | Lower-profile-right-half-with-reset-hole.stp | No |
| V0.7J | Lower-profile-right-half-with-reset-hole.stp | Yes |
| V0.8J and above | Lower-profile-right-half.stp | Yes |

The left half file (Lower-profile-left-half.stp) is identical for all versions. 

If you have an older V0.6.1J or earlier PCB and your keyboard is already built, you should keep your existing key separators as you will need to desolder all of your switches to install new key separators. Otherwise, with a newer PCB, you can also print and install the new key separators (Left-key-separator-revised-with-RGBLED.stp and Right-key-separator-revised.stp)

In addition, you will need additional screws:

| Hardware description | Quantity | McMaster-Carr P/N | Notes |
| --- | --- | --- | --- |
| M3x0.5 10mm long countersunk screw ISO 14581 (Torx) or ISO 10642 (hex) | 11 | 92125A130 (hex, silver) | McMaster does not sell stainless 10mm in Torx; [Bel-Metric](https://belmetric.com) SF3X10TXSS (silver) or SF3X10TXBLKSS (black) recommended instead |
| M3x0.5 8mm long button head screw, ISO 7380 (Torx) | 2, ideally 4 | 90991A113 | Also available from Bel-Metric as SB3X8TXSS (silver) or SB3X8TXBLKSS (black) |

If you cannot salvage the M3 hex nuts from your old case, you will also need 12 new M3 hex nuts:

| Hardware description | Quantity | McMaster-Carr P/N | Notes |
| --- | --- | --- | --- |
| M3x0.5 DIN 934 hex nut, zinc plated | 12 | 90591A250 | Also available from Bel-Metric as NR3CLZ. Do not use stainless due to galling risk. |

A summary bill-of-materials table is below:

| Part description | Quantity (if needed) | Type | Notes | 
| --- | --- | --- | --- |
| New left half | 1 | 3D printed | |
| New right half | 1 | 3D printed | Use "-with-reset-hole" variant if PCB V0.7J or older |
| New left key separator | 1 | 3D printed | If keyboard is already built, only use if PCB is V0.7J or newer |
| New right key separator | 1 | 3D printed | If keyboard is already built, only use if PCB is V0.7J or newer |
| M3x0.5 10mm long countersunk screw | 11 | Fastener | |
| M3x0.5 8mm long button head screw  | 2, but ideally 4 | Fastener | 2 is the bare minimum; 4 replaces the other M3x10 screws for consistency  | 
| M3x0.5 hex nut | 12 | Fastener | Only if you cannot salvage the hex nuts from your old case |

## Assembly 

Use a properly-grounded ESD wrist strap and observe other basic electrostatic-discharge precautions to avoid damaging your keyboard.

Remove all 11 screws on the top side:
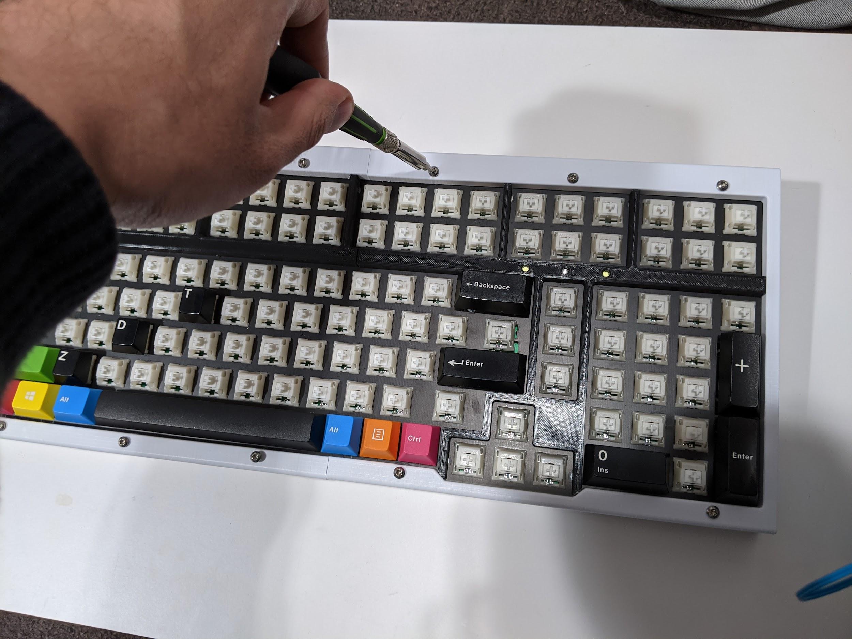
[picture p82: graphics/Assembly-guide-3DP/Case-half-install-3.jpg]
Top side screws


Remove all 12 screws from the bottom side:
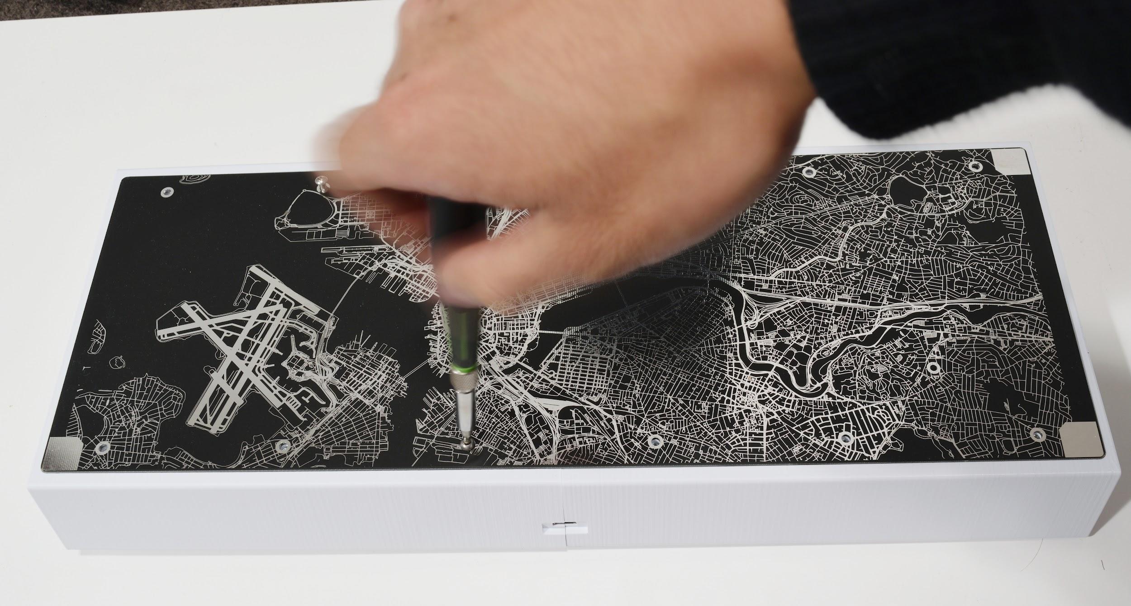
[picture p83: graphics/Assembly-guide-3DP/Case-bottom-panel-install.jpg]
Bottom side screws


Remove the bottom panel, and slide the old halves off. For the right half you will have to pull the front side towards you a bit to get it to slide past the arrow keys. 
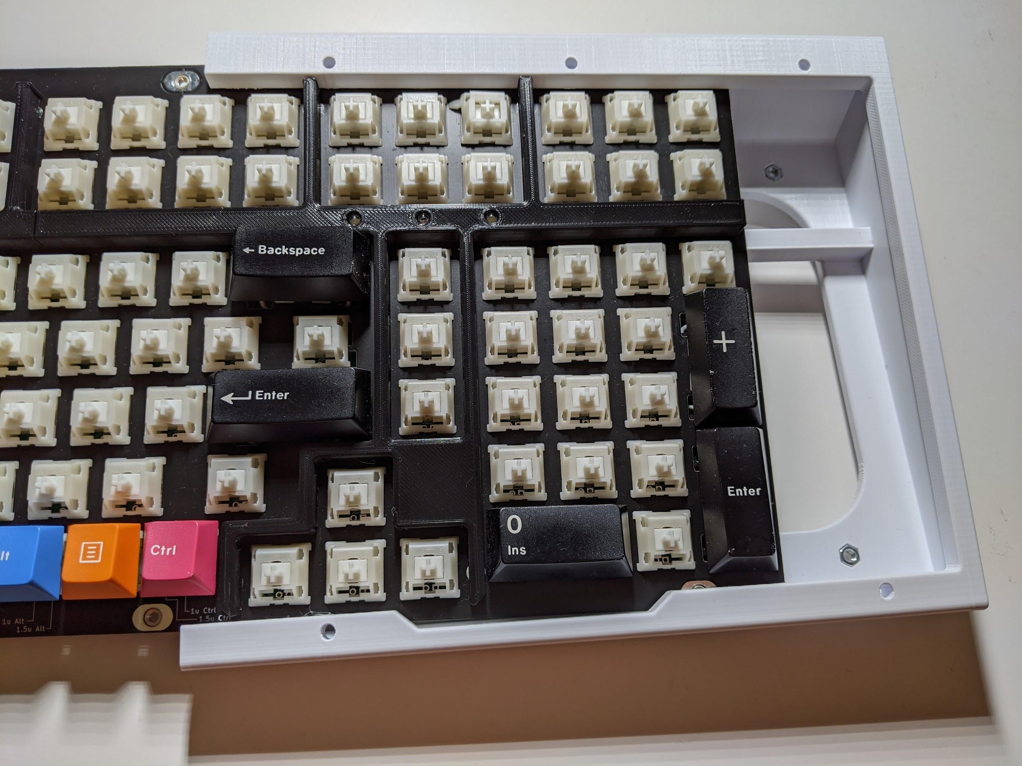
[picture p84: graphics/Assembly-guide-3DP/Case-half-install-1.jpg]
Sliding halves off


Insert M3x0.5 hex nuts into each of the 6 hexagonal pockets on the bottom of each of the new case halves. If the fit is loose, gluing these in with super glue is recommended to prevent them from falling out during assembly - you can add two drops to the inside corners of the hexagonal pocket.
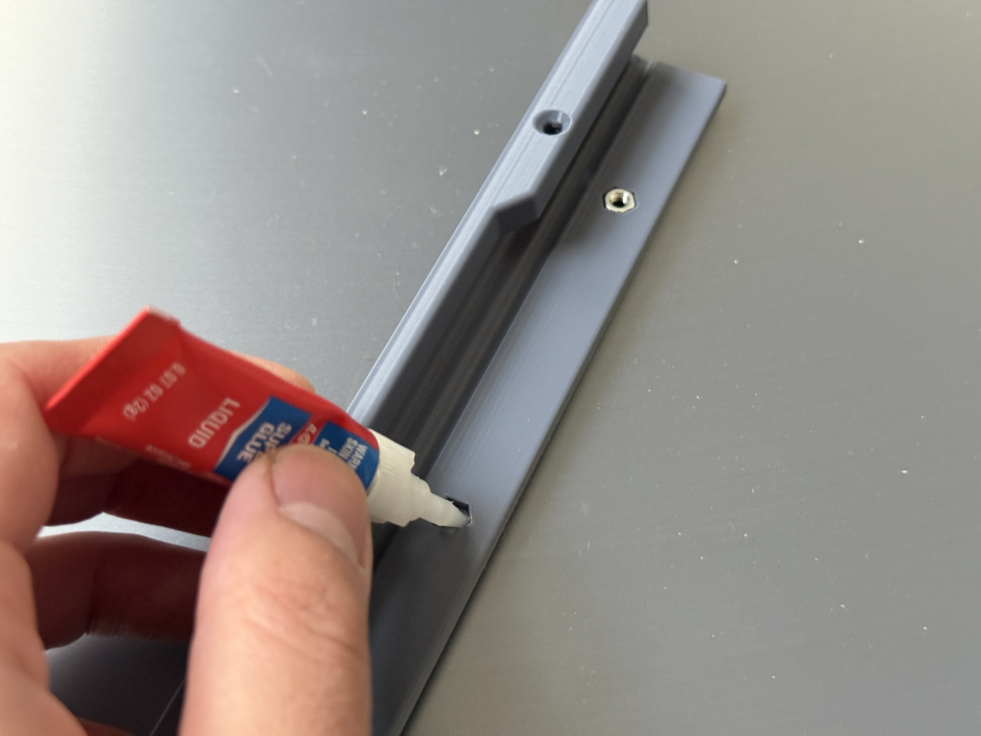
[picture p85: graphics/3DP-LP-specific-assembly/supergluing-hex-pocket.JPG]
Suergluing

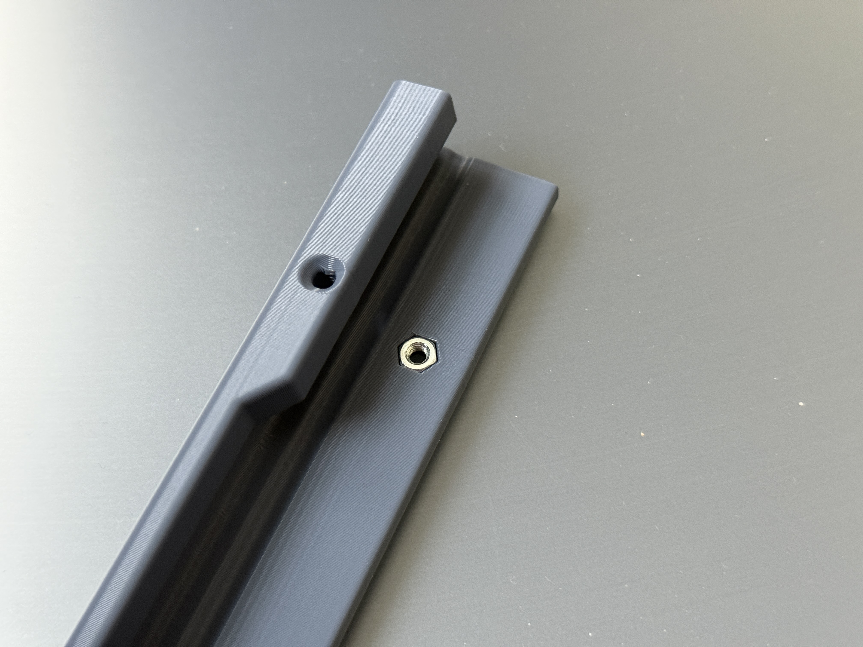
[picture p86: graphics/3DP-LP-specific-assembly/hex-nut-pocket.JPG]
Hex nut in pocket


### If you are installing new key separators:
If you are replacing your key separators, first remove the knob from the rotary encoder.

Flip the PCB over. Get a Torx T6 bit (a magnetic one is strongly recommended), and use it to remove all 14 of the M2 self-tapping screws (circled in orange below), and remove the old key separators:
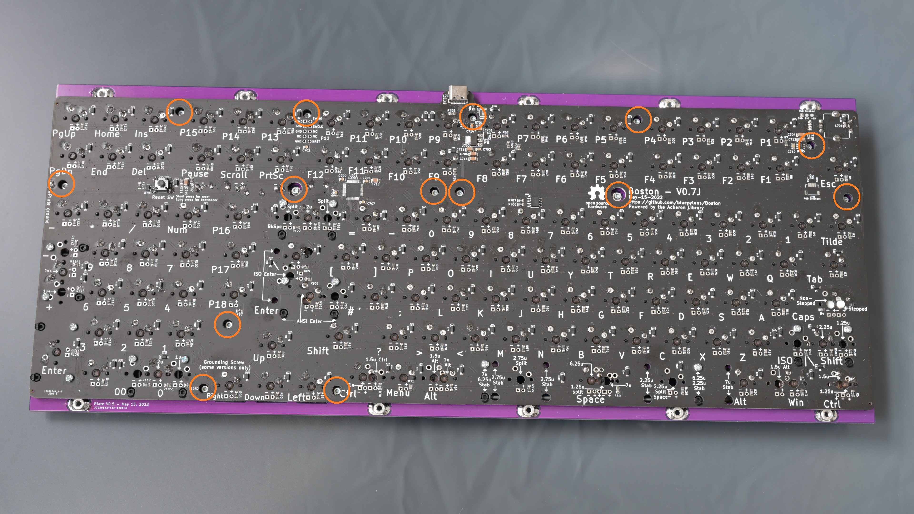
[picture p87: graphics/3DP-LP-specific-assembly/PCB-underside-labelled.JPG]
Remove these screws

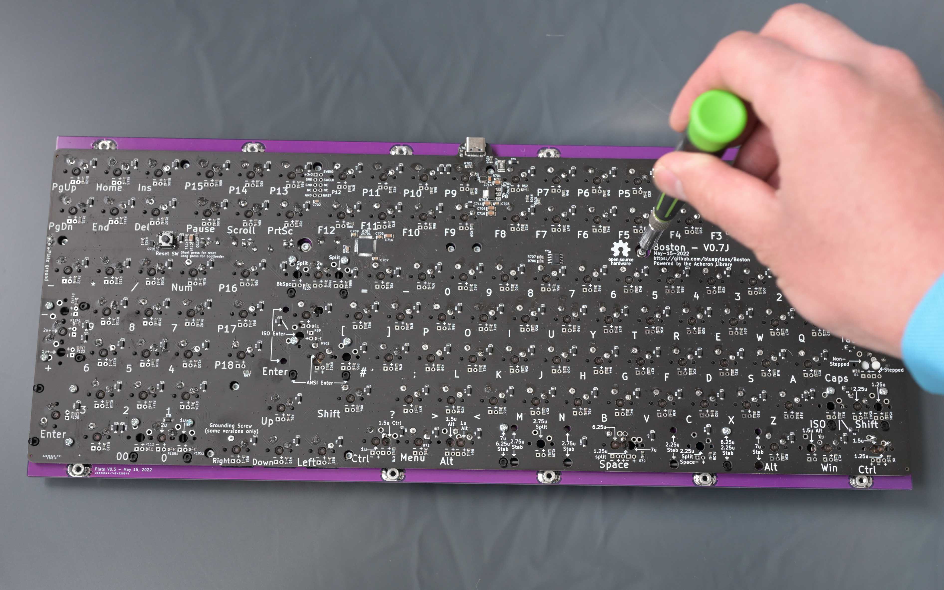
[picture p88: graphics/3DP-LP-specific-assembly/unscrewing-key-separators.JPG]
Removing screws

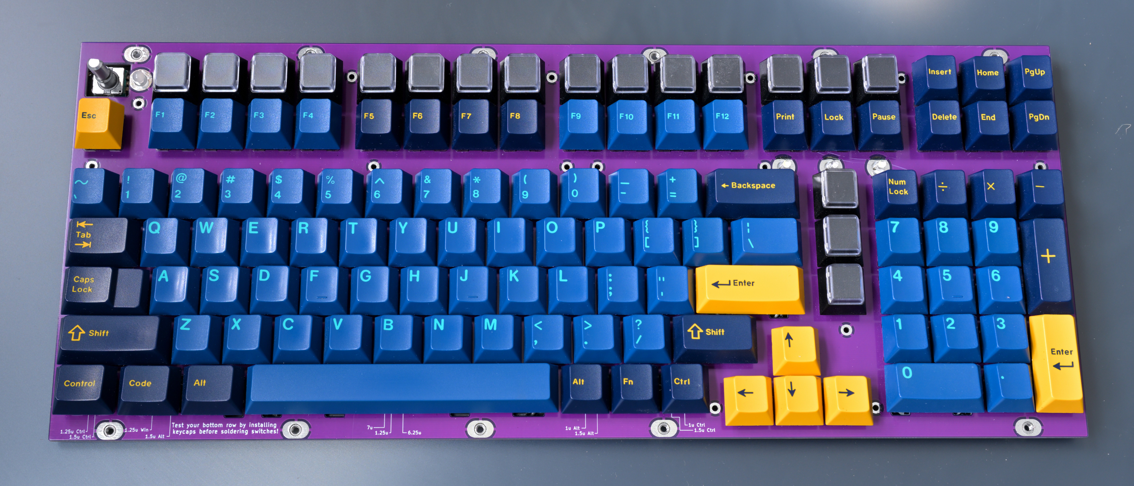
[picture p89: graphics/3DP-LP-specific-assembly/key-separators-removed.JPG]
Key separators removed


Install the new key separators (install the left one first), using the 14 M2 self-tapping screws, but leave the screws about a half turn too loose.
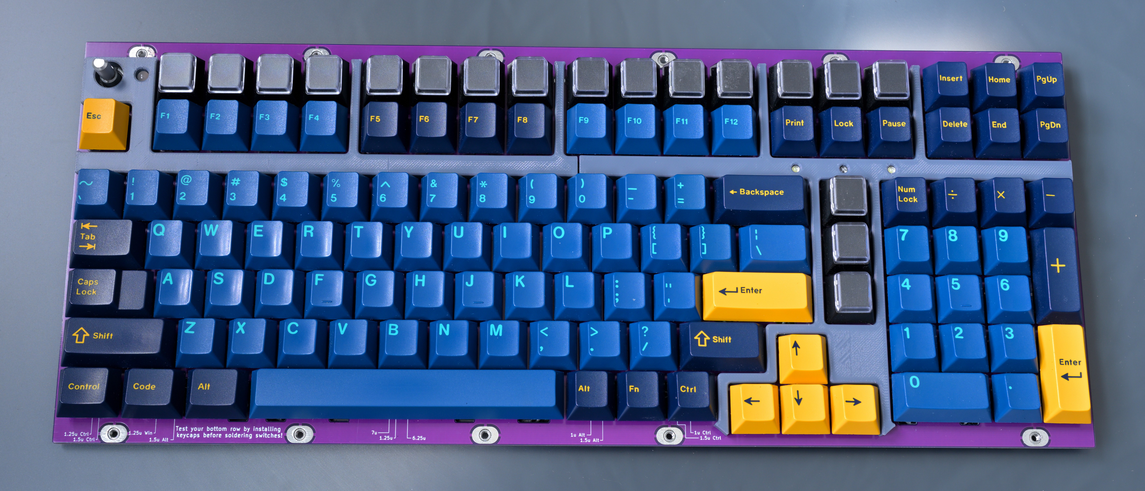
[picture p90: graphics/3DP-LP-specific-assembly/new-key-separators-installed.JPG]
Key separators installed


Temporarily install the new left and right case halves using a few M3x10 countersunk screws to screw them to the plate. For the right case half, you will have to bend the front portion out slightly to get it to slide past the arrow keys.
Key separators installed

Adjust the separator pieces so that the gaps between the separators and the case halves (labelled below) are minimized when the plate is slid into the very end of the case halves. 
Key separators gaps

Flip the assembly over, and fully tighten the screws that are accessible. Remember to not overtighten the screws or you may strip the 3D-printed plastic.
Key separators installed

Remove the left and right case halves, and fully tighten the remaining screws on the key separators.

### If you are re-using your existing key separators
Do a test fit with the left and right case halves. You may need to trim off this lip between the F-row and main block on the left and right key separators with a pair of flush cutters, though only do this if the fit between this and the case halves is poor. You will ***not*** need to trim the similar lip near the knob.
Lip
Lip removal

## Assembly continued

Slide on the left and right case halves. For the right case half, you will have to bend the front portion out slightly to get it to slide past the arrow keys.
Case halves slid on

Install the 11 M3x10 countersunk screws into the top, though leave them about a half turn loose.
Screwing in top screws

Install the bottom panel and rubber feet holders. Use M3x6mm long screws on the middle 8 screw holes, and M3x8mm long screws on the 4 corners screw holes. (if necessary, the 2 rear corner screws can be M3x10mm, but the front 2 corner screws must be M3x8mm long). 
Labelled bottom screws
Screwing in bottom screws

Place the keyboard on a rigid, flat surface. Push down gently on the middle of the keyboard while using your other hand to fully tighten the top screws; this is to help make sure the keyboard is built flat and will not wobble:
Fully tightening top screws

Flip the keyboard over, and fully tighten all the screws on the bottom.

Reinstall the knob. You are done!
Done!

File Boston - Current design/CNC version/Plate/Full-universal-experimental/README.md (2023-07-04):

An experimental full universal plate that works with both soldered and hotswap. This probably has terrible switch retention.

Work in progress

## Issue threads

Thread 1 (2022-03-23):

dead link

koboldtime, 2022-03-23:
Link to files for plate in current design/3d printed version lead to a 404

bluepylons, 2022-03-23:
Sorry I renamed some of the folders at some point to make more sense and forgot to update the old links. Should be fixed now.

koboldtime, 2022-03-23:
Thanks so much! Im looking forward to putting together my board

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

Closed 2022-03-26.

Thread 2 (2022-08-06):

Entering bootloader mode for flashing a modified firmware

syntheit, 2022-08-06:
I would like to flash a modified firmware with some modifications to the functionality to the LEDs.  However, after any attempts, I am unable to get the device to enter bootloader mode and appear in QMK Toolkit.  I do not have a button soldered on the reset switch, so I'm bridging it using a screwdriver.  I tried bridging the right two circles, bottom two circles, and top two circles, to no avail.  I have the screwdriver on the circles as I'm plugging it in.  Am I doing something wrong?
Thanks

bluepylons, 2022-08-08:
Did you install the STM32 drivers, and are you "long pressing" (shorting the pins for more than 5 seconds) to enter into the bootloader?

If you try dfu-util directly (instead of via QMK toolbox) does it also work? I recall there occasionally being issues with newer versions of dfu-util, so you might also want to try dfu-util 0.8 or older.

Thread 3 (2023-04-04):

exposed trace underneath F11

ambustion, 2023-04-04:
Is there supposed to be exposed copper underneath f11? I tried ordering and elecrow asked about this section.

bluepylons, 2023-04-05:
Hey - thanks for catching that - that appears to be an error on the V0.8 hotswap variants (V0.8DHA and V0.8JHA). I'll make revisions V0.8.1DHA and V0.8.1JHA that remove that patch. It does pose a shorting risk where +3.3V could easily short to ground.

On V0.6.1D (and on V0.8D and V0.8J) that spot is where a bunch of vias surface and is for hand-soldering the pad underneath the QFN STM32F072's (-CBU6 and -CBU7), but the MCU moved for the hotswap variants but I forgot to delete the solder mask exclusion

Also - when I have time in a couple of weeks I'll prepare JLCPCB files for the V0.8 lineup, which should be cheaper than Elecrow in small quantities.

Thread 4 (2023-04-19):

V06.1D PCB QMK Issues

ohrehman, 2023-04-19:
Flashing the precompiled default binary from this github works mostly fine, except shift and capslock seem to be permanently depressed (however the switches themselves are not shorted out - tested with multimeter).

Compiling and flashing my own binary using the latest version of QMK works with no errors, however, the keyboard is non functional. Caps and Num lock keys flash momentarily when plugging it in, and then there are no inputs from the keyboard. Can hear the USB connect/disconnect sounds as well.

Any idea what could be going on with this?

Photos are mostly unrelated but just to admire the design itself.

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

bluepylons, 2023-04-19:
Oh wow that is a pretty build.

Do you have any pictures of the bottom of the PCB, especially around the microcontroller? Do you also have any spare PCBs - do they behave similarly when you flash them? That is an odd error.

ohrehman, 2023-05-14:
Thank you! apologies for the late response, life got in the way. I've put photos of the PCB below.

RE: Spare PCB: yep, and it actually works perfectly fine. However, I assembled one without testing as I was waiting on the daughterboard. Worst case, I guess I could desolder all the millmax sockets and assemble the spare one, but any ideas around why this one isn't working are more than welcome :D

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

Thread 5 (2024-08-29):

SMD LED

SamuelUlep, 2024-08-29:
Any plans on making an SMD LED compatible PCB to allow hot swapable switches or are we stuck in soldering regular LEDs on switches?

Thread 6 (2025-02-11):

Keyboard Layout Editor json file

grayson676, 2025-02-11:
I'd like to make a qwertz layout fork of this keyboard but I can't find a layout editor json file in the git repo.

If you have the json file with the layout for this keyboard, could you add it to the repo?

bluepylons, 2025-02-11:
Hello,

The KLE is here for the soldered PCB:
https://www.keyboard-layout-editor.com/#/gists/75e63e00e1acc52cdb8eeda7f8ac4ba6

The hotswap PCB KLE appears to be broken and I need to fix it when I get
home.

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

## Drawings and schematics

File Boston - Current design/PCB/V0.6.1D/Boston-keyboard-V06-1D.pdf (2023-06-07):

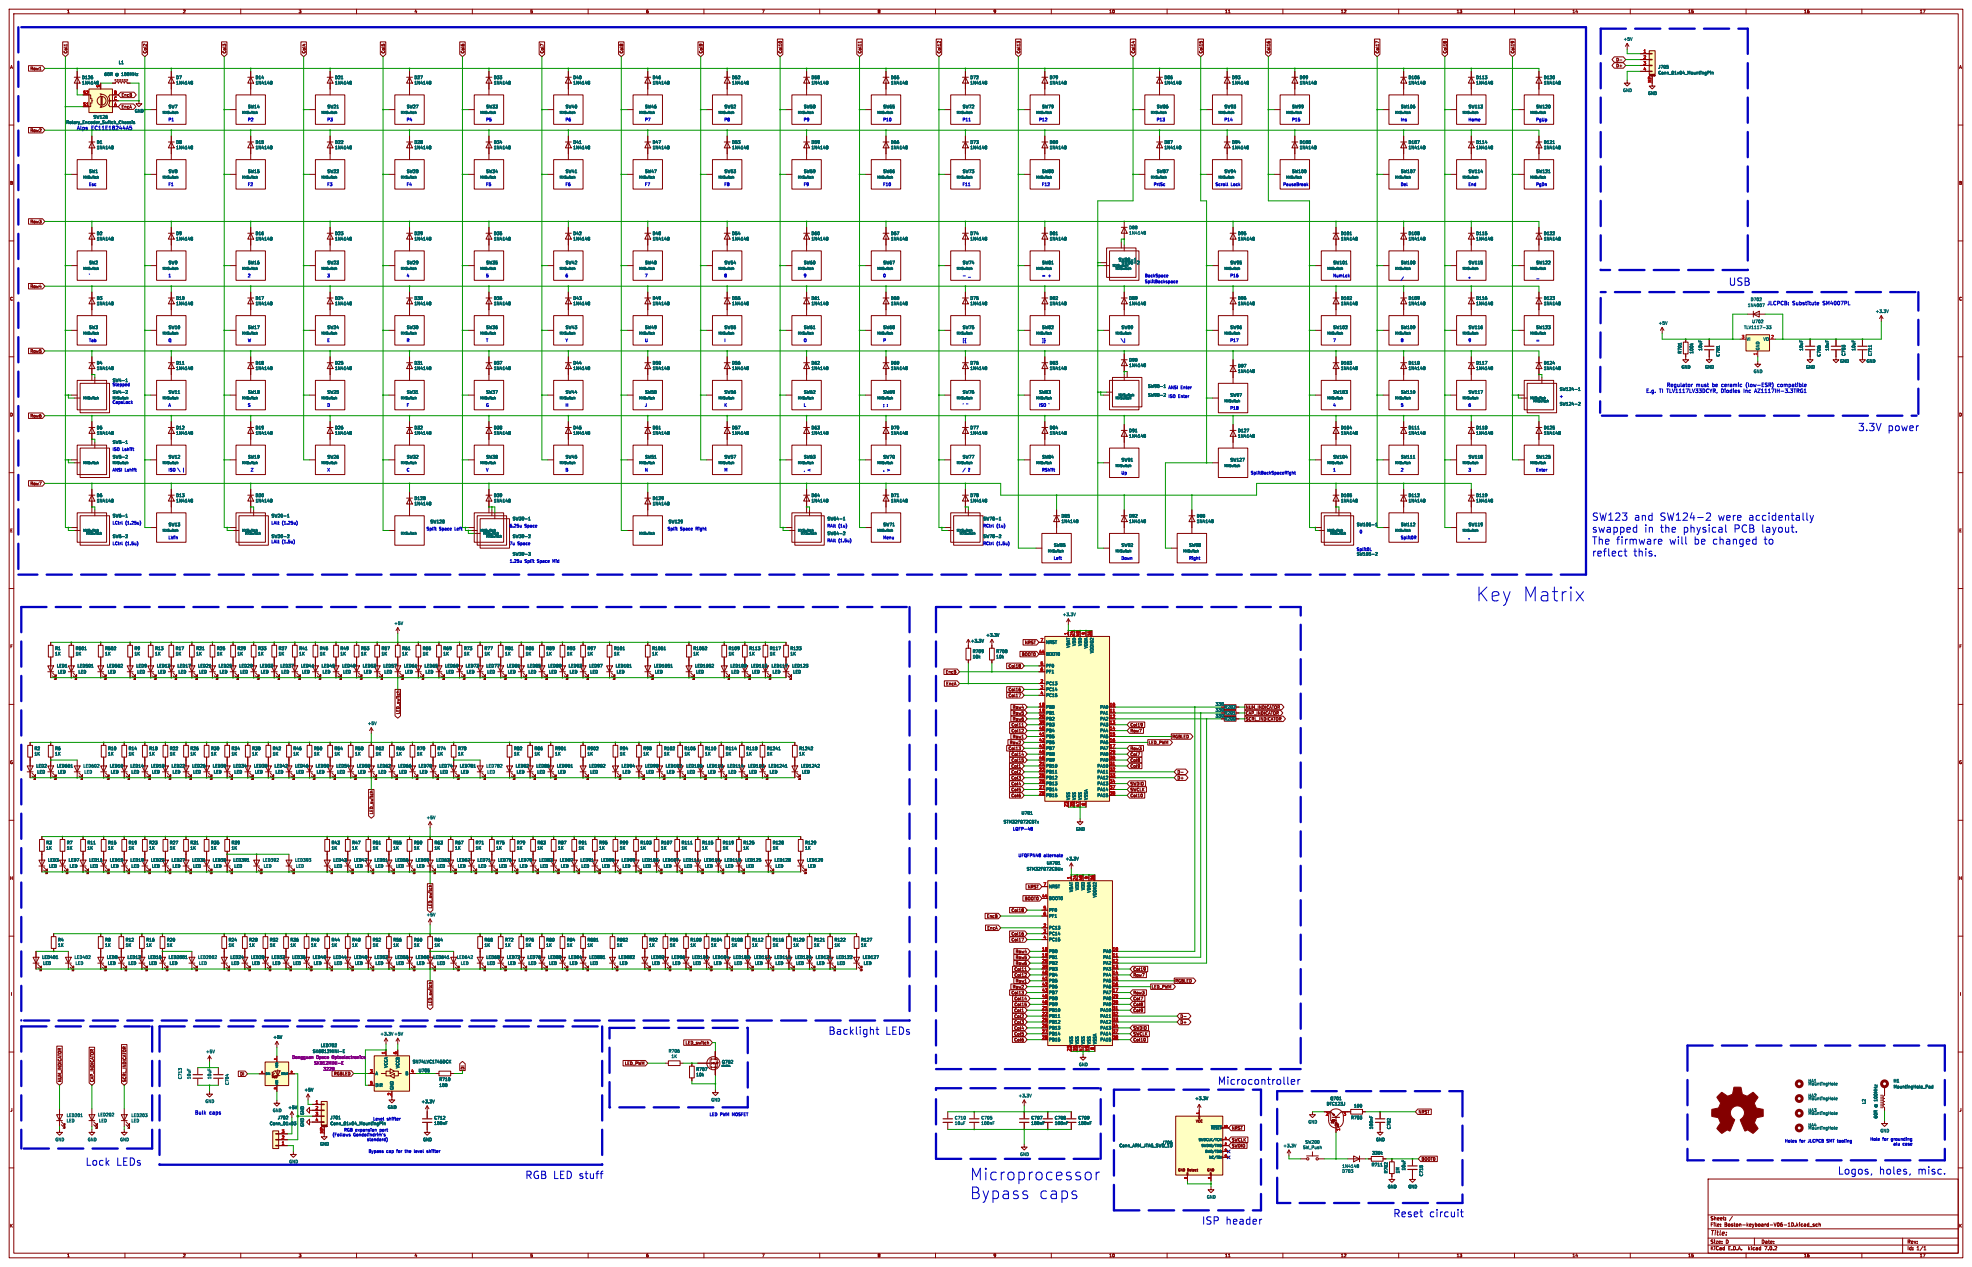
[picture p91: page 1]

swapped in the physical PCB layout.
The firmware will be changed to
reflect this.

Holes for JLCPCB SMT tooling

Bypass cap for the level shifter

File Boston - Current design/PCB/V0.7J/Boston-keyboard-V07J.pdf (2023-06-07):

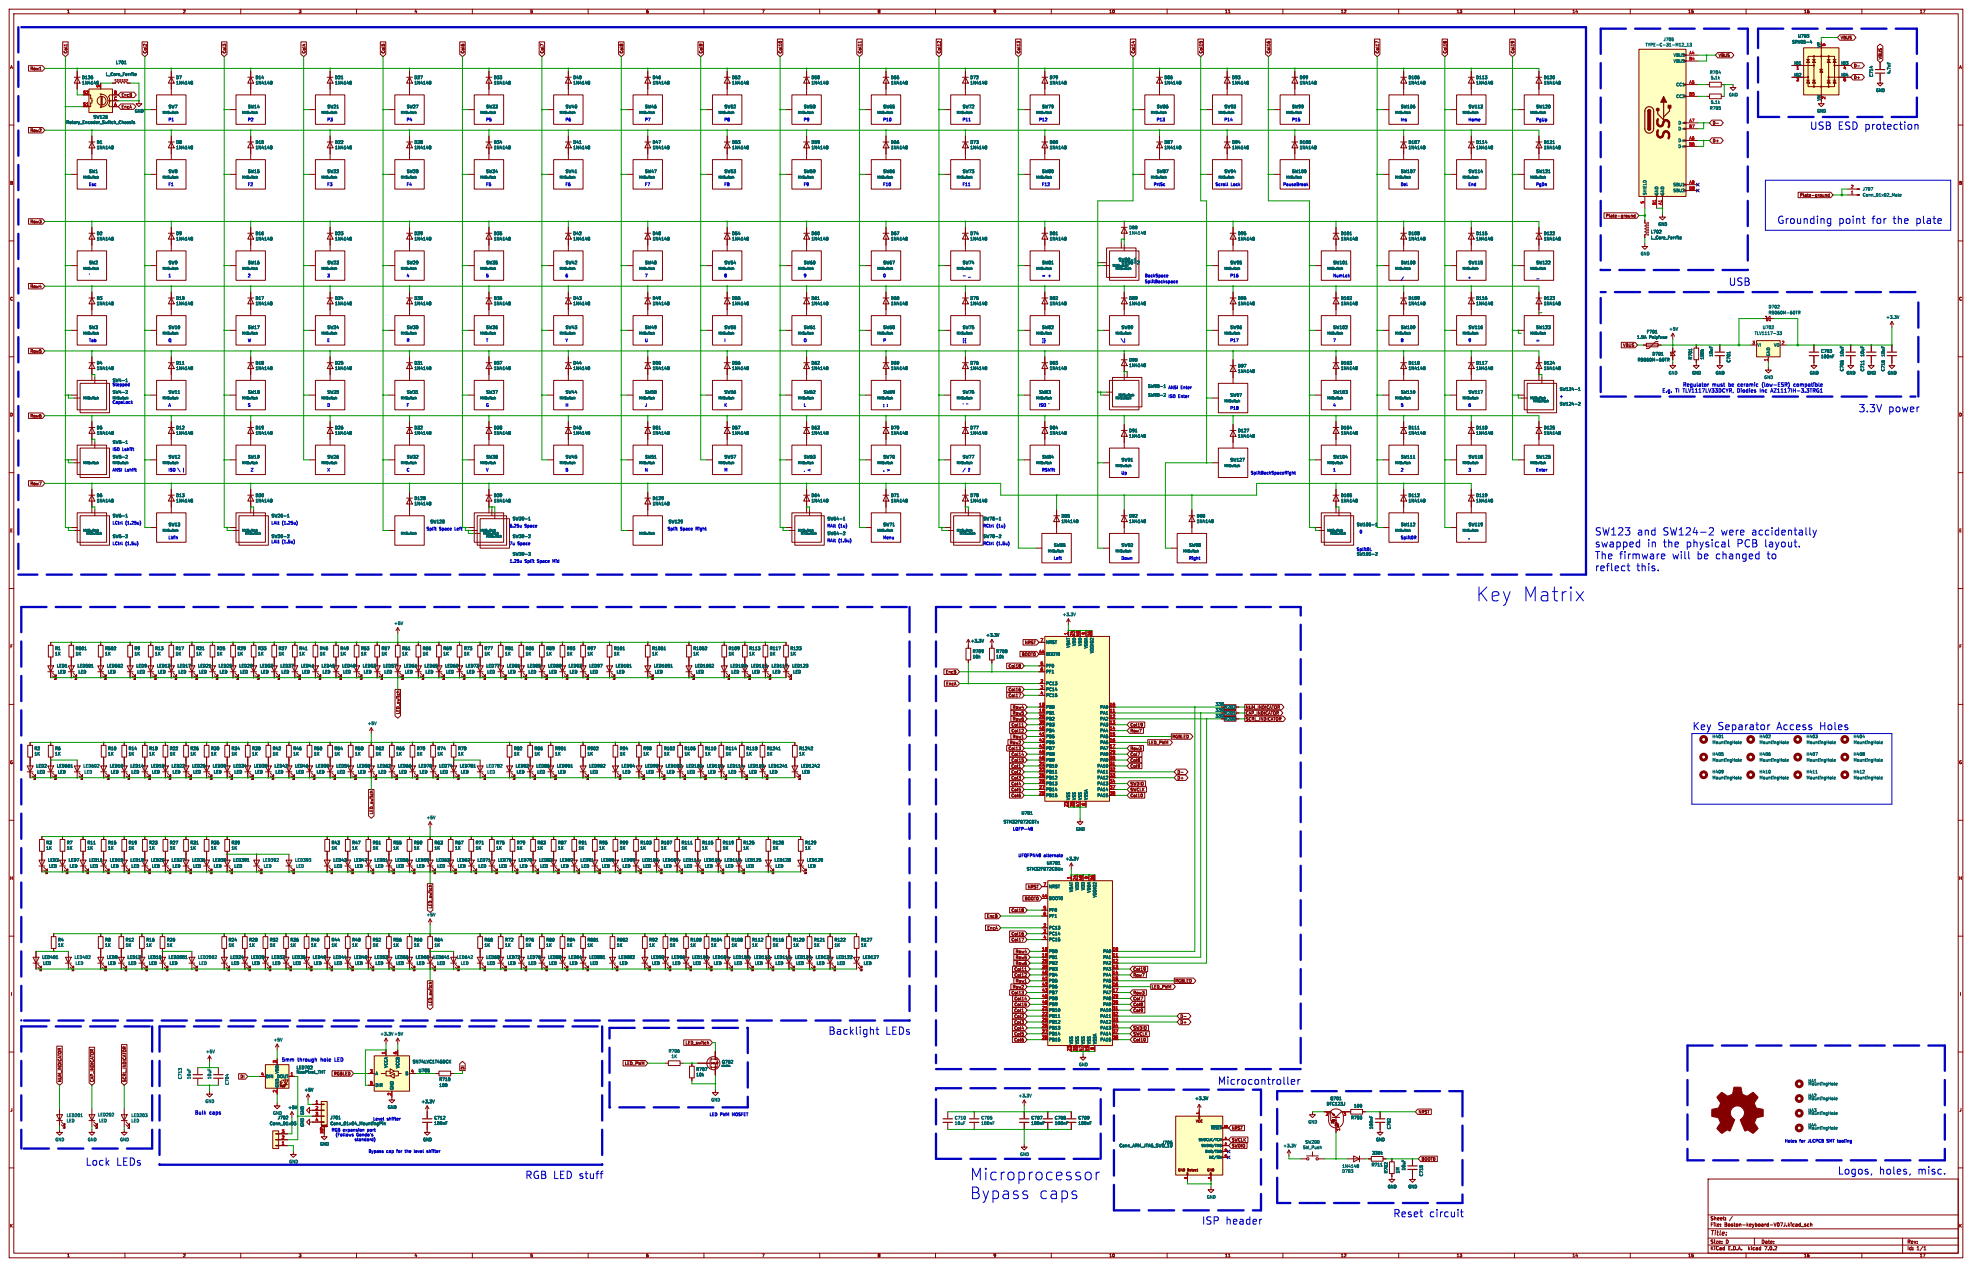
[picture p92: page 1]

Grounding point for the plate

swapped in the physical PCB layout.
The firmware will be changed to
reflect this.

Key Separator Access Holes

LED PWM MOSFET Bypass cap for the level shifter Level shifter

Logos, holes, misc. Holes for JLCPCB SMT tooling

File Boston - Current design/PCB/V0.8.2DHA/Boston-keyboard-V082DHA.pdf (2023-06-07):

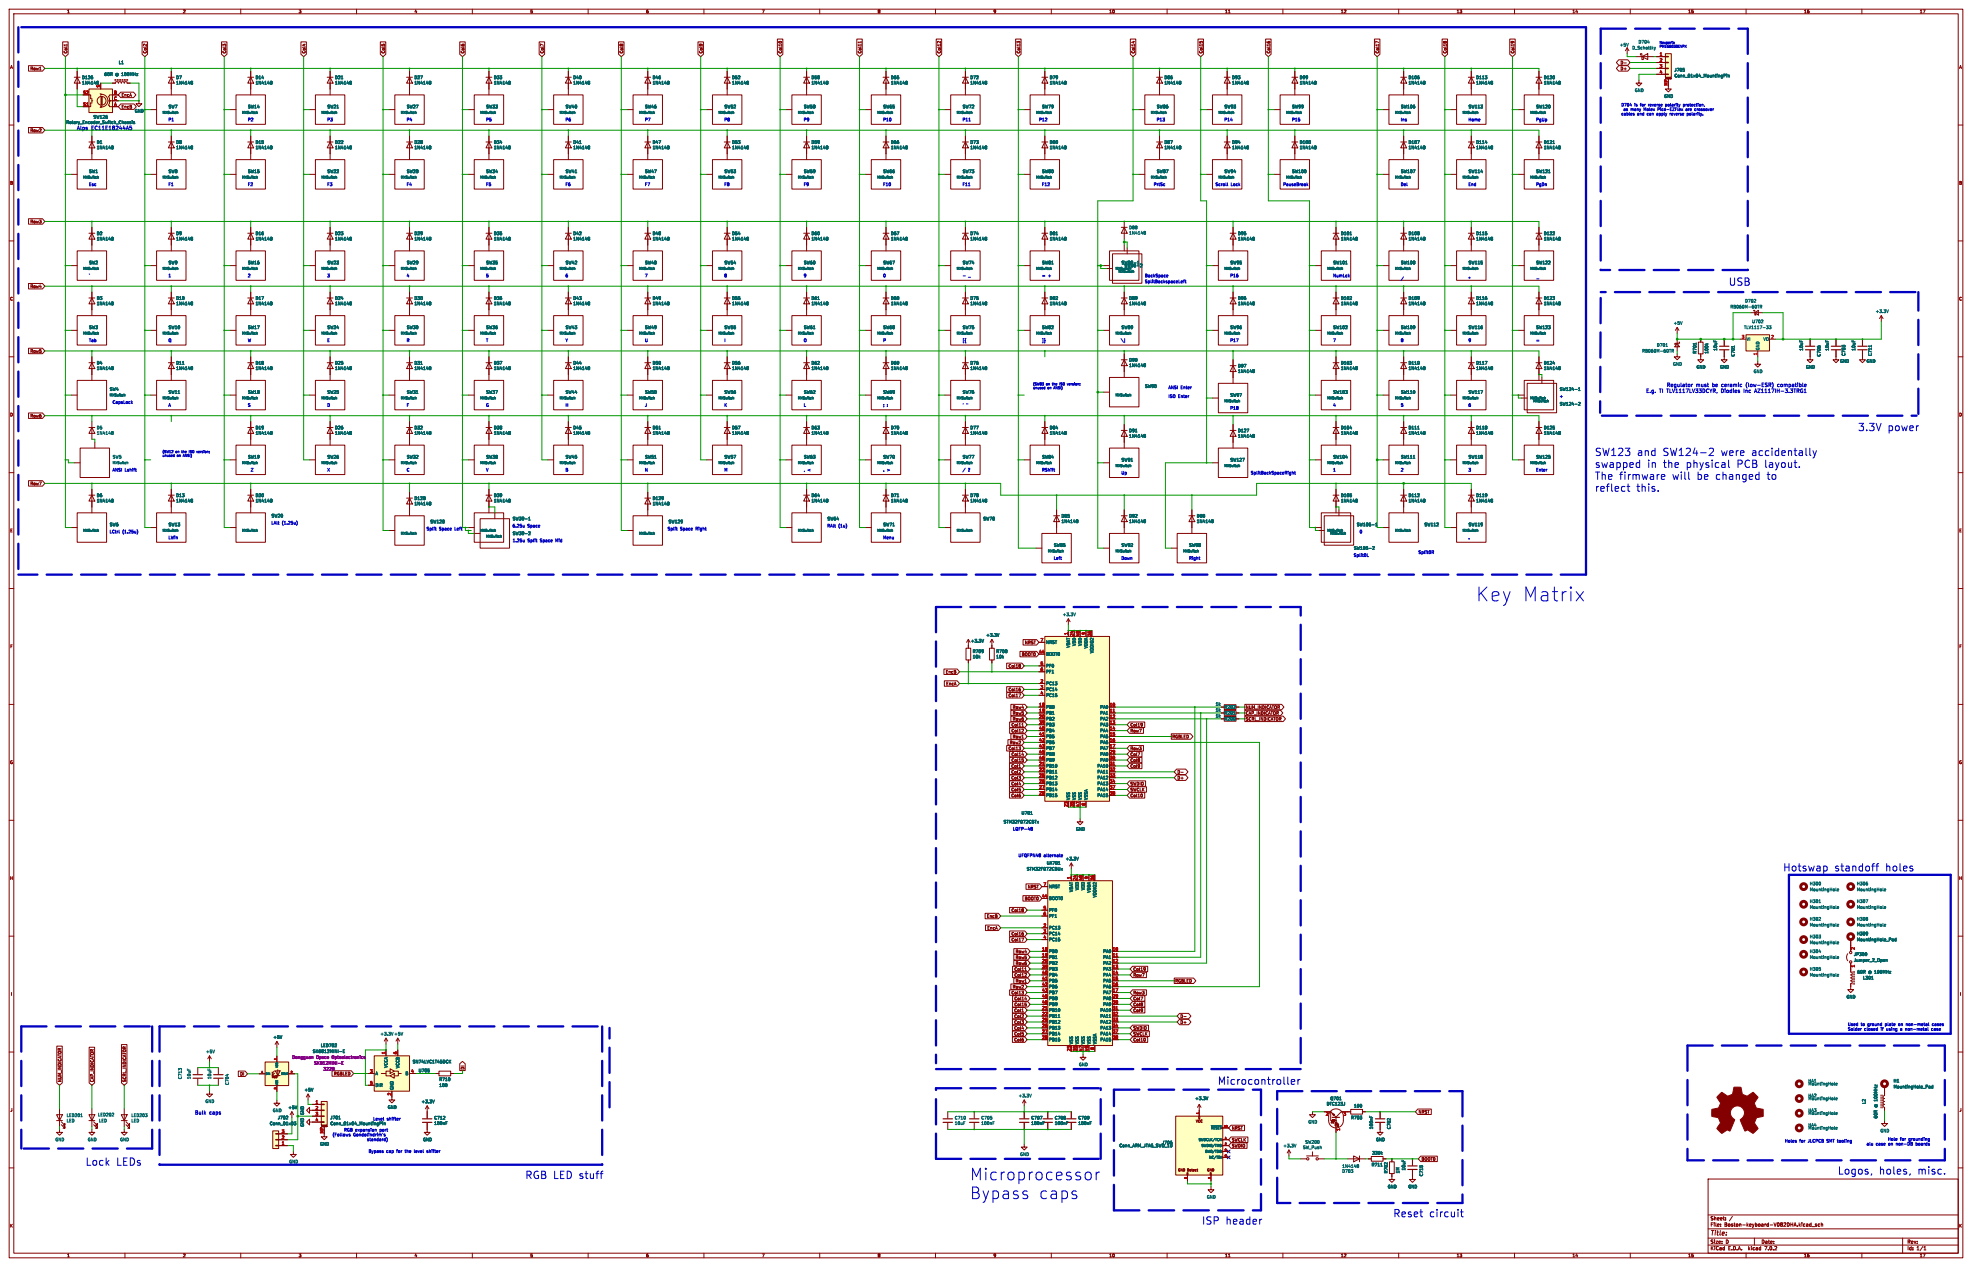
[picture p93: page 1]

SW72 MXSwitch SW10 MXSwitch SW11 MXSwitch SW13 MXSwitch

(SW83 on the ISO version; unused on ANSI) ]}

swapped in the physical PCB layout.
The firmware will be changed to
reflect this.

HA1 MountingHole HA2 MountingHole HA3 MountingHole HA4 MountingHole

Bypass cap for the level shifter Bulk caps

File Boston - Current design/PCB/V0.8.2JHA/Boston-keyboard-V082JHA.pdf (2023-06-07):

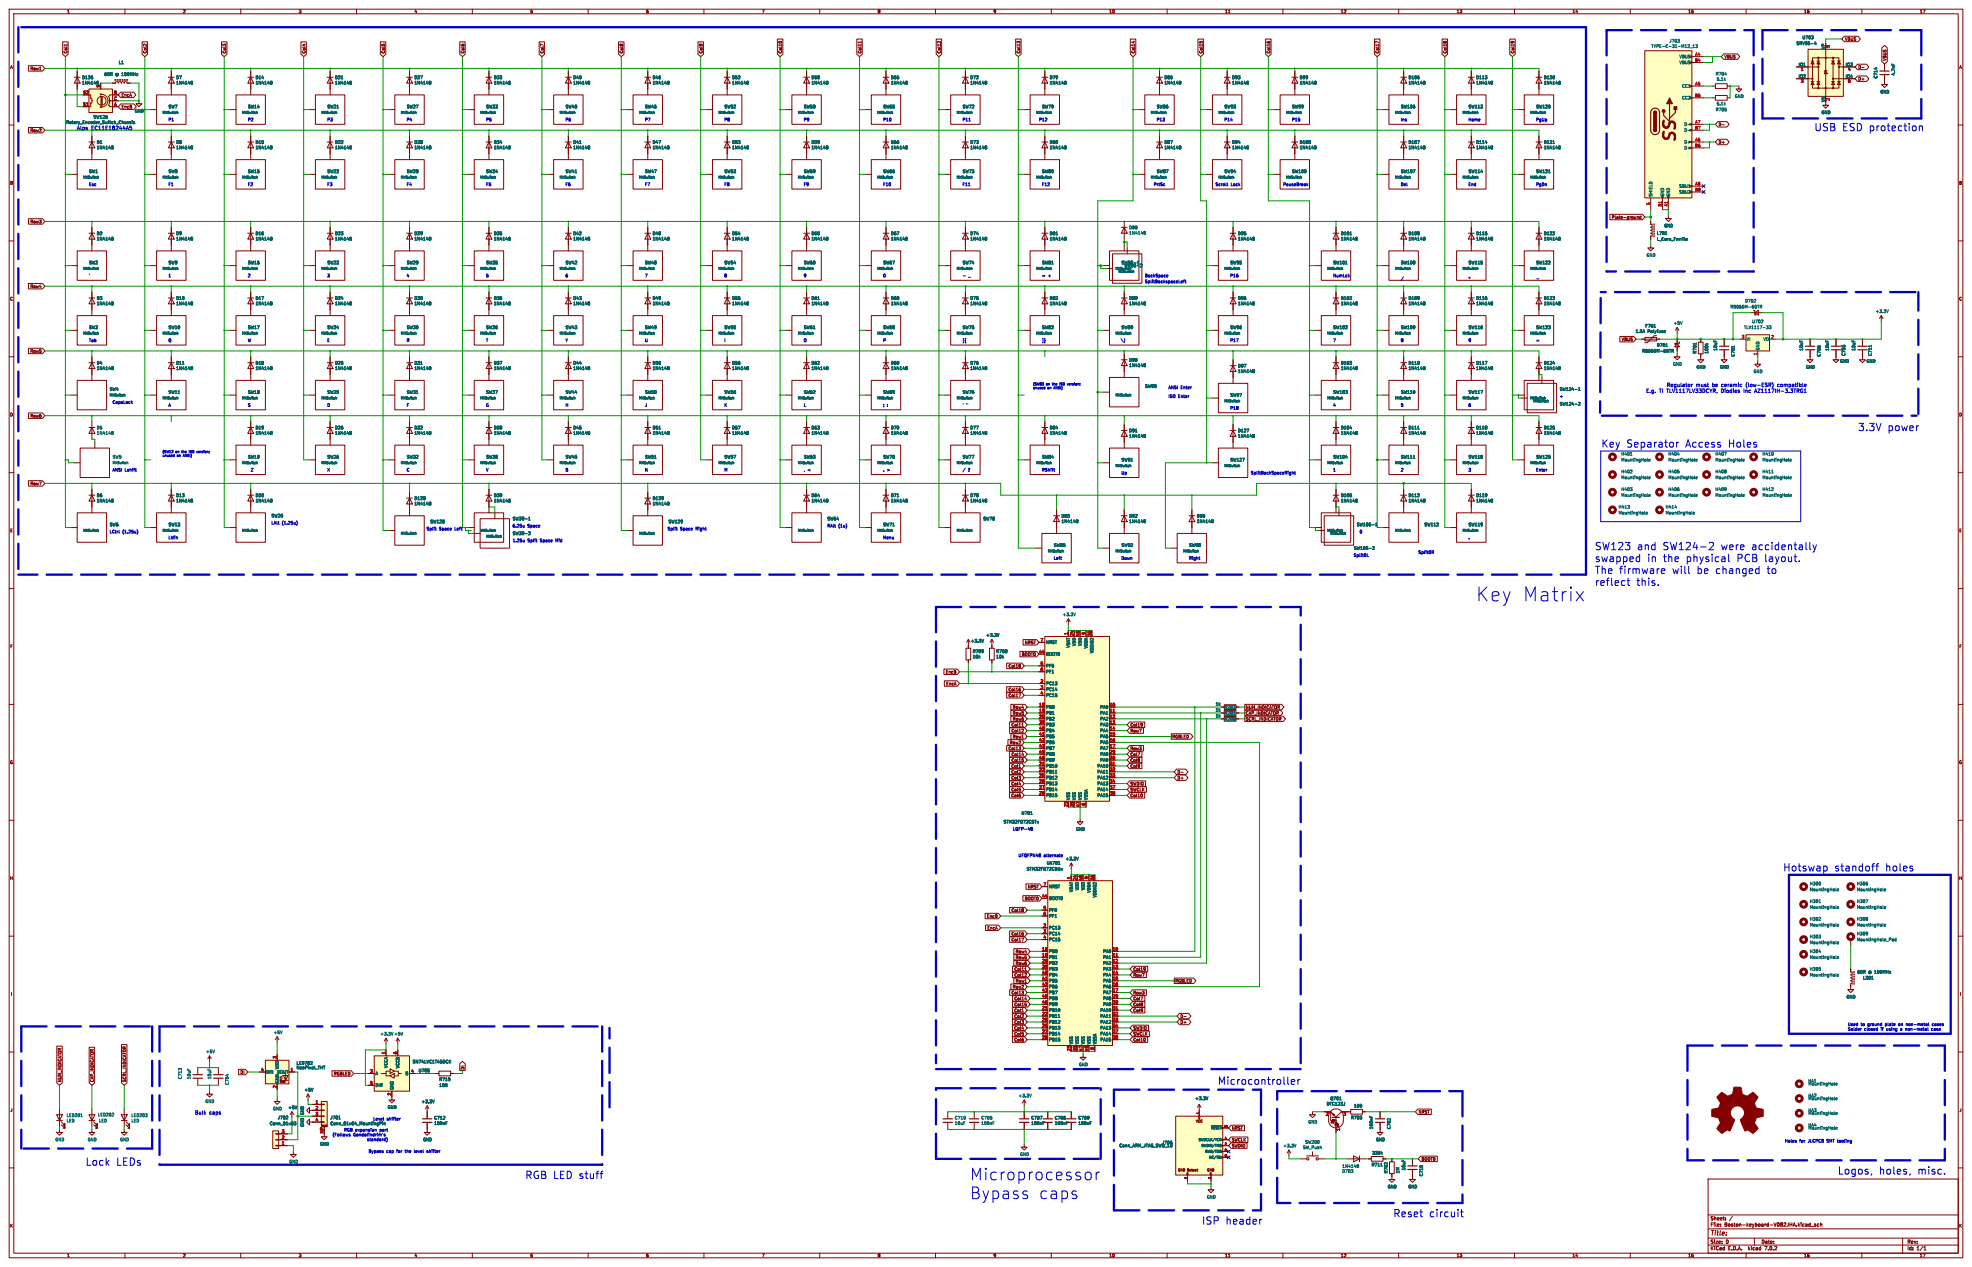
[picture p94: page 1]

ISO Enter ANSI Enter

SW39-2 MXSwitch SW128 MXSwitch SW11 MXSwitch SW13 MXSwitch D6

(SW12 on the ISO version; unused on ANSI) A

Key Separator Access Holes

6.25u Space Split Space Left

swapped in the physical PCB layout.
The firmware will be changed to
reflect this.

HA4 MountingHole HA3 MountingHole HA1 MountingHole HA2 MountingHole

Holes for JLCPCB SMT tooling

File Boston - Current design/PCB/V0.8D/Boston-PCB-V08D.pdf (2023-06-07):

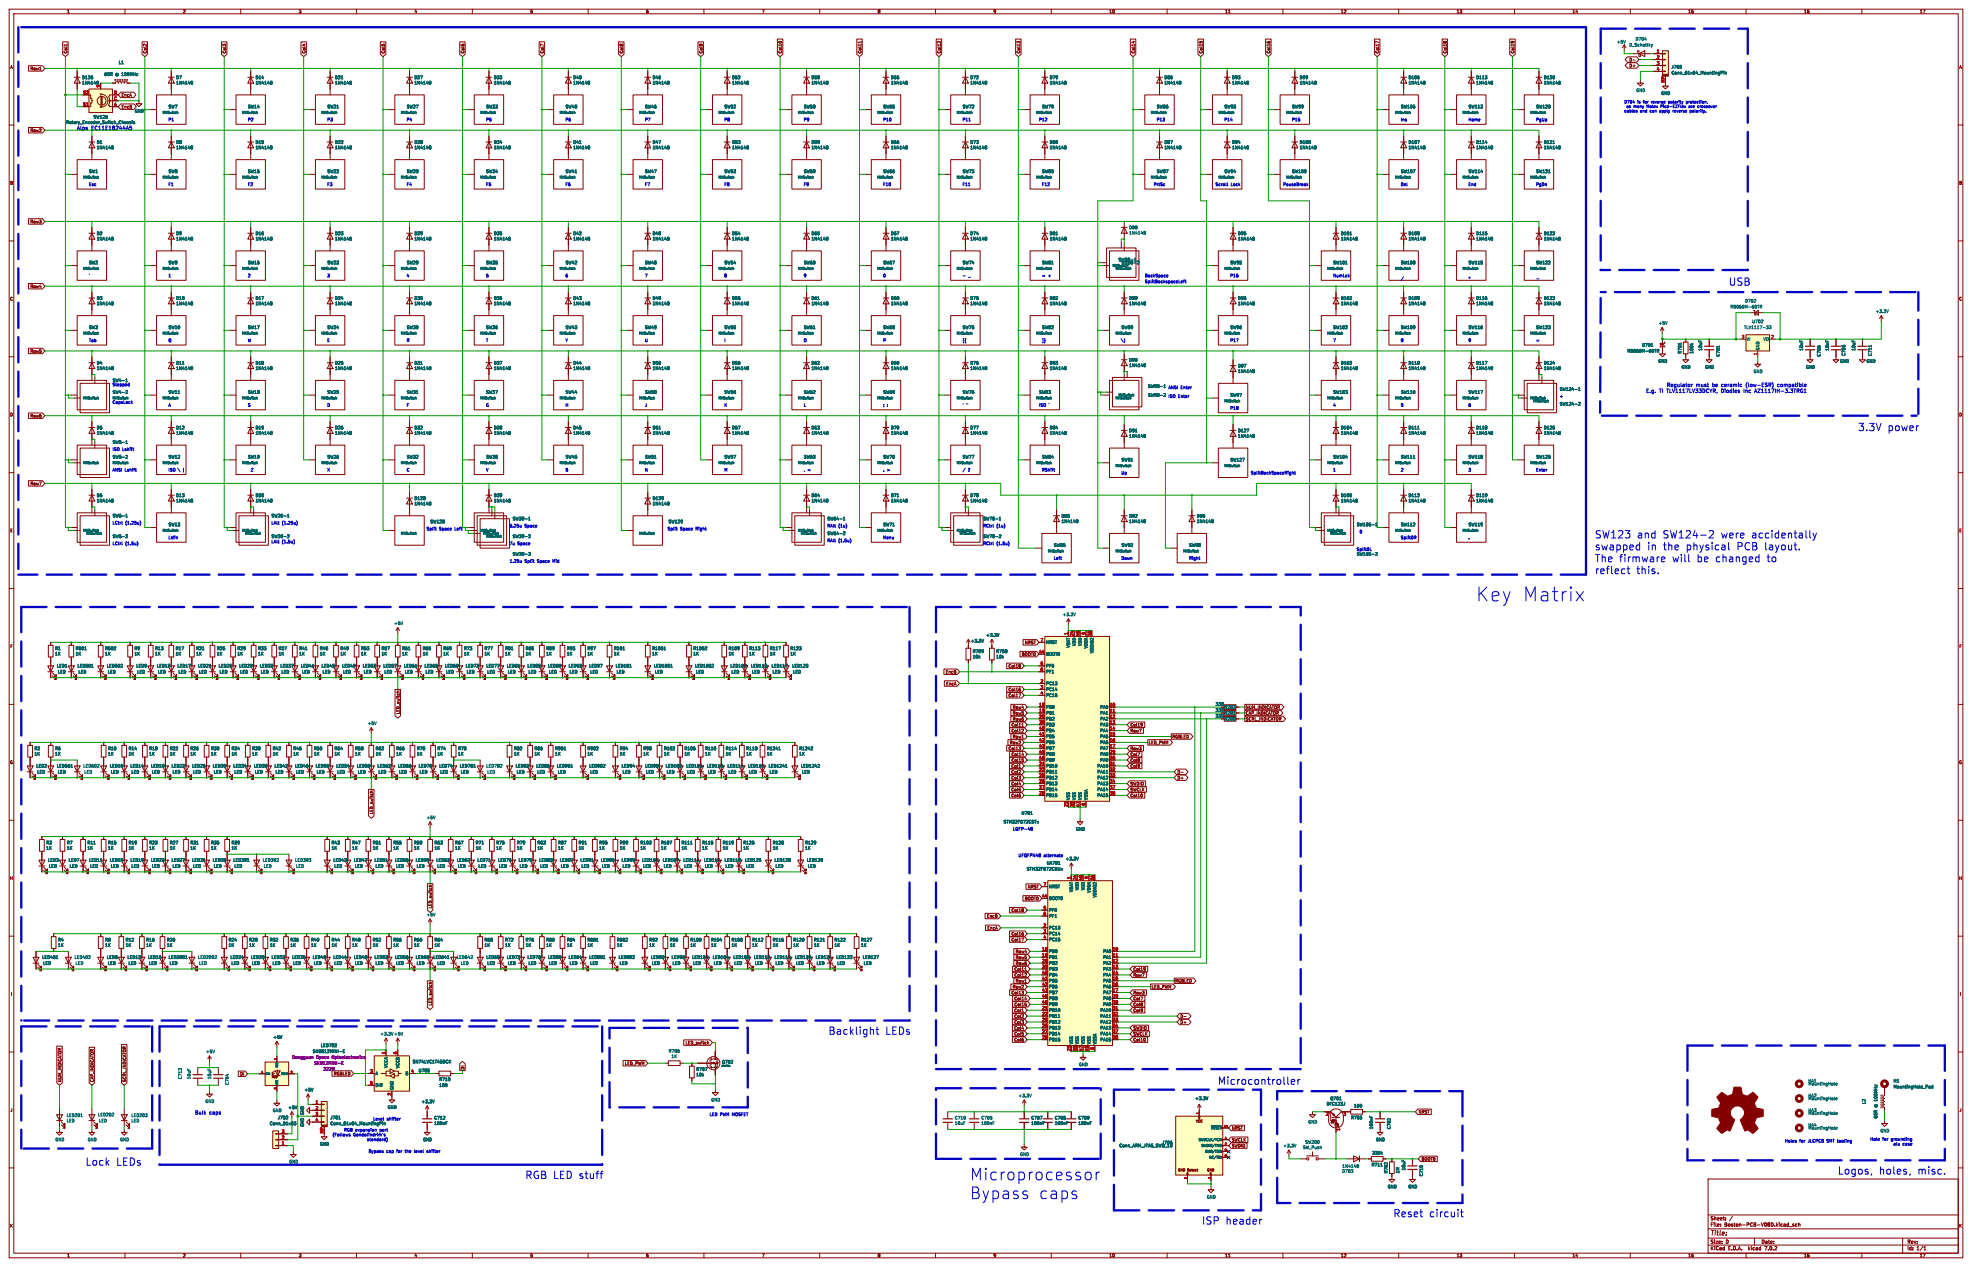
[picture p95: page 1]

SW19 MXSwitch D12
ISO Lshift LCtrl (1.5u) ANSI Lshift

swapped in the physical PCB layout.
The firmware will be changed to
reflect this.

Holes for JLCPCB SMT tooling

Bypass cap for the level shifter

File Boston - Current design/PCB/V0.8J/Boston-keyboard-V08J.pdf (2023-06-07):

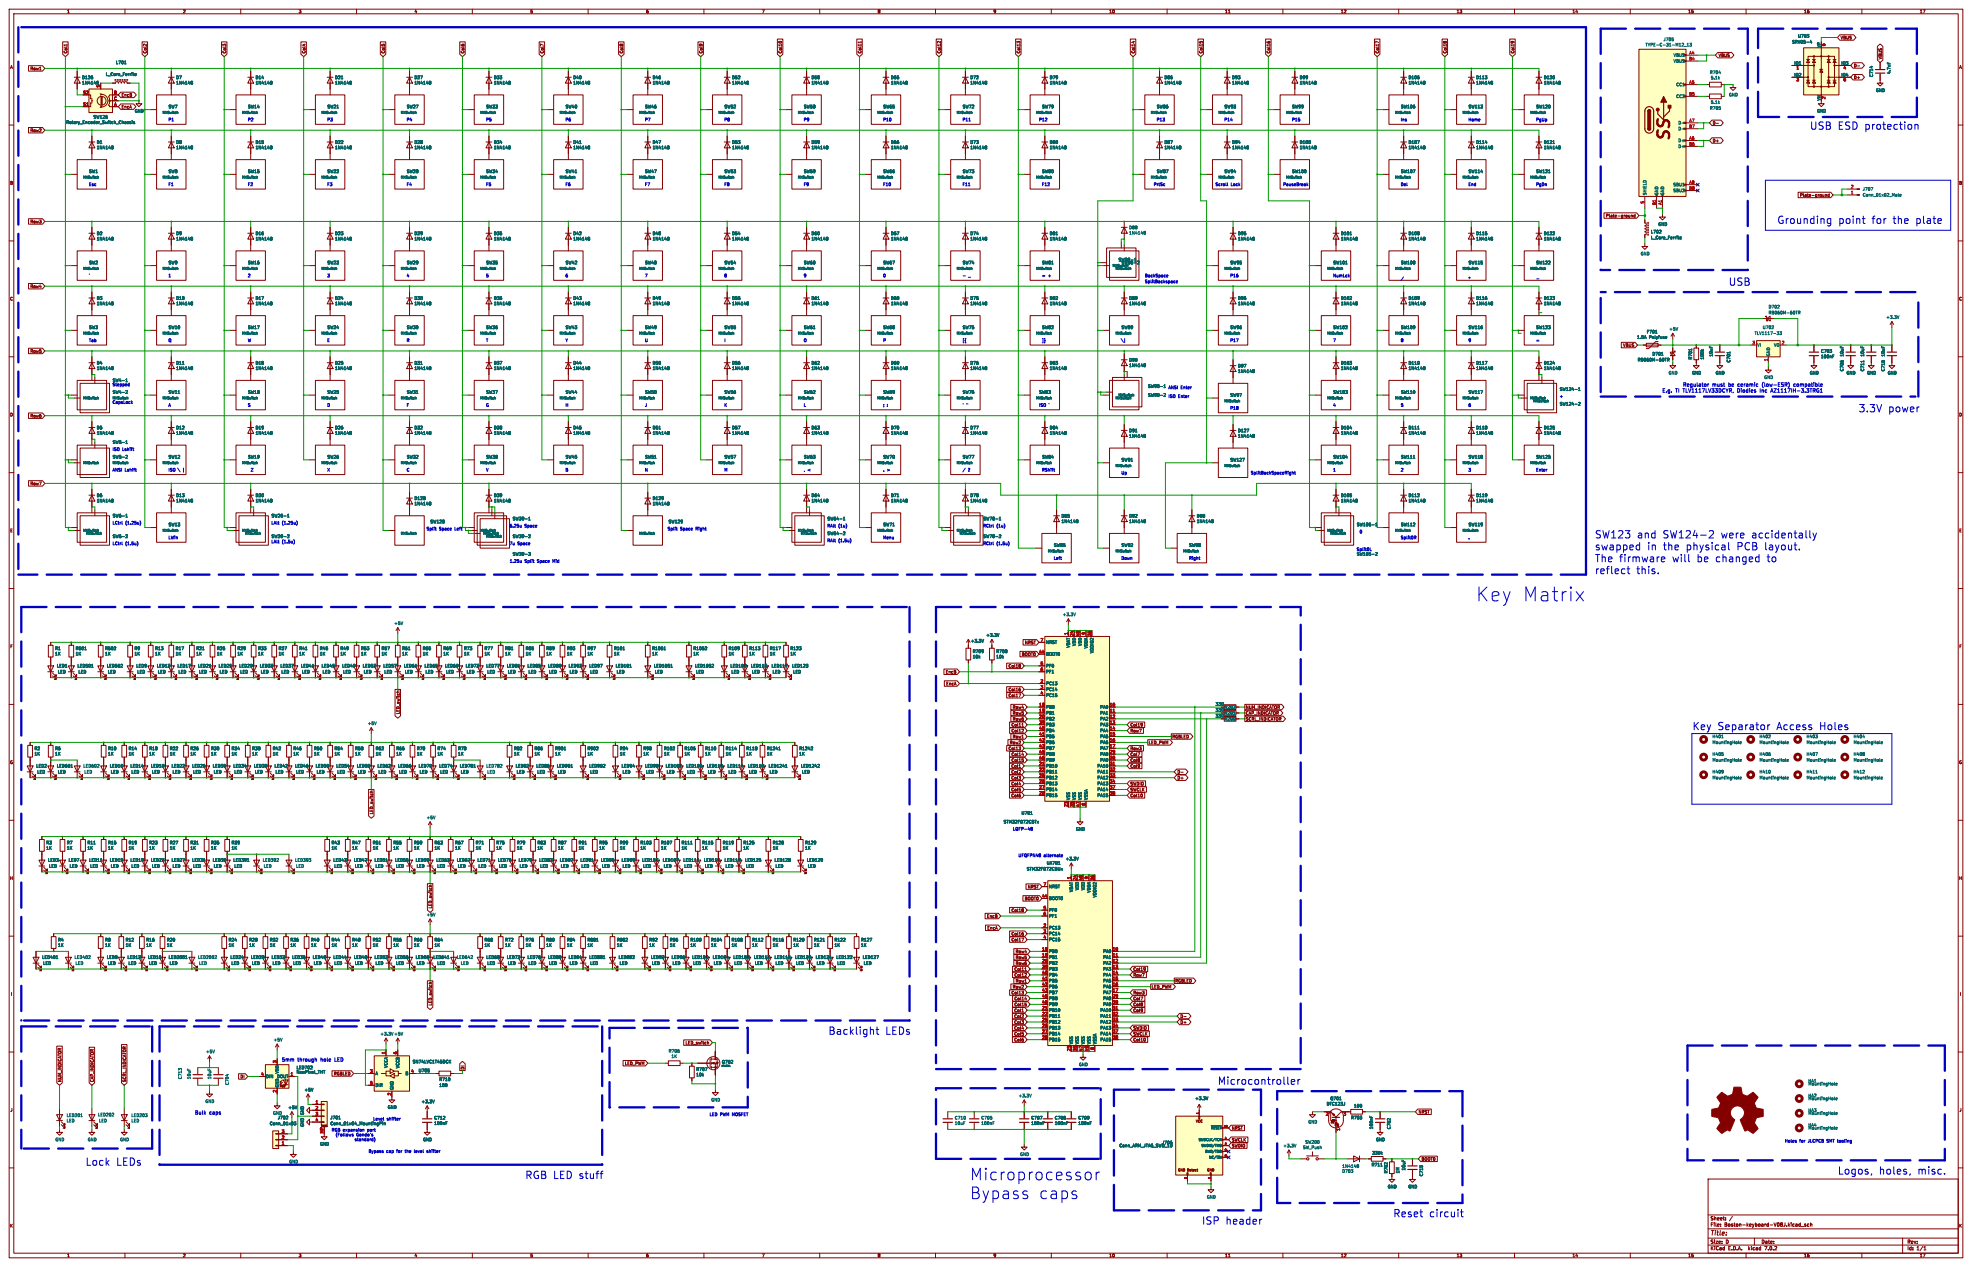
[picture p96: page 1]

swapped in the physical PCB layout.
The firmware will be changed to
reflect this.

Key Separator Access Holes

HA1 MountingHole HA4 MountingHole HA3 MountingHole HA2 MountingHole

Holes for JLCPCB SMT tooling

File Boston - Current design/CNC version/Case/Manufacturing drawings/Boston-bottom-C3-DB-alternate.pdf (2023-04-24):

D

1

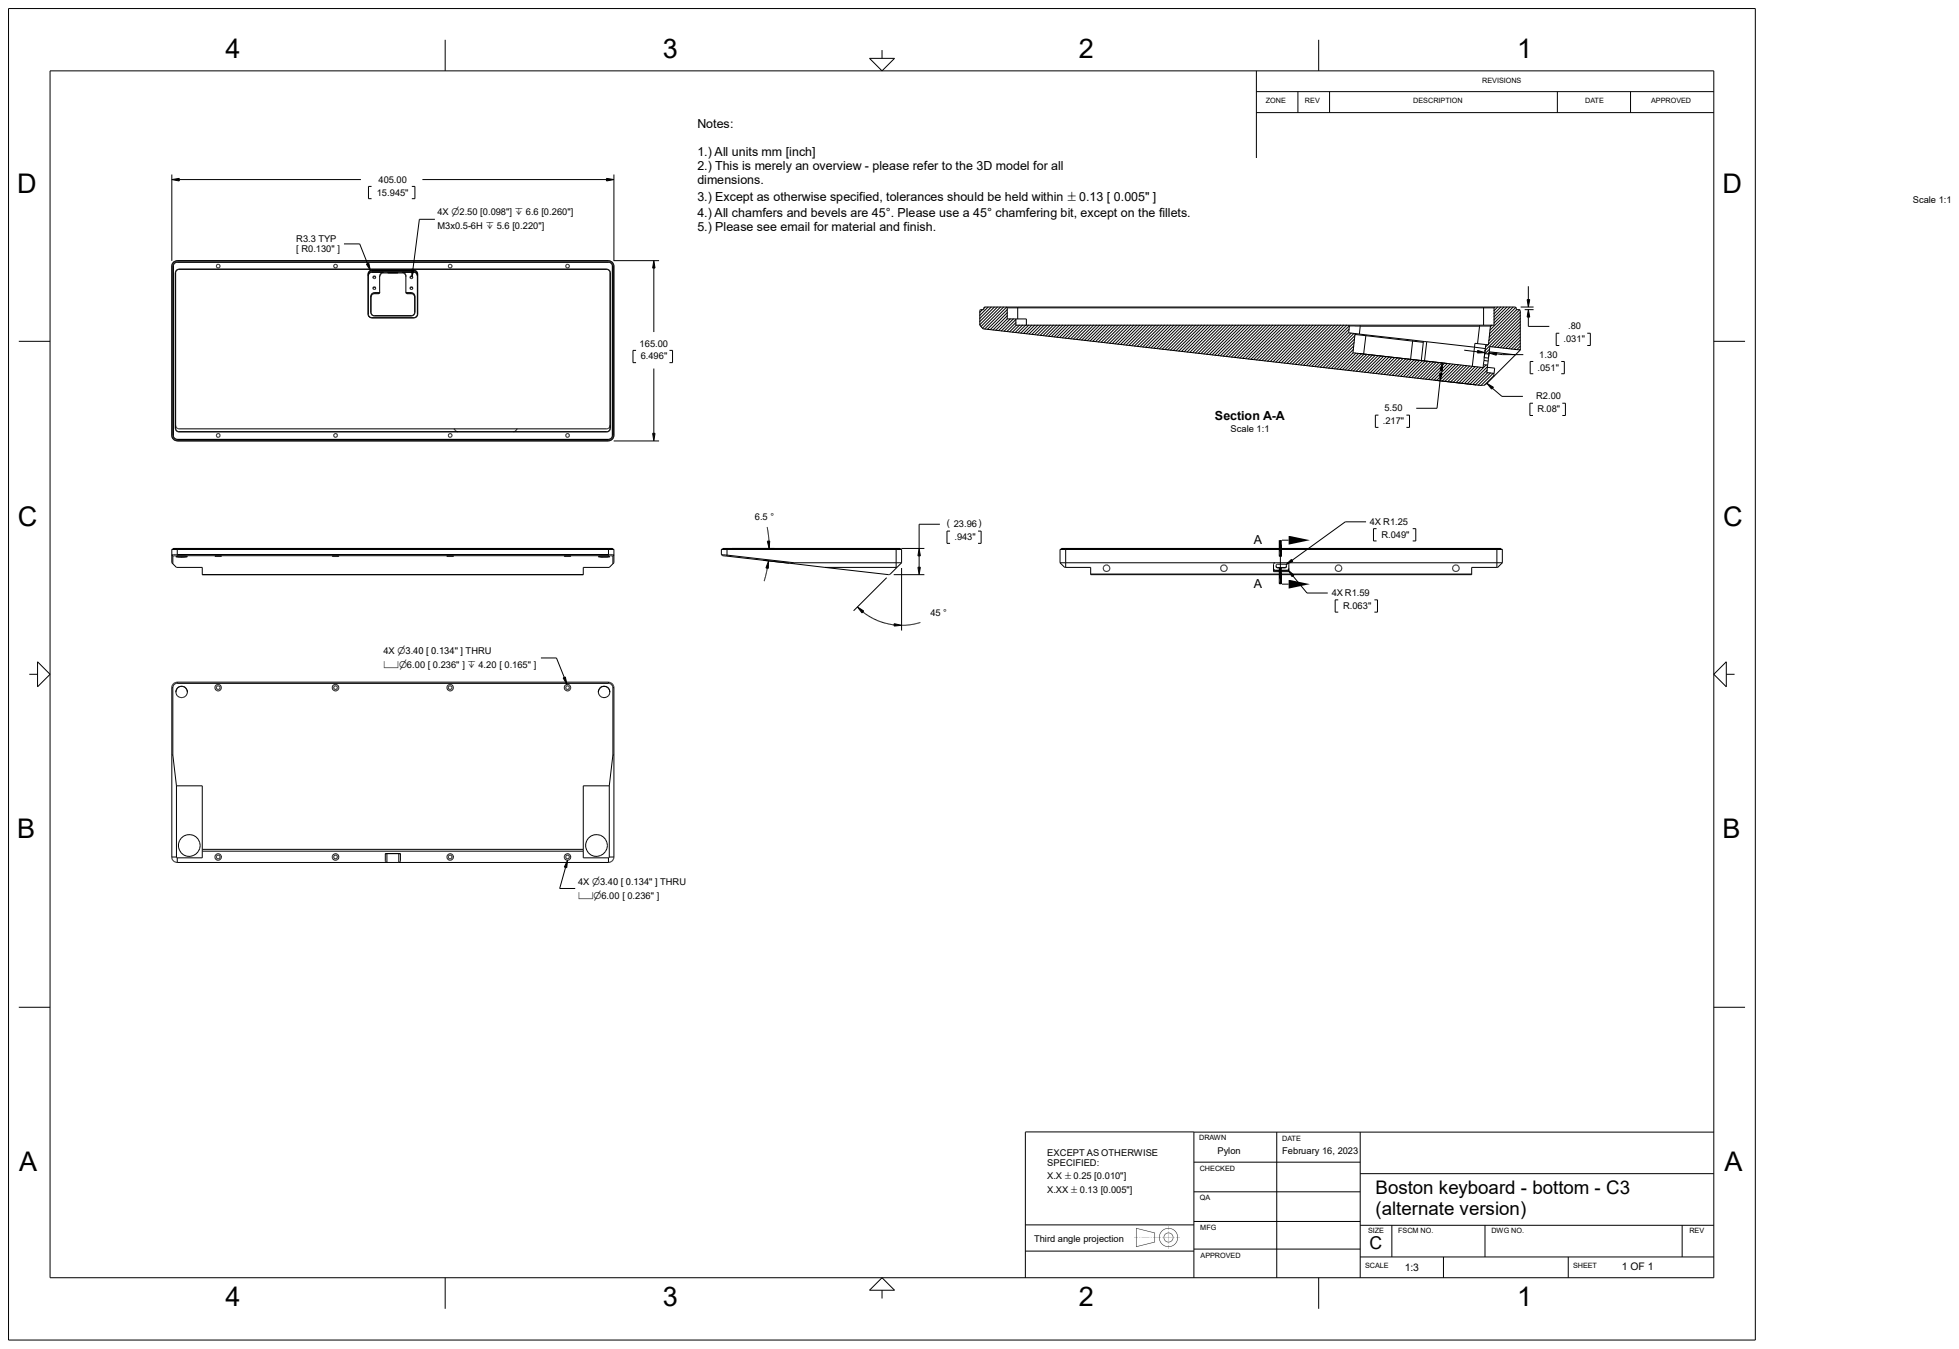
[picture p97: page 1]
6.496" R3.3 TYP; 4X n3.40 [ 0.134" ] THRU vn6.00 [ 0.236" ] x 4.20 [ 0.165" ]; 4X n3.40 [ 0.134" ] THRU vn6.00 [ 0.236" ]; R.08" Section A-A; .217" Scale 1:1; 1 SIZE; A CHECKED MFG; FSCM NO. 1:3; 1 OF 1 EXCEPT AS OTHERWISE SPECIFIED: X.X `0.25 [0.010"] X.XX `0.13 [0.005"]; Scale 1:1 Notes:

REVISIONS

ZONE | REV | DESCRIPTION | DATE | APPROVED

1.) All units mm [inch]
2.) This is merely an overview - please refer to the 3D model for all
dimensions.
3.) Except as otherwise specified, tolerances should be held within `0.13 [ 0.005" ]
4.) All chamfers and bevels are 45°. Please use a 45° chamfering bit, except on the fillets.
5.) Please see email for material and finish.

DRAWN Pylon | DATE
February 16, 2023 QA

Boston keyboard - bottom - C3
(alternate version)

Third angle projection | | DWG NO. | REV C

APPROVED

SCALE | SHEET

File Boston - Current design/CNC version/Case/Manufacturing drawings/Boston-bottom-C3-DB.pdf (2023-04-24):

1

D

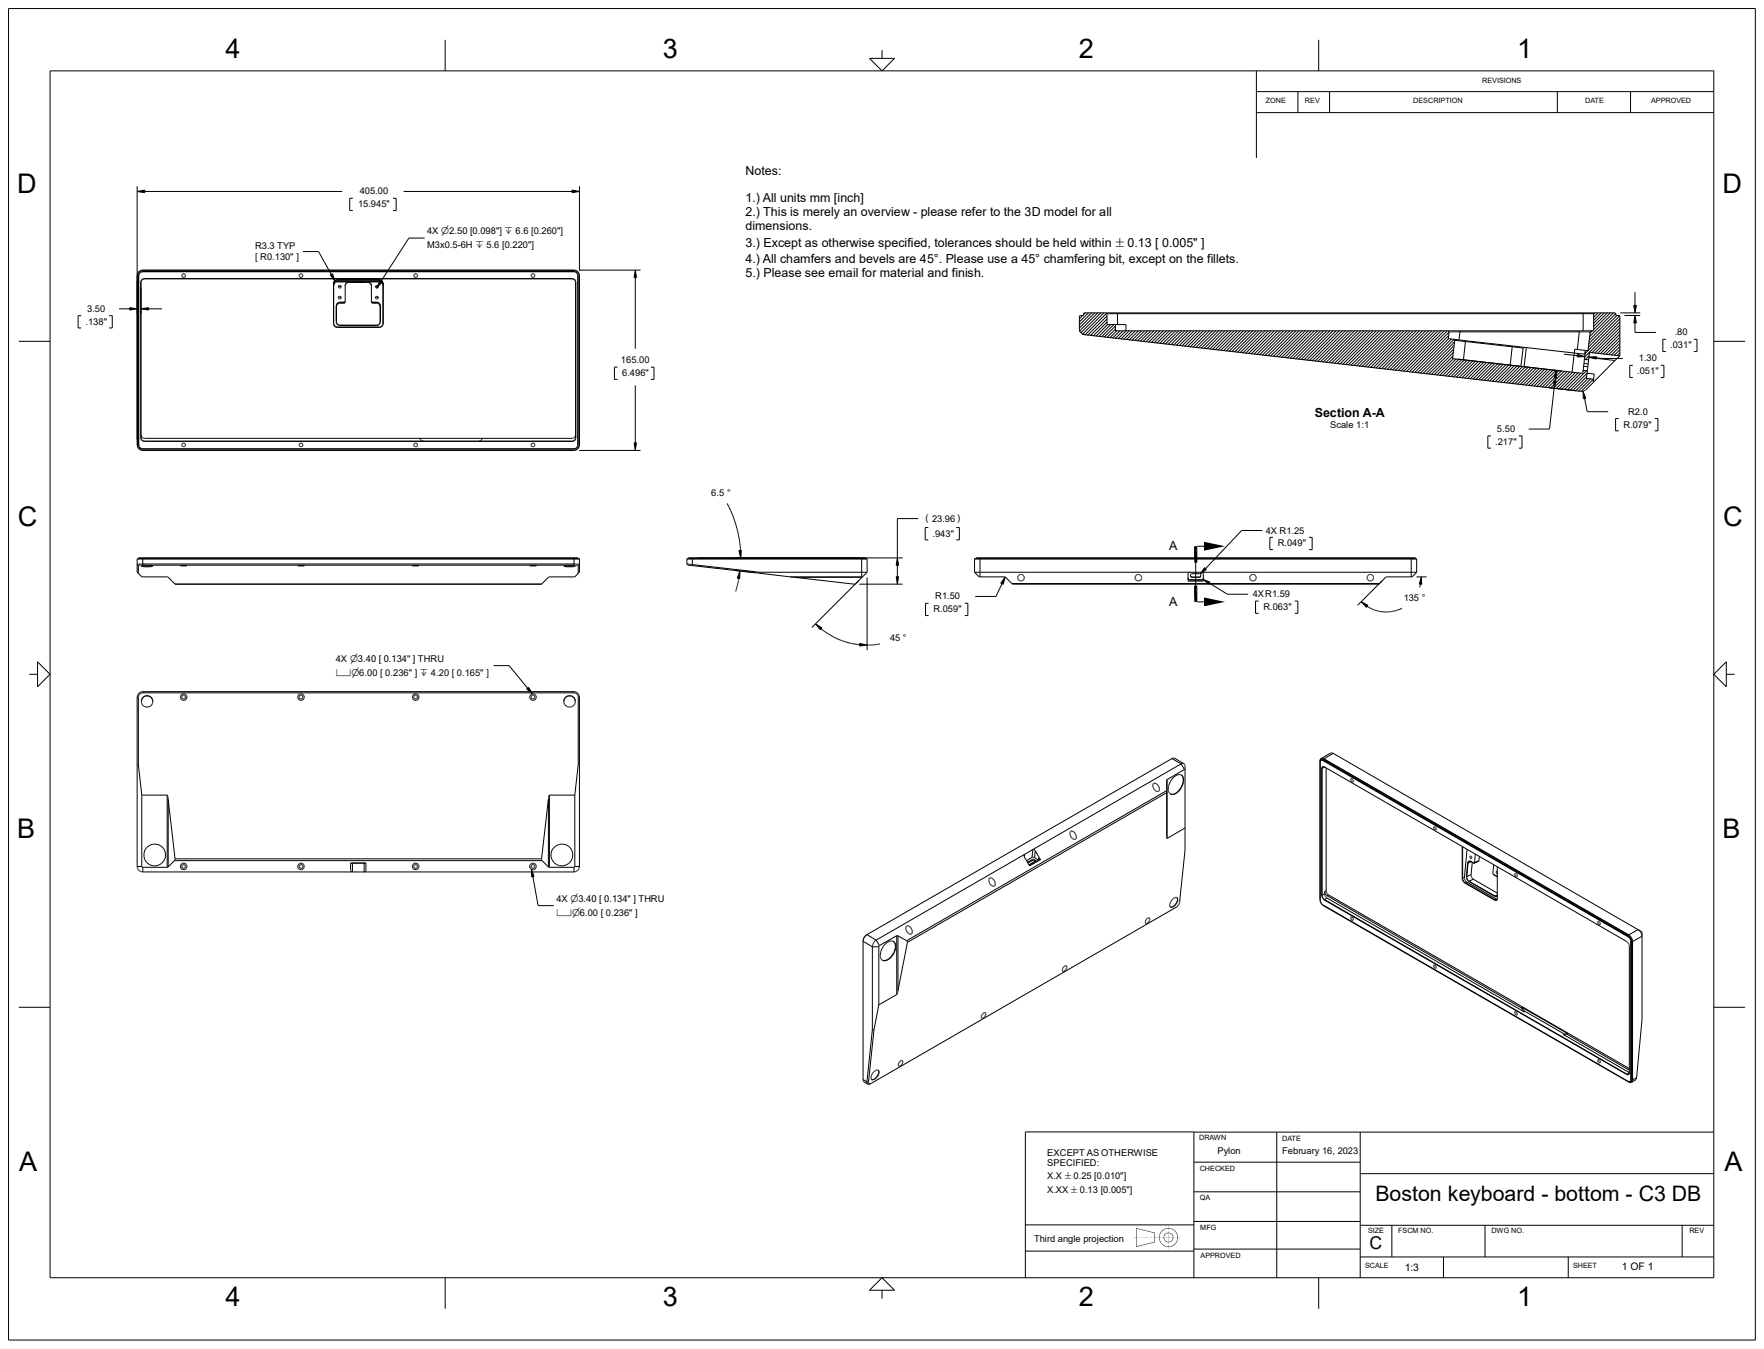
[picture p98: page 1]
4X n2.50 [0.098"] x 6.6 [0.260"] R3.3 TYP; 4X n3.40 [ 0.134" ] THRU vn6.00 [ 0.236" ] x 4.20 [ 0.165" ]; 4X n3.40 [ 0.134" ] THRU vn6.00 [ 0.236" ]; .80 .031" R2.0 R.079" Section A-A; Scale 1:1; FSCM NO. A; CHECKED; DATE; DWG NO.; APPROVED; ZONE; SCALE; SIZE; February 16, 2023; MFG; 4 SHEET; REVISIONS; 2 DESCRIPTION; REV; 1 OF 1 EXCEPT AS OTHERWISE SPECIFIED: X.X `0.25 [0.010"] X.XX `0.13 [0.005"]; Notes:

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

DATE QA DRAWN
Pylon

Boston keyboard - bottom - C3 DB

Third angle projection

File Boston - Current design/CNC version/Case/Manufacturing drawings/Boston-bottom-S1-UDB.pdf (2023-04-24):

3

4

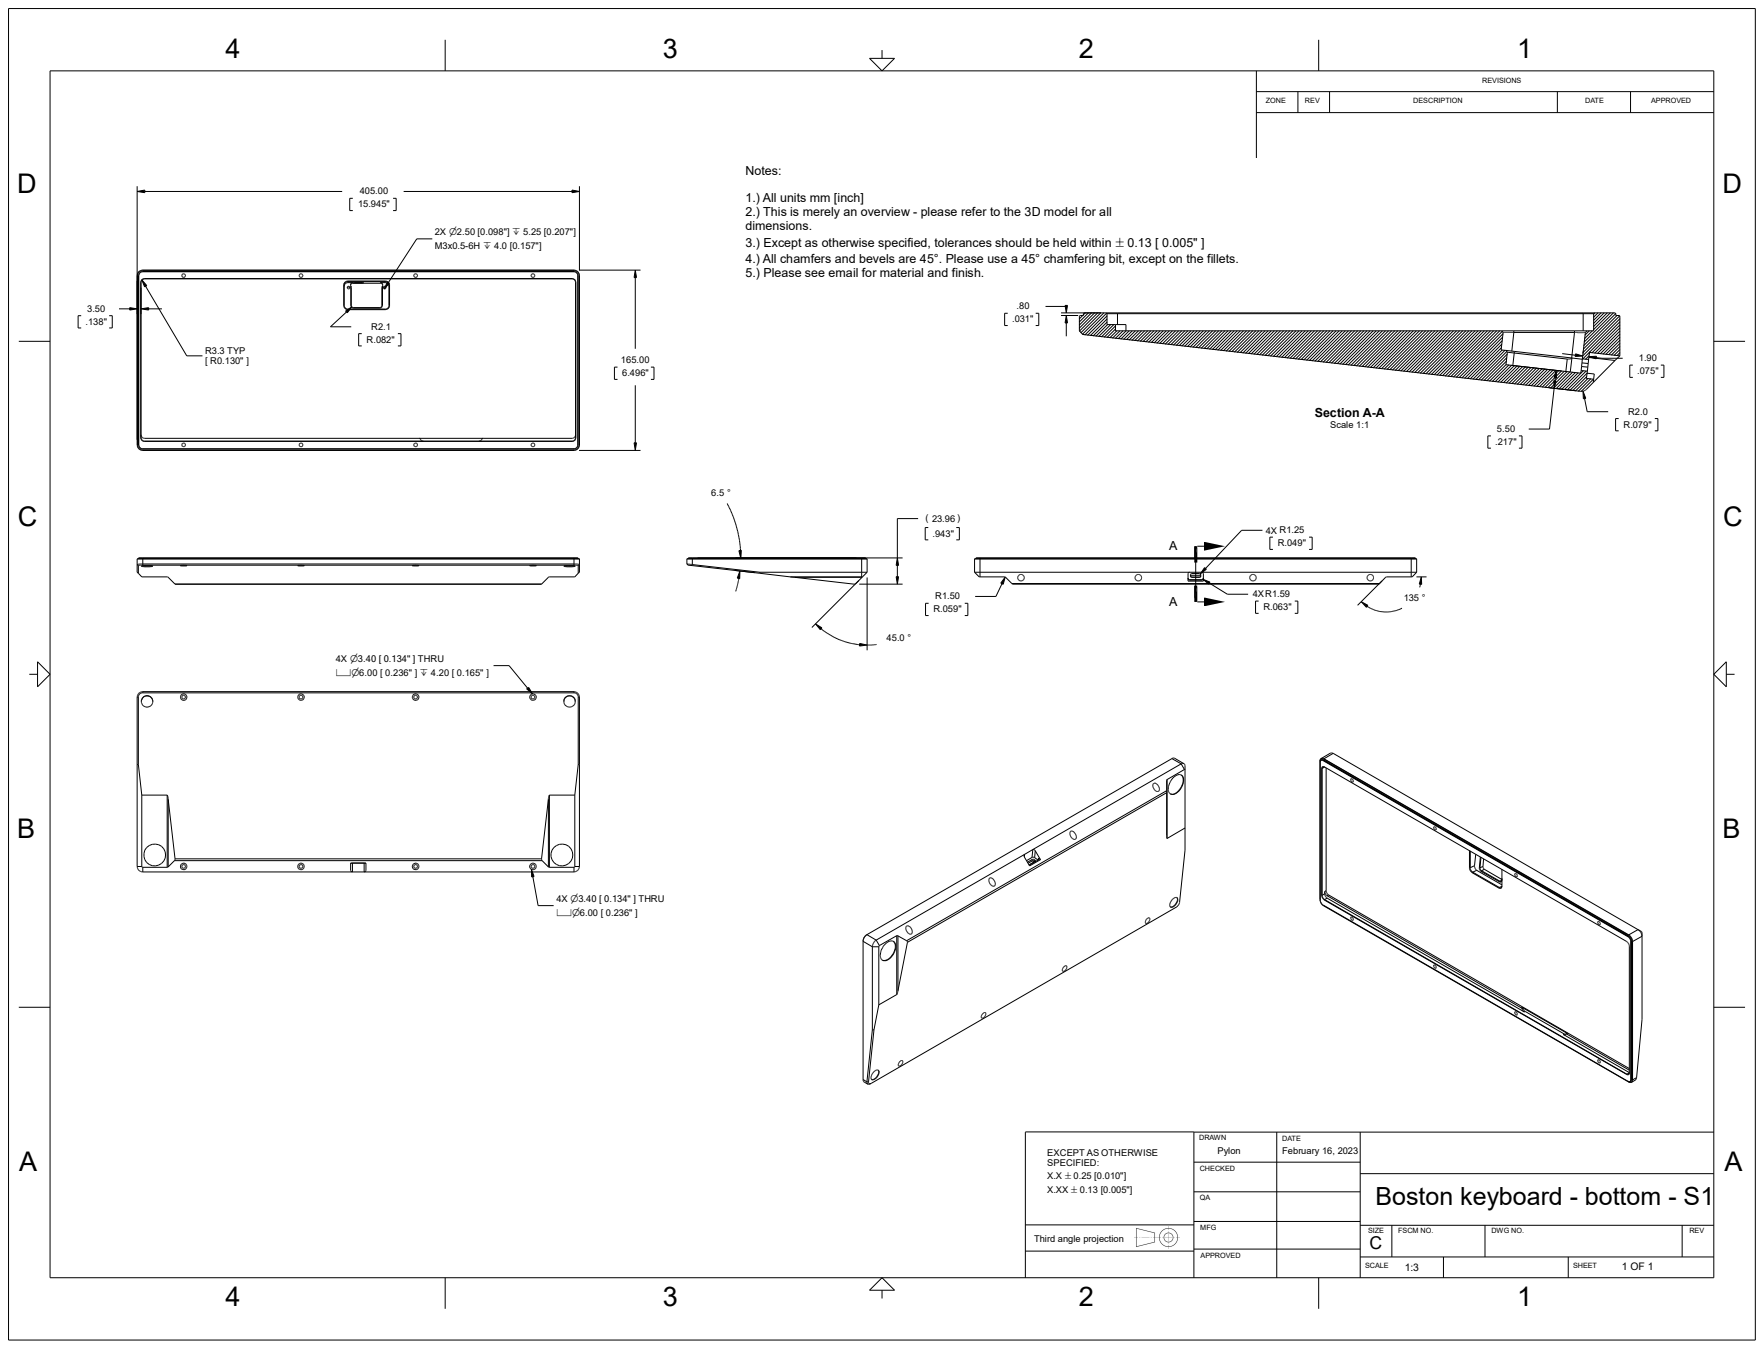
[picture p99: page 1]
R2.1 R.082" R3.3 TYP; 4X n3.40 [ 0.134" ] THRU vn6.00 [ 0.236" ] x 4.20 [ 0.165" ]; 4X n3.40 [ 0.134" ] THRU vn6.00 [ 0.236" ]; R2.0 R.079" Section A-A; Scale 1:1; APPROVED; CHECKED; DWG NO.; REV; DATE MFG; DRAWN; 2 DATE; 2 SCALE; FSCM NO. C; ZONE; February 16, 2023; SIZE; DESCRIPTION; REVISIONS; APPROVED 4 SHEET; 1 OF 1 EXCEPT AS OTHERWISE SPECIFIED: X.X `0.25 [0.010"] X.XX `0.13 [0.005"]; Pylon; Notes:

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

Boston keyboard - bottom - S1

Third angle projection

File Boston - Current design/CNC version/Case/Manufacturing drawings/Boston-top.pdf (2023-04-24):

## Section A-A

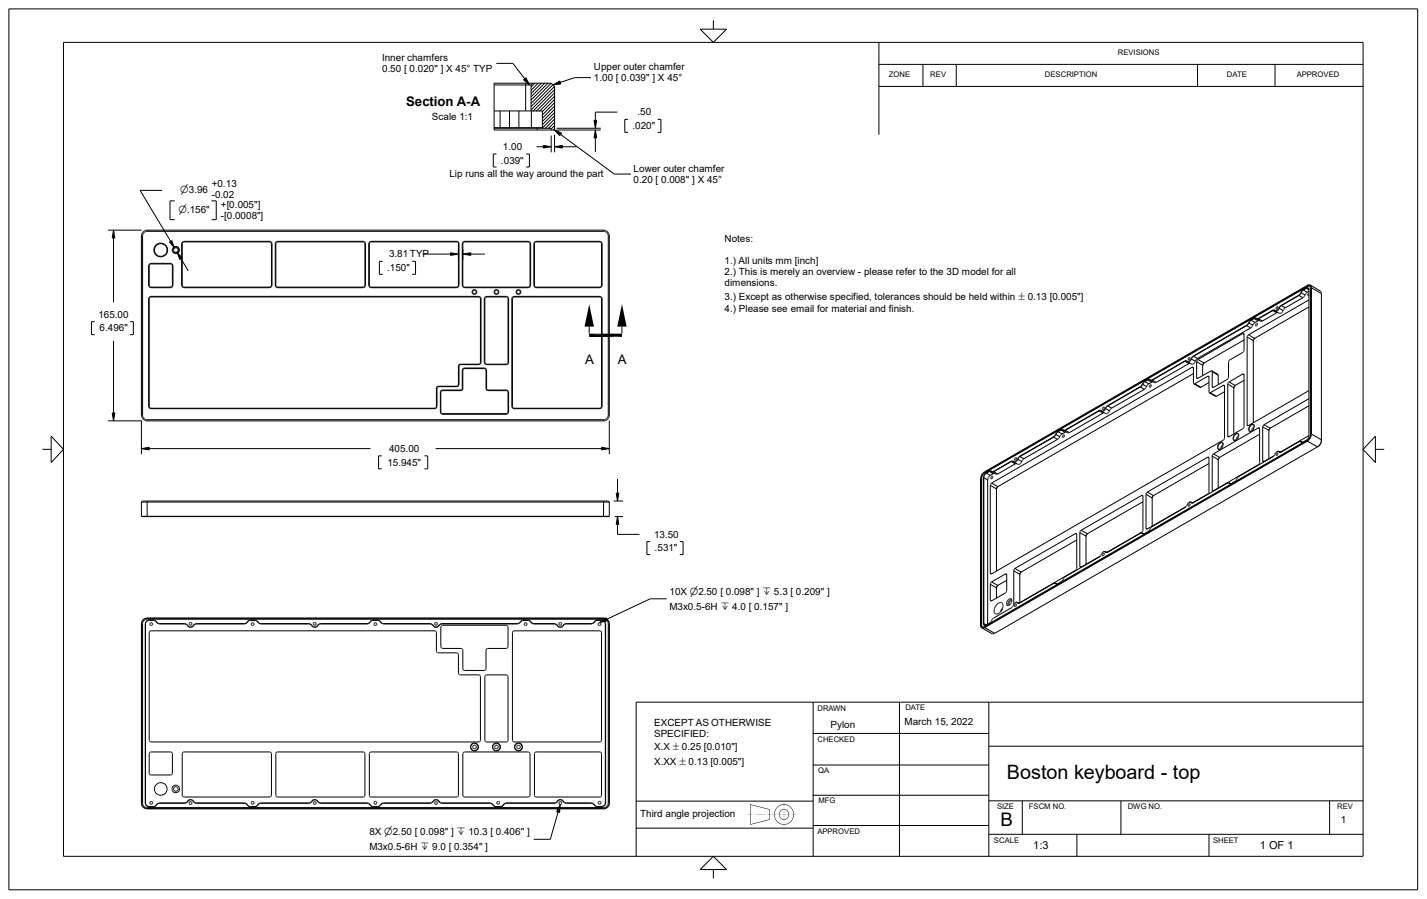
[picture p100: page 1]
TYP; Scale 1:1; Lip runs all the way around the part; Lower outer chamfer; Inner chamfers 0.50 [ 0.020" ] X 45° TYP; DRAWN; DATE; SCALE; REVISIONS; ZONE; SIZE; March 15, 2022; REV; FSCM NO.; APPROVED; MFG; DWG NO.; SHEET; DESCRIPTION; CHECKED; EXCEPT AS OTHERWISE SPECIFIED: X.X `0.25 [0.010"] X.XX `0.13 [0.005"]; Pylon; Notes:

Upper outer chamfer

1.) All units mm [inch]
2.) This is merely an overview - please refer to the 3D model for all
dimensions.
3.) Except as otherwise specified, tolerances should be held within `0.13 [0.005"]
4.) Please see email for material and finish.

Boston keyboard - top

Third angle projection

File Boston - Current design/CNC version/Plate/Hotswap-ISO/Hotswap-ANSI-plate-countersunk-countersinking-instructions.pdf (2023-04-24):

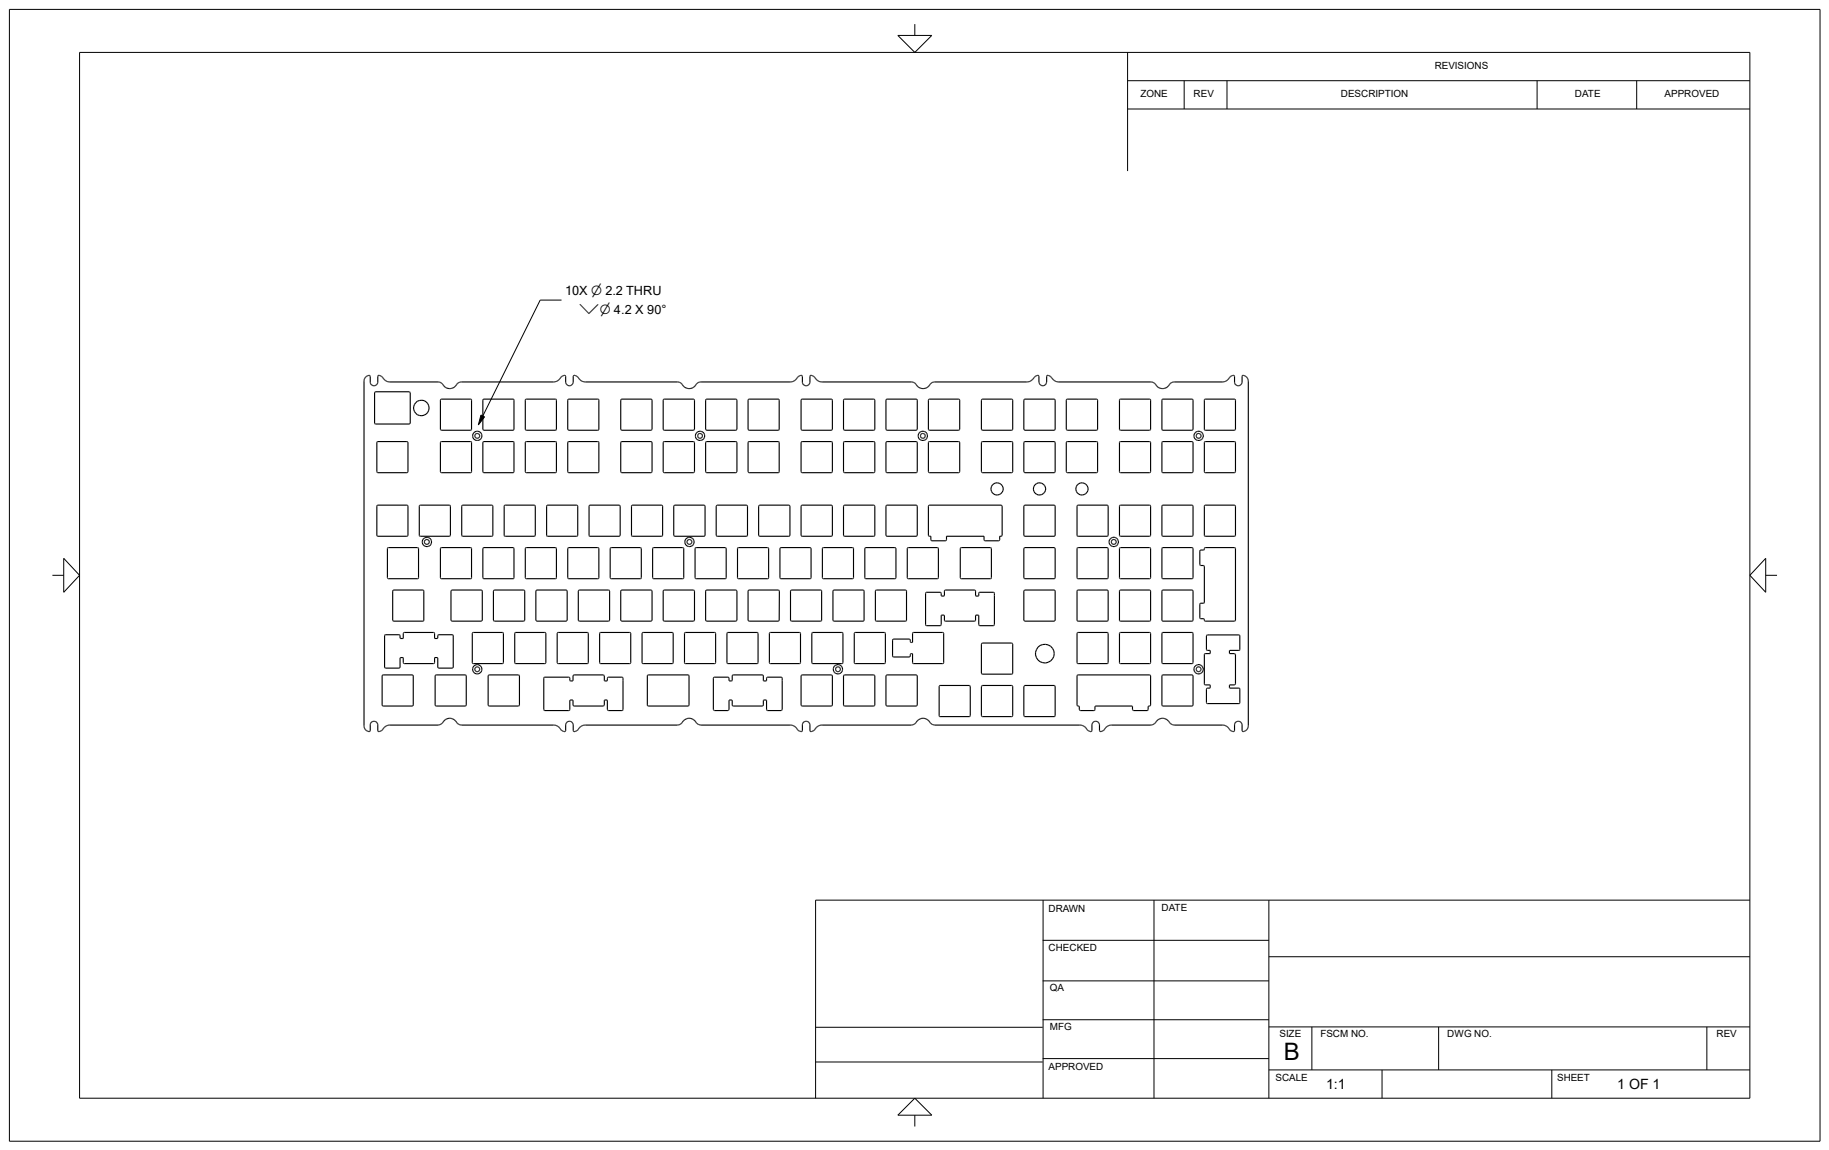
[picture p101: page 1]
10X n 2.2 THRU wn 4.2 X 90°; SHEET; ZONE; REVISIONS; APPROVED; REV; SIZE; DWG NO.; DESCRIPTION; DRAWN; DATE; MFG; FSCM NO.; SCALE; CHECKED

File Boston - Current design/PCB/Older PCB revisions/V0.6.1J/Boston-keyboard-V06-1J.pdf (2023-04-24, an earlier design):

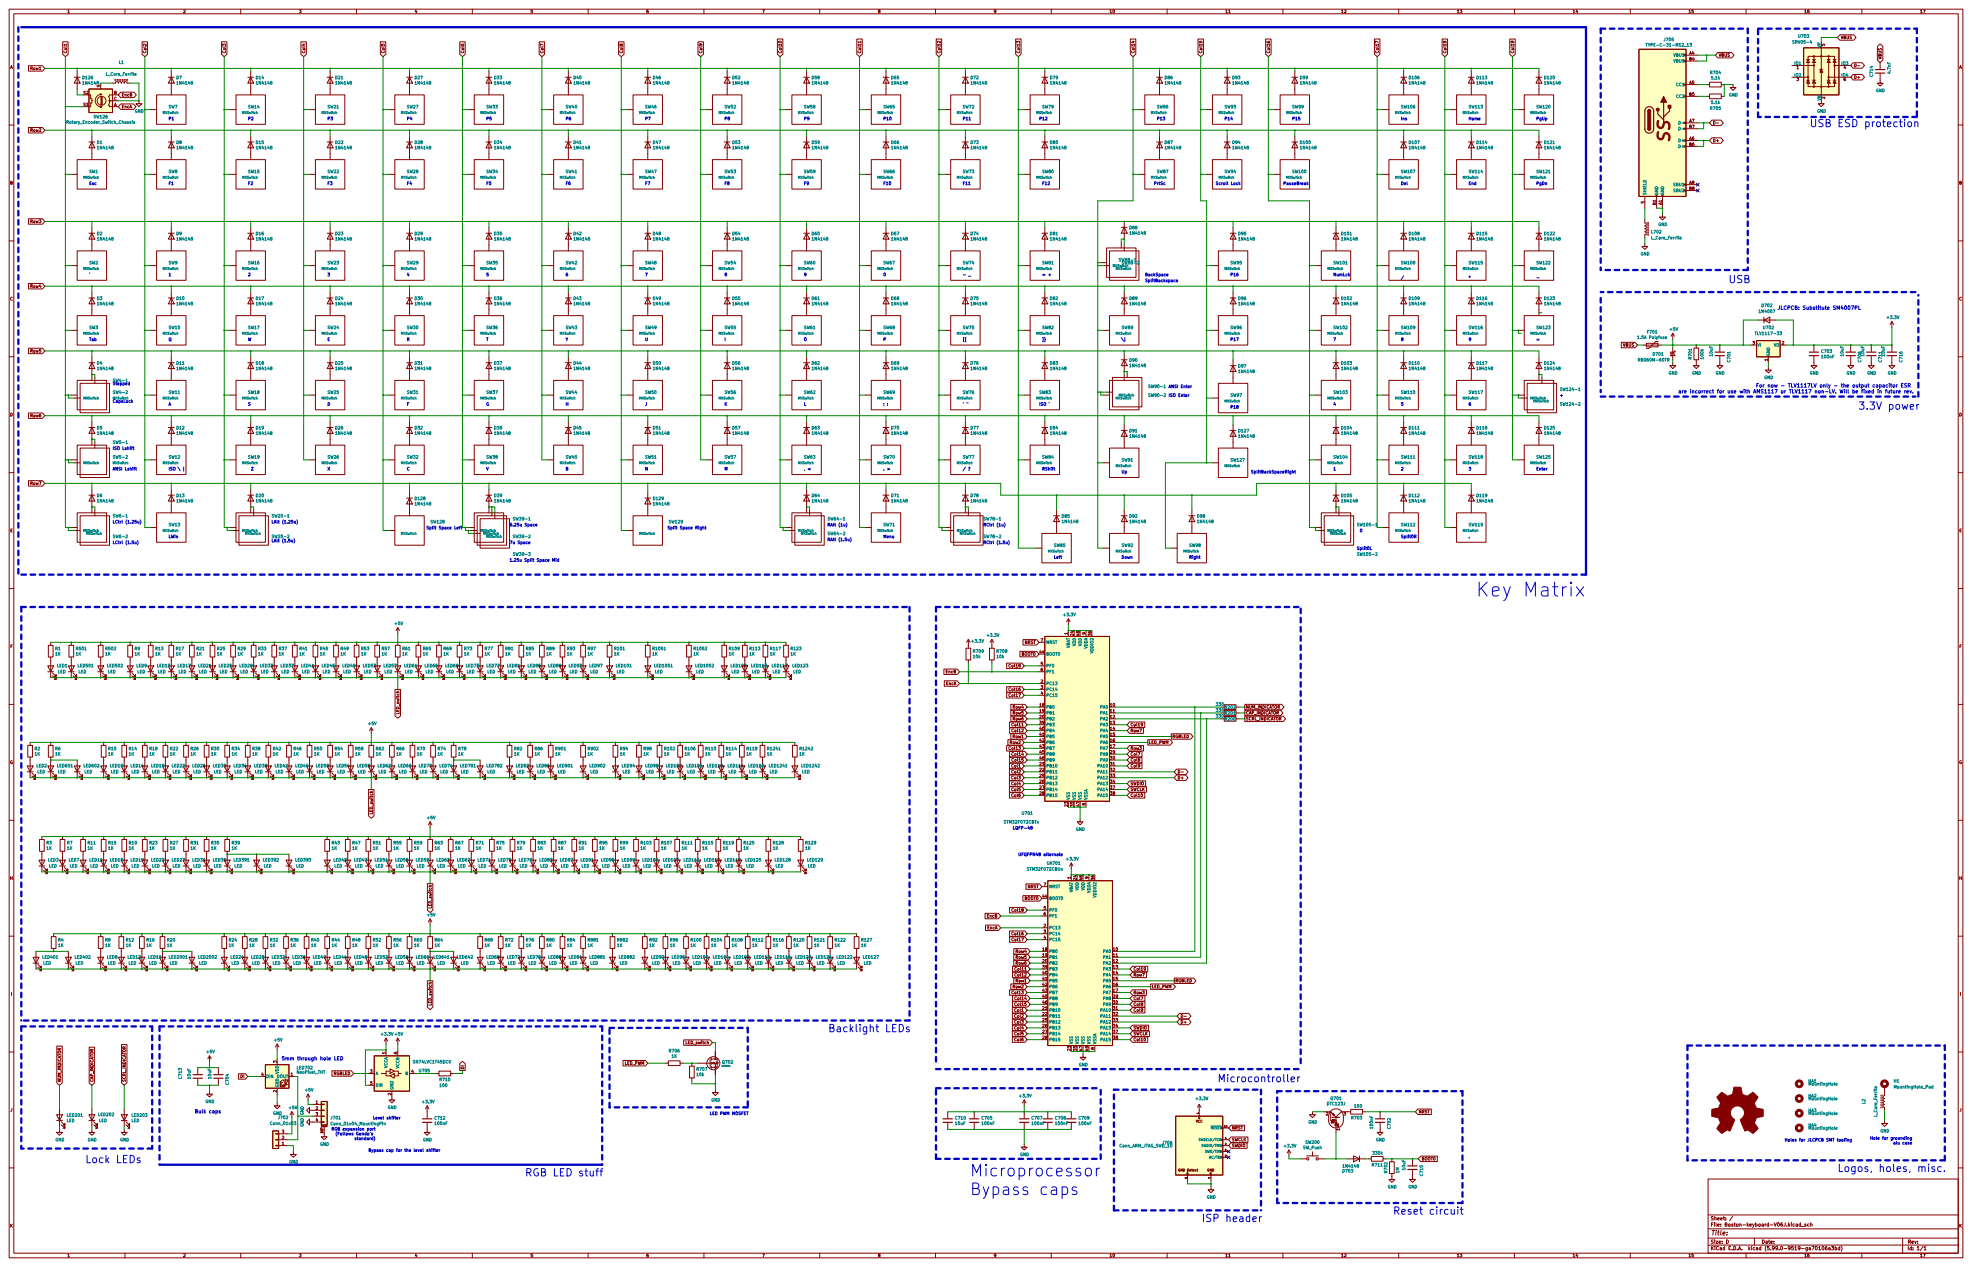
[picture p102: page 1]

ISO Enter ANSI Enter

are incorrect for use with AMS1117 or TLV1117 non-LV. Will be fixed in future rev.

Holes for JLCPCB SMT tooling

Bypass cap for the level shifter

File: Boston-keyboard-V06J.kicad_sch Sheet: /

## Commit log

2023-04-24 Switched to AP242 to resolve an Atom3D export bug
    The screws were not showing up correctly
2023-04-30 Updated JLCPCB options to reflect current site
2023-04-30 Draft JLCPCB files for V0.8D
    [BOM.xls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]
2023-04-30 Updated graphics so they reflect current JLCPCB website
2023-04-30 Fixed incorrect quantity of M3x0.5mm 5mm screw (README specified too many)
2023-04-30 Added draft assembly guide for the S1 DB variant
2023-04-30 Updated info on standoff screws
2023-05-20 Updated hotswap PCBs (fixed stabilizer and silkscreen errors)
    [BOM.xls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]
2023-05-21 Removed unused ISO left shift reference in the schematic
    [Boston-keyboard-V082DHA.kicad_sch, Boston-keyboard-V082JHA.kicad_sch]
2023-05-21 Started work on V0.8.2DHI (ISO hotswap PCB for the CNC version)
    [Boston-keyboard-V082DHI.kicad_sch]
2023-05-29 Added a table to clarify the PCB variants and their statuses
2023-05-29 Added BOM and CPL files with the RGBLED
    [BOM-w-RGBLED.xls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]
2023-05-29 Made JLC SMT files for V0.8.2DHA
    [BOM.xls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]
2023-05-29 Standardized certain component line #'s in the BOM between different PCB variants
    I refer to these lines in the ordering guide as parts that can be swapped out in case they are out of stock
    [BOM.xls]
2023-05-29 Took initial pass at designing the V0.8.2DHI
    [Boston-keyboard-V082DHI.kicad_sch]
2023-06-04 Made manufacturing files for V0.8.2DHI
    [Boston-keyboard-V082DHI-B_Cu.gbr, Boston-keyboard-V082DHI-B_Fab.gbr, Boston-keyboard-V082DHI-B_Mask.gbr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]
2023-06-07 Added note that SW123 and SW124-2 were accidentally swapped in the PCB layout
    [Boston-PCB-V08D.kicad_sch, Boston-keyboard-V06-1D.kicad_sch, Boston-keyboard-V07J.kicad_sch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]
2023-06-20 Added DatGameh's 0.5 degree case
2023-06-21 Clarified plate compatibility
2023-06-27 Made an abomination
    [Experimental-full-universal-plate.kicad_pcb, Experimental-full-universal-plate.kicad_sch]
2023-06-27 Rounded off some sharp corners near the backspace key
    [FR4-hotswap-ANSI-plate-B_Cu.gbr, FR4-hotswap-ANSI-plate-B_Mask.gbr, FR4-hotswap-ANSI-plate-B_Paste.gbr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]
2023-06-27 Fixed some other sharp corners
    [3DP-FR4-hotswap-plate-ANSI-B_Cu.gbr, 3DP-FR4-hotswap-plate-ANSI-B_Mask.gbr, 3DP-FR4-hotswap-plate-ANSI-B_Paste.gbr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]
2023-06-27 Fixed some sharp corners
    [Boston-M-Universal-Plate.dxf, Boston-M-Universal-plate-soldered.dxf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]
2023-06-27 Removed sharp corners from the plate
2023-06-29 Forgot to up the version when fixing the sharp corners
    [FR4-hotswap-ANSI-plate-B_Cu.gbr, FR4-hotswap-ANSI-plate-B_Mask.gbr, FR4-hotswap-ANSI-plate-B_Paste.gbr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]
2023-06-29 Fixed a board outline issue that KiCAD DRC was complaining about
    [FR4-hotswap-ANSI-plate-B_Cu.gbr, FR4-hotswap-ANSI-plate-B_Mask.gbr, FR4-hotswap-ANSI-plate-B_Paste.gbr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]
2023-06-29 Refilled copper zones
    [FR4-universal-layout-plate-B_Cu.gbr, FR4-universal-layout-plate-B_Mask.gbr, FR4-universal-layout-plate-B_Paste.gbr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]
2023-06-29 Rounded off sharp corners
    [3DP-FR4-plate-top-reset-cutout-B_Cu.gbr, 3DP-FR4-plate-top-reset-cutout-B_Mask.gbr, 3DP-FR4-plate-top-reset-cutout-B_Paste.gbr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]
2023-07-04 Renamed some of the plate files to reduce confusion; finished ISO hotswap plate
    [3DP-FR4-hotswap-plate-ANSI.kicad_pcb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]
2023-07-04 ISO plate files
    [FR4-hotswap-ISO-plate-B_Cu.gbr, FR4-hotswap-ISO-plate-B_Mask.gbr, FR4-hotswap-ISO-plate-B_Paste.gbr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]
2023-08-01 Updated instructions with reset button instructions for V0.8 and newer PCBs
2023-08-08 Organization; started working on a new assembly guide for the 3DP version
2023-08-18 More work on the new 3DP assembly guide
2023-11-07 Updated project status (RNDKBD prototyped several of the PCBs)
2023-11-14 Added Andy@RNDKBD's stronger LED spacer design
    [3mm-LED-spacer-stronger.STL]
2023-11-14 Fixed some typos in the JLC BOM and CPL
    [BOM.xls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]
2023-11-14 Changed to STM32F072CBT6 as it is now cheaper on JLCPCB
    [BOM.xls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]
2024-02-15 Removed weird redundant columns
    [CPL.xls]
2024-02-25 Added connector info in light of UDB supporting 2 connectors
2024-02-25 Updated PCB status
2024-11-28 Noted V0.8.2DHI has not been prototyped or tested
2024-11-28 Noted Cannonkeys sells Molex to JST adapter cables
2025-08-22 Accidentally had SW126 as a hotswap socket
    [BOM.xls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]
2025-08-22 Removed duplicated columns
    [CPL.xls]
2025-08-22 Created JLCPCB files for V0.8.2JHA
    [BOM.xls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]
2025-08-22 Removed duplicate columns
    [CPL.xls]
2025-08-22 Created JLCPCB files for V0.8J
    [BOM.xls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]
2025-08-22 Rotated U701
    [CPL.xls]
2025-08-22 Updated BOM based on component availability
    [BOM.xls]
2025-09-24 Fixed issue with chamfer not being 45°
    Fixed the front of the bottoms on the CNC versions, where the chamfer was not 45° due to the two faces not meeting at 90° due to the 6.5° typing angle. Had to use a cut-sweet to keep the chamfer at 45°.
    [Boston-bottom-C3-DB-alternate (sharp edges).stp, Boston-bottom-C3-DB.stp, Boston-bottom-S1-UDB.stp]
2026-01-10 Slightly sink in the countersunk screw holes
2026-01-10 Created STEP file
    [Right key separator revised.stp]
2026-01-10 Create STEP
    [Low-profile-left-half.stp, Low-profile-right-half.stp]
2026-01-10 Reduced countersunk hole inset back to 0.1mm (from 0.4mm)
    [Low-profile-left-half.stp, Low-profile-right-half.stp]
2026-01-10 Renamed to "lower profile" as it's only about 2mm lower
    [Lower-profile-left-half.stp, Lower-profile-right-half.stp, Right key separator revised.stp]
2026-01-10 Uploaded wrong separator
    [Right key separator revised.stp]
2026-01-10 Accidentally left out USB-C cutout
    Unlike all other CAD programs, Alibre does not rebuild all features when revising an earlier feature in the feature tree.
    [Lower-profile-left-half.stp, Lower-profile-right-half.stp]
2026-01-15 Slight tweaks to bezel fillet to fix a clicking issue
    [Lower-profile-left-half.stp, Lower-profile-right-half.stp]
2026-01-17 Added a lower-profile right half version with a reset hole for V0.7J and older PCBs
    [Lower-profile-right-half-with-reset-hole.stp]
2026-01-18 Fix issue transitioning into the key separators
    [Lower-profile-left-half.stp, Lower-profile-right-half-with-reset-hole.stp, Lower-profile-right-half.stp]
2026-01-18 Matched radius on the right end to the left end of Left-key-separator
    [Right-key-separator-revised.stp]
2026-01-18 Fix reset hole (lower height required having the reset hole guide at an angle)
    [Lower-profile-right-half-with-reset-hole.stp]
2026-01-21 Revised left-key separator
    [Left-key-separator-revised-with-RGBLED.stp]
2026-02-18 Update for PCB V0.8
2026-02-28 Added instruction to use ESD wrist strap
2026-02-28 Noted the ESD wrist strap should be properly grounded
